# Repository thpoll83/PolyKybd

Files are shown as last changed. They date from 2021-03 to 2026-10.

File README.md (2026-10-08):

# PolyKybd Split72

Official hardware repository of the PolyKybd Split72 keyboard. If you are looking for the kit, jump immediately to https://www.crowdsupply.com/polykybd/polykybd for registration.

The instructions here are still in a very early stage. There is also a build video available: https://www.youtube.com/watch?v=K5RpbYzx7gw

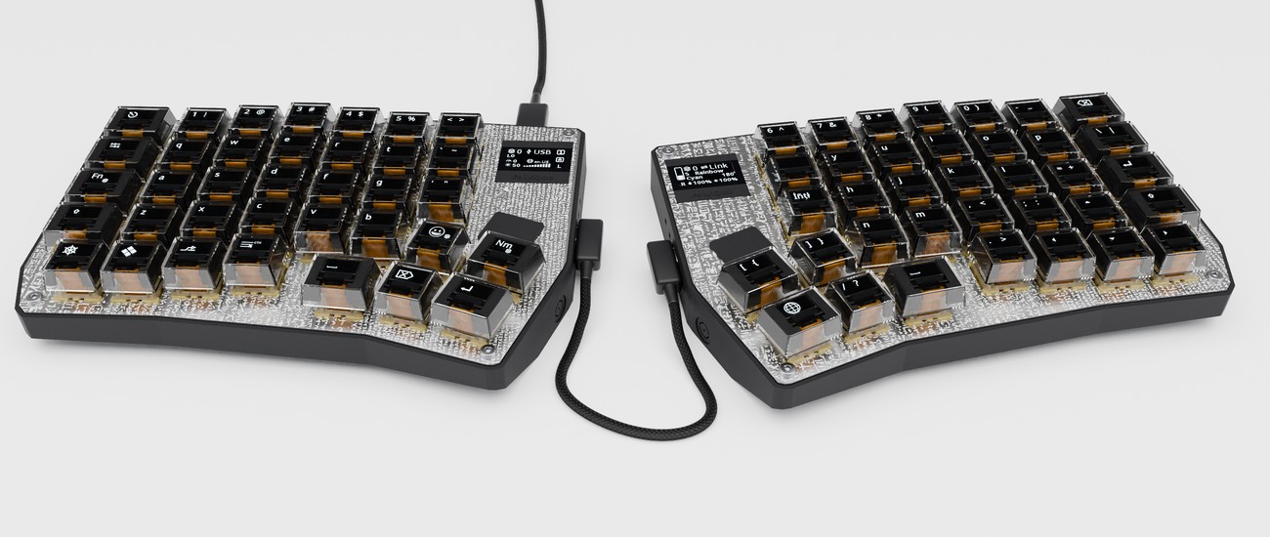
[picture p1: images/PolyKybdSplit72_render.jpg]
PolyKybd Split72, rendered from the KiCad models


You can find the matching QMK firmware here: [https://github.com/thpoll83/qmk_firmware/tree/PolyKybd](https://github.com/thpoll83/qmk_firmware/tree/PolyKybd)

## Cloning this repository

This repo is big — around 800 MB of history. Most of that is the board files themselves: the
decorative silkscreen artwork is stored as vector polygons, which makes a single `.kicad_pcb`
around 50 MB, and there are several design generations in the history.

If you just want the current files, use a partial clone. Git then downloads file contents only
when you actually touch them, so a fresh checkout takes seconds instead of many minutes:

```
git clone --filter=blob:none https://github.com/thpoll83/PolyKybd.git
```

The full history is still there and everything works normally — `git log`, `git checkout`, opening
the boards in KiCad. Older revisions of large files are simply fetched on demand. If you want a
plain full clone instead, just leave the `--filter` off.

The PCB projects are the following (**KiCad 9** — the schematics were migrated to the version 9
file format, so KiCad 8 and earlier can no longer open them):

[poly_kybd/poly_kybd_split72_right.kicad_pro](poly_kybd/poly_kybd_split72_right.kicad_pro)
[poly_kybd/poly_kybd_split72_left.kicad_pro](poly_kybd/poly_kybd_split72_left.kicad_pro)

(please just use the projects linked above and ignore any older/backup projects in the folder)

Here are the corresponding schematics for reference (left and right):

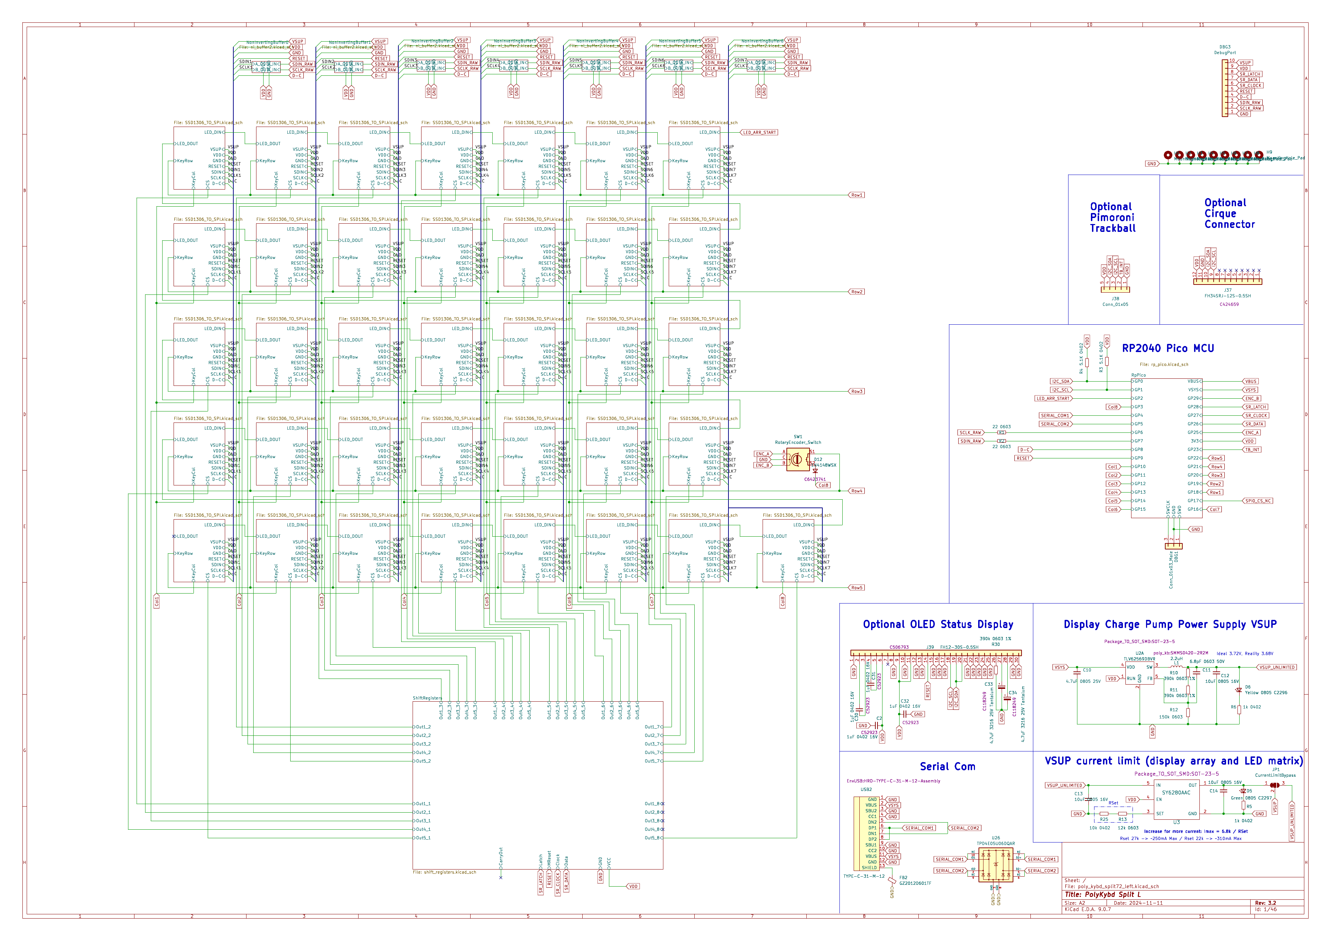
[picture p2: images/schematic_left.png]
Left schematic

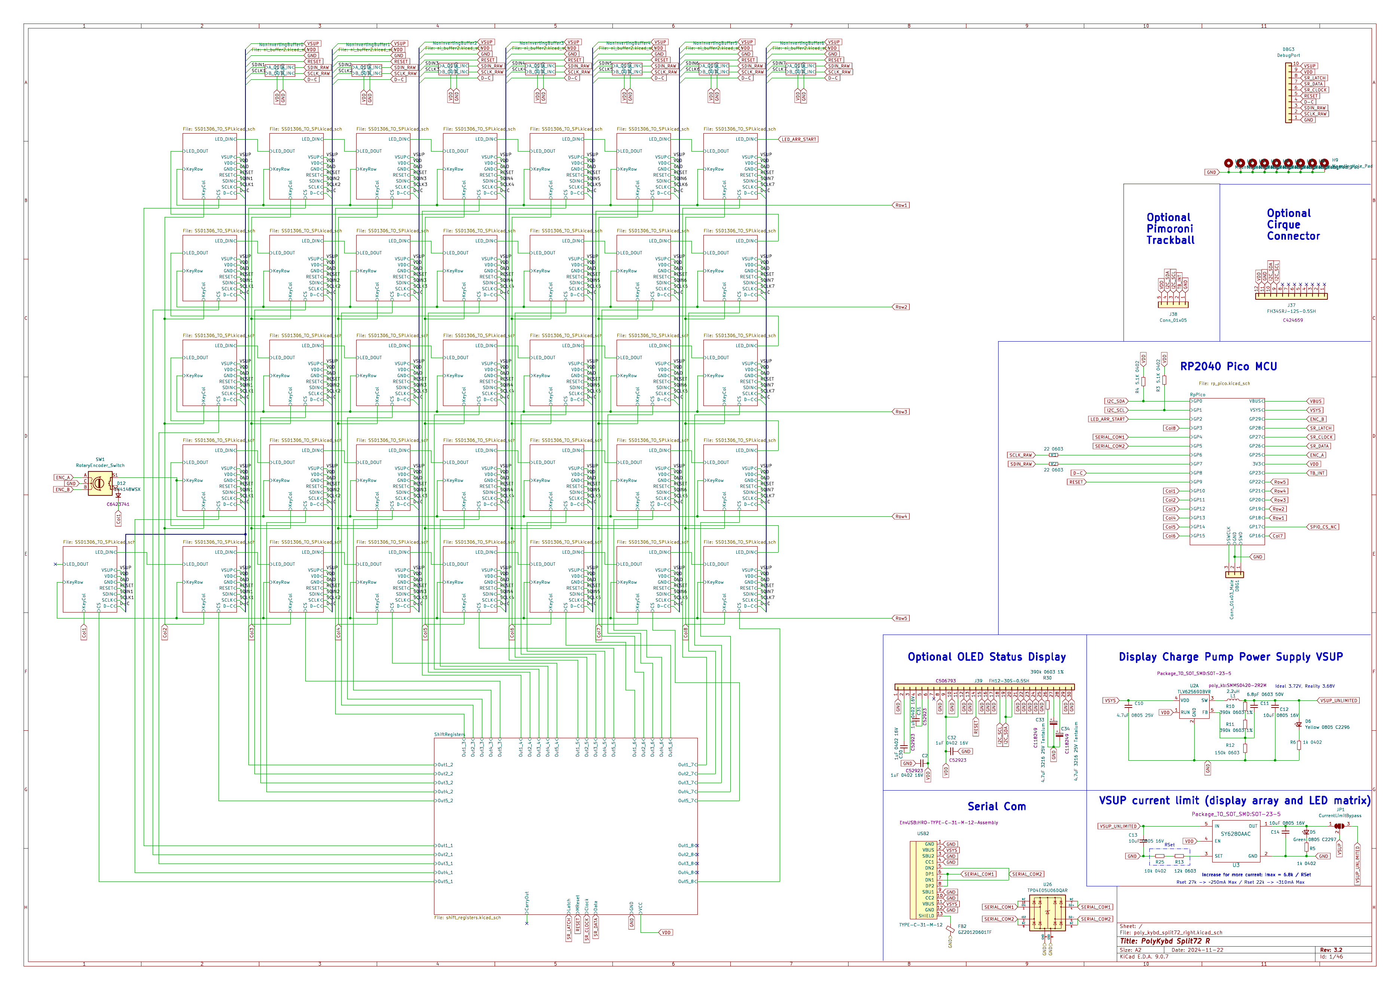
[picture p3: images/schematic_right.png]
Right schematic


You can inspect all individual schematic sheets (with descriptions) here: [Schematic sheets](schematics.md).

The keyboard plates are also KiCad projects, still in an older file format but they open fine in
KiCad 9 (I used 1.2mm aluminum PCBs):

[poly_kybd/poly_kybd_split72_plate_right.kicad_pro](poly_kybd/poly_kybd_split72_plate_right.kicad_pro)
[poly_kybd/poly_kybd_split72_plate_left.kicad_pro](poly_kybd/poly_kybd_split72_plate_left.kicad_pro)

## How to Build

I recommend waiting for the kit that contains all parts and the assembled PCBs. Here a little preview, how that looks like:
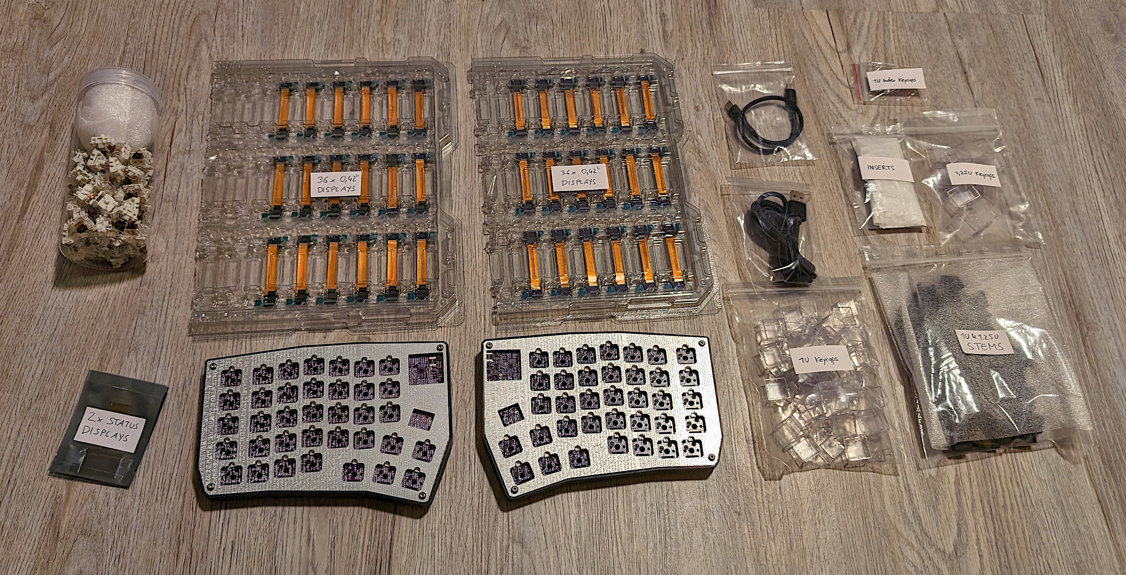
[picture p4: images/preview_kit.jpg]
Kit Preview

The kits are not yet ready, but you can sign up here and get notified as soon as these are available: [https://www.crowdsupply.com/polykybd/polykybd](https://www.crowdsupply.com/polykybd/polykybd)

At the moment, please consider these instructions as experimental. If you want to go ahead with the full experience and build everything from scratch right now: Give it a try and let me know how it worked out!

Independent of your choice, here are the parts you need before putting everything together:

### Prepare Required Parts

* Case (left/right) - You can either 3D print or get them CNCed (but then you should add some threads to the screw holes):
  [parts/export/case/case_polykybd_split72_left_r7.stl](parts/export/case/case_polykybd_split72_left_r7.stl)
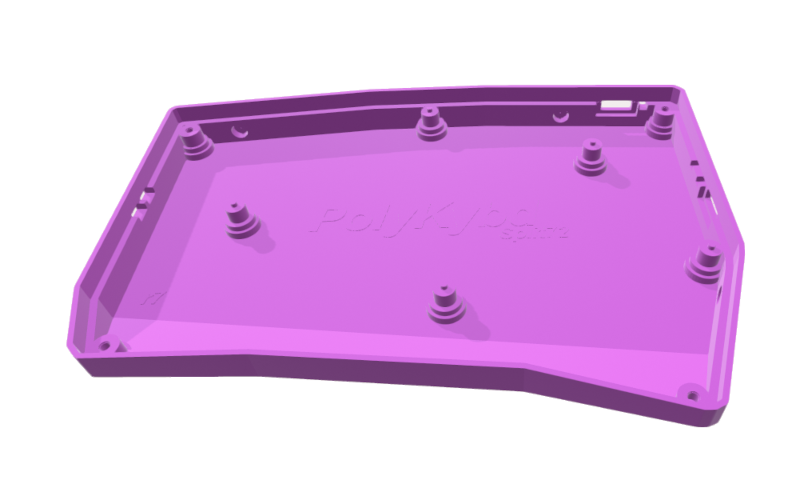
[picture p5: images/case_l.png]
Case
  
  [parts/export/case/case_polykybd_split72_right_r7.stl](parts/export/case/case_polykybd_split72_right_r7.stl)
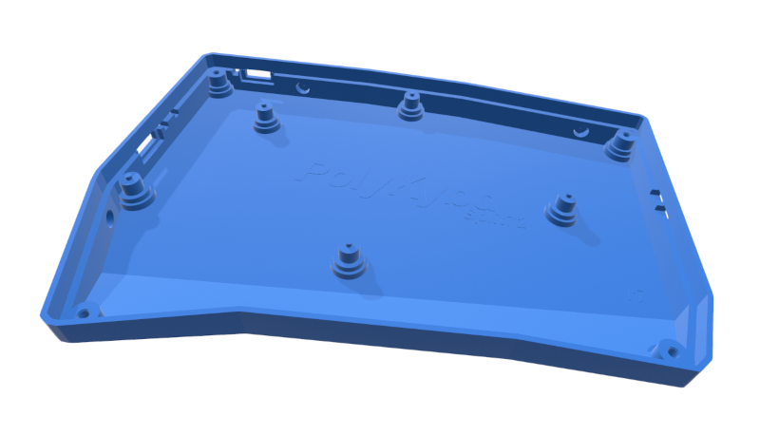
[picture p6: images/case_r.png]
Case
  
  In case the resin print has some deformations, it is best to use a hairdryer to slightly heat the case up and then put something heavy on the bottom to make it flat - it really works.
* Spacer to keep the right distance between plate and PCB (again, can be 3D printed):
  [parts/export/case/spacer.stl
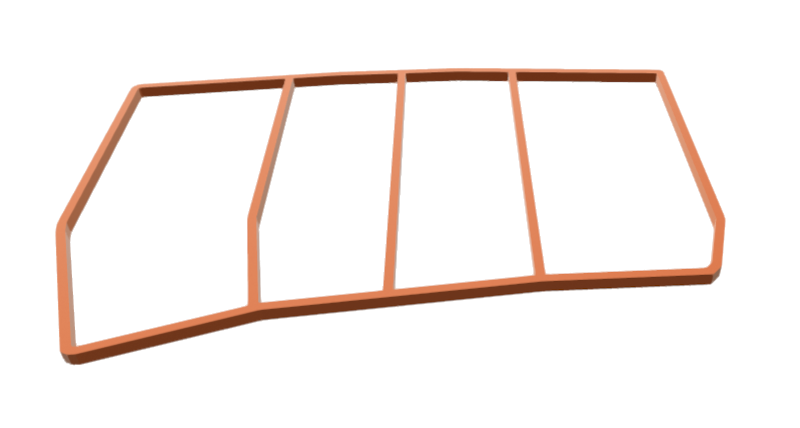
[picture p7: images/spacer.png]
Spacer
  
  ](parts/export/case/spacer.stl)
* Assembled 4 layers PCB 1.6mm (left/right)
  The latest gerber files with BOM and pick/place file can be found in [poly_kybd/Gerber](poly_kybd/Gerber) I made some final adjusts on the latest version, which I did not yet order (I will let you know as soon as I did).
  [poly_kybd/Gerber/PCB/left-side-v3.2/PolyKybd_Split72_L_3.2.zip](poly_kybd/Gerber/PCB/left-side-v3.2/PolyKybd_Split72_L_3.2.zip)
  [poly_kybd/Gerber/PCB/right-side-v3.2/PolyKybd_Split72_R_3.2.zip](poly_kybd/Gerber/PCB/right-side-v3.2/PolyKybd_Split72_R_3.2.zip)

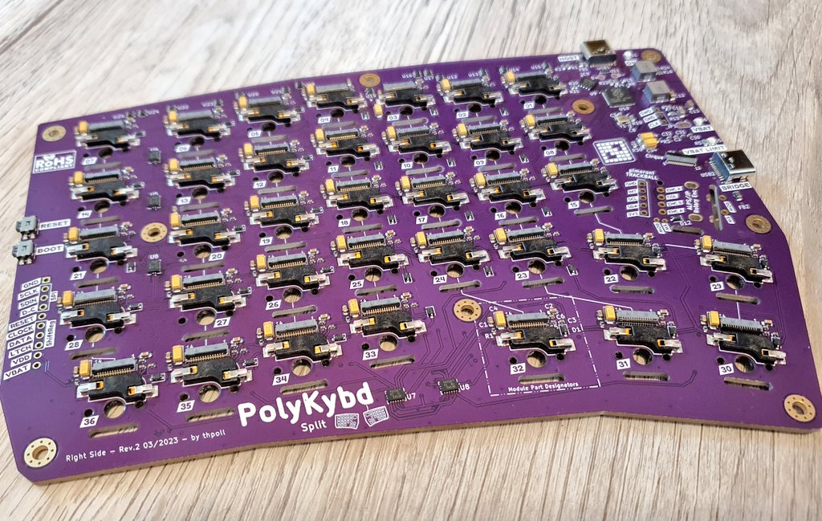
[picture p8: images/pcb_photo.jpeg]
PCB
  

  My recommendation is to let assemble the PCBs as there are a lot of parts with tiny footprints like the RP2040, the 72 FPC sockets and some more...
  If your PCB fab has an option to verify the parts orientation, please make use of it. I did that as well and never bothered correcting them (since the 'upright' orientation of the part from KiCad and your PCB fab might differ).

  ###### Note:

  In case you make modifications to the PCB in KiCad and export everything you might need to change the hot swap sockets side to the back. The hot swap socket in KiCad is part of the key switch and for some reason I couldn't yet convince KiCad that the manufacturing side is the back...
* Aluminum plates (left/right =) - Can be ordered from PCB manufactures as a 1.2mm aluminum PCB
  [poly_kybd/Gerber/Plate/gerber-left-side-v3-17.11.2023.zip](poly_kybd/Gerber/Plate/gerber-left-side-v3-17.11.2023.zip)
  [poly_kybd/Gerber/Plate/gerber-right-side-v3-17.11.2023.zip](poly_kybd/Gerber/Plate/gerber-right-side-v3-17.11.2023.zip)
* Displays
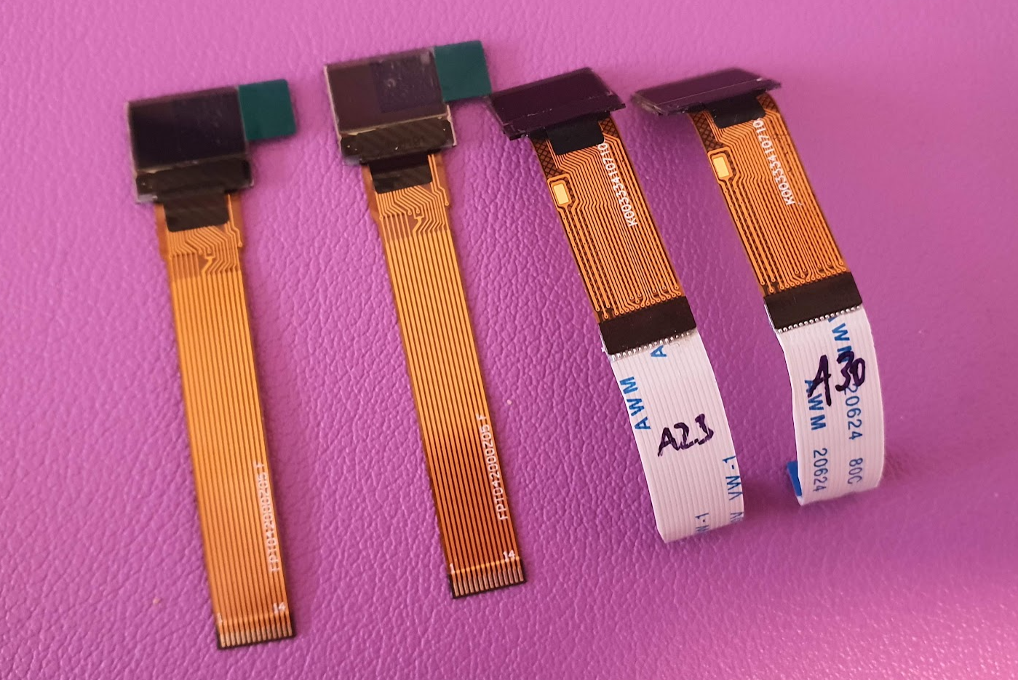
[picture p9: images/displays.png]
Displays
  

  - 72 pieces 0.42 inch displays

    - Either you take the 0.42 inch displays from the kit which has the matching length and pin number (maybe I can make them available as single parts as well - see picture above, on the left).
    - Or make them yourself the manual way, by extending a compatible 0.42 inch OLED with a short FPC cable and soldering the two together. See [Making the displays manually](making_the_displays_manually.md) for suppliers and the full soldering instructions.
  - (Optional) 2 pieces 0.96 inch status displays (FPW096W001Z0) or pin compatible (see below), the flex cable length should be about 40mm or you extend it on your own. You can contact this supplier: [FET](https://fetoled.en.alibaba.com/search/product), they have these displays even they are not listed in their online catalogue.

    | PIN   | SIGNAL    | PIN   | SIGNAL |
    | ----- | --------- | ----- | ------ |
    | 1,30  | N/C (GND) | 14    | RES#   |
    | 2,3   | C2P,C2N   | 15    | D/C#   |
    | 4,5   | C1P,C1N   | 16    | R/W#   |
    | 6     | VDDB/VBAT | 17    | E/RD#  |
    | 7     | N/C       | 18~25 | D0~D7  |
    | 8     | VSS       | 26    | IREF   |
    | 9     | VDD       | 27    | VCOMH  |
    | 10~12 | BS0~BS2   | 28    | VCC    |
    | 13    | CS#       | 29    | VLSS   |

    If you don't need the status displays, you can close the display cut-out with the dummy holder: [Dummy Display Holder](parts/export/display_holder/display_holder_dummy_r1.stl)

* MX Compatible key switches (3 or 5 pins) - 72 pieces. From my blog post ( [https://ko-fi.com/post/More-Key-Switch-Testing-While-Waiting-For-The-Asse-B0B8HX1HW](https://ko-fi.com/post/More-Key-Switch-Testing-While-Waiting-For-The-Asse-B0B8HX1HW) ), you can find out, that there are 2 categories of compatible key switches. The ones that work out of the box and the ones that need a little modification. Basically all switches that have an LED slit that is at least 7.5mm wide work. I tested quite some switches and here is the list of tested switches that will work for sure without modification:

  | SWITCH                            | TYPE            | MISC  |
  | --------------------------------- | --------------- | ----- |
  | Aflion Tropical Waters            | Linear          | 68g   |
  | Ashkeebs Alexandrite              | Linear          | 58g   |
  | Blue Dusk Panda                   | Linear          | 62g   |
  | CK x Haimu Pastel Lemon           | Linear          | 63.5g |
  | Ck x Haimu Pastel Thistle         | Tactile         | 63.5g |
  | Gateron KS-9 (Pro) Blue           | Clicky          | 60g   |
  | Gateron KS-9 (Pro) Brown          | Tactile         | 55g   |
  | Gateron KS-9 (Pro) Green          | Clicky          | 80g   |
  | Gateron KS-9 (Pro) Red            | Linear          | 45g   |
  | Gateron KS-9 (Pro) Yellow         | Linear          | 50g   |
  | Geon Black                        | Tactile         | 60g   |
  | Geon Clear                        | Linear          | 60g   |
  | Geon Yellow                       | Linear          | 63.5g |
  | Glorious Panda                    | Tactile         | 67g   |
  | GOJU Works x Tecsee Safety Switch | Linear          | 65g   |
  | Kailh Novel Keys Cream Switch     | Linear          | 55g   |
  | Kailh Purple Potato               | Tactile         | 63.5g |
  | Kailh x Domikey Knight Saber      | Tactile         | 42g   |
  | LCET Grace                        | Linear          | 50g   |
  | LCET Joker                        | Tactile         | 58g   |
  | LCET Pink Queen                   | Tactile         | 58g   |
  | LCET Sprout                       | Linear          | 50g   |
  | Outemu (Dustproof) Black          | Linear          | 65g   |
  | Outemu (Dustproof) Blue           | Clicky          | 65g   |
  | Outemu (Dustproof) Brown          | Tactile         | 50g   |
  | Outemu (Dustproof) Red            | Linear          | 46g   |
  | Outemu Crystal Clear              | Linear          | 45g   |
  | Outemu Dust-proof Silver          | Linear          | 45g   |
  | Outemu Lemon                      | Silent Tactile  | 35g   |
  | Outemu Panda                      | Tactile         | 50g   |
  | Outemu Peach                      | Linear          | 40g   |
  | Outemu Purple                     | Tactile         | 45g   |
  | Outemu Ocean                      | Linear          | 35g   |
  | Outemu Teal                       | Clicky          | 70g   |
  | Owlab Neon                        | Linear          | 62g   |
  | Tecsee Medium (low profile)       | Linear & Tactile| 50g   |

  Be aware that there are different batches of Gateron KS-9 (with and without 'Pro') switches. Despite the exact same name, they might need the following surgery (better ask before buy).
  So, some switches have an LED slit, but with a little plastic bar in the middle:

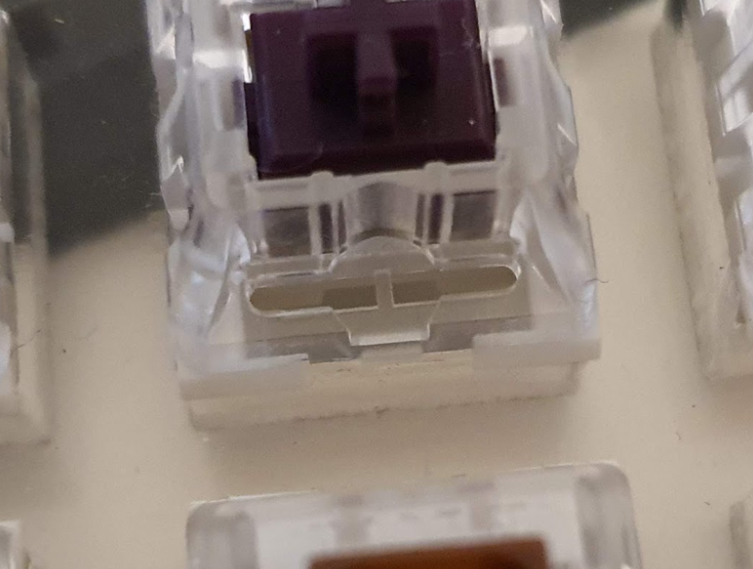
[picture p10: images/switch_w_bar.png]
Switch with plastic bar in LED slit
  

  You can simply cut it away with a knife:

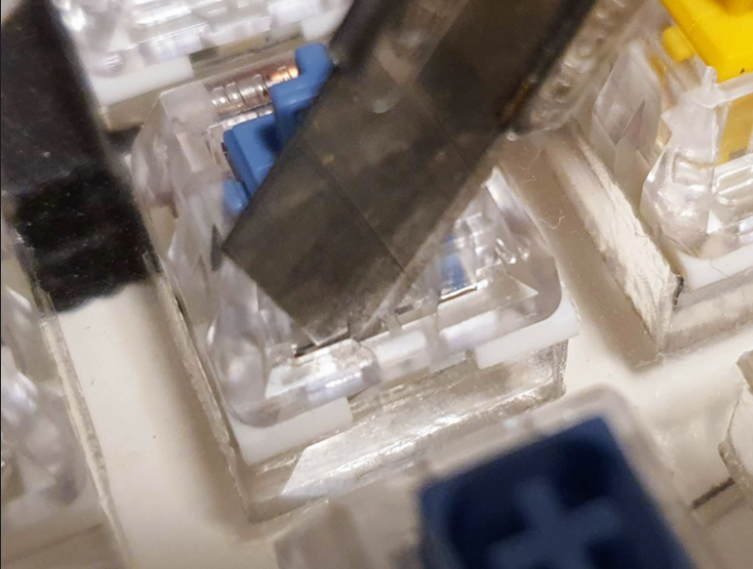
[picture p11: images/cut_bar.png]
Cut the bar away
  

  It is not a big deal, just consider it. Here is a list of switches that I successfully tested after this little modification:

  | SWITCH                           | TYPE           | MISC |
  | -------------------------------- | -------------- | ---- |
  | Gateron KS-9 (Pro 2.0) Red       | Linear         | 45g  |
  | Gateron KS-9 (Pro 2.0) White     | Linear         | 35g  |
  | Geon HG [Haimu x Geon] Black     | Linear         | 65g  |
  | Geon HG [Haimu x Geon] White     | Tactile        | 65g  |
  | Geon HG [Haimu x Geon] Red       | Silent Linear  | 65g  |
  | Geon HG [Haimu x Geon] Yellow    | Silent Tactile | 65g  |
  | Kailh BOX V2 Red Switch          | Linear         | 40g  |
  | Kailh Box Cream                  | Linear         | 45g  |
  | Kailh Pro Purple                 | Tactile        | 50g  |
  | Kailh Pro Burgundy               | Linear         | 50g  |
  | Kailh Pro Light Green            | Clicky         | 50g  |
  | Kailh Pro Plum                   | Tactile        | 70g  |
  | Kailh Speed Gold                 | Clicky         | 50g  |
  | Kailh Speed Silver               | Linear         | 50g  |
  | Kailh Speed Bronze               | Clicky         | 50g  |
  | Kailh Speed Copper               | Tactile        | 40g  |
  | Kailh Speed Burnt Orange         | Linear/Tactile | 70g  |
  | Kailh Speed Pro Heavy Army Green | Clicky         | 70g  |
  | Kailh Speed Pro Heavy Yellow     | Linear         | 70g  |
  | Kailh Black                      | Linear         | 60g  |
  | Kailh RGB Red                    | Linear         | 45g  |
  | Kailh RGB Black                  | Linear         | 60g  |
  | Kailh RGB Blue                   | Clicky         | 50g  |
  | Kailh RGB Brown                  | Tactile        | 50g  |

  There are many more switches that will work as long as they have a 7.5mm wide LED slit. Let me know in case you successfully tried another switch, then I can update the list.

* Key Stems - 72 pieces, can be 3D printed (I highly recommend using an SLA printer). There are 3 different profiles available here. You can also modify the source file an make your own profile. If you take the STLs, make sure to always grab the latest version.

  Every plate is in [parts/export/keycap_stem/](parts/export/keycap_stem), named
  `keycap_stem_revAlpha_<width>_<profile>_10p.stl` — where *width* is `1U` or
  **`1U25`** (not `1.25U`) and *profile* is one of `R1`–`R5`, `S1`, `S`, `S5`, e.g.
  `keycap_stem_revAlpha_1U25_R1_10p.stl`. Ten pieces per plate, so divide the
  counts below by ten (rounding up) to know how many of each to print.

  Every piece carries its **profile and revision engraved on the top face**
  (`R5 α`, `S1 α`, …), matching the profile token in the filename — so a printed
  stem can always be traced back to the plate that made it, and a mixed handful
  can be sorted back out.

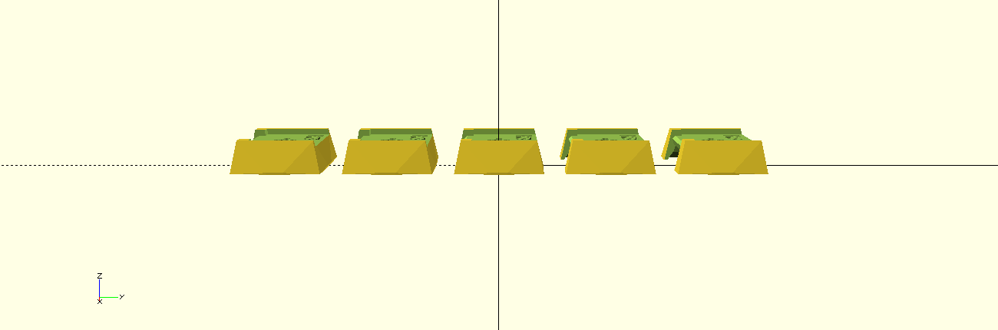
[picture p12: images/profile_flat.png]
Flat Profile
  - Flat 
    One stem for every row: the `R3` plates (14 pieces 1.25U and 58 pieces 1U).
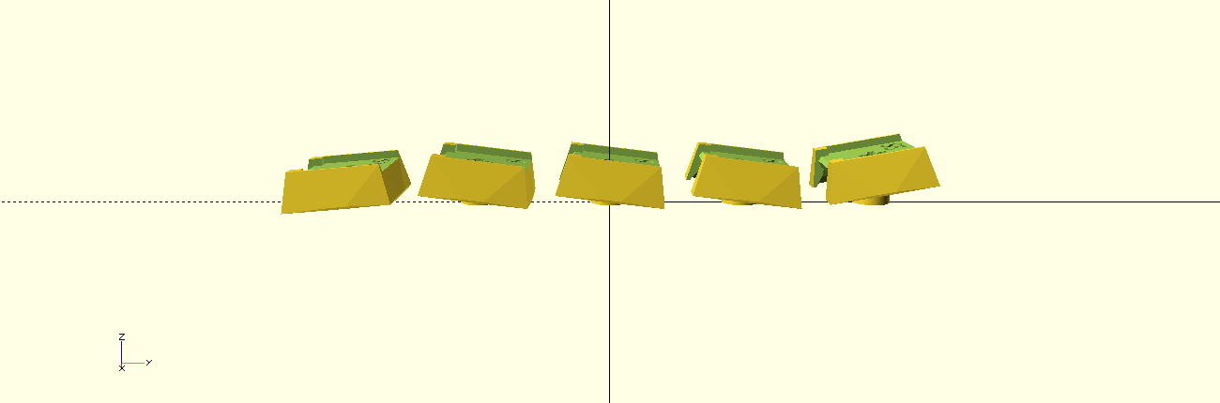
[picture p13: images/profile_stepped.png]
Stepped Profile
  - Stepped 
    Rows tilted rather than curved. This works best if the keyboard is inclined by 5 degrees or more, and comes in two variations:
    - *sculpted* (pictured) — `S1` on the front row, `S5` on the back row, `S` on the three rows between: 4x 1.25U S1, 10x 1U S1, 8x 1.25U S, 36x 1U S, 2x 1.25U S5, 12x 1U S5.
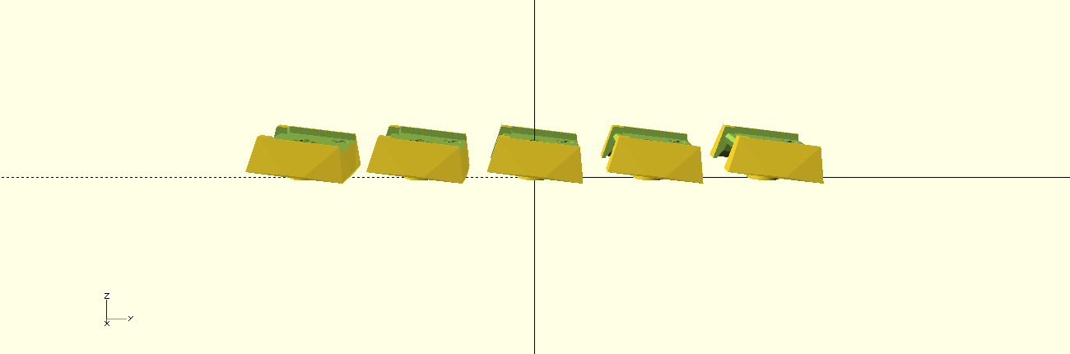
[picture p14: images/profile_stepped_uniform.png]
Uniform Stepped Profile
    - *uniform* 
      just the `S` plates everywhere (14 pieces 1.25U and 58 pieces 1U) — a flatter feel that is simpler to print, since it is a single plate design.
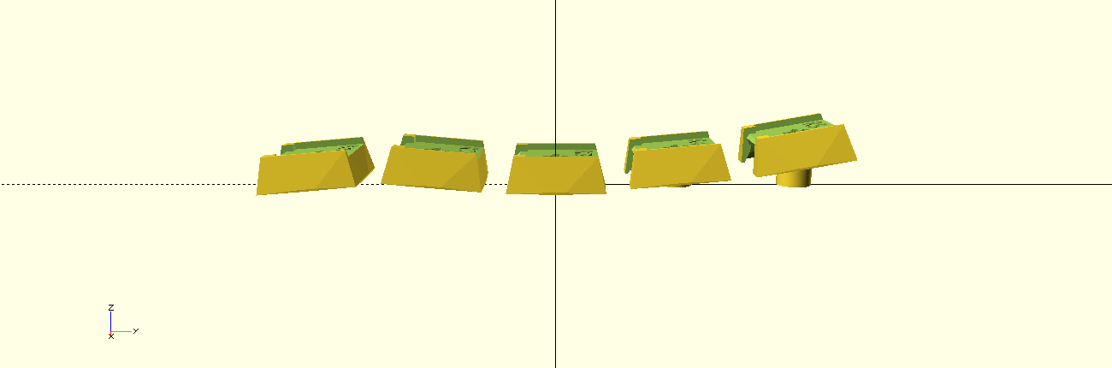
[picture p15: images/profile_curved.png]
Curved Profile
  - Curved 
    Here you will need `R1` to `R5`: 4x 1.25U R1, 10x 1U R1, 4x 1.25U R2, 12x 1U R2, 2x 1.25U R3, 12x 1U R3, 2x 1.25U R4, 12x 1U R4, 2x 1.25U R5, 12x 1U R5.

  To change a profile or add your own, edit the shared
  [parts/keycap_stem/keycap_stem.scad](parts/keycap_stem/keycap_stem.scad) or add a
  file to [parts/keycap_stem/variants/](parts/keycap_stem/variants), then run
  `parts/keycap_stem/build_stems.sh` — see [parts/README.md](parts/README.md).
* Status display holder (or cover/dummy in case no status display is used), can be 3D printed.
  [parts/export/display_holder/display_holder_r1.stl](parts/export/display_holder/display_holder_r1.stl) / [parts/export/display_holder/display_holder_dummy_r1.stl](parts/export/display_holder/display_holder_dummy_r1.stl)
* Transparent keycap covers - 72 pieces (from relegendable keycaps [like these](https://de.aliexpress.com/item/1005002996832179.html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)), 58x 1U and 14x 1.25U. Various sources sell them on Alibaba, AliExpress, Amazon & Co.
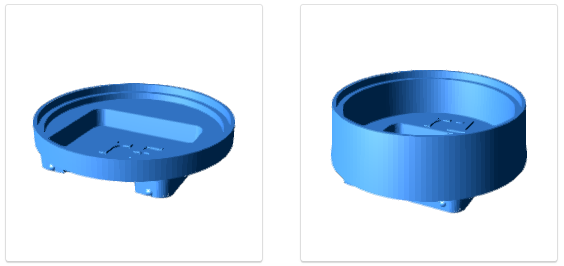
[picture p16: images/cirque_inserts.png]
Cirque Trackpad Inserts
* Optional rotary encoder ([EVQWGD001](https://de.aliexpress.com/i/32990950196.html?gatewayAdapt=gloMsite2deuPcglo2deu) or [Alps EC11 Encoder](https://www.mouser.at/c/electromechanical/encoders/?m=Alps%20Alpine&series=EC11)), [pimoroni trackball](https://mou.sr/3rmFiAO) or [23mm cirque trackpad](https://www.mouser.at/ProductDetail/Cirque/TM023023-2024-002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) (and a 12 pin FPC cable with pins on the same side, about 50mm to 70mm). For the trackpad you will need another 3D printed holder, either a high one or a low one: 
  [parts/export/cirque_insert/cirque23_slim_insert_r8.stl](parts/export/cirque_insert/cirque23_slim_insert_r8.stl)
  [parts/export/cirque_insert/cirque23_insert_high_r1.stl](parts/export/cirque_insert/cirque23_insert_high_r1.stl)
  If you are not happy with the existing STLs, you can also modify the source file [parts/cirque_insert/cirque23_insert.scad](parts/cirque_insert/cirque23_insert.scad) or [parts/cirque_insert/cirque23_slim_insert.scad](parts/cirque_insert/cirque23_slim_insert.scad). There is also an experimental version for the 35mm cirque track pad: [parts/cirque_insert/cirque35_insert.scad](parts/cirque_insert/cirque35_insert.scad).
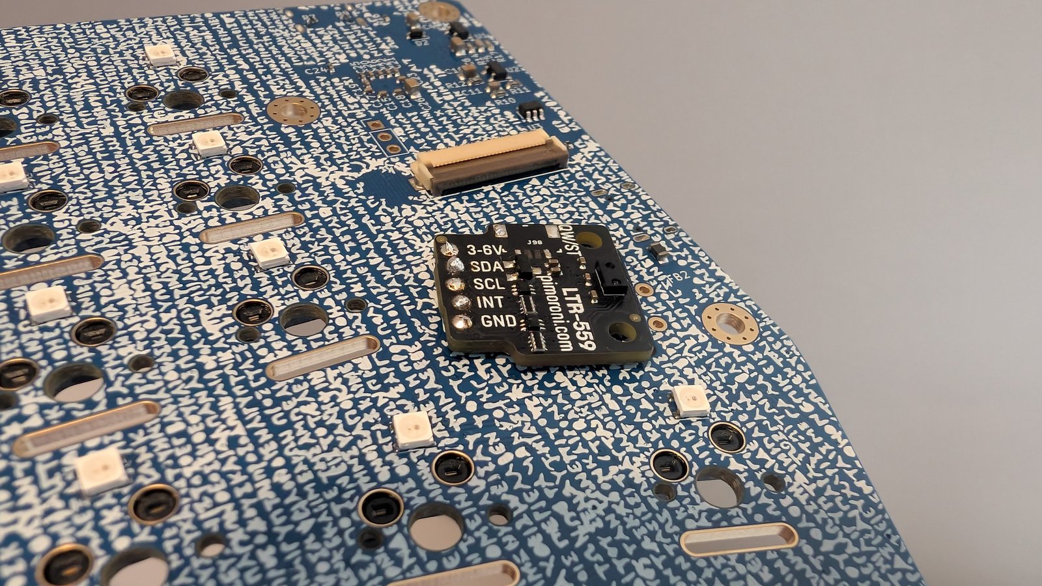
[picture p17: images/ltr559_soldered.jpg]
LTR-559 soldered to the PCB
* Optional ambient-light + proximity sensor (**highly recommended**) - a [Pimoroni LTR-559 Light & Proximity Sensor breakout](https://shop.pimoroni.com/products/ltr-559-light-proximity-sensor-breakout) plus a matching 5-pin 2.54mm pin header. The Split72 PCB has a dedicated header footprint for it (labelled `3-6V / SDA / SCL / INT / GND`), sharing the Cirque I2C bus - no extra wiring. With the sensor fitted, the firmware automatically drives keycap brightness from the measured light level and wakes the displays when your hand approaches. It is entirely optional (the firmware is a clean no-op when no sensor is present) and side-agnostic (works on whichever half you solder it to). **You must fit it as the very first assembly step** - see the note in [Put Everything Together](#put-everything-together) below, because it does *not* fit through the plate hole and cannot be added later without an almost complete disassembly. 
  ***Note:*** each half has a **single** expansion slot that takes exactly **one** of these optional add-ons - a rotary encoder, a pointing device (trackball/trackpad), *or* the light sensor. So on a given half the sensor is mutually exclusive with the encoder and the pointing device: fitting the sensor means that half has no encoder/trackpad. (You can still put the sensor on one half and a pointing device or encoder on the other.)
* Short USB-C to USB-C cable to connect the two sides (maybe around 50cm).
* USB-C to USB-A/USB-C to connect to your computer.
  ***Note:*** I had a USB-C to USB-A cable and was sitting in front of a laptop with only USB-C ports. Without a USB-C to USB-C cable at hand, I used an USB-A to USB-C adapter. It turned out this USB-C to USB-A cable + USB-A to USB-C adapter construction was only working then the adapter was connected to the laptop. - better use a USB-C to USB-C right away.
* 8 M3x10 hex screws with rounded heads and for the current case version (r4 and later, e.g. r7), you also need 8 M3 hex nuts.

### Put Everything Together

Here is my recommended order:

0. **(Optional but highly recommended) Solder the LTR-559 light + proximity sensor - do this FIRST!**
   ⚠️ The sensor board does **not** fit through the hole in the aluminum plate, so it has to be soldered on **before** the plate goes on. If you add it later you will have to almost completely disassemble the keyboard again. So if there is any chance you want it, fit it now - it is optional in firmware and costs you nothing if you later decide not to use it.
   ⚠️ Each half has a **single** expansion slot shared by the sensor, the rotary encoder and a pointing device (trackball/trackpad) - only **one** of the three fits per half. So fitting the sensor means no encoder or trackpad on that half (you can still fit one of those on the other half). Decide before you start soldering.

   The Split72 PCB has a labelled 5-pin footprint for the sensor (`3-6V / SDA / SCL / INT / GND`). Solder the sensor exactly like this:
   1. Solder the 5-pin header into the PCB footprint.
   2. The plastic spacer strip of the header now has to come off - it holds the sensor board too high to clear the plate. I simply pushed it all the way down/off the pins:
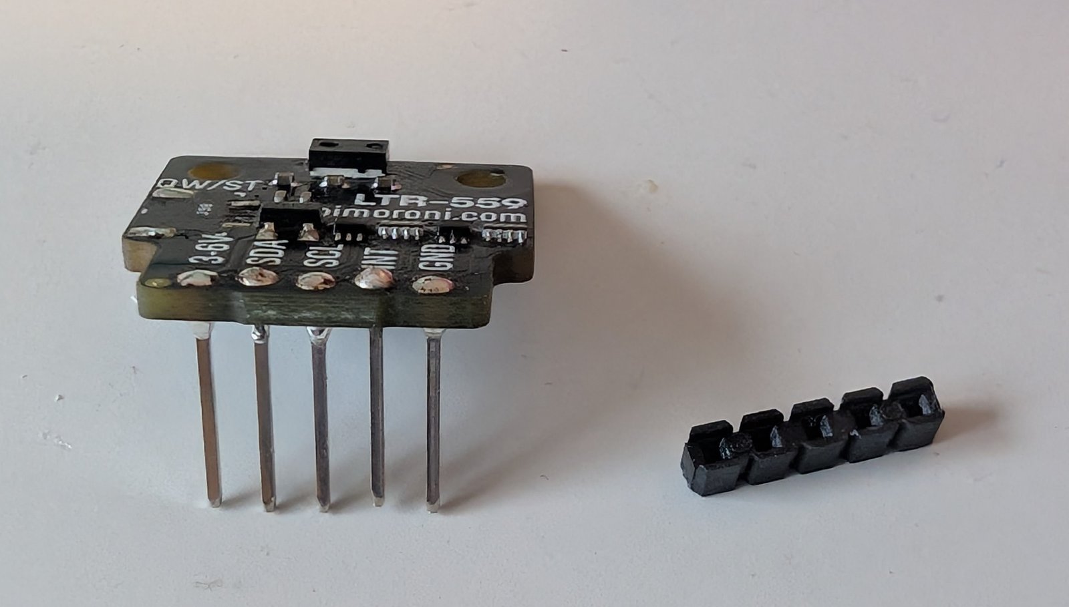
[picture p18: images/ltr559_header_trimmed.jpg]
Sensor with the header spacer removed
      
   3. It is still too thick, so instead of the plastic spacer use a piece of paper folded twice (roughly 1-2mm) as a temporary shim to set the sensor at a nice low height while you solder the board onto the header pins:
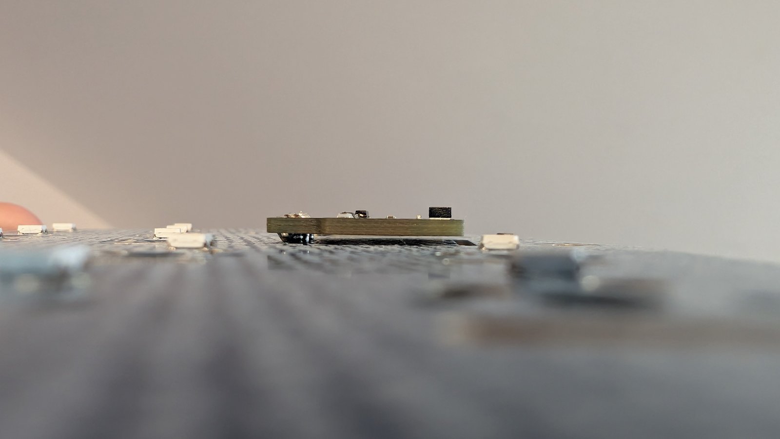
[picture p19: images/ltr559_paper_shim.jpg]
Folded paper used as a spacer
      
   4. After soldering, pull the paper back out. The sensor now sits low and flat, just above the PCB:
      Sensor soldered flush to the PCB
   5. To expose the sensor to ambient light, drill a **5mm hole** into the 3D-printed cap on the far right, vertically centered as shown:
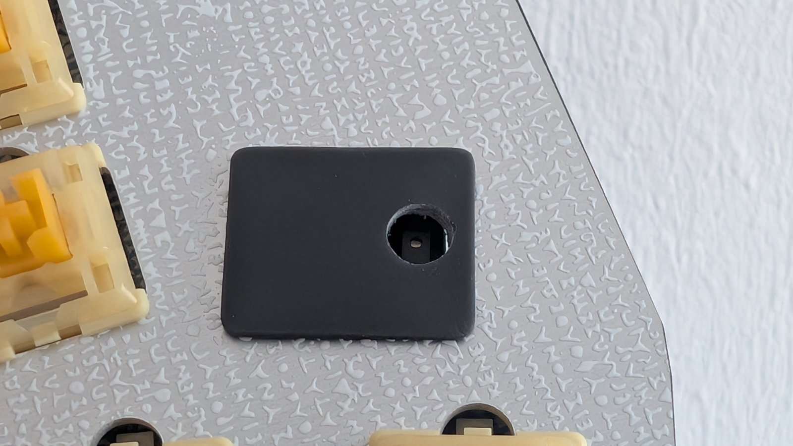
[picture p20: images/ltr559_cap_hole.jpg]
5mm hole drilled into the cap
      

   The sensor is auto-detected on whichever half you solder it to - no firmware option to enable. See the [firmware readme](https://github.com/thpoll83/qmk_firmware/blob/PolyKybd/keyboards/polykybd/readme.md) for how it drives auto-brightness and proximity wake.
1. In case you want to use an [Alps EC11 Encoder](https://www.mouser.at/c/electromechanical/encoders/?m=Alps%20Alpine&series=EC11) or some remaining stock of the not any more produced [EVQWGD001](https://de.aliexpress.com/i/32990950196.html?gatewayAdapt=gloMsite2deuPcglo2deu), put it on the PCB and also put the keyboard plate once on top to make sure your encoder fits! In case of the EVQWGD001, you have to remove the last pin, before soldering it to the PCB Juts clip it away. DO NOT solder it to the PCB, or otherwise it will not work:
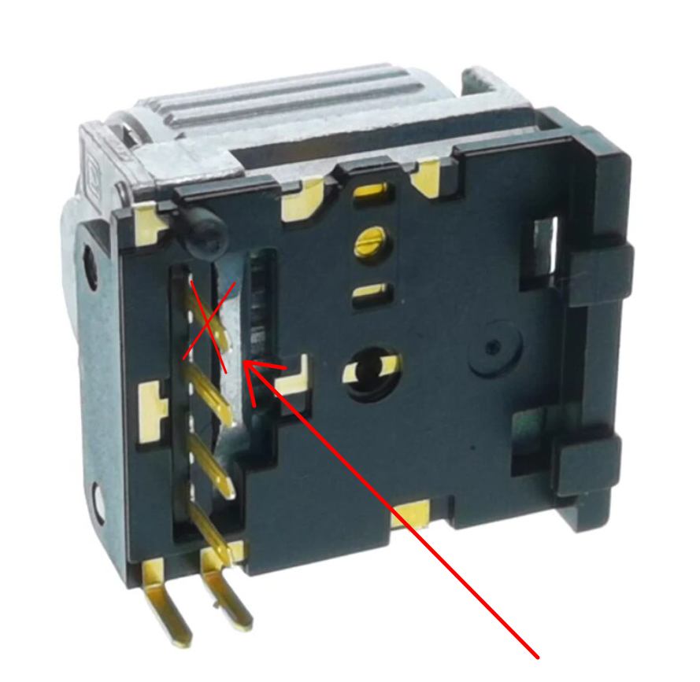
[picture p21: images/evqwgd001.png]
EVQWGD001

Depending on the type of EC11 encoder, you maybe want to put a piece of Kapton tape over the legs, in case they come close to the plate (it was not necessary for mine, but there are different kinds out there).
1. For the [pimoroni trackball](https://mou.sr/3rmFiAO), please solder on the header without the little plastic distance holder. There are various ways to do that: Either solder them on and push the plastic with some pliers off the pins (and clip away the pins on the front side of the trackball so that it is flush) or insert them from the front side, solder them on and then clip away the plastic parts. The pins are still long enough. Just go for something that works for you.
   Next, put some Kapton tape on the back side of the trackball and solder it to the keyboard PCB. Make sure it is even on the front side, there will be an average 1 to 2mm distance:
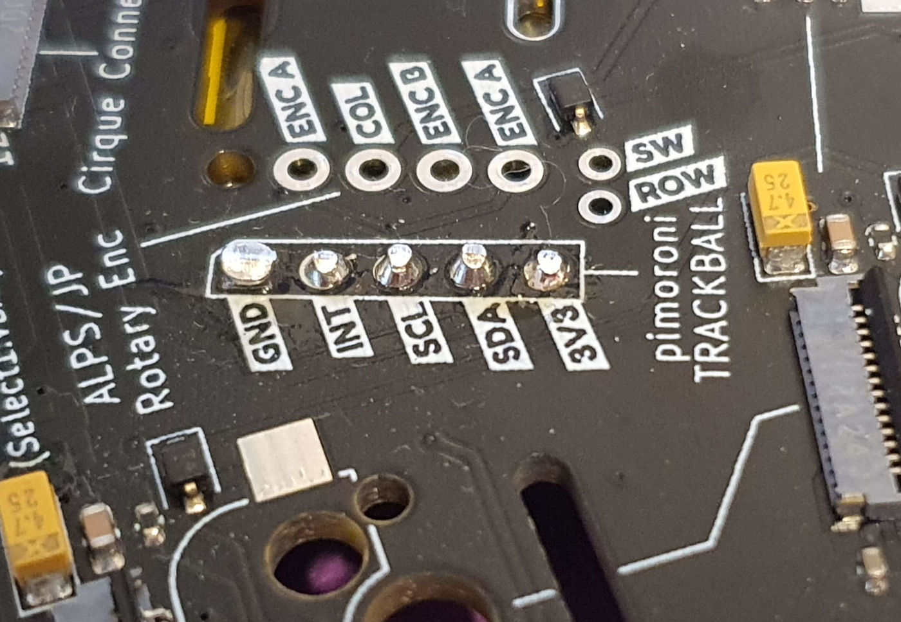
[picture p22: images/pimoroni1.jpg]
Pimoroni on the back side
   
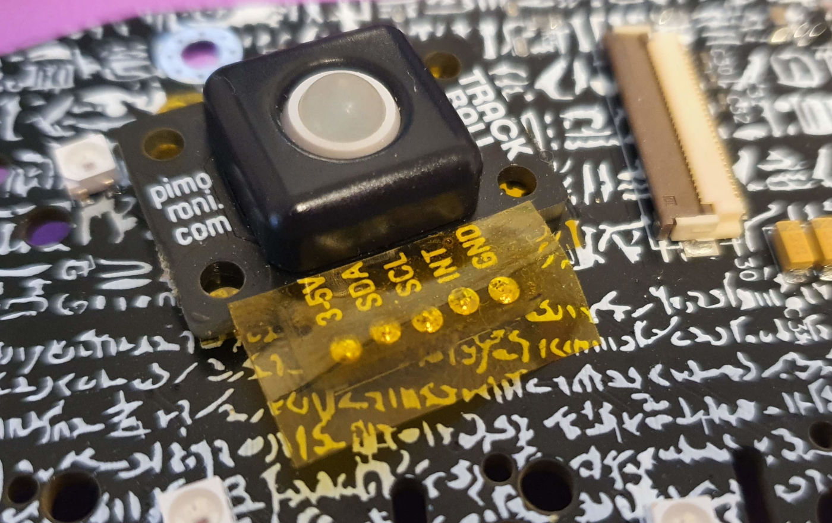
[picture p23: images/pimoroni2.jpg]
Pimoroni on the front side
   
   Finally also cover the trackballs front side with Kapton tape like in the picture above (or anything that pleases your eye and insulates) to avoid any shorts since the top plate is made out of Aluminum.
2. In case you use the [23mm cirque trackpad](https://www.mouser.at/ProductDetail/Cirque/TM023023-2024-002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), first remove R1 from the backside of the trackpad's PCB (with a solder iron or maybe a sharp knife) to activate I2C instead of SPI. Then connect the 12 pin FPC to the trackpad (and mind the pin 1 marking on the trackpad + I made my own marking on the FPC to make sure):
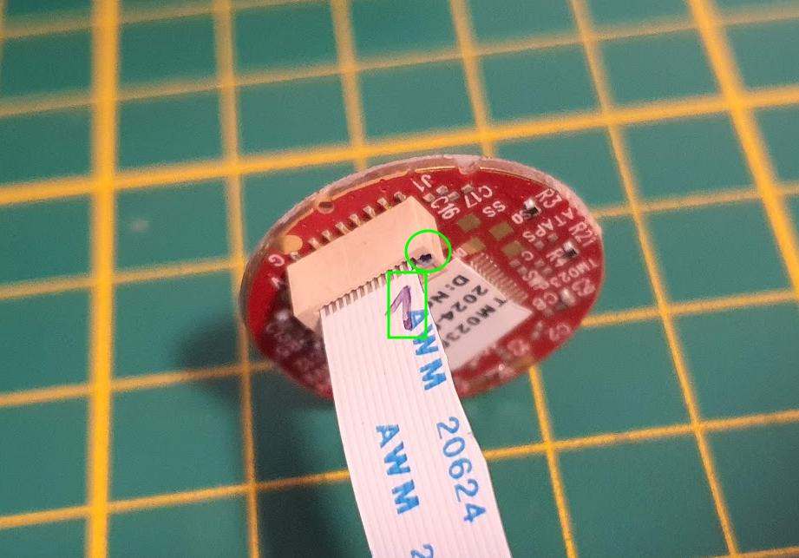
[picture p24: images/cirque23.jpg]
Cirque trackpad connected
   
   Then, put it into the 3D printed holder. You can fix the trackpad with some adhesive tape or a few drops of super glue into the holder. Wait with connecting it to the PCB:
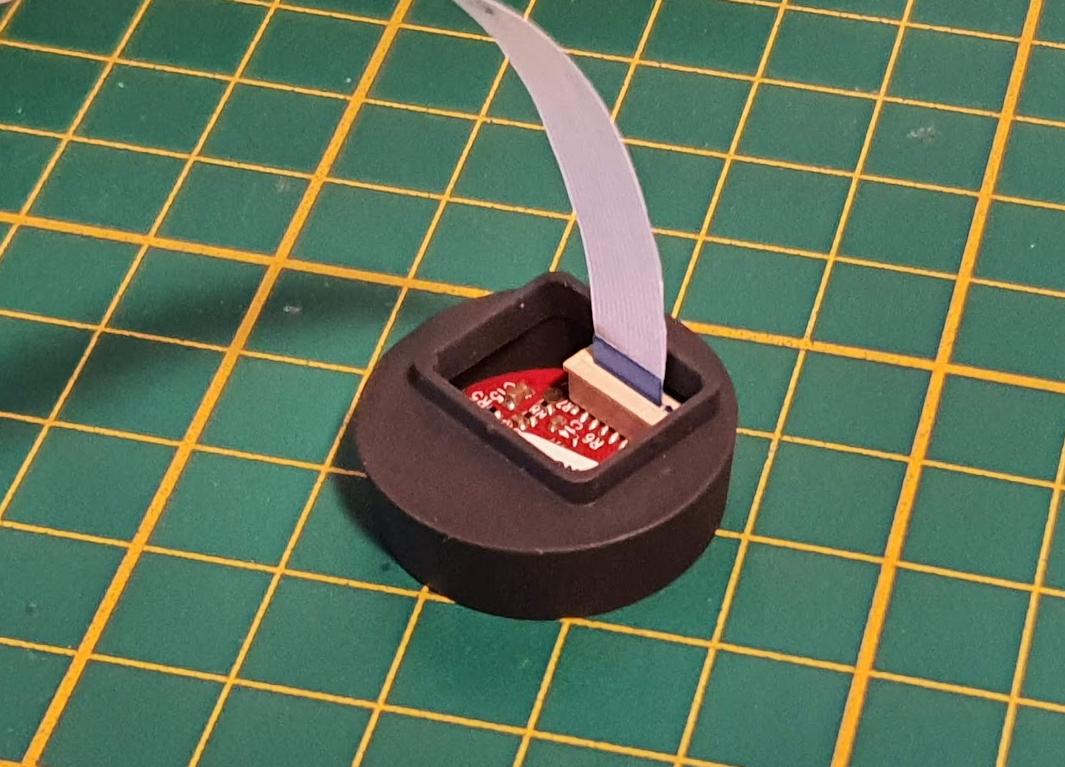
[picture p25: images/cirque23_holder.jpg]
Cirque trackpad with holder
   
There is also an experimental version for the 35mm trackpad, take a look at the parts folder.
3. Insert the 0.96 inch status display into the display holder (bend the holder back and let it snap back to bracket the display). Connect the FPC with the socket on the PCB and lock it by lowering the brown flap on the FPC side (if you don't have a status display just close the cut out with the blind lid):
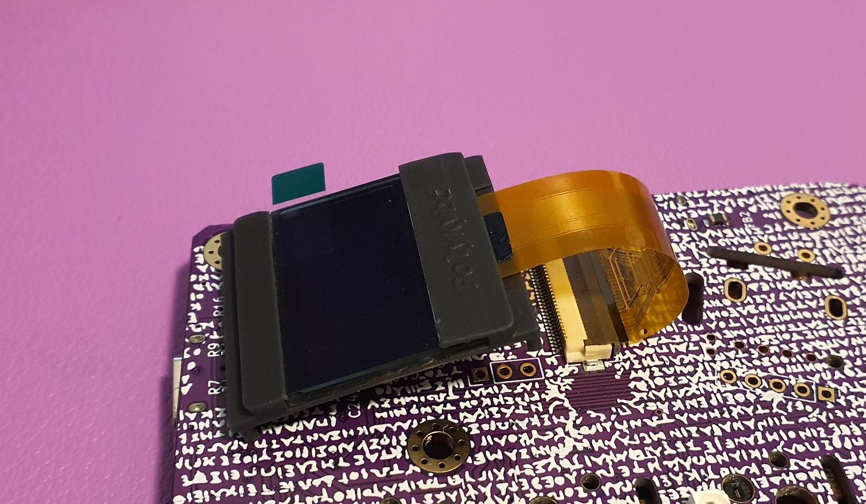
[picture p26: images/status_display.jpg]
Status Display
   
4. Put the spacer on top.
5. While putting the plate on top of the assembly, fit the status display holder (or blind) into the plate from the plates back side:
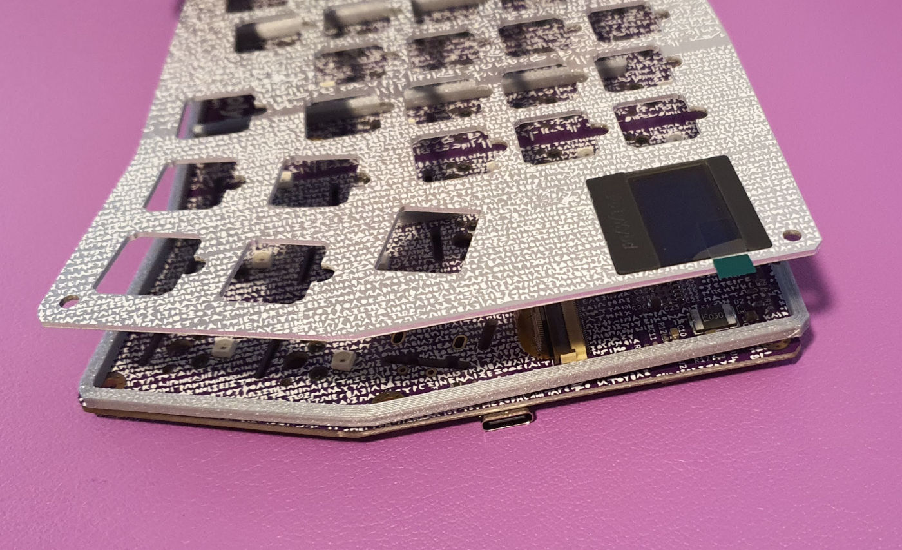
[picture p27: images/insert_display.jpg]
Insert Status Display
   
   Then, the plate rests on the spacer, which again rests on the PCB. I pushed in two screws temporarily to align plate and PCB:
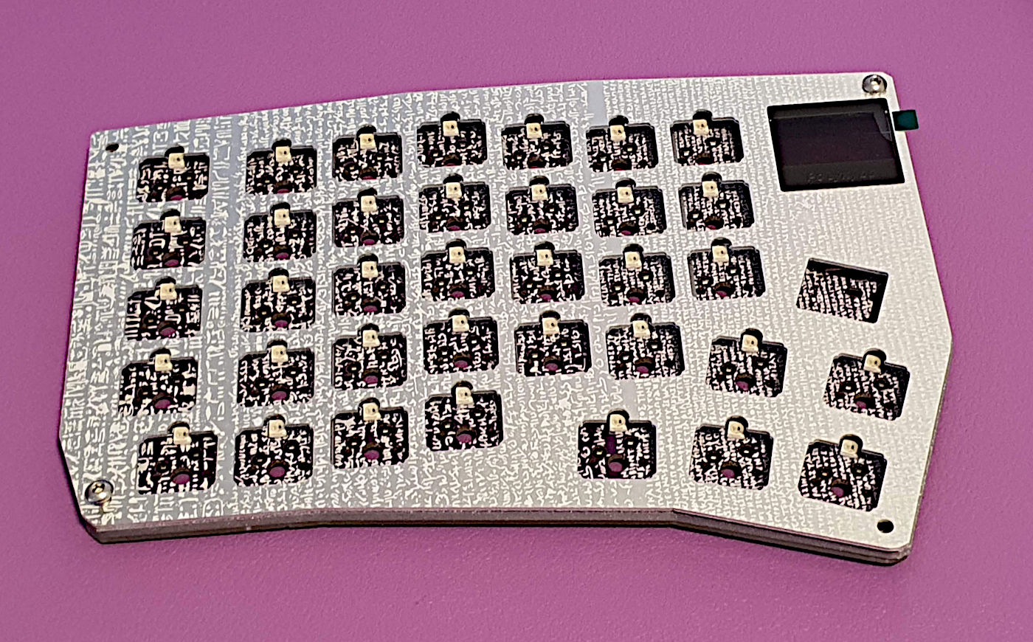
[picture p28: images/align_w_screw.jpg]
Align the assembly
   
6. Now would be the time to fit in the optional cirque trackpad. First get the FPC cable through the slot:
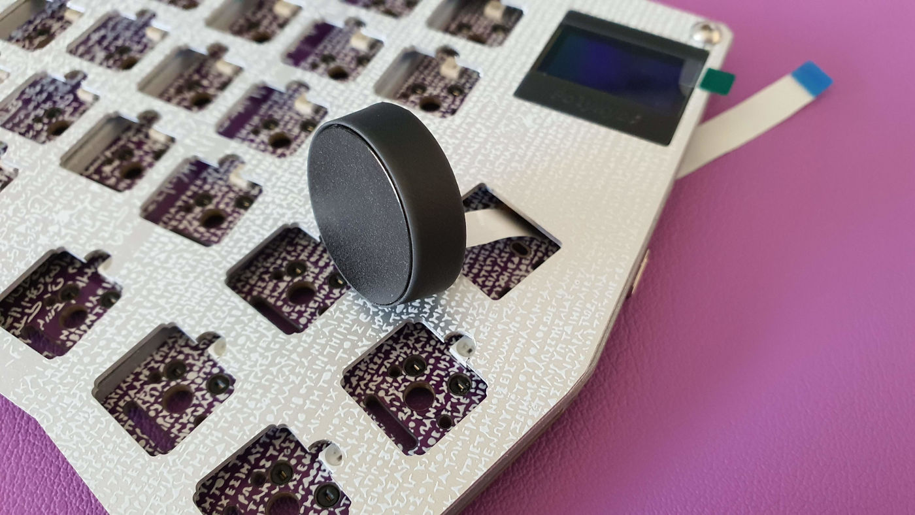
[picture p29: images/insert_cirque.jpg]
Insert trackpad
    Next, push in the trackpad holder. It is a press-fit, so no glue needed, just push:
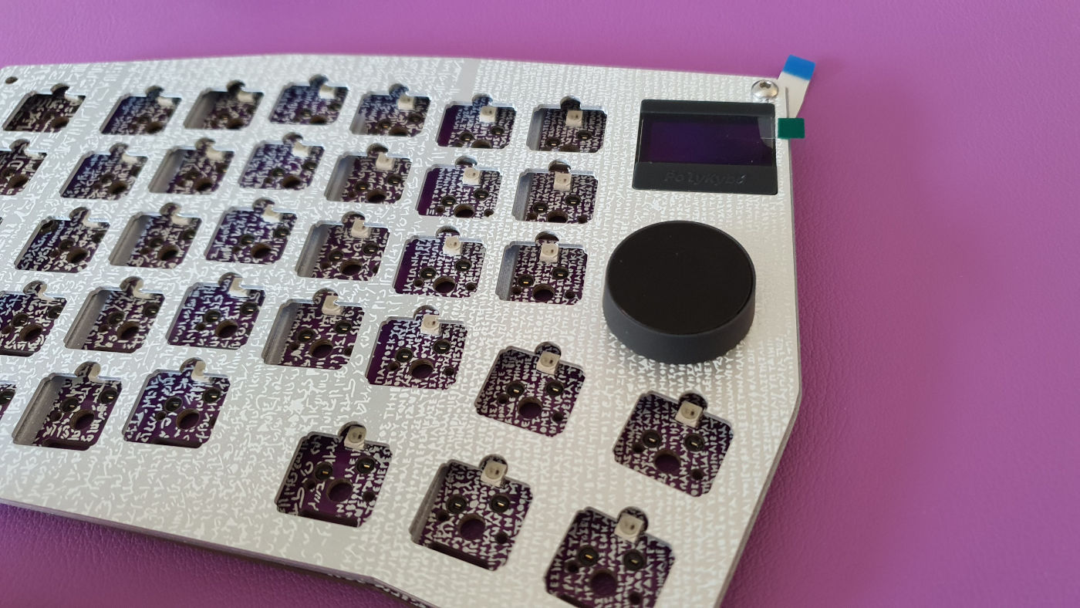
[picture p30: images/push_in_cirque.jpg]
Push in the trackpad
   
   Finally insert the FPC cable into the cirque socket and lock it by lowering the little flap on the back side of the socket (again make sure that pin 1 meets the side with the little 1 next to the socket):
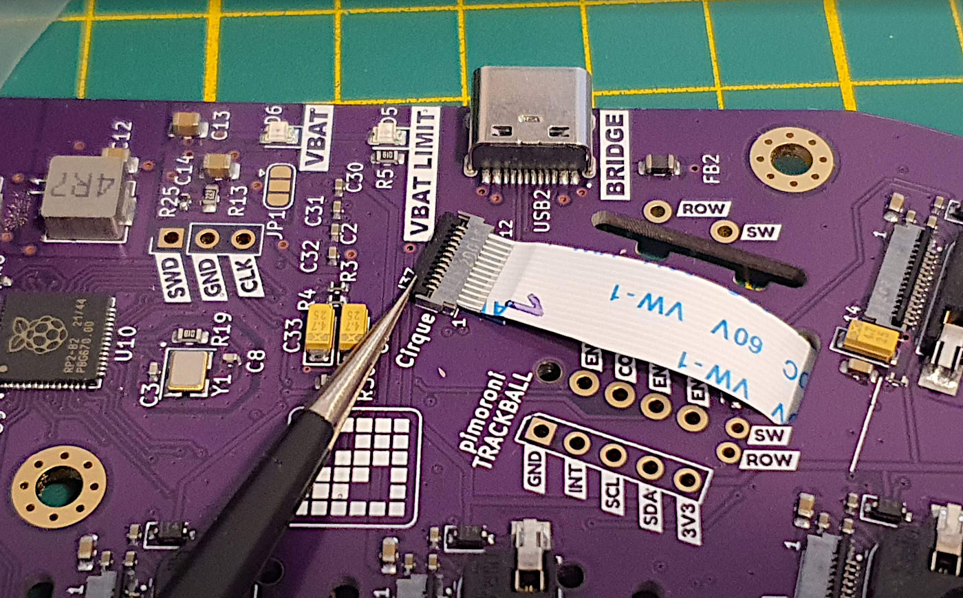
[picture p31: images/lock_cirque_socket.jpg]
   
   Depending on the keyboard side (left/right), the slot for the FPC to go through is located very close to the trackpad socket or a bit further away as on the picture.
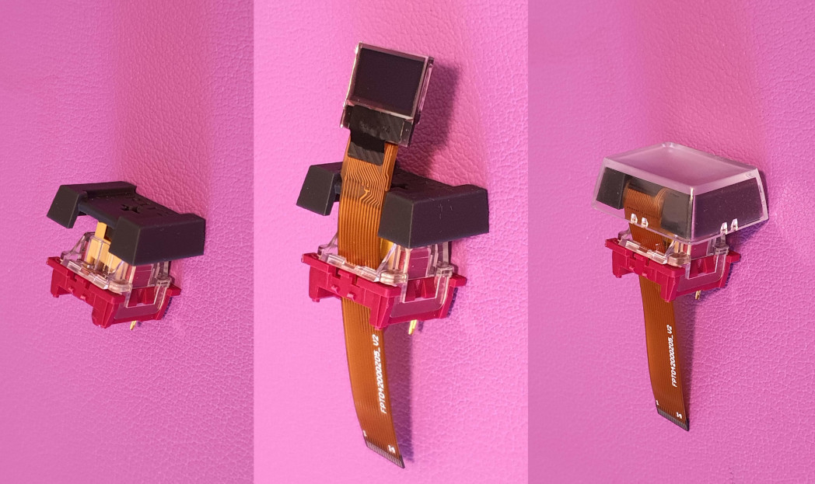
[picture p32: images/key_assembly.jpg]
Key assembly
7. Assemble all 72 keys: Put the stem on the key switch, put the flex cable through the LED slit of the key switch and and align the display. Finally put the clear keycap over it and make sure it sits flat on the stem. The display will slide into the stem when covering with the clear keycap. You don't need to pre-bend the flex cable. I rather recommend against bending it as you might damage it. The following images shows these 3 steps: 
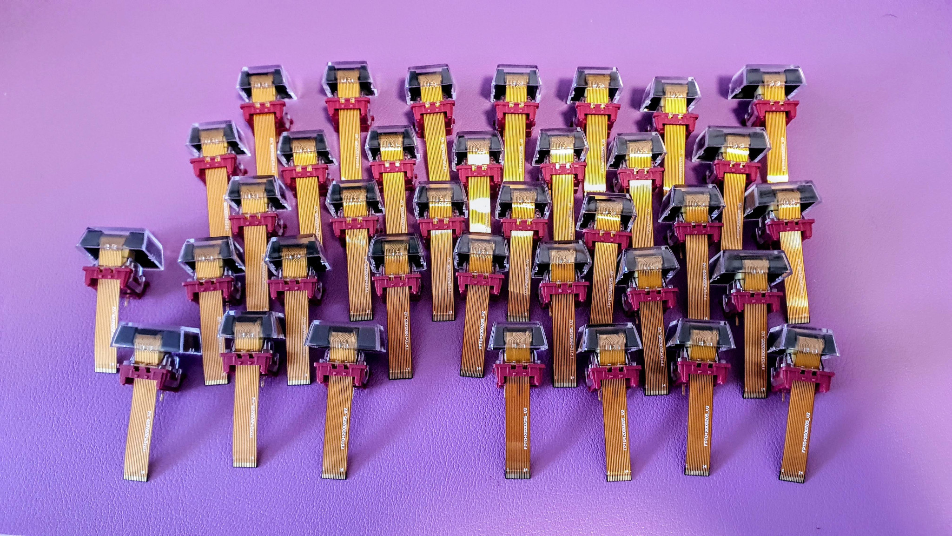
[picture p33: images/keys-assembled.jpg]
Keys assembled
   Now repeat this for every key-switch. A fully prepared keyboard side of switches might look like this: 
8. Push in one assembled key switch at each corner so that everything aligns properly.
To do that, first insert the flex cable into the PCB slot and push the key switch **STRAIGHT** into the hot swap socket.
**DO NOT** keep pushing if you feel resistance half way to the bottom, there is a danger that you detach the hot-swap from the PCB. In that case, get the switch out again, make sure the pins aren't bent and try again!
On the backside, you can check if both pins have been inserted properly:
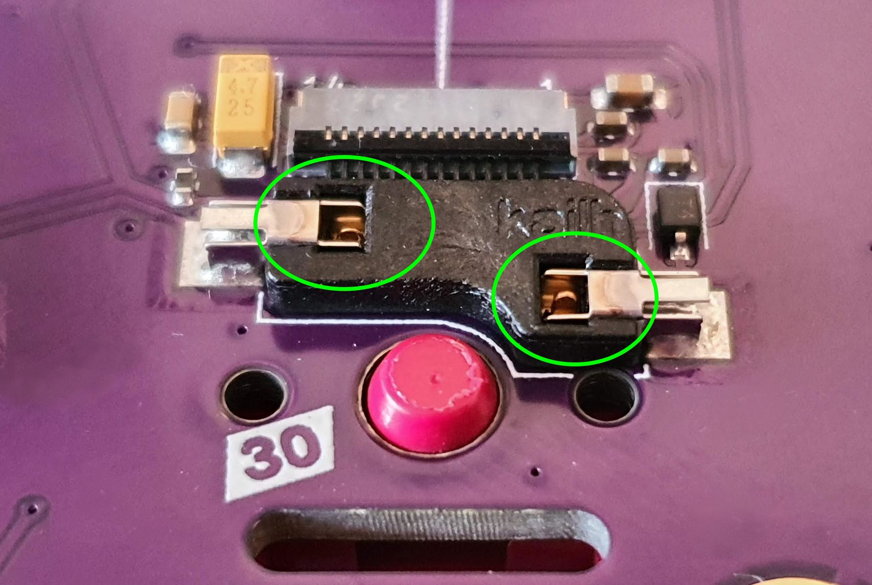
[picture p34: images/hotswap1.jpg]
Switch successfully inserted
   
   Here, only one pin is in the hot-swap socket. Pull the key switch out again, straighten the bent pin and reinsert carefully:
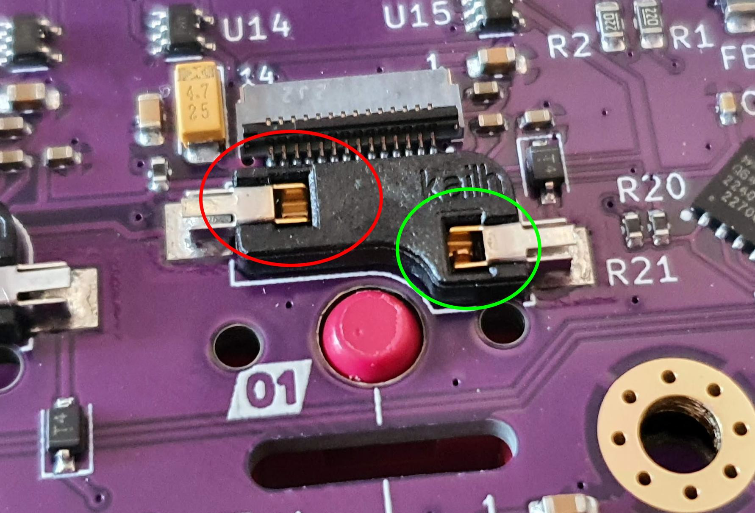
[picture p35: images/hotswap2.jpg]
Switch with only one pin
   
   This is how it looks like if there is no key switch inserted:
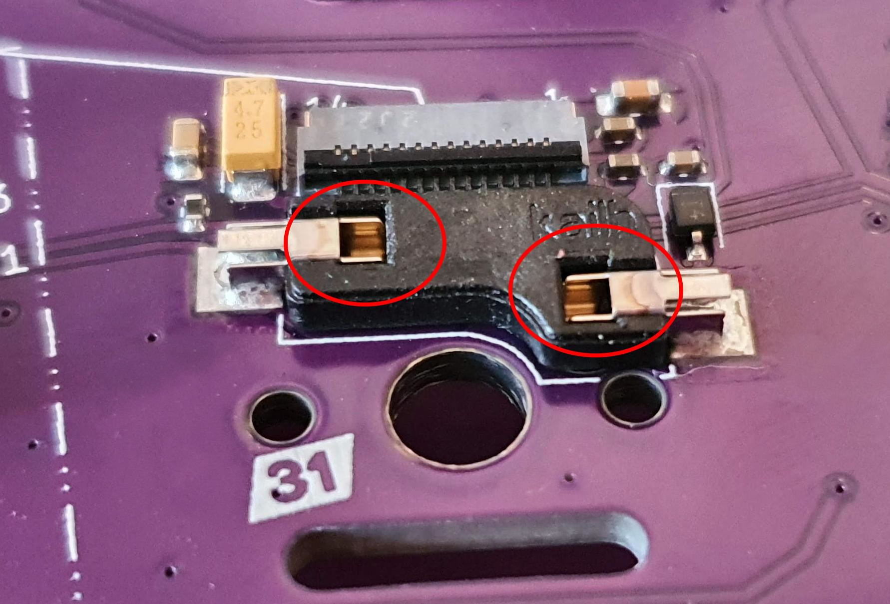
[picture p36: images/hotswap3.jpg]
No key switch
   
   Now your assembly should look like this:
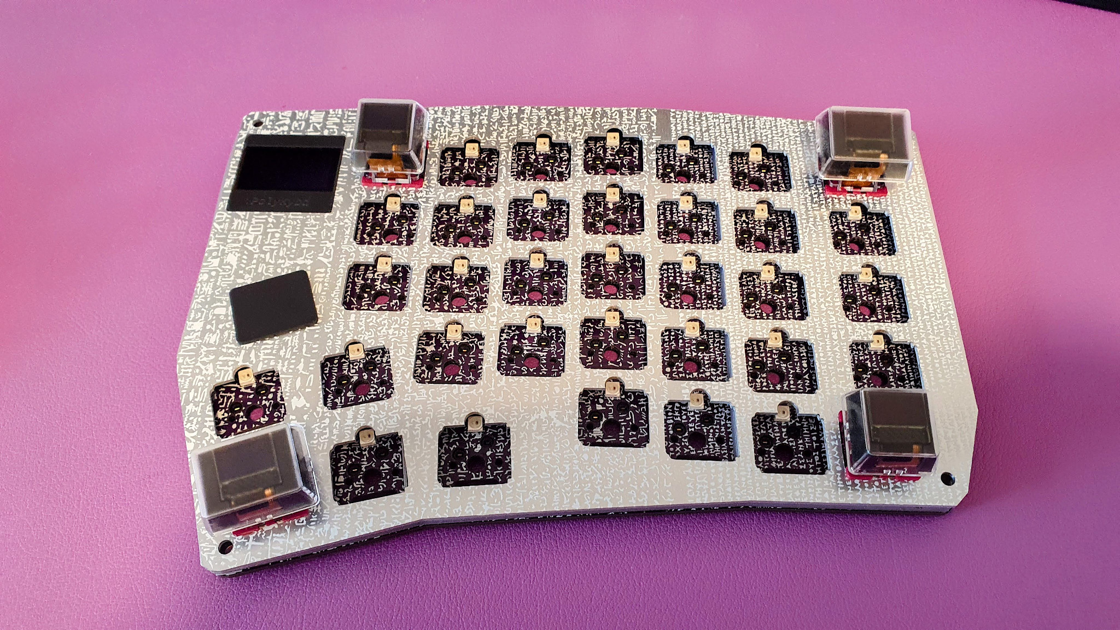
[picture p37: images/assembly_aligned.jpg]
Aligned
   
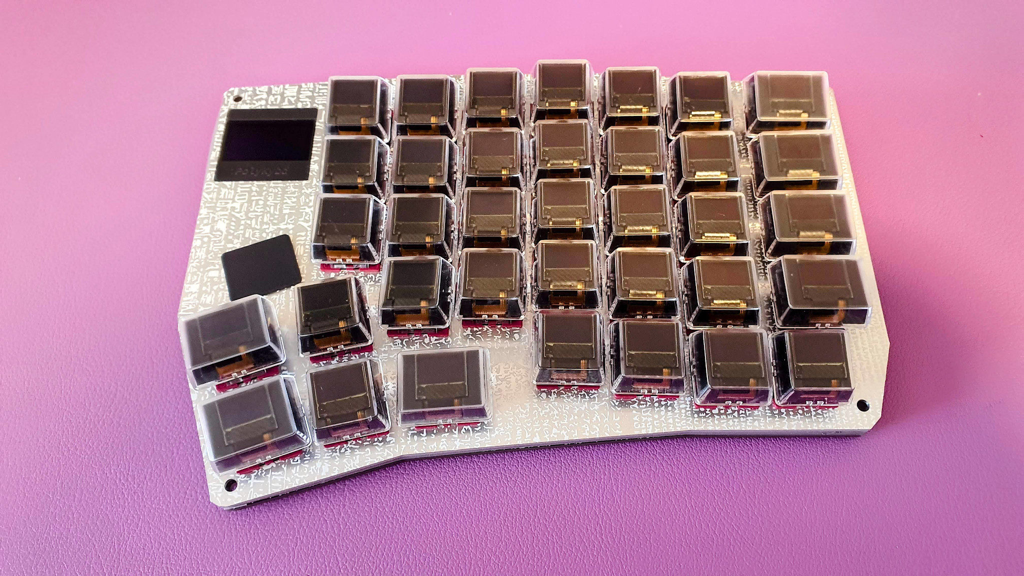
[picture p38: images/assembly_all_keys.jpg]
All keys inserted
9. Insert the remaining key switches in the same way and check that the pins are visible as indicated above: 
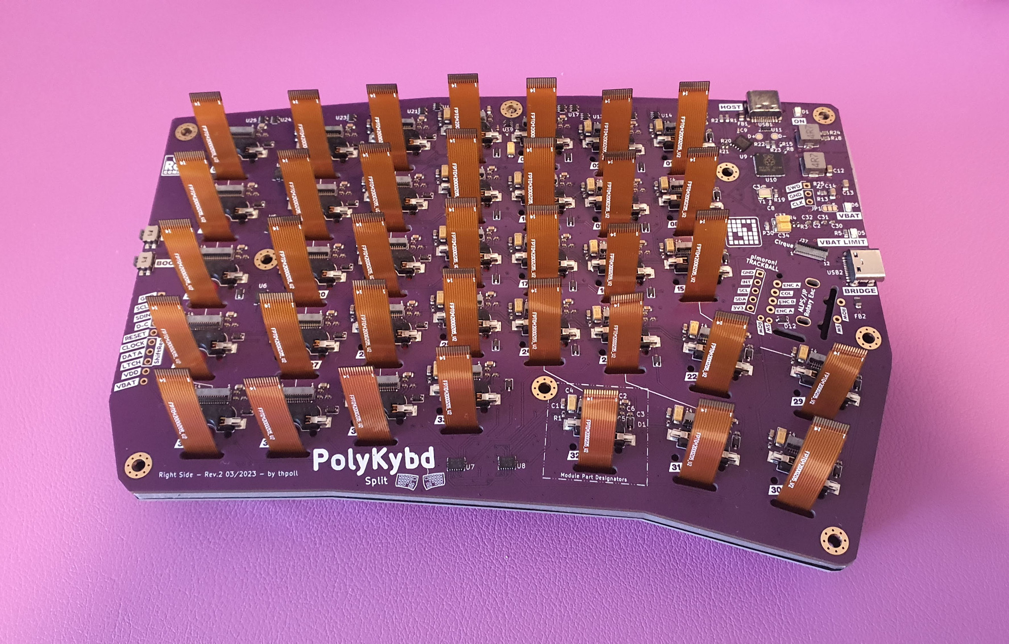
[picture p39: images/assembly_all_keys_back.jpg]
All keys inserted (from backside)
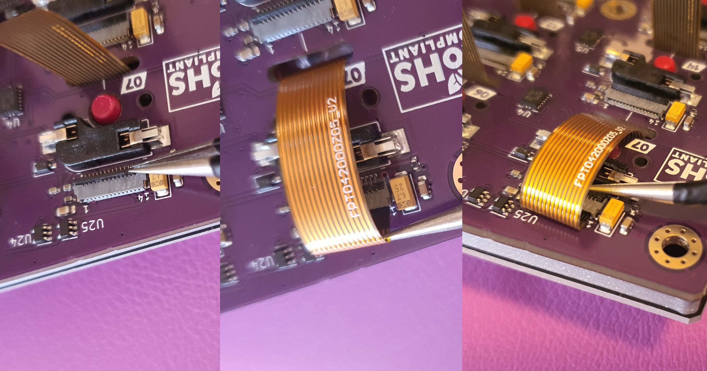
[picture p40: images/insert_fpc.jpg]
Insert the FPC
10. Start inserting the flex cables into the sockets:  If the flex cable is not long enough for you, press the key switch to make it longer. But it should also work without doing that. You cas use some tweezers or also a toothpick to first lift the flap to unlock the socket. Insert the end part into the socket, again recommended with tweezers, but also works without (so with your hands - finger!). After inserting the flex cable, lock the socket. Lower the little flap on the back-side of the socket you lifted at the beginning:  The finished version should look like that: FPC inserted Now repeat this procedure for every flex cable.
11. In case you have a case with revision r4 or higher it's now time to insert the hex nuts into the corners.
12. Before putting the whole assembly into the case, do a function check! If you have not yet flashed the firmware to the board, build one according to the instructions on https://github.com/thpoll83/qmk_firmware/blob/PolyKybd/keyboards/polykybd/readme.md and flash by first pressing the boot button and then connecting the USB-C while holding the button. After you connect, just release the button and copy the .hex file to the USB drive and you are set. There is no need to connect the second side (depending on the firmware version). When connected to power, after a second or two, all displays should show some characters. If not, disconnect the cable again, release the lock of the FPC display socket in question and re-insert the FPC cable, lock again and reconnect the USB-C port.
13. While still connected to USB-C press every key once. Each pressed key should invert its display contents. If not one or both pins might have been bent when inserting the key switch. If that is the case, pull the key switch out again, make the pins straight again and carefully insert one more time.
14. After we confirmed that all displays and all keys do work, put the assembly into the case: Insert into case Start on the inner side, where the two halves are connected by the bridge USB-C socket. You maybe have to give it a gentle push on the other side to go in.
15. Insert the 4 hex screws and tighten them carefully. One halve assembled Now repeat with the other side ;)
16. Connect the two halves with the short USB-C to USB-C cable.
17. Finally connect the left side with the USB-C cable connecting to the host system and you are done!
18. Congratulations! You made it! PolyKybd Split72 In case you experience any issues, please let me know or make a PR on the build guide!

The fun just starts now! You will recognize that there are a lot of ways to play around with this keyboard.

## Here are some more notes on the firmware:

- Currently, PolyKybd supports QMK as firmware. You can find a lot of information on https://docs.qmk.fm/
- If you want to make use of any unicode input supporting character like emojis or characters like Æ, Ç, È etc. you need to select the input method of your operating system after pressing the Language selection key [ 🌐 ]:
  - [ Mac ] for unicode input on MacOS (Follow the [MacOS directions](https://github.com/qmk/qmk_firmware/blob/master/docs/feature_unicode.md#-macos-))
  - [ Lnx ]	for unicode input on Linux using I-BUS and compatible applications/window managers
  - [ BSD ]	for unicode input on BSD (unimplemented in QMK, see [QMK documentation](https://github.com/qmk/qmk_firmware/blob/master/docs/feature_unicode.md#-bsd-))
  - [ Emcs ] for unicode input in Emacs *(untested)*
  - [ Win ] for unicode input on Windows until code point `U+FFFF` (basically excluding any emoji, additionally you might have to run `reg add "HKCU\Control Panel\Input Method" -v EnableHexNumpad -t REG_SZ -d 1` to enable that feature on Windows)
  - [ WinC ] for unicode input via WinCompose (Please install [WinCompose](https://github.com/samhocevar/wincompose/releases/download/v0.9.11/WinCompose-Setup-0.9.11.exe) first)

This project has been an incredible amount of work, please consider supporting me if you like it:
[https://ko-fi.com/polykb](https://ko-fi.com/polykb)
Please support me

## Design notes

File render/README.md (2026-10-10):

# Marketing renders of the split72

Two paths, both driven from the KiCad boards in `poly_kybd/`.

## 1. Quick: KiCad's own raytracer

```bash
render/export_boards.sh --png      # also writes render/out/split72_{left,right}_kicad.png
```

`kicad-cli pcb render` takes `--rotate`, `--zoom`, `--perspective`, `--floor`
and `--quality high`. It is good enough for a product shot, but it has no real
glass, no area lights and no camera depth of field.

## 2. Blender (Cycles)

```bash
render/export_boards.sh            # render/out/split72_{left,right}.wrl, ~90 MB each
blender -b --python render/blender_scene.py -- \
    render/out/split72_left.wrl render/out/split72_right.wrl render/out/hero.png 256 1920
```

The arguments after `--` are: left VRML, right VRML, output PNG, Cycles
samples, width in pixels (16:9). The script also saves `hero.blend` next to
the PNG. Open that in the Blender GUI to move the camera, add an HDRI or set up
an animation, for example a turntable on the `piv` empties.

What the script sets up:

- both halves on a dark floor, 5 cm apart and splayed 10°
- three area lights (key, fill, rim) and a 50 mm camera at f/4 with depth of field
- the clear outer keycaps changed to transmissive glass (VRML only carries a
  diffuse colour plus transparency)

### Tuning materials on one key

```bash
blender -b --python render/key_scene.py -- render/out/key.png 64 1000
```

`key_scene.py` builds one 1U key (SW_K_2: switch, socket, stem, display,
flex cable, outer cap) from the model files with the board's own offsets, over
a patch of PCB and of the aluminium plate. It renders in about a minute and
saves `key.blend`. Edit the `ROLES` table in `render/materials.py`; the full
scene uses the same table, so a look settled on the key carries over. Each role
matches the model's source colour exactly (`TOL` 0.001), since the switch
housing (0.098) and the display face (0.1) differ by only 0.002.

```bash
blender -b render/out/key.blend --python render/key_views.py -- render/out/key_views 128 1000
```

⚠️ `photo_view.py` and `topview.py` load the saved `render/out/hero.blend`, and
`textured_parts.add()` keeps the decals and flex cables a saved scene already
has. After changing `poly_kybd/models/flex_cable.py` (or the decal geometry),
rebuild that scene first, from the import checkpoint, in about a minute:

```
blender -b render/out/hero_imported.blend --python render/rebuild_scene.py
```

Otherwise every photo and top view keeps the old flex route; `add()` prints a
WARNING when the scene's flex no longer matches.

`key_views.py` loads `render/out/key.blend`, re-applies the materials, lights the
display with one legend from the layer-0 atlas (KC_A by default) and renders
the key from five directions: front, front_left, side, top and low.

### Display and flex textures

```bash
python render/gen_textures.py      # Blender's python: numpy + Pillow
```

writes `textures/display_front.png`, `display_front_top.png`,
`display_rim.png`, `flex.png`, `flex_traces.png` and `braid.png`.
`display_front_top.png` is the display face with lighter glass, for
`topview.py`: seen from straight above, the photo view's calmer colours read
as one black square. The display face and the flex are a
reconstruction traced from a photo of the real part
(`textures/source/oled_module_photo.jpg`, FPT042000Z05_V2): the glass and its
cut edge, the dark panel, the striped sticker with the lot number, the black
sticker over the flex with the flex fading into its shadow, the traces,
part number and contact fingers. `STYLE = "photo"` uses the photo itself
instead. ⚠️ The photo is not evenly scaled (29.1 px/mm along the display,
24.3 across); `keymatch.A_*`, the active area the lit legends and the host
editor's display quads use, is centred in the photo's dark panel, so a
different photo means re-measuring it. `display_rim.png` drives a glass coat
on the rim and `flex_traces.png` makes the copper traces metallic
(`materials.py`).

### Re-rendering without re-importing

```bash
blender -b render/out/hero.blend --python render/rerender.py -- render/out/hero2.png 64 1600 1.0 0
```

Arguments: output, samples, width, light scale, exposure (stops). It re-applies
`materials.py` and renders: about 2 minutes for the full keyboard instead of
the ~25 the import and merge take. Every material remembers its role
(`pk_role`), so this works on a scene whose colours were already changed.

### White studio and the bridge cable

```bash
blender -b render/out/hero.blend --python render/rerender.py -- render/out/hero_white.png 128 2560 1.0 0 5 white bridge+host 0 40
```

The last three arguments are the splay of each half in degrees (the import
sets 10), `white` and the cables: `bridge`, `host` or `bridge+host`. An
optional ninth sets the f-stop; the default 0 turns depth of field off, so
the keyboard is sharp front to back. An optional tenth sets the camera's
elevation in degrees (the import sets ~33); the black card moves with it,
since the caps' mirror direction follows the camera.

`host` adds a straight plug on the left half's USB1 (the top-edge port) and
a braided cable that runs back across the desk and out of frame.

`white` (studio.py) replaces the dark floor with a white seamless cove. It
adds a light that reaches only the cove (Cycles light linking), so the floor
goes white at exposure 0 while the dark case stays dark. It also sets AgX's
Medium High Contrast look. Brightening the whole image with exposure instead
turned the case mid grey.

The same option puts a matte black card above and behind the keyboard, out of
frame. The camera looks down at about 33 degrees, so each flat cap top
mirrors whatever sits 33 degrees up behind the keyboard. The rim light used
to sit there (0, 0.8, 0.5), and every cap showed a white patch that hid its
display. With the card there, the caps mirror black and the displays read
through them. This is the "dark field" trick product photographers use for
glass. The rim light now sits higher.

`bridge` (bridge_cable.py) adds the USB-C cable between the inner USB2
ports. The halves sit ~50 mm apart, less than two straight plugs need, so
the plugs are 90 degree ones. The cable leaves each plug towards the back
and lies in a U on the desk behind the keyboard. The overmold (9 x 22.5 x
6.5 mm, inside the USB-IF 12.35 x 6.5 mm envelope across the plug) sits
against the case wall, read from the case mesh. The sleeve carries
`textures/braid.png`. At hero framing the cable is ~10 px wide, so the braid
shows only in close-ups. The receptacles themselves have no 3D model yet:
the KiCad library ships none for the HRO TYPE-C-31-M-12.

### Which Blender

Use **Blender 4.1.1 from blender.org**. It is the last release that bundles
the X3D/VRML importer (4.2 moved it to an online extension), and the official
builds carry OpenImageDenoise. The Ubuntu/Debian package lacks the denoiser,
so its images stay grainy at any sample count you would wait for. The scripts
switch denoising on whenever the build has it.

### Editing an imported mesh (bmesh)

`profile.dent()` and `rgb.clear_case()` rebuild geometry that came in from
VRML. Each of these steps failed silently once, so skipping one gives a wrong
image rather than an error:

- **Weld first.** VRML stores every triangle's corners separately, so the
  mesh has no shared edges and no boundary loop to find. `remove_doubles`
  fixes that.
- **Weld in world millimetres.** The imported objects carry a scale. A 1 µm
  threshold in the object's own frame merged the case's pieces into one, and
  the whole case went opaque. Measure with `matrix_world * 1000`.
- **Map vertices by identity, not `v.index`.** bmesh renumbers vertices when
  faces are removed and added, so an index taken before the edit points at a
  different vertex after it.
- **Call `normal_update()` on new faces.** Without it, the rebuilt cap tops
  rendered as mirrors.
- **Set sharp edges after a weld** (`set_sharp_from_angle`, 30°). Once the
  corners are shared, smooth shading spans them, and the caps looked like a
  kaleidoscope.

⚠️ **`ShaderNodeMix` carries float, vector and colour sockets under the same
names.** Setting `data_type = "RGBA"` does not make `inputs["B"]` the colour
input, and assigning a colour to the float socket raises an error before the
render writes anything. Select the sockets by `type == "RGBA"`, as
`screens.py` and `rgb.clear_flex()` do.

### Why VRML and not GLB or STEP

KiCad 9 can export GLB and STEP, but both go through OpenCASCADE, which drops
every `.wrl` model. The keycaps, stems, displays, cables and switches are all
`.wrl`, so a GLB comes out as a bare populated PCB. The VRML exporter uses the
3D viewer's own loader and keeps everything.

The Blender 4.0 import of one half takes about 7 minutes and creates about
87k objects. Blender 4.2 and later ship the X3D/VRML importer as an extension
("Web3D X3D/VRML2 format"), so install that first there.

### Known gaps in the board models

- the USB-C receptacles (HRO TYPE-C-31-M-12) have no model: the KiCad 9
  library ships none, and inside the case only the plug shows
- the key displays are unlit in the hero and top views; only the product
  photo's viewpoint (below) turns them on (`screens.py`)

## The product photo's viewpoint

```bash
blender -b render/out/hero.blend --python render/photo_view.py -- render/out/photo_view.png 128 2600
```

The composition of `images/PolyKybdSplit72p.jpg` on the white studio: from
in front, 42 deg above the desk, a 35 mm lens, the halves 35 mm apart with
their inner ends brought forward (the left 2 deg, the right 9 deg, measured
on the photo's top edges), the bridge cable looping in front of them
(`bridge_cable.add(toward=-1, clear=...)`: the 90 deg plugs turn the cable
forwards and it runs straight down the gap before the U) and the host cable
leaving the left half's back edge. The optional arguments after the width
are the gap (m), the turns as "left,right" (deg, negative = inner end
forward), elevation (deg), lens (mm) and the share of the frame's width the
keyboard fills. The log reports the bridge cable's closest approach to a
case.

The displays are on, as in the photo (`screens.py`): every key display shows
its layer-0 legend and both status panels their layer-0 screen, as emissive
quads over the active areas. The pictures are the raw framebuffers in
`textures/screens_layer0.png` (an atlas, cells listed in
`screens_layer0.json`) and `textures/status_{left,right}.png`, drawn by
PolyKybdHost's layout-editor preview code over the firmware's default keymap:

```bash
QT_QPA_PLATFORM=offscreen ../PolyKybdHost/.venv/bin/python render/export_screens.py
```

Re-run it when the keymap or the legends change. Two keys stay dark: (8,0)
has no display, and (6,1) holds `KC_HYPR`, for which the preview draws no
legend.

## Close-ups of the lit keys

`closeup_view.py` frames a block of the left half's keys, for the docs' close-up
photos. Its legends come from a named atlas, so a close-up can show any layer
or an app's overlay:

```bash
# layer 1 (Qwerty Stag!, what a fresh board boots on) instead of the shipped layer 0
QT_QPA_PLATFORM=offscreen ../PolyKybdHost/.venv/bin/python render/board_layer.py _L1 /tmp/board_L1.json
QT_QPA_PLATFORM=offscreen ../PolyKybdHost/.venv/bin/python render/export_screens.py ../PolyKybdHost /tmp/board_L1.json 1
# GIMP's overlay icons over those legends, as update_displays() ORs them
python render/overlay_atlas.py /tmp/board_L1.json ../PolyKybdHost/polyhost/res/overlays/gimp_template.mods.png screens_layer1 screens_gimp_l1
PK_STRENGTH=3 PK_STATUS=_l1 blender -b render/out/hero.blend --python render/closeup_view.py -- \
    out.png 128 2100 screens_gimp_l1 0.47 0.6 0.15 52 0 55
```

The lit pixels sample their texture with `Closest`, so one OLED pixel stays one
square, and carry a faint blue cast (`screens.LIT_TINT`). ⚠️ At the default
emission strength (6) a close-up's legends clip, and AgX bleaches clipped
highlights to white, which hides the tint: strength 3 keeps them near
(228, 233, 237). ⚠️ The camera's near clip is 5 mm; Blender's default 0.1 m
cuts the front keys off at close-up distance.

### The RGB night shot

The docs' RGB close-up (`rgb-keycaps-closeup.jpg`) is the same view at night:
the studio off, the clear case, the stepped stem profile with a dented cap
top, and light only from the per-key LEDs. About 75 minutes on 4 CPUs:

```bash
PK_RGB=170,280 PK_EMIT=6000 PK_GLOW=15 PK_FLEX=1,0.15 PK_LED=0 PK_HIDE_ROLES="diffuser resin" \
PK_PROFILE=stepped PK_DENT=0.3,2.5 PK_CASE_GLOW=300,420,80 \
PK_POWER_LED=0.15 PK_CASE_LEDS=30 PK_INDICATOR_HAZE=200 PK_HAZE_RADIUS=0.02 PK_INDICATOR_RADIUS=0.006 \
PK_FOCUS=0.36,0.42 PK_LOOK="AgX - High Contrast" PK_STRENGTH=5 PK_STATUS=_l1 \
blender -b render/out/hero.blend --python render/closeup_view.py -- \
    out.png 1024 1400 screens_layer1 0.45 0.45 0.085 48 -15 22 6.3
```

- `PK_RGB="h0,h1"` turns the studio off and spreads a hue gradient over the
  LEDs from left to right; `PK_EMIT` puts an emissive 3 mm square over each
  LED. It sits 4.4 mm above the PCB (`PK_EMIT_Z`), in the plate opening where
  the diffuser frame glows on the board. ⚠️ The bare LED lies under the plate,
  and from there almost nothing reaches the caps in Cycles (image mean 5.9
  against 30); the frame itself is hidden, because its frosted resin traps
  the light (4x the LED power changed the image mean by 2%).
- `PK_GLOW=15` adds a faint volume glow in the caps, which puts the bright
  rims of the photo back on the cap edges: a wall seen edge-on holds a longer
  path. ⚠️ Cycles does not find the light that the clear walls guide up from
  the LEDs, so without it the rims are dark, and putting the diffuser frame
  back does not help (the image only gets darker). At 40 the caps look milky.
- `PK_FLEX="dim,roughness"` makes the display flex a clear film with no
  specular and no coat, and its copper traces fully metallic (`clear_flex()`).
  At the studio values its satin film lit up the space under every cap.
- `PK_PROFILE` re-poses every cap, display and legend to the stepped,
  stepped-uniform or curved stem profile (`profile.py`, the angle and lift of
  `keycap_stem.scad`'s variants). `PK_DENT="depth,rim"` presses the cap tops
  into a shallow dent with a soft rim; the model's top is a few large
  triangles, so it is rebuilt by a constrained Delaunay fill first.
- `clear_case()` keeps the lid and the status display holder opaque: they
  come in merged with the case (one source colour), so every piece narrower
  than 100 mm gets an opaque copy of the material.
- The indicator LEDs (D1 red, D5 green, D6 yellow on the back of both halves)
  are hidden point lights; `PK_CASE_LEDS` bakes their light into the clear
  case's edges, and the red one gets a soft glow (`PK_INDICATOR_HAZE`). ⚠️ A
  light inside a clear solid never reaches the camera in Cycles, because
  shadow rays stop at glass; the same is why the key LEDs need `PK_EMIT`.
- `PK_FOCUS="fx,fy"` moves the depth-of-field focus off the target, here onto
  the front three rows.

Two approaches that do not work in Cycles here, so the next attempt can skip
them: a Point Density texture over the LED positions contributed nothing to
the caps, even with its bounding box fixed; and a vertex attribute read inside
a volume shader does not interpolate. `glow_from_leds()` bakes the falloff into
a surface colour attribute instead.

To tune one of these values against the photo, use the `render-variant-grid`
skill (`.claude/skills/render-variant-grid/`).

⚠️ `textured_parts.fit()` is cached per half. A fit taken after `profile.py`
has re-posed the displays drifts by 3.5 mm of height, which once put the LED
emitters inside the plate.

### The Eden intro video

The docs' First run video plays the Eden boot animation on both halves seen
from above, in the night look. Rendering every frame in Cycles would take a
day, but only the keycap screens and the backlight change during Eden, and
light adds. So `eden_view.py` renders a few layers once, and `eden_video.py`
sums them per frame in about a second:

```bash
export PK_EMIT=6000 PK_GLOW=15 PK_FLEX=1,0.15 PK_HIDE_ROLES="diffuser resin" \
  PK_PROFILE=stepped PK_DENT=0.3,2.5 PK_CASE_GLOW=80 PK_POWER_LED=0.15 PK_CASE_LEDS=30 \
  PK_INDICATOR_HAZE=200 PK_HAZE_RADIUS=0.02 PK_INDICATOR_RADIUS=0.006 PK_LOOK="AgX - High Contrast" \
  PK_ELEV=65 PK_SPLAY=0 PK_SPLAY_RIGHT=0 PK_GAP=38.5 PK_FLOOR=0.02,0.45
for p in uv id base ambient w c1 s1; do
  blender -b render/out/hero.blend --python render/eden_view.py -- layers/$p.exr 256 2560 $p
done
BPY="$(dirname "$(readlink -f "$(command -v blender)")")/4.1/python/bin/python3.11"   # Blender's own Python
PK_AMBIENT=0.07 PK_ASPECT=2.35 PK_CROP_CY=0.55 "$BPY" render/eden_video.py layers eden-intro.mp4 25
```

- The backlight is QMK's `CYCLE_LEFT_RIGHT` rainbow, which Eden turns on
  (`tutorial_rgb.c`). Its light is rendered three times in white, weighted 1,
  (1 + cos)/2 and (1 + sin)/2 of the rainbow's phase over x (`w`, `c1`, `s1`);
  any moment of the rainbow is a sum of those, to its first harmonic, so its
  colours come out a little softer than real HSV. `startup_anim_rainbow_level()`
  fades it out as on the board.
- The screens come from PolyKybdHost's `tools/fw_anim_sim.py`, the port of
  `startup_anim.c`. The `uv` and `id` layers say which screen pixel each image
  pixel sees through the glass: the screens emit their own coordinates, the
  glass is pure refraction, so one sample per pixel is exact. They render at
  twice the width and are averaged down.
- `base` holds the indicator LEDs and `ambient` a dim room light, which
  `PK_AMBIENT` scales without a new render. `PK_TIMES=1500,7000` with a `.png`
  output writes only those frames, for comparing settings.
- `PK_SPLAY=0` lines the halves up parallel and `PK_GAP` keeps the 38.5 mm gap
  of the splayed hero shot. `PK_FLOOR` makes the desk a dark satin that
  catches the rainbow's spill.

About 1 hour 50 minutes on 4 CPUs at 2560 wide; the 356 frames take another
20 minutes.

## The bare PCB shot (pcb2blender)

One split72 half as the fab delivers it, socket side up, for the docs' PCB
page: the right half, from the angle of the Rev.2 photo it replaced (the
left half works the same way, with `PK_AZIM=8` for the mirrored view). It does not come from the hero scene: the VRML route flattens the
board's layers into flat-coloured geometry, so the mask, silkscreen and
copper never looked like a board. [pcb2blender](https://github.com/30350n/pcb2blender)
exports the layers as artwork and imports them into its own PCB shaders, so
the traces show under the mask and the pads are real copper.

Setup, once per container (pcb2blender's importer needs Blender 5.1):

```bash
git clone https://github.com/30350n/pcb2blender /tmp/pcb2blender
git -C /tmp/pcb2blender checkout 2a2ac82 && git -C /tmp/pcb2blender submodule update --init --recursive
curl -sSLO https://download.blender.org/release/Blender5.1/blender-5.1.2-linux-x64.tar.xz && tar -xf blender-5.1.2-linux-x64.tar.xz
B51=$PWD/blender-5.1.2-linux-x64
apt-get install -y libegl1 libgl1                       # skia-python needs libEGL
$B51/5.1/python/bin/python3.13 -m pip install error-helper==1.4 pillow==11.3 skia-python==138
curl -sSL -o studio_small_09.hdr https://dl.polyhaven.org/file/ph-assets/HDRIs/hdr/2k/studio_small_09_2k.hdr
```

Then, from the repo root:

```bash
python3 render/pcb_shot/board_copy.py poly_kybd/poly_kybd_split72_right.kicad_pcb poly_kybd/_shot_right.kicad_pcb
cp poly_kybd/poly_kybd_split72_right.kicad_pro poly_kybd/_shot_right.kicad_pro
xvfb-run -a python3 render/pcb_shot/export.py poly_kybd/_shot_right.kicad_pcb render/out/right.pcb3d
rm poly_kybd/_shot_right.*
$B51/blender -b --python render/pcb_shot/import.py -- render/out/right.pcb3d render/out/pcb_right.blend
PK_HDRI=$PWD/studio_small_09.hdr $B51/blender -b --python render/pcb_shot/shot.py -- \
    render/out/pcb_right.png 128 2800 render/out/pcb_right.blend render/out/right.pcb3d
```

The export takes about 1.5 minutes and the import 3. A 32-sample, 900 px
preview takes about a minute. Traps:

- **The mask colour is set in shot.py, not in the board.** A custom stackup
  colour (`#RRGGBB`) reaches the importer as 0..255 and the mask renders
  white. The copy therefore says `Purple`, which picks the mask shader, and
  shot.py sets its two colours (over copper, over bare board) to the Rev.2
  boards' redder purple. pcb2blender's own purple is a blue-violet.
- **Register the add-on before opening the .blend.** Its materials are built
  from node types it defines; opened without it, every material renders white.
- **The exporter is a pcbnew GUI plugin.** export.py loads its modules without
  the wx dialog and swaps `pcbnew.GetBoard()` and `pcbnew.ExportVRML()` (which
  writes nothing without the editor frame) for the loaded board and kicad-cli.
- **The board copy needs its own .kicad_pro**, or `${KIPRJMOD}` does not
  resolve and the repo's models drop silently.
- **Khronos PBR Neutral, not AgX.** AgX turned the mask and the parts pastel.
  PBR Neutral keeps base colours, but clips a bright highlight, so exposure
  cannot rescue too much light: the key is 12 W and the HDRI 0.15.
- **The flex slots are cut in shot.py.** KiCad's VRML export cuts round drills
  only, so each key's 9.76 x 1.7 mm plated slot arrives as solid board. The
  .pcb3d's pad records give each slot; their positions map onto the board
  through the solder joints, which are named after their pads (the fit is
  exact on 1846 joints). Passing the .pcb3d as the fifth argument cuts them.
  pcb2blender's drill shapes are one off from KiCad 9's (1 = circle, 2 =
  oblong), so a round drill reads "OVAL" and a slot "UNKNOWN".
  ⚠️ The pad rotation goes in as is, the way the importer places its own
  joints. Negated, it changes nothing at 0 and 90 degrees and crosses every
  rotated thumb-key slot with a second cut at the mirrored angle (an X).
  The cutter's faces are wound outward. With the walls facing the hole, a
  bright mirror-like plating reflects the floor and reads white, so the
  plating is a deeper gold (`PK_SLOT_COLOR`, `PK_SLOT_ROUGH` 0.5).
  ⚠️ Each cutter is 0.03 mm over its drill. The import already opens most slots
  (38 of 46 on the right board), and a cutter whose walls coincide with an
  existing hole leaves the EXACT solver undecided: one encoder slot kept its
  whole capsule, a 20 mm copper rod standing out of the board, with no error.
  After a change here, check the board's z range after the cut (it should stay
  at about +-0.80 mm) before spending an hour on a render.
- **Component colours are matched to the Rev.2 photo** in `COLOR_MATCH`,
  keyed on the colour each material imports with: mat4cad reads near-black
  plastics as mid grey, the Kailh contacts' gold as plastic and their tin as
  a mirror that reads as glass. Compare at full resolution, not downscaled:
  render a crop with `PK_BORDER=x0,y0,x1,y1` (fractions, origin bottom left)
  at the final width and put it beside the matching photo crop.
  ⚠️ The photo is a reference for colour and camera angle only, not for
  features: its board is Rev.2, whose flex slots were unplated. The rev3.3
  slots are plated, so the render shows copper walls the photo lacks. The
  photo shows the right half.
- No depth of field: the board is sharp to the far corner. The camera
  (`PK_ELEV` 50, `PK_AZIM` -8, `PK_LENS` 24, `PK_DIST` 0.15 m) is close and
  wide like the phone photo; it tracks the board's centre.
- **Part markings are added in shot.py** (`MARKINGS`): the stock models carry
  none, and the RP2040, the flash, the inductors, the crystal and the shift
  registers show theirs clearly. export.py writes `<board>.parts.json` (each
  footprint's place) beside the .pcb3d; shot.py finds each part's body there
  and lays the text on its top face, upright to the camera.
- **The hotswap pads' solder is added in shot.py.** The Kailh footprint has
  no paste layer, so the importer's SMART mode skips its 288 SMD pads and they
  render as bare gold. shot.py adds the joints, placed relative to the
  importer's joint on an FH34 socket pad. ⚠️ The reference must come from a
  part on the sockets' face: a joint from the other face puts all 288 under
  the board, and the render looks unchanged. Paint the joints a debug colour
  and look straight down (`PK_ELEV=89.9 PK_AZIM=0`) before believing a
  placement. Each joint is a fillet on the two outer tabs only (the inner
  pads lie under the black body): the tin covers the land and climbs the
  tab's end and sides in a concave arc (`PK_HS_SOLDER_H` 0.2 mm at the tab,
  falling to the land over `PK_HS_SOLDER_REACH` 0.8 mm). It is built in the
  socket's own frame, the socket's rotation read off its two small holes.
  Over the tab's outer end sits a convex bead (`PK_HS_BEAD_H` 0.35 mm,
  `PK_HS_BEAD_R` 0.7 mm) that stands above the tab: the concave fillet
  alone does not show at the full image's scale.
  The importer's joints in the two switch-pin holes are removed: the switch
  plugs into the socket and is never soldered.
- **The FH34 sockets are recoloured per object**: their housing shares its
  imported colour with the 74HC595 bodies, so COLOR_MATCH cannot separate
  them. The
  Kailh model hangs 0.27 mm clear of the board, so shot.py seats it
  (`PK_HS_SEAT`) and the tabs rest on their pads.
- **mat4cad's 0.05 mm edge bevel is cut to 0.015 mm** (`PK_BEVEL`). At the
  default, every 0603 part carries a bright rim along each edge and corner.
- A 2800 px, 128-sample render takes about 60 minutes on 4 CPUs at the
  default close camera (45 with the earlier 70 mm, 0.45 m view), longer than
  a background command's default limit: run it detached and watch its log
  (see `polykybd-claude/docs/web-session.md`).

## Top view for PolyKybdHost's layout editor

```bash
blender -b render/out/hero.blend --python render/topview.py -- render/out/topview.png 4800 96
```

An orthographic render straight down on both halves, unsplayed, without
cables, plus `topview.json`. The matrix labels come from PolyKybdHost's KLE
file: the script reads `../PolyKybdHost/polyhost/res/polykybd-split72.json`
(a checkout next to this repo), or the path given as a 4th argument.

- `keys`: per key display, the KLE matrix label (`"row,col"`, the label
  PolyKybdHost's `polykybd-split72.json` uses), the side, the board
  reference, the rotation and `oled`, the 72x40 active area as four image
  pixels in the OLED's own order (top-left, top-right, bottom-right,
  bottom-left, so the first corner is framebuffer pixel 0,0);
- `status_displays`: each half's 128x64 status display as a pixel bbox;
- `mm_per_px`, and the KLE match residual per half.

The labels come from matching each board key to the nearest KLE key after a
translation fit (19.05 mm per U); the largest residual is ~4.5 mm, well under
half a key, and the script refuses a match that reuses a KLE key.

From straight above every flat cap top mirrors what is directly overhead, so
the black card goes overhead and casts no shadow. The overhead and rim lights
are hidden from reflection AND transmission rays: a display decal's coat
mirrors a light up through the clear cap, and that transmission path laid a
white veil over every display.

## Web viewer

`render/web/index.html` is a `<model-viewer>` page (orbit, zoom, AR on phones)
with a switch between the whole keyboard and one key. Build its two models
from saved scenes:

```bash
blender -b render/out/hero.blend --python render/export_web.py -- render/web/keyboard.glb 80000
blender -b render/out/key.blend  --python render/export_web.py -- render/web/key.glb 60000
for m in keyboard key; do base64 -w0 render/web/$m.glb > render/web/$m.glb.b64.txt; done
```

The page loads `<name>.glb.b64.txt`, not the `.glb`: the artifact host serves
no binary model type, so each model ships as base64 text and the page decodes
it once into a `blob:` URL. The full scene comes out at 131k triangles,
7.9 MB (10.6 MB as base64): the plates and the textured parts are kept out of
the decimation, so the budget is a target rather than a cap. The plate's
Rosetta art is baked into a soft texture (a third of 1536 px, blurred, half
strength; arguments 3 and 4), since the glyphs read as speckle at web size.

`export_web.py` merges the meshes per material, dissolves coplanar faces (the
silkscreen art is most of the triangles) and decimates to the budget. The GLBs
are not compressed: Draco and meshopt need a decoder fetched at runtime, which
an artifact page cannot do, so the triangle budget is the size control
(about 30 bytes per triangle; artifact files are capped at 15 MB).

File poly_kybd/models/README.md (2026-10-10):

# 3D models for the KiCad 3D view

Referenced from the split72 boards as `${KIPRJMOD}/models/<file>`.

| File | What | Source |
|---|---|---|
| `keycap_display.wrl` | the 72x40 keycap OLED | PolyKybd |
| `keycap_flex_cable.wrl` | its flex cable at full length: display, down through plate and PCB slot, into the bottom-side FH34 connector | `flex_cable.py` |
| `keycap_display_cable.wrl` | the old, short cable (ended 5.7 mm above the PCB); no longer referenced | PolyKybd |
| `keycap_stem_r7.wrl`, `keycap_stem_r7_1u25.wrl` | keycap stem, 1U and 1.25U | PolyKybd |
| `outercap1u.wrl`, `outercap1u25.wrl` | clear outer keycap, 1U and 1.25U | PolyKybd |
| `display_w_holder.wrl`, `right_side_model.wrl` | display holder, right case | PolyKybd |
| `DHVQFN-16-1EP_2.5x3.5mm_P0.5mm_EP1x2mm.step` | 74HC595BQ shift register; KiCad's footprint names this file but the KiCad 9 3D library lacks it | `gen_models.py` |
| `FH34SRJ-14S-0.5SH_50_.step` | Hirose FH34SRJ 14-pos FFC connector (one per key display) | `gen_models.py` |
| `FH34SRJ-12S-0.5SH_50_.step` | the same in 12 positions, for J37 (the status display's connector) | `gen_models.py` |
| `screw_M3_pan_hex_2mm.step` | M3x10 pan head, 2 mm hex socket (1.0 mm deep, 118° drill-point floor, 0.15 mm mouth chamfer), 1.5 mm flat head with a rounded edge; on the 4 outer mounting holes per half (H2, H3, H6, H9), head on the plate top | `gen_models.py` |
| `case_polykybd_split72_{left,right}_r7.wrl` | the FDM case r7, on H5 | `stl_to_wrl.py` from `parts/export/case/case_polykybd_split72_{left,right}_r7.stl` |
| `plate_split72_{left,right}.wrz` | switch plate, flipped (Rosetta artwork up), on SW_K_1 at z 4.2, rotate 0 180 0 | `gen_plates.py` from the plate PCBs (see below) |
| `status_display_holder.wrl` | status OLED holder with the display, on J39 | `gen_inserts.py` from `display_holder_r1.stl` |
| `cover_insert.wrl` | lid for the expansion port, both halves, on J39 | `gen_inserts.py` from `cover_insert_r3_10p.stl` |
| `diffuser_frame_split72_{left,right}.wrl` | one-piece LED diffuser frame (36 diffusers and the web under the plate), attached like the plate: on SW_K_1 at z 4.2, rotate 0 180 0, scale 0.3937 | `gen_inserts.py` from `parts/export/diffuser/diffuser_frame_{left,right}.stl` |
| `SW_Cherry_MX_PCB.wrl`, `SW_Hotswap_Kailh.wrl` | MX switch and Kailh hotswap socket | [keyswitch-kicad-library](https://github.com/perigoso/keyswitch-kicad-library) release v2.0, `3dmodels/3d-library.3dshapes/`, CC-BY-SA 4.0 |

The two switch models used to be referenced as
`${KIPRJMOD}/ThirdParty/keyswitch-kicad-library/modules/packages3d/...`. That
folder was never committed, so they are vendored here.

Each key footprint (`SW_K_*`, `poly_kb:Kailh_socket_MX_Indicators`) carries six
models: switch, socket, stem, display, cable, outer cap. The 1.25U keys are the
outer column and three thumb keys on each half, mirrored between the halves:

- left: `SW_K_1, 8, 15, 22, 29, 34, 36`
- right: `SW_K_7, 14, 21, 28, 29, 30, 32`

Stock parts point at `${KICAD9_3DMODEL_DIR}/....step`, because the KiCad 9
library ships STEP only.

`gen_models.py` (build123d 0.12.0) writes the generated STEP files: the
DHVQFN-16, the FH34SRJ in 14 and 12 positions (`fh34srj(n)`) and the screw. They are
drawn in their footprint's frame, so the boards use zero offset and rotation.
They are approximations from the footprint outline, not vendor models.

### Stock models on custom footprints

Picked by fitting the stock footprint's pads onto ours, after undoing KiCad's
back-side flip (it negates pad Y in the file):

| Footprint | Model | Rotation | Pad fit |
|---|---|---|---|
| `poly_kb:BY25Q64ES-LGA8-2x3` | `Package_SON:Winbond_USON-8-1EP_3x2mm...` | 270 | 0.07 mm |
| `poly_kb:Nexperia 74HC595BQ DHVQFN16` | `models/DHVQFN-16-...` | 0 | 0.12 mm |
| `poly_kb:USON-10` | `Package_SON:USON-10_2.5x1.0mm_P0.5mm` | 0 | 0.005 mm |
| `poly_kb:SMMS0420-2R2M` | `Inductor_SMD:L_Changjiang_FXL0420` | 0 | exact |
| `poly_kb:XL-3030RGBC-WS2812B` | `LED_SMD:LED_RGB_Wuerth-PLCC4_3.2x2.8mm` | 180 | stand-in, 3.2x2.8 for 3.0x3.0 |

### The case

The case rides on mounting hole H5 of each board, as the old `right_side_model.wrl`
did. Its STL frame is the board outline offset by 1.65 mm (wall + clearance), with
the PCB underside at z = 11.5 mm (floor 2 + ledge 9.5), so the offset is the
Edge.Cuts bbox centre minus the case bbox centre, and z = -(1.6062 + 11.5).
**Re-run `stl_to_wrl.py` after re-exporting the case STL.** KiCad does not read
STL, and its VRML2 parser drops a file silently if the layout differs from
`stl_to_wrl.py`'s output (no `creaseAngle`, one node per line).

Back-side footprints (all holes on the right board, H4 on the left) are flipped
by KiCad as 180 deg about X, after the footprint's own 180 deg rotation:

| Model on a B.Cu, 180 deg footprint | rotate | offset |
|---|---|---|
| screw | 180 0 0 | 0 0 -6.6062 (head on the plate top) |
| case (right) | 0 180 0 | 95.727 -131.7882 11.5 |

### Plate, status display, lid

`gen_plates.py` exports each plate PCB as gzipped VRML from a repaired temp
copy; the plate PCBs themselves are untouched. Each plate goes on the half its
name says, **flipped**: the Rosetta artwork is on the plate's B.SilkS and faces
up, the `< LEFT SIDE >` / `< RIGHT SIDE >` labels on F.SilkS face the switch
PCB. Unflipped, each plate also fits the other half (the halves are mirror
images), so outline matching alone cannot tell the two apart.

Both plate outlines have 36 zero-length Edge.Cuts segments, and the expansion-port
cut-out misses closing by 0.01 mm (58.1356 vs 58.1456 on plate_left, 220.4616 vs
220.4716 on plate_right). On plate_left KiCad rejects the whole outline
(DRC: not a closed shape, self-intersecting) and exports a bounding rectangle.

The inserts sit in the plate's cut-outs, flush with its top (5.0 mm above the
PCB top):

| Model | anchor | offset | rotate |
|---|---|---|---|
| status display, left | J39 | 13.438 30.877 2.5 | 0 0 180 |
| status display, right | J39 | 13.558 30.877 2.5 | 0 0 180 |
| cover lid, left | J39 | -4.422 -23.378 4.6 | 0 0 20 |
| cover lid, right | J39 | 4.4226 -23.378 4.6 | 0 0 -20 |

The lid angle was checked by eye: KiCad applies the model's z rotation
clockwise as seen from above, so +20 is the left cut-out's clockwise tilt.

The plate is an aluminium PCB: `gen_plates.py` recolours the export's mask and
board body to grey aluminium (0.58), dark enough that the white artwork reads.

Every part the fab places has a model. The DNP parts deliberately carry none,
so the 3D view shows a board as delivered: SW1 (`poly_kb:PolyJog`, the optional
rotary encoder) and the pin headers DBG1, DBG3 and J38. The other footprints
without a model have no part: the kibuzzard silkscreen labels, the mounting
holes, the test points and the JP1 solder jumper.

⚠️ `kicad-cli` resolves `${KIPRJMOD}` from a `.kicad_pro` beside the board. A
copy of a board without one (a temp file for a test render) drops every model
in this folder with no error; pass `-D KIPRJMOD=<repo>/poly_kybd`. That is how
a test render once showed no hotswap sockets.

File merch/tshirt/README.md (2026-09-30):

# T-shirt designs

Print-ready vector artwork for PolyKybd T-shirts. The SVGs have physical `mm` sizes and a transparent background. All lettering is converted to outlines, so no fonts are needed to print them. Glyphs come from the Noto Sans families at weight 600; the wordmark uses an Arial Bold Italic metric equivalent.

## Keycap grid

| File | Size | Colours |
|---|---|---|
| `polykybd-tee-2g-keycap-grid.svg` | 280 × 168 mm | 1 (`#2f7bf6`) |
| `polykybd-tee-2g-wordmark.svg` | 79.6 × 15.8 mm | 1 |

The grid has 160 keycaps in 16 columns, each with a different glyph from 18 scripts. It has 24 Latin glyphs (accents, strokes, ligatures), 11 Arabic, 5 Cherokee, and 8 from each of the other 15 scripts. The glyphs were picked to carry no bad meaning when read alone, and no two look alike across scripts. The glyph is knocked out of the keycap, so the shirt colour shows through. The wordmark "PolyKybd" goes above the grid.

## POLY blocks

A 2 × 2 keycap block spelling POLY. Each file is 33.25 × 32 mm and uses one colour.

| File | Glyphs | Scripts |
|---|---|---|
| `polykybd-tee-poly-greek.svg` | ΠΟΛΥ | Greek |
| `polykybd-tee-poly-armenian.svg` | ՊՈԼԻ | Armenian |
| `polykybd-tee-poly-georgian.svg` | პოლი | Georgian |
| `polykybd-tee-poly-mix-2.svg` | पஒلኢ | Devanagari, Tamil, Arabic, Ethiopic |
| `polykybd-tee-poly-mix-3.svg` | ՊওలΥ | Armenian, Bengali, Telugu, Greek |
| `polykybd-tee-poly-mix-5.svg` | பኦลই | Tamil, Ethiopic, Thai, Bengali |

## Blue bursts

The same 160 keycaps, each glyph knocked out, arranged at many sizes. One colour (`#2f7bf6`), so these suit screen printing on a light or a black shirt.

| File | Size | Shape |
|---|---|---|
| `polykybd-tee-star-explosion.svg` | 300 × 300 mm | keycaps thrown outward from a bright core |
| `polykybd-tee-black-hole.svg` | 300 × 300 mm | keycaps spiralling into an empty centre |
| `polykybd-tee-oval-explosion.svg` | 300 × 300 mm | uneven oval burst |

## Colour bursts (for a black shirt)

The 160 keycaps plus several hundred filler keycaps, with depth shading: front keycaps are bigger and brighter. Tiny coloured sparkles follow the outline of the design, so the print shows no rectangular edge. Glyph tops point toward the centre. These need DTG or DTF printing, since each uses 35–39 fill colours.

| File | Size | Shape |
|---|---|---|
| `polykybd-tee-black-hole-colour.svg` | 300 × 300 mm | ring around an empty core |
| `polykybd-tee-oval-explosion-colour.svg` | 300 × 300 mm | uneven oval burst |
| `polykybd-tee-star-burst-colour.svg` | 300 × 300 mm | 8 major and 22 minor rays; keycaps start small, peak at 2/3 of each ray, then shrink |
| `polykybd-tee-star-burst-thin-rays-colour-rot30.svg` | 300 × 315 mm | the star burst plus 5 thin rays, turned 30° clockwise and not scaled |

The files have no background. To preview one as printed, open it on a black page.

## Regenerating

The generators are in `tools/`. They need Python 3 with `fonttools`, `skia-pathops` and `uharfbuzz`, plus `curl` and network access to Google Fonts. The wordmark also needs Liberation Sans Bold Italic (`fonts-liberation`), or pass another font path.

```bash
cd tools
python3 fetch_fonts.py                 # Noto Sans subsets for glyphs.txt into fonts/
python3 grid.py                        # polykybd-tee-2g-keycap-grid.svg
python3 wordmark.py                    # polykybd-tee-2g-wordmark.svg
python3 poly_single.py                 # greek, armenian, georgian (pass other names to build them)
python3 poly_mix.py                    # mix-2, mix-3, mix-5
python3 explosion.py; python3 blackhole.py; python3 oval.py        # blue bursts
python3 colour_designs.py black-hole
python3 colour_designs.py oval-explosion
python3 colour_designs.py star-burst
python3 colour_designs.py star-burst-thin-rays radial 30          # 30 = turn in degrees, clockwise
```

- Output goes to this folder. Set `TEE_OUT=<dir>` to write elsewhere.
- Set `TEE_PREVIEW=1` to also write a `-on-black` preview of each colour design.
- `glyphs.txt` holds the 160 grid glyphs, in grid order.
- The POLY scripts download their own font subsets into `tools/fonts_poly/`.
- Every design uses a fixed random seed. Run with the fonts fetched on 2026-09-30, each script reproduces its committed file byte for byte. A later Noto release can move outlines slightly.
- `colour_designs.py random` in place of `radial` gives random per-keycap rotation instead of glyph tops pointing at the centre.

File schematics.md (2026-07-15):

# PolyKybd Split72 — Schematic Sheets

These are the individual schematic sheets of the PolyKybd Split72 (KiCad, Rev 3.2), the same set that
is bundled in the PDF documentation. Repeated per-key and buffer sheets are shown once, since every
instance is identical. The editable source is in the KiCad projects
[`poly_kybd/poly_kybd_split72_left.kicad_pro`](poly_kybd/poly_kybd_split72_left.kicad_pro) /
[`poly_kybd/poly_kybd_split72_right.kicad_pro`](poly_kybd/poly_kybd_split72_right.kicad_pro).

## Left half — root sheet ("PolyKybd Split L")

Left half schematic

The top-level sheet of the left-hand board. It ties everything together: the 36 identical key units
(the "Display Adapter, LED & Switch" sub-sheet, one per key), the RP2040 microcontroller block, the
shift-register block, the display charge-pump supply (VSUP) with its current limiter, the USB-C link
between the two halves, and the optional peripherals — the Pimoroni trackball / Cirque trackpad
connector and the optional 0.96" OLED status display.

## Right half — root sheet ("PolyKybd Split72 R")

Right half schematic

The top-level sheet of the right-hand board. Structurally the same as the left half — it wires up its
36 key units, the shared control and power nets, and the non-inverting buffer blocks that sit along the
signal chain.

## RP2040 — microcontroller core ("rp2040 base circuit")

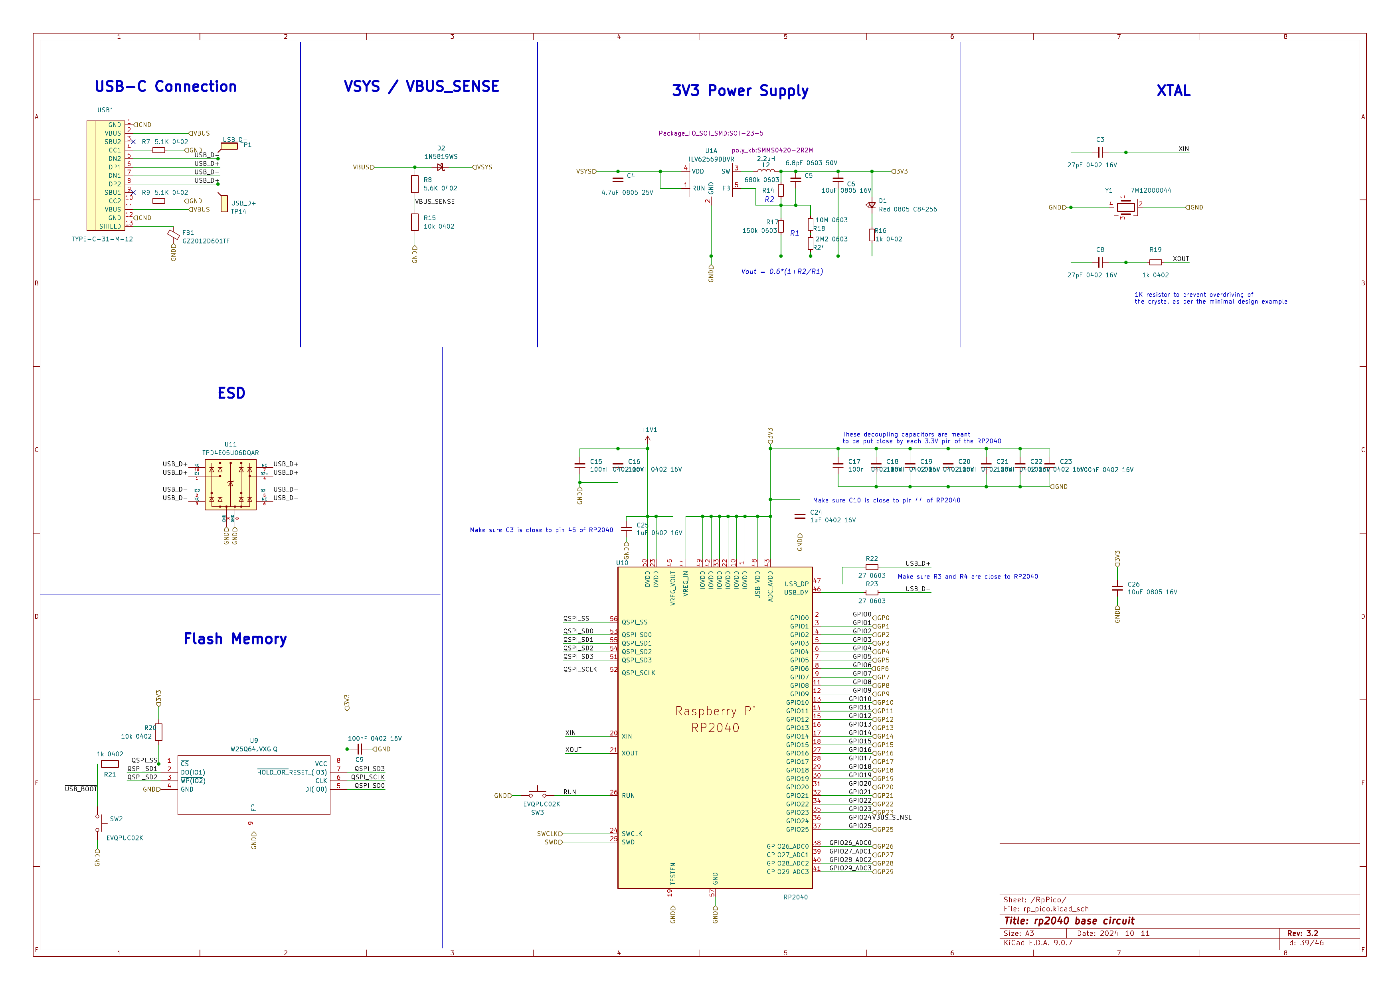
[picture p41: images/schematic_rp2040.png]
RP2040 schematic


The heart of the keyboard. It contains the Raspberry Pi RP2040 (U10) with its decoupling network, the
QSPI flash memory (W25Q64, U9) and BOOT button, the 12 MHz crystal (Y1), and the 3.3 V step-down
regulator (TLV62569, U1) with the SMMS0420 inductor. It also holds the USB-C connector (USB1) with its
ESD protection (TPD4E05, U11) and the VBUS-sense / VSYS network (including the 1N5819WS diode, D2) — so
all the power, USB, clock and boot circuitry lives here.

## Key block — one key unit ("Display Adapter, LED & Switch")

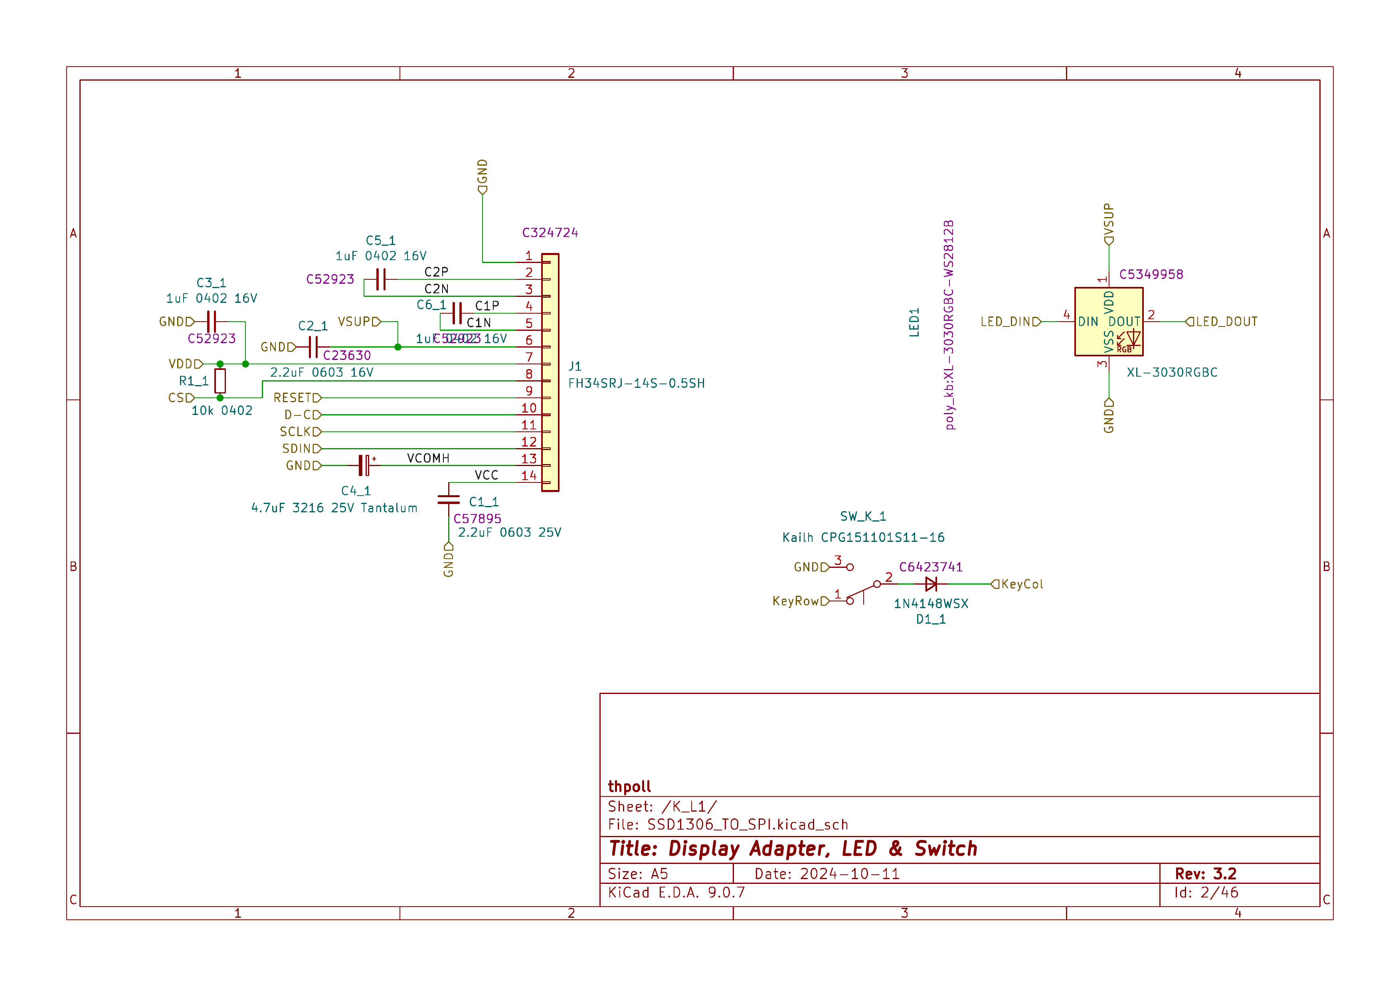
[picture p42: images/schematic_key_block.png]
Key block schematic


A single key unit, repeated 36× per side. It contains the FH34SRJ FPC socket for the 0.42" OLED display,
the addressable RGB LED (XL-3030RGBC / WS2812B), the MX-compatible Kailh hot-swap switch with its
1N4148 matrix diode, and the local decoupling capacitors — i.e. the display, LED and switch of one key.

## Shift registers ("Shift Registers")

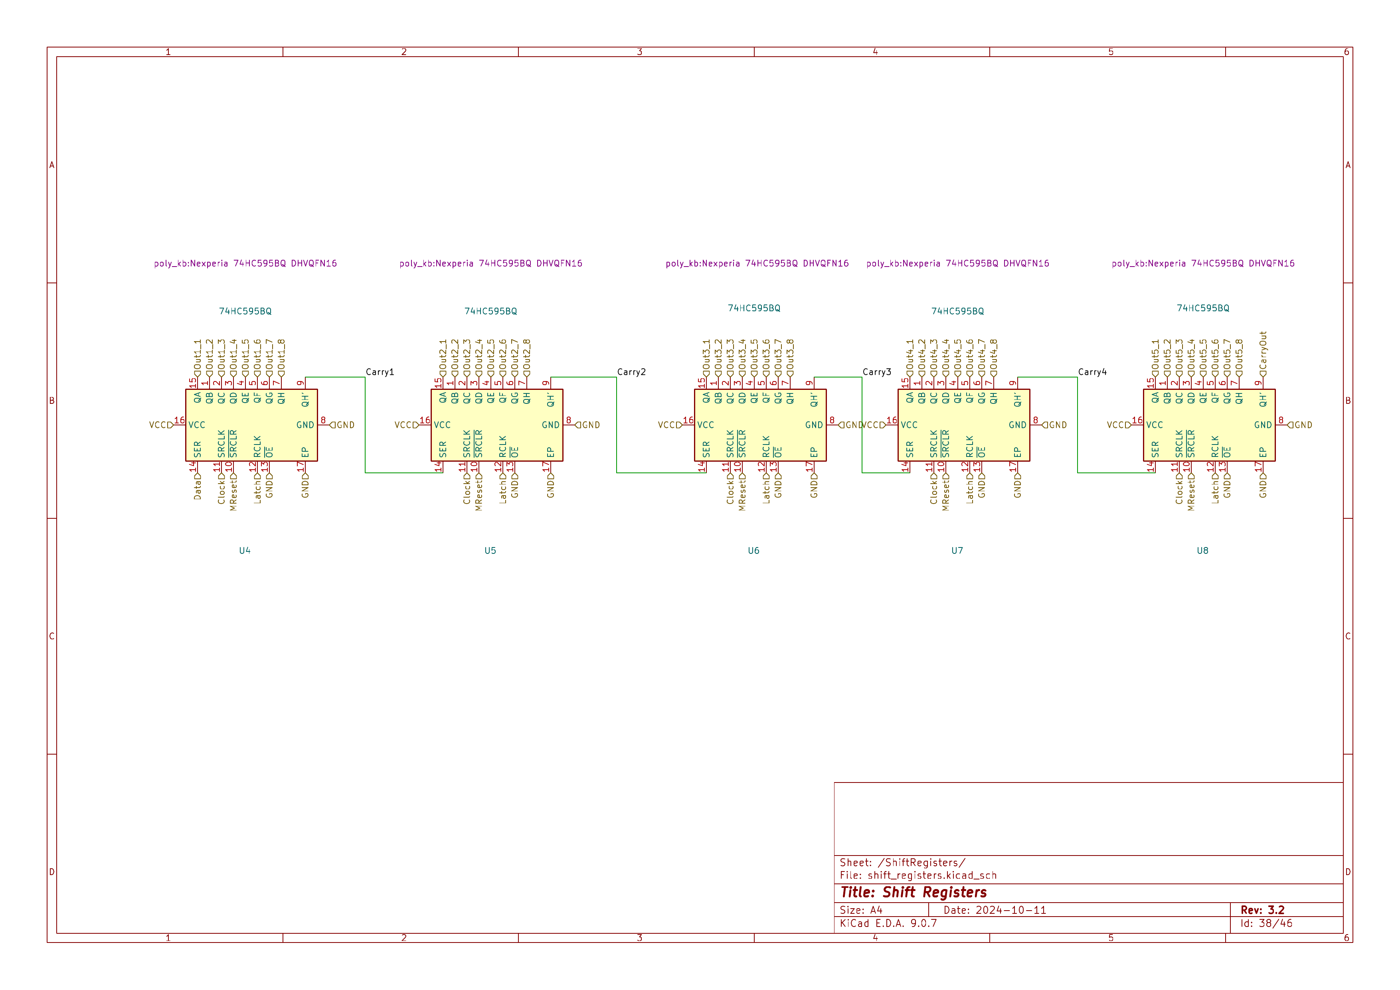
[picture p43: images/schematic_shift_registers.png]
Shift registers schematic


Five 74HC595 8-bit shift registers (U4–U8) daisy-chained together (each `QH'` feeds the next `SER` via
`Carry1`–`Carry4`), driven by the MCU's Data / Clock / Latch lines. They expand a handful of MCU pins
into 40 control outputs used to address the per-key hardware.

## Non-inverting buffer ("ni_buffer2")

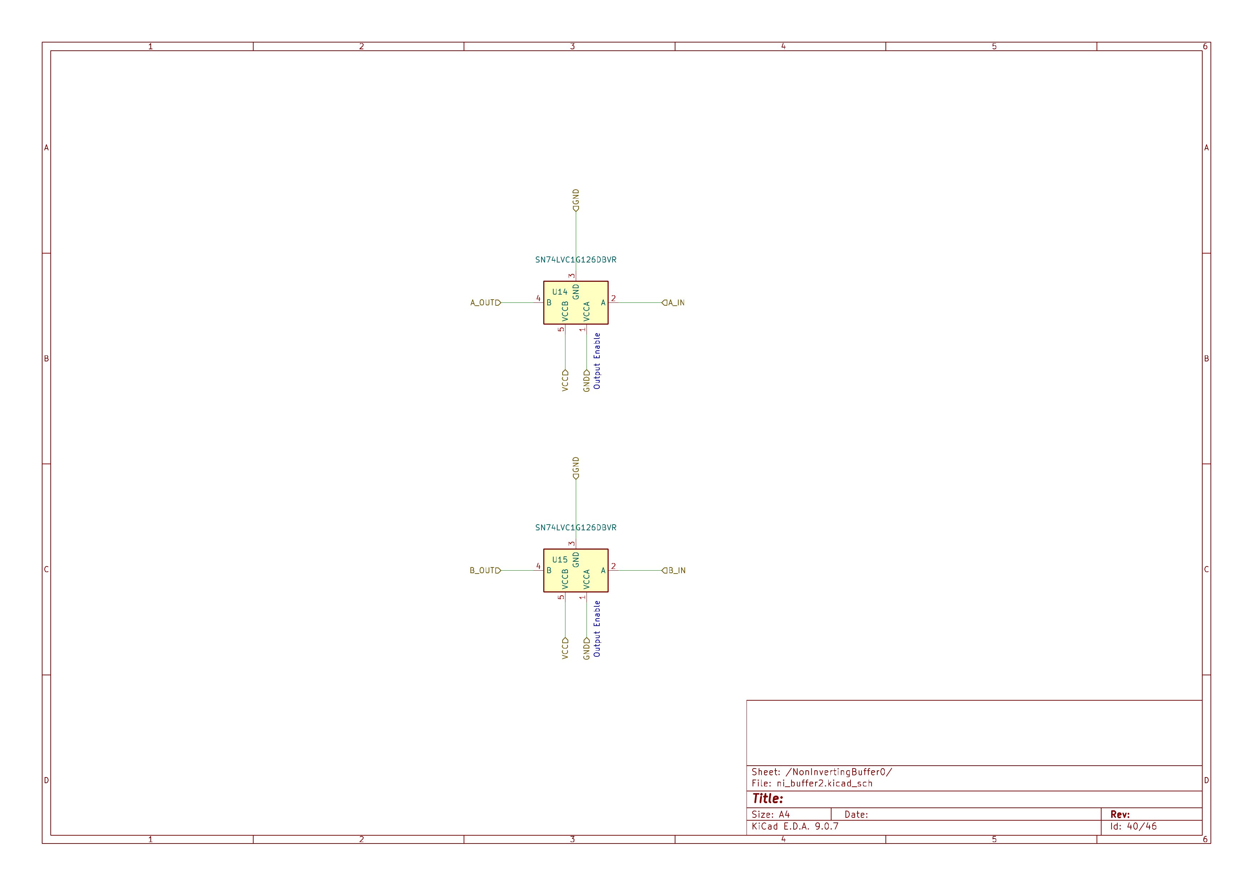
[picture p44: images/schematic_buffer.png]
Non-inverting buffer schematic


A pair of SN74LVC1G126 single non-inverting buffers with 3-state outputs and separate A/B supply rails
(U14, U15). This sheet is instantiated several times (NonInvertingBuffer0…5) to buffer and repeat the
control/data signals as they travel across the large key array, keeping the signal edges clean.

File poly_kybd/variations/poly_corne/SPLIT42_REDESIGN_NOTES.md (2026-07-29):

# split42 (poly_corne) — board redesign notes for the next revision

Collected 2026-07-17. Applies to `poly_corne_split42_left` v1.0 (the only fabbed
layout — **all boards in hand are the LEFT layout**). Note:
`poly_corne_split42_right.kicad_pcb` is a **byte-identical copy of
`poly_kybd_split72_right.kicad_pcb`** (an untouched stub — the split42 right side has
not been designed yet; that design work is item 0 below). Items 1 and 3 are confirmed
defects of v1.0-left; 2 and 4 are feature additions.

> **Re-validated 2026-07-29 against the board files on `master`.** All five points
> still stand — `git log` shows the `poly_corne` boards untouched since these notes
> were written, so nothing here has been addressed in the interim. What each claim
> now rests on:
>
> | item | status | evidence |
> |---|---|---|
> | right board is a split72 stub | **verified** | `cmp` says byte-identical to `poly_kybd_split72_right.kicad_pcb` |
> | 0 | valid | follows from the above |
> | 1 | valid, **relocated** — two pad pairs at U26 are not tied together; the connector is fine | corrected by the board author; see that section |
> | 2 | valid | `I2C_SDA`/`I2C_SCL` reach only `U10` (RP2040) and the pull-ups `R3`/`R4` — no header, no connector |
> | 3 | **verified geometrically** | see the section |
> | 4 | valid | no LTR-559 footprint on the board |

## 0. Design the split42 RIGHT board (currently a split72 stub)

`poly_corne_split42_right.kicad_pcb` still IS split72-right verbatim. When deriving
the real right board, apply items 1–4 from the start — especially item 1, since the
orphaned link pads were evidently introduced during the left board's rework of the
(correct) split72 layout, i.e. exactly the step about to be repeated for the right.

## 1. ESD array U26: two pairs of pads are not tied together (v1.0 defect — the split-link bug)

> **Corrected 2026-07-29 by the board author**, twice — get this right before the
> redesign, because the earlier readings put the defect in the wrong place.
>
> **The rule: two pairs of pads must ALWAYS be connected.** The USB-C connector
> itself is **fine** — footprint and wiring are correct. The break is at **U26**
> (TPD4E05U06DQA ESD array), where those two pairs are not joined.

Each link signal reaches **four** U26 pads (verified from the netlist, and identical
on split72-left):

| net | MCU | U26 pads | connector |
|---|---|---|---|
| `SERIAL_COM1` | `U10.6` | 1, 4, 7, 10 | `USB2.6` (A-row), `USB2.8` (B-row) |
| `SERIAL_COM2` | `U10.7` | 2, 5, 6, 9 | `USB2.5` (B-row), `USB2.7` (A-row) |

Four pads per signal is two flow-through channels — one per plug orientation. Both
have to be connected for the signal to survive a flipped plug.

**On v1.0-left only the INNER two pairs are connected.** The pads sit in two columns
0.77 mm apart at 0.5 mm pitch, so the facing pairs and their distance from the package
centre (pads 3/8, GND — not on the COM nets) are:

| y (mm) | left | right | pair | from centre | state |
|---|---|---|---|---|---|
| 105.58 | 1 | 10 | **1 ↔ 10** | 1.00 | ❌ **not connected** |
| 105.08 | 2 | 9 | 2 ↔ 9 | 0.50 | ✅ connected |
| 104.58 | *3* | *8* | — | 0 | GND, not on a COM net |
| 104.08 | 4 | 7 | 4 ↔ 7 | 0.50 | ✅ connected |
| 103.58 | 5 | 6 | **5 ↔ 6** | 1.00 | ❌ **not connected** |

That is exactly one missing pair per signal — `1↔10` on `SERIAL_COM1`, `5↔6` on
`SERIAL_COM2` — hence **two pairs**. (The original version of this note named the same
two pairs as "U26's internal flow-through metal": right pads, wrong conclusion. They
are not a substitute for board copper.)

**Consequence (unchanged, and matches the bench):** the flipped-orientation path never
completes, so the link comes up in exactly one plug orientation. Power is unaffected
(VBUS/GND are hard-wired), so both halves always powered normally. With both halves
being left boards — no right board was ever fabbed — each cable end carries that same
coin flip, so only **1 of 4** plug-orientation combinations links. This is the root
cause of the whole "split link dead / transport_fail=100%" saga; full record in
`qmk_firmware/keyboards/polykybd/split42/SPLIT42_LINK_STATUS.md`.

**Fix in the redesign:** connect **`1↔10` and `5↔6`** at U26 in board copper, matching
the inner pairs, so neither orientation depends on the chip being present or
well-soldered. Apply it to the right
board from the start (item 0) — the fault was evidently introduced when the left board
was reworked from the correct split72 layout, which is exactly the step about to be
repeated.

⚠️ **Confirm on the bench before cutting the redesign, not from the `.kicad_pcb`.** The
pairing above is the board author's account plus the footprint geometry; two
independent geometric checks *of the copper* were written against the layout file and
both were discarded for reporting the same fault on the known-good split72 board (the
trap documented in `.claude/skills/investigate-kicad-pcb`). Use the B.Cu gerber or a
meter. Evidence renders:
[`images/split42_left_gerber_4layers.png`](../../../images/split42_left_gerber_4layers.png),
[`images/split42_link_copper_comparison.png`](../../../images/split42_link_copper_comparison.png).

**Bench fix for existing v1.0 boards:** bodge `U26.1↔U26.10` and `U26.5↔U26.6` — on BOTH halves.

## 2. Break out I2C0 with a header for the status OLED

The 128×32 status OLED (SSD1306, I2C) runs on `I2C0` = **GP0/GP1** (400 kHz). Add a
proper header/breakout for it on the board so the display connects via a header
instead of whatever ad-hoc wiring v1.0 required.

## 3. Missing keycap-display FPC socket at SW_K_18 (v1.0 defect)

v1.0 left has **21 key sockets but only 20 display FPC sockets**
(`FH34SRJ14S05SH50` / Hirose FH34SRJ-5). The gap is at **`SW_K_18`** — 3rd finger
row, 4th key column (board pos x=130.81 mm, y=93.19 mm; the column below SW_K_4 /
SW_K_11). Add J18 (same footprint + placement pattern as the other 20: FPC socket
9.5 mm from the key center) and its display routing.

> **Verified geometrically 2026-07-29** — the board has 21 `SW_K_*` and 20 `FH34SRJ`
> sockets, and measuring each key centre to its nearest socket identifies the orphan
> without relying on reference numbers: every key but one has a socket at exactly
> **9.49 mm**, while `SW_K_18` (130.81, 93.19) has none nearer than **17.20 mm**
> (J25, which belongs to the thumb cluster). That confirms both the count and *which*
> key is affected.
>
> ⚠️ The original argument here — "J17 and J19 exist, so J18 was never placed" — is
> **not sound on its own**: J7, J14 and J21–J24 are also unplaced, and J25/J26/J27 are
> ordinary FPC sockets, so the reference numbering is simply sparse by design. The
> conclusion was right; the reasoning wasn't. Use the distance check above.

## 4. LTR-559 light+proximity sensor as a permanent part

The Pimoroni LTR-559 (ambient light + proximity, I2C addr `0x23`) has proven its
worth on split72 (auto-brightness + proximity wake) — place it permanently on the
split42 board. Notes:

- It lives on **I2C0** — same bus as the status OLED (item 2), no extra pins. No
  address conflict (SSD1306 is 0x3C/0x3D).
- Firmware support already exists and is **side-agnostic** (`base/ltr559.c`; the
  master pulls slave-side readings over `USER_SYNC_SLAVE_DATA`). It is a clean no-op
  when the part is absent (bounded probe retries), so it can be enabled
  unconditionally: once the hardware exists, add `-DPOLYKYBD_LTR559
  -DPOLYKYBD_LTR559_DRIVE` + `base/ltr559.c` to `split42/rules.mk` (mirroring
  split72).
- Mind the optics: the sensor needs a window/hole in the housing, and the proximity
  resting baseline is housing-dependent (split72 measured ~129 open bench vs ~325
  mounted) — re-check `LTR559_NEAR_THRESHOLD` for the split42 enclosure.

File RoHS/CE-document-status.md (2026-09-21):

# CE technical file — document status

Where every compiled document and certificate stands after the v3.3 part changes
(PRs #23, #24, #25, #26). Written 2026-08-07.

**Read `RoHS-decisions-log.md` first** — it records *why* each certificate was chosen.
This file records *what is still outstanding*.

---

## 1. Compiled documents — regenerated from source

| Document | State | Notes |
|---|---|---|
| `PolyKybd-Schematics.pdf` | ✅ **current** | Re-exported with kicad-cli 9.0 and re-composed. Verified: buffer sheet shows `74AHC1G125`, RP2040 sheet shows `W25Q64JVXGIM` |
| `PolyKybd-RoHS-Appendix.pdf` | ✅ **current** | Rebuilt 2026-09-04: **119 pages**, 26 sections, no missing documents. ⚠️ It had been stale since 2026-08-24 — the D2 evidence swap edited the `.xls` without rebuilding, so the shipped appendix still carried the superseded `ROHS3HOTTECH.pdf` instead of the 2025 Hottech CTI report. **Rebuild the appendix in the same change as any `.xls` edit.** |
| `schematics/*.pdf` (7 per-sheet) | ✅ **current** | Re-exported; page counts unchanged, so composition is like-for-like |
| `parts-to-pdf-reference.xls` | ✅ **current** | Source of truth. 44×8 preserved; every referenced certificate exists on disk. Last edited 2026-09-04 (R18 → Yageo AC `C227547`; `R3,R4,R7,R9` onto the AC datasheet; `R5,R6,R16,R19,R21` corrected to Vishay) |
| `schematics/parts.csv` | ✅ **current** | The technical file's BOM (per `CE-Technical-File-Checklist.md`) — **not** a generator input; no script reads it. Corrected 2026-09-04: R18 → C227547, and three rows that disagreed with the board (`R5,R6,R16,R19,R21` were listed as Yageo but are Vishay; `R10,R11,R30` and `D5` carried another part's datasheet URL) |

### Still stale

| Document | Blocked on | What is needed |
|---|---|---|
| ~~`PolyKybd-RoHS-Compliance-Matrix.xlsx`~~ | — | ✅ **done 2026-08-13.** See §2 |
| **`PolyKybd-PCB-Layers.pdf`** | ~~A6~~ — **now unblocked**, v3.3 gerbers exist | `pcb_render.py` reads gerbers from `RoHS/pcb/<side>`; copy the v3.3 sets there, render, then `pcb_merge.py`. Needs `cairosvg` + `gerbonara`; note `cairosvg` needs a native cairo DLL that is **not present on this Windows box** — `gerbonara` + Pillow rasterising works as an alternative |
| **`EU-Declaration-of-Conformity.docx`** | **GmbH registration** + EMC report | Every field is still a `[TO CONFIRM]` placeholder: DoC number, revision, manufacturer name, address, contact. Must name **PolyTasten GmbH**, not Thomas Pollak |

---

## 2. `PolyKybd-RoHS-Compliance-Matrix.xlsx` — ✅ corrected 2026-08-13

*Kept for the record; all of the below is now applied.*

Sheet **Compliance Matrix**:

| Ref | Currently says | Should say |
|---|---|---|
| C4_1–C4_36, C33, C34 | Sunlord · `sunlord-rohs.pdf` | **Vishay** · `vishay-rohs-20250901.pdf` |
| C5, C11 | Samsung blanket | unchanged, but see the traceability caveat in §3 |
| U4–U8 | Nexperia statement | unchanged ✓ |
| U9 | `W25Q64JVXGIQ` · winbond | **`W25Q64JVXGIM`** · **Winbond** (capital W) |
| U9 | *"RoHS 2011/65/EU as amended by (EU) 2015/863"* | ❌ **wrong** — the document actually cites **2002/95/EU**. See §3 |
| U12–U23, U?, U? | `SN74LVC1G126DBVR` · TI · `sn74lvc1g126.pdf` | **U12–U25** · `74AHC1G125GW,125` · **Nexperia** · Nexperia RoHS statement |

Sheet **Findings & Actions**:

- Row 3 *"RESOLVED — U12-U23 (SN74LVC1G126DBVR) re-pointed to sn74lvc1g126.pdf"* is now
  obsolete twice over: that file is deleted, and the part is Nexperia. Rewrite to record the
  re-point to the Nexperia statement, and mark the `U?,U?` housekeeping **closed** (now `U12-U25`).

There is no build script for this workbook — it is maintained by hand. `openpyxl` reads and
writes it (installed).

---

## 3. Certificate evidence — open questions

### a. Winbond flash — cites a superseded directive ⚠️

`winbond-W25Q64JV-rohs.png` is page 59 of the W25Q64JV datasheet; the RoHS claim is Note 2
under Absolute Maximum Ratings. Two separate points:

- **Coverage is fine.** The page is titled `W25Q64JV` — the family — so it covers the new
  `XGIM` exactly as it covered `XGIQ`. No new document needed for the part change.
- **The directive is wrong.** It cites **RoHS `2002/95/EU`**, superseded by 2011/65/EU and
  amended by (EU) 2015/863. The compliance matrix currently *claims* the modern directive,
  which the document does not support.

**Action:** request a current RoHS/green declaration from Winbond for the W25Q64JV family. If
none is forthcoming, correct the matrix to state what the evidence actually says rather than
overstating it.

### b. Samsung 6.8 pF — part no longer named in its own certificate

The manufacturer is unchanged, so the blanket *"all our MLCCs"* declaration (page 2) still
applies and **no new document is required**. But part-level traceability got weaker:

- The Product Lineup lists `CL10C6R8DB8NNN` (±0.5 pF, the **old** part) on **page 14** — which
  the current page selection `1,2,13,19,25` does not even include.
- The new `CL10C6R8CB8NNNC` (±0.25 pF) does **not appear anywhere** in the 84-page document.

**Action (choose one):**
1. Add page 14 to the selection and accept blanket-only coverage for the new part — putting
   C5/C11 in the same category as Silergy/SY6280AAC, which the decisions log already accepts.
2. Request a part-specific Samsung declaration for `CL10C6R8CB8NNNC`.

Option 1 is consistent with existing practice and costs nothing.

### c. GigaDevice — evidence staged, **not** wired into the technical file

The Winbond flash pre-order for v3.3 (`C5440778`) **failed**, so GigaDevice `GD25Q64EQIGR`
(`C3202817`) is under evaluation as the second source for U9. Its RoHS evidence has been
collected in advance and is held in `RoHS/`, but **is deliberately not referenced from
`parts-to-pdf-reference.xls` or the compliance matrix** — the part is not on the board.

| File | What it is |
|---|---|
| `gigadevice-rohs-declaration-webcapture-20260814.pdf` | **Capture of a public web page**, not a manufacturer-issued certificate. GigaDevice publishes its RoHS 2.0 Declaration as a web page only |
| `gigadevice-iso14001-2015.pdf` | Genuine signed certificate — reg. 50050943 UM15, valid 2023-09-21 → 2026-09-20 |

**Content is good, form is weak.** The declaration cites the current directives
(2011/65/EU + (EU) 2015/863) — unlike Winbond's, which cites the superseded 2002/95/EU — and
lists all ten substances at the correct limits. But it carries no date, revision or
signatory. Part-level linkage comes from the datasheet ordering table, which decodes suffix
`G` as "Pb Free + Halogen Free Green Package"; the part is `GD25Q64E`**`Q`**`I`**`G`**`R`.

**Open action:** request a dated, signed RoHS declaration from GigaDevice naming the part,
as was obtained for Vishay. Ask at the same time as the pre-order. The capture is interim
evidence and should be replaced if a signed document is issued.

Full sourcing analysis, including the boot2 compatibility constraint that governs which
flash can be used at all: `notes/flash-second-sourcing.md` in the **polykybd-costing** repo.

### d. JUSHUO connectors J1–J36 — coverage still unverified

Three JUSHUO RoHS PDFs are on file (`Jushuo_SZXEC24000437502/504/505`). They are **encrypted,
image-only scans with no text layer**, so it could not be confirmed whether they cover the
fitted part — including the gold plating. Note also that `parts.csv` lists J1–J36 as **JUSHUO**
while the board ships **Hirose** `C324724` (row 16 of the .xls points at the Hirose spec sheet).

**Action:** resolve the manufacturer discrepancy first, then confirm certificate coverage.

### e. Unreferenced certificates — confirm intent

Now unreferenced but **deliberately kept**, as they document what the built **v3.2** boards
shipped with:

- `sunlord-rohs.pdf`, `sunlord-rohs-en-translated.pdf` — superseded by Vishay for the tantalum
  (Sunlord is still live for FB1/FB2 via its own part-specific document)
- `2410010304_Texas-Instruments-SN74AHC1G125DCKR_C151890.pdf` — the old buffer

Carried over from the decisions log and still open: Aerosemi MT9700, Fenghua RC-02W and
Prosperity MCS0530 are referenced by no BOM line. Confirm whether they are alternates/DNPs or
should be linked.

**Uniroyal 0603WAF is no longer one of them** — answered 2026-09-04: evaluated as the `R18`
replacement and rejected (its datasheet carries no RoHS statement), so
`2206010216_UNI-ROYAL-…_C7250.pdf` stays unreferenced **deliberately**. See the decisions log.

**Deleted:** `sn74lvc1g126.pdf` — a datasheet for a part that was never fitted.

---

## 4. Housekeeping

- ~~**`.gitattributes` — mark PDFs binary.**~~ ✅ **done 2026-08-13.** A repo-root
  `.gitattributes` now marks PDFs, Office documents, images, 3D files and archives binary.
  Verified: `PolyKybd-Schematics.pdf` reports `Bin 37253660 -> 37253659 bytes` instead of
  ~1.35 M lines of text. KiCad sources stay text on purpose — a readable diff on them is what
  caught the property-only scope of the recent part swaps.
- **Tool dependencies.** The appendix tools need `xlrd`, `pypdf`, `reportlab`, `pdfplumber`,
  `Pillow`, and — for writing the .xls — `xlutils` and `xlwt`. `openpyxl` for the matrix.
  `pcb_render.py` additionally needs `cairosvg` and `gerbonara`, which are **not installed**.
  Worth a `requirements.txt` next to the tools.
- **Paths.** All six tools were made repo-relative in #26 (they carried a hardcoded
  `/sessions/bold-festive-carson/...` from a cloud session). `POLYKYBD_ROHS` overrides.

---

## 5. Order of operations

1. Correct the compliance matrix (§2) — **can be done now**
2. Decide the Samsung page selection (§3b) and re-run `update_xls_pages.py`, then
   `build_appendix.py`
3. Ask Winbond for a current declaration (§3a); correct the matrix either way
4. Resolve JUSHUO vs Hirose for J1–J36 (§3c)
5. **After A6** (v3.3 gerbers): `pcb_render.py` → `pcb_merge.py` → `PolyKybd-PCB-Layers.pdf`
6. **After the GmbH exists** and the EMC report is issued: fill in the DoC (§1)

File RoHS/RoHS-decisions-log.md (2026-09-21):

# PolyKybd — RoHS Documentation Decisions Log

Standard applied throughout: **Directive 2011/65/EU (RoHS) as amended by (EU) 2015/863.**
Last updated: 2026-09-04.

This file records the decisions made while assembling the RoHS evidence for the CE technical file,
so the results can be reviewed and reproduced.

## Files in `RoHS/`
- `parts-to-pdf-reference.xls` — BOM → certificate map. **Source of truth.** Columns:
  `Reference | Part | Datasheet Appendix (cert file) | Qty | Manufacturer | RoHS | (note) | Appendix Pages`.
- `PolyKybd-RoHS-Compliance-Matrix.xlsx` — reviewed status matrix (sheets: Compliance Matrix; Findings & Actions).
- `PolyKybd-RoHS-Appendix.pdf` — the compiled single-PDF appendix (title → parts reference → TOC → certificate sections).
- `appendix-tools/update_xls_pages.py` — recomputes the `Appendix Pages` selection and writes it into the .xls.
- `appendix-tools/build_appendix.py` — builds the appendix PDF, reading the page selection from the .xls.
- the individual certificate PDFs / PNGs (kept in full; the appendix uses excerpts only).

## Certificate reference fixes
1. **Filename mismatches corrected** in `parts-to-pdf-reference.xls`:
   - LED1–LED36 (XL-3030RGBC): `2301111010_…` → `2402181502_XINGLIGHT-XL-3030RGBC-WS2812B_C5349958.pdf` (date prefix).
   - U9 (W25Q64JV flash): `Winbond-W25Q64JV-rohs.png` → `winbond-W25Q64JV-rohs.png` (case).
2. **Re-points to better/correct evidence already on file:**
   - D5 (green 0805, C2297): was `KT-0805-B.pdf` (a **blue** LED spec) → `C2297.pdf` (KENTO 0805 green LED, RoHS stated).
   - U3 (SY6280AAC): was a Silergy **application note** → `ROHS-2024-SilergyCorp.pdf` (SGS RoHS test report, Jan 2024).
   - U12–U23 (SN74LVC1G126DBVR): was `…SN74AHC1G125DCKR…` (wrong part) → `sn74lvc1g126.pdf` (correct TI datasheet, RoHS stated).
   - J37 (FH34SRJ-12S): → `FH34SRJ-12S-0.5SH(99)_…_0000414526.pdf` (states "This product is RoHS compliant").
   - FB1, FB2 (GZ2012D601TF): → `2310301640_Sunlord-GZ2012D601TF_C1017.pdf` (part-specific Sunlord doc).

## Component-specific decisions
- **D2 (1N5819WS, SOD-323):** ✅ closed 2026-08-24 via
  **`ROHS-2025-HottechElectronics-CTI-A225024736310100101.pdf`** — a Centre Testing International
  (CTI) report dated 17 Apr 2025, RoHS 2011/65/EU + (EU) 2015/863, full 10-substance scope
  (Pb, Cd, Hg, Cr(VI), PBBs, PBDEs and the four phthalates DBP/BBP/DEHP/DIBP), IEC 62321 methods,
  **all results N.D. — PASS**. Its Model No. list reads `SOD-123/323/523/723`, so **SOD-323 is
  explicitly covered**.
  - ⚠️ **This supersedes the previous rationale, which was wrong.** D2 was earlier accepted via
    `ROHS3HOTTECH.pdf` "which includes 323-series package testing" — but that 2020 BST report's
    sample list is `SOT-23, 323, 523, 723, … SOD-123`, where the `323` belongs to the **SOT** run.
    Its SOD coverage stops at **SOD-123**, and the report states its results "refer only to the
    sample(s) tested". D2 is SOD-323, so the package was never actually covered. `parts.csv` had
    recorded D2 as `x Email sent` throughout, which was the accurate status.
  - ✅ **DECIDED 2026-09-02 — Shenzhen and Guangdong Hottech are treated as ONE entity.** The
    applicant on the report is **Shenzhen Hottech Electronics**, while LCSC (and JLC's matched
    part on the v3.3 assembly order) lists the manufacturer as *Guangdong* Hottech. The report
    carries a remark that the two are "Group-subsidiary relations"; that linkage is **according
    to the client's statement**, not something CTI verified, but it is accepted here as
    sufficient — same group, same product line. This is a **stated position, not an open
    question**: do not re-raise it as a gap.
    - **Source of the linkage, in full:** the remark is carried *inside the report itself* —
      `ROHS-2025-HottechElectronics-CTI-A225024736310100101.pdf` (CTI report no.
      A225024736310100101, 17 Apr 2025), held in `RoHS/`. ⚠️ **There is no separate
      client-statement document on file**, and none is expected: the "client's statement"
      is CTI's own attribution for that line in the report, not a record issued to us. So
      the report is the entire traceable source for this decision — do not go looking for a
      second one.
    - **If it is ever challenged** and a firmer basis is wanted, the cheap ask is written
      confirmation from Hottech that the two are the same legal entity or a declared group,
      which converts a client statement into supplier correspondence.
  - ⚠️ **Two limitations remain, as disclosures rather than decisions** — both are inherent to
    the report and normal for an SMD part, but state them if the file is challenged: the sample
    was **tested as a whole** (not separated into homogeneous materials — the report says so
    explicitly, and RoHS limits formally apply per homogeneous material); and it is a
    **package-family report** (`SOD-123/323/523/723`), not MPN-specific to `1N5819WS`.
  - **Consequence:** no part change needed. The PAKER `B5819WS` / `C5278927` alternative
    (`2401041156_PAKER-B5819WS_C5278927.pdf`, SOD-323, "Halogen free and RoHS compliant") is no
    longer required — and is the weaker option anyway: 2,250 in stock against Hottech's 5.6M, and
    a 9A surge rating against 25A.
- **Connectors J1–J36 / J37 / J39:** each references the Hirose spec sheet for its own part number,
  all stating RoHS compliance. J1–J36 = FH34SRJ-14S, J37 = FH34SRJ-12S, J39 = FH12-30S. The trailing
  `(50)`/`(99)` in the filenames is the **packaging quantity**, not a spec revision — so the
  part-matching sheet is correct regardless of that number. J1–J36 kept on the 14S sheet (no 14S(99)
  exists; not needed).
- **U12–U23 (SN74LVC1G126):** the designator/qty count reflects **two buffers per package**; not an error.
- **FB1/FB2:** now on the part-specific Sunlord document (was the generic company-wide DoC, which was
  also valid).
- **Scoped out (no separate certificate):** pin headers are **not populated**; mounting holes and test
  points are **bare PCB copper**, covered by the PCB substrate RoHS evidence.
- **Bare PCB:** `rohs-certificate-of-conformity.pdf` (JLCPCB DoC, Soar Testing 2025, ENIG + lead-free HASL).

## Appendix assembly rules
- **One section per certificate**, ordered by first appearance in the BOM; each section starts with a
  headline/divider page (manufacturer + a table of the designators/parts/qty it covers + the filename).
- **Table of contents** enumerates *every* part per section (no truncation; wraps across lines) with the
  section's page number.
- **Page trimming** (to keep the PDF manageable): the `Appendix Pages` column in the .xls controls which
  pages of each certificate are included.
  - `all` — include the whole document (used for short docs ≤3 pages and image-only scans that can't be
    text-analysed, e.g. `2310301640_Sunlord-GZ2012D601TF_C1017.pdf`).
  - `image` — a PNG certificate, rendered as one full page.
  - a page list (e.g. `1,2,13,19,25`) — those pages only. Auto-selection keeps page 1 (identity) plus the
    RoHS-relevant pages and a ±1-page neighbour for context. Trimmed sections state the kept pages on the
    divider and note the full document is retained in the repo.
- **Page size:** every page of every output PDF is normalised to **A4 portrait**. Certificate pages
  of other sizes (Letter, etc.) are scaled to fit and centred; landscape pages (and the schematic
  sheets) are rotated 90° so they read by turning the page clockwise (title block bottom-right).
- **Samsung MLCC (`…CL05A105KA5NQNC_C52923.pdf`):** this is a blanket "all our MLCCs" RoHS declaration
  (page 2) that does not name individual capacitances. To show the actual parts, the selection also
  includes the manufacturer's **Product Lineup** pages: `1,2,13,19,25` — page 19 lists the exact part
  `CL05A105KA5NQNC`; pages 13 (C0G) and 25 (X7R) cover the other used dielectrics. Part→certificate
  traceability is additionally provided by the reference table and the section divider.

## Part-reference verification (of trimmed certificates)
Each trimmed certificate was checked to confirm the specific part number appears on a **kept** page:
- Present on a kept page: NationStar NCD0805R1, C2297 (green LED), KENTO KT-0805Y, SXN SMMS0420-2R2M,
  XINGLIGHT XL-3030RGBC, Yageo RC0603, Kailh CPG151101S11-16, MSKSEMI TPD4E05U06DQAR, TI SN74LVC1G126,
  TXC 7M12000044, Samsung CL05A105 (page 19).
- **Blanket reports that do not name the part anywhere** (linkage via the reference table + divider):
  - Samsung `…CL05A105…` — addressed by adding Product Lineup pages (see above).
  - **Silergy `ROHS-2024-SilergyCorp.pdf`** — SGS report certifying Silergy's package families generally
    (coverage list includes "SOT", i.e. SY6280AAC's package). The part number SY6280 does not appear in the
    document, so no part-specific page can be added; U3 → SY6280AAC linkage is via the reference table/divider.

## v3.3 part changes — 2026-08-07

Five parts were retargeted because the ordered ones went **EOL at JLCPCB** ("no longer
manufactured", 0 stock). Certificate consequences:

| Ref | Was | Now | Certificate |
|---|---|---|---|
| C4_1-C4_36, C33, C34 | Sunlord `C118249` | **Vishay** 293D475X9025A2TE3 `C5380411` | **changed** → `vishay-rohs-20250901.pdf` |
| C5, C11 | Samsung `C170128` | Samsung CL10C6R8CB8NNNC `C318672` | unchanged — same blanket declaration |
| U4-U8 | Nexperia `C3303719` | Nexperia 74HC595BQ,115 `C730243` | unchanged — same MPN, same statement |
| U9 | Winbond `C2940195` XGIQ | Winbond W25Q64JVXGIM `C5440778` | unchanged — family-level evidence |
| U12-U25 | TI SN74LVC1G126DBVR | **Nexperia** 74AHC1G125GW,125 `C85397` | **changed** → Nexperia statement |

### New evidence
- **`vishay-rohs-20250901.pdf`** — Vishay ROHS Compliance Statement, 1 September 2025, signed by
  Roy Shoshani (COO Semiconductors / CTO). Header cites *"Directives 2002/95/EG, 2011/65/EU,
  2015/863/EU (RoHS I – III)"*. Company-wide: certifies that all products *identified as
  RoHS-compliant* meet those directives. Our part is `293D475X9025A2TE3` — the **`E3` termination
  suffix is Vishay's lead-free code**, and the 293D datasheet states "Terminations: 100 % matte tin
  standard" and warns that parts with lead (Pb) terminations are *not* RoHS-compliant. Source:
  `vishay.com/doc?49157`. One page, so `Appendix Pages = all`.
- **`nexperia-74AHC1G125-datasheet.pdf`** — Nexperia 74AHC1G125/74AHCT1G125 data sheet, Rev 15.1,
  28 August 2024. Supporting documentation for the new buffer; not itself the RoHS evidence.

### U12–U25 buffer — re-pointed to the Nexperia statement
The fitted part is now Nexperia `74AHC1G125GW,125` (SOT-353), so the TI datasheet no longer
applies. The existing **`Nexperia - Statement on RoHS 20241008.pdf`** covers it: it is company-wide
across all Nexperia semiconductor products and cites the correct directives.

**Checked the exemption appendix (page 3):** it lists 37 packages that exceed the 0.1 % lead limit
and rely on RoHS exemptions 7(a) / 7(c)-I. **Neither SOT-353 (U12–U25) nor DHVQFN-16 (U4–U8) is on
that list**, so both Nexperia parts are compliant outright, with no exemption claimed. Rows 37 and
41 now share one certificate and therefore one appendix section.

The reference also fixes the old `U12-U23,U?,U?` designator string → **`U12-U25`**, closing the
housekeeping item below. Qty stays 14 (one buffer per package; the earlier "two per package" note
was based on the wrong part).

- `sn74lvc1g126.pdf` **deleted** — datasheet for a part that was never fitted.
- `sunlord-rohs.pdf` / `sunlord-rohs-en-translated.pdf` and
  `2410010304_Texas-Instruments-SN74AHC1G125DCKR_C151890.pdf` are now unreferenced but **kept**:
  they document what the built **v3.2** boards actually shipped with.

### Samsung 6.8 pF — traceability note
The manufacturer is unchanged, so the blanket "all our MLCCs" declaration (page 2) still applies
and no new document is needed. But part-level traceability is now weaker, and the page selection
is stale:
- The Product Lineup lists `CL10C6R8**D**B8NNN` (±0.5 pF, the **old** part) on **page 14** — which
  the current selection `1,2,13,19,25` does not even include.
- The new `CL10C6R8**C**B8NNNC` (±0.25 pF) does **not appear anywhere** in the document.

So C5/C11 now sit in the same category as Silergy below: covered by a blanket report that does not
name the part, with linkage via the reference table and section divider. Consider adding page 14.

### Winbond flash — directive version caveat
`winbond-W25Q64JV-rohs.png` is page 59 of the W25Q64JV datasheet; the RoHS claim is Note 2 under
Absolute Maximum Ratings. It is titled **W25Q64JV** (the family), so it covers `XGIM` exactly as it
covered `XGIQ` — no new document needed. **However it cites RoHS `2002/95/EU`**, the superseded
directive, not 2011/65/EU + 2015/863. Worth requesting a current Winbond declaration before the
technical file is finalised.

## Resistor evidence — 2026-09-04

Three resistor rows changed. One is a real part substitution; two were bookkeeping errors
found while verifying the first against the board files.

### `R18` 10 MΩ 0603 — substituted, Yageo RC → Yageo AC

`RC0603JR-0710ML` / `C141675` went out of stock at JLC. Replacement is
**`AC0603FR-0710ML` / `C227547`** — same manufacturer, same 10 MΩ 0603 value, ±1% instead of
±5%, AEC-Q200 automotive grade. The AC series was **already on this board** (`R3,R4,R7,R9`),
so it introduces no new supplier and no new document family. Tolerance moves the right way;
nothing in the circuit needs 5%. Evidence: `50630577_YAGEO-AC0603FR-0710ML_C227547.pdf`
(LCSC's datasheet for `C227547` — the committed file was verified byte-identical, MD5
`4902f1493da835c32ecc47a868267c75`, against LCSC's own CDN copy). Cover page carries
*"RoHS compliant & Halogen free"*; FEATURES declares *"Products with lead-free terminations
meet RoHS requirements – Pb-glass contained in electrodes, resistor element and glass are
exempted by RoHS"* — i.e. compliance by exemption 7(c)-I, the normal position for a thick-film
chip resistor. The 0603 range is `10Ω ≤ R ≤ 10MΩ` at ±1%, so 10 MΩ is the top of the range and
is covered.

⚠️ **Uni-Royal `0603WAF1005T5E` / `C7250` was considered first and rejected on evidence, not on
the part.** It is an ordinary 10 MΩ 0603 and there is plenty of stock, but its datasheet
(`2206010216_UNI-ROYAL-…_C7250.pdf`, already in `RoHS/` and until now orphaned) carries **no RoHS
statement at all**, and the LCSC compliance page for it is an **SGS exemption declaration** that
cites a test report (`CAN23-0123161`) we do not hold. Choosing it would have meant adding a
supplier *and* chasing a third-party report, to replace a part whose own manufacturer already has
a covering document. That orphaned datasheet can now be described as **evaluated and not used**
rather than merely unreferenced.

### `R3,R4,R7,R9` 5.1 kΩ 0402 — citation corrected, no part change

These are `AC0402FR-075K1L` / `C144745`, i.e. **AC** series, but were cited against the **RC**
document. Both are Yageo series-wide datasheets, so the error was invisible in practice — an
auditor comparing the MPN to the document would have caught it. Re-pointed at the AC datasheet.
Checked the rest: of the twelve distinct resistor parts on the board, **only these two rows are
AC series**; every other Yageo resistor is genuinely RC and its citation stands.

### `R5,R6,R16,R19,R21` 1 kΩ 0402 — manufacturer corrected, no part change

The table said Yageo `C144789`. The board has always carried **Vishay `CRCW04021K00FKED` /
`C71623`** (verified in both split72 board files). Re-pointed at `vishay-rohs-20250901.pdf`,
which was already in `RoHS/` for the tantalums and is a **company-wide** statement — Vishay
*"hereby certifies that all its products that are identified as RoHS compliant satisfy the
requirements of the above-listed directives"* — so it covers the CRCW part with no new document.
This was a bookkeeping error only: the part fitted never changed.

### Two more found while verifying: LCSC codes on `R10,R11,R30` and `D5`

Cross-checking every row's `LCSC` cell against the board files turned up two stale codes. Both
are **cell corrections only** — the part fitted and the evidence document are unaffected in both
cases — but a compliance table whose part numbers disagree with the board is exactly what an
auditor spot-checks.

- **`R10,R11,R30`** (390 kΩ) carried `C114659`, which is **`R13`'s 12 kΩ part**. The board says
  `C137735`. The likely origin is board-side: that footprint's `Datasheet` property *also* points
  at the 12 kΩ datasheet, so the wrong code was copied forward into the table.
- **`D5`** (green 0805) carried `C2293`. The board, both v3.3 BOM exports and the part's own
  `Value` string (`Green 0805 C2297`) all say **`C2297`**, and the evidence file is `C2297.pdf` —
  a Hubei KENTO approval spec for an 0805 翠绿 (green) LED, which carries no LCSC code itself, so
  the filename is the only link. Corrected to `C2297`.

The check is worth keeping: parse `(property "Reference" …)` out of a board file, pair each
designator with its `LCSC`/`Manufacturer` properties, and compare against the table's first
designator per row. Three of 43 rows were wrong (`R5,R6,R16,R19,R21`, `R10,R11,R30`, `D5`); the
other 40 matched exactly, and all 43 do now.

### `schematics/parts.csv` carried the same three errors — fixed

Raised in review on PR #39, and correct: `parts.csv` still named **Yageo** with an
`AC0402FR-071KL_C144789` datasheet for the Vishay 1 kΩ parts, the **12 kΩ** datasheet for the
390 kΩ parts, and a `C2293` URL for `D5`. All three rows now match the board; each replacement URL
was checked to resolve
to the right part first — `C137735` → `RC0603FR-07390KL`, `C2297` → `KT-0805G`, and the Vishay
row takes the board's own `vishay.com/docs/20035/dcrcwe3.pdf`.

⚠️ **The finding's stated consequence was wrong, and the real one is worse.** It was raised as
*"`parts.csv` feeds `build_schematics.py`, so generated schematic documentation continues to
disagree"* — but `build_schematics.py` only composes exported schematic PDFs, and **no script in
this repo reads `parts.csv` at all**. It is not a generator input: `CE-Technical-File-Checklist.md`
names it as **the bill of materials of the technical file**, alongside the `.xls`. So a wrong
manufacturer on five fitted resistors sat in the BOM that goes to a notified body, where nothing
downstream would ever have overwritten it — a worse place for it than a regenerable PDF. Take the
conclusion, not the mechanism; and note this file repeated the mechanism once before checking it.

⚠️ **Root cause: a part swap updates `LCSC`/`JLC`/`MPN` on the footprint but leaves the
`Datasheet` property pointing at the old part.** Those three fields are what the fab exporter
reads, so nothing complains, and the stale URL then propagates into anything derived from the
board. It is not a one-off — a board-vs-`parts.csv` sweep finds the same shape on **`C3,C8`**,
where the 2026-08 Samsung switch to `C86287` left the footprint's `Datasheet` on the superseded
`CL10A225KO8NNNC_C23630` — and it is where the `D5` and 390 kΩ errors in this table came from.

**Not fixed here.** Correcting the footprints means editing the `Datasheet` property across
**8 files** — split72 pcb+sch and split42 pcb+sch, left and right — for a cosmetic field no
exporter reads, on a variant that is not being fabricated. That is a sweep of its own, not part
of an R18 substitution. Worth doing before the next `parts.csv` regeneration, because
regenerating from the boards as they stand would put all three errors straight back.

**The check**, which is cheap and catches the whole class: parse `(property "Reference" …)` out
of a board file, pair each designator with its `Manufacturer`/`Datasheet`/`LCSC` properties, and
compare against the first designator of each `parts.csv` row. 51 rows checked; besides the three
fixed above it leaves `C3,C8` (the stale board URL described above), `D2` (*"Hottech Semi"* vs
*"Hottech"*, cosmetic) and `J37` (the board joins two URLs with `;`, the csv keeps the first —
not an error).

### ⚠️ The appendix was stale, and this is a recurring trap

Rebuilding `PolyKybd-RoHS-Appendix.pdf` for the above revealed it had been stale since
**2026-08-24**: the D2 evidence swap edited the `.xls` but did not rebuild, so the appendix
shipped in the technical file still carried the **superseded `ROHS3HOTTECH.pdf`** — the very
document that section of this log explains does *not* cover SOD-323 — instead of the 2025 Hottech
CTI report. Rebuilding from the pre-change `.xls` with the current tooling gives 115 pages against
the committed 113, which is how the drift was measured; this change then takes it to 119 (one new
section: cover + 3 kept pages of the AC datasheet).

**Rule: an edit to `parts-to-pdf-reference.xls` is not finished until both tools have been re-run
and the rebuilt appendix is committed in the same change.** Nothing checks this, and the appendix
is a binary that reviews as an opaque blob, so a stale one is invisible.

⚠️ **But `update_xls_pages.py` recomputes EVERY row, so running it silently destroys the
hand-curated page selections** — and those are the whole reason the column is editable. It did
here: the Samsung MLCC rows carry `1,2,13,19,25`, chosen by hand to land on the pages of an
84-page part list that actually name our parts, and the tool overwrote them with its automatic
`1,2,3,59,60,61`. `D2` was overwritten from `all` to `1,2,3,4,5,6,7`, dropping a page of the CTI
report. Neither shows up as an error; both would just have quietly changed what the technical
file contains. **After running it, diff the `Appendix Pages` column against the committed `.xls`
and restore every row you did not intend to change** — the curated values are recognisable
because the tool cannot produce them (it only ever emits `all`, `image`, or `1` plus each keyword
hit ±1). This change touched three rows and restored the other nine.

## Reproduce
From `RoHS/`:
1. `python3 appendix-tools/update_xls_pages.py` — (re)writes the `Appendix Pages` column from the certs.
   Edit that column by hand to include more/fewer pages for any certificate. ⚠️ It rewrites **all**
   rows, so it clobbers earlier hand edits — diff the column against the committed `.xls` afterwards
   and restore the rows you did not mean to touch (see the 2026-09-04 entry).
2. `python3 appendix-tools/build_appendix.py` — rebuilds `PolyKybd-RoHS-Appendix.pdf` from the .xls.
   Requires `xlrd`, `pypdf`, `reportlab`, `pdfplumber`, `Pillow`.

## Open housekeeping (not compliance blockers)
- ~~The BOM row for U12–U23 still contains two unnamed designators (`U?,U?`)~~ — **resolved
  2026-08-07**, now `U12-U25`.
- ~~`PolyKybd-RoHS-Appendix.pdf` and `PolyKybd-Schematics.pdf` are stale~~ — **both regenerated
  2026-08-07** from the v3.3 sources.
- ~~Both appendix tools carry a hardcoded sandbox path~~ — **fixed 2026-08-07**; all six tools now
  resolve paths relative to the checkout, overridable with `POLYKYBD_ROHS`.
- Some certificates in `RoHS/` are referenced by no BOM line (Aerosemi MT9700, Fenghua RC-02W,
  Prosperity MCS0530, ~~Uniroyal 0603WAF~~); confirm whether they are alternates/DNPs or should be
  linked. The **Uniroyal `0603WAF1005T5E`** one is answered as of 2026-09-04: evaluated as the
  `R18` replacement and **rejected** (no RoHS statement in the datasheet), so it stays unreferenced
  deliberately. Since 2026-08-07 this also covers `sunlord-rohs.pdf` and the TI buffer datasheet, which
  are **deliberately** kept as the record of what the built v3.2 boards shipped with.

**→ See `CE-document-status.md`** for the full state of every compiled document and the remaining
certificate questions (compliance matrix, PCB layers, Declaration of Conformity, the Winbond
directive version, the Samsung page selection, and JUSHUO vs Hirose on J1–J36).

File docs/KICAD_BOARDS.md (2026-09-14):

# KiCad boards — reading them, and what misleads

Extracted from `CLAUDE.md` 2026-09-14. The prose is unchanged; only heading levels
and relative links were adjusted to suit a standalone file.

## KiCad boards (`poly_kybd/`)

The `investigate-kicad-pcb` skill is the entry point for reading a board with Python —
it carries the tool choices and the geometry pitfalls. What follows is board-level fact
that outlives any one investigation.

- ⚠️ **`*.kicad_sch` is authoritative. `poly_kb.net`, `poly_kb.xml` and the KiCad-5
  `.sch` files are NOT.** Those are generated artifacts last touched **2024-02-17**
  and they describe a design **two board revisions old** — they still name the LED as
  `WS2812B-Mini` / `C527089`, which the BOM history shows was replaced by
  `XL-3030RGBC` / `C5349958` between v3 and v3.2. Nothing labels them stale, so they
  read as current: an AI reviewer read one in 2026-08 and filed a confident finding
  that the live LED was the 2024 part. Either regenerate them or delete them; until
  then, treat any answer sourced from them as two revisions out of date.

- ⚠️ **Grep for the PART, not the reference designator.** Symbol *instances* store only
  `reference` and `unit`; `Value`, `Footprint` and `MPN` are **symbol-level**, shared by
  every instance of a hierarchical sheet. So `grep '"U24"' *.kicad_sch` finds nothing
  while `U24` sits happily on the board — it is one of 14 instances of
  `ni_buffer2.kicad_sch` (2 symbols → 28 SOT-353 buffers). This produced a false
  "orphan footprints declared by no schematic" alarm in 2026-08, and it is the **same
  mistake shape** as the `Nexperia595` one already recorded in
  `PolyKybdHost/CLAUDE.md` — searching a designator instead of the thing itself. Once
  was evidently not enough; search by value, `lib_id`, or footprint name.

- **`MPN` here usually holds an LCSC CATALOG ID, not a manufacturer part number — that is
  the convention, not a defect.** 39 of the 46 `MPN` properties in `rp_pico.kicad_sch` are
  `C\d+` values identical to the part's own `LCSC` property; only five carry a real part
  number, and the true manufacturer p/n normally lives in `Value` (e.g. `USB1` is
  `MPN C165948` / `Value TYPE-C-31-M-12`). An AI reviewer flagged this as a fault introduced
  by a PR that had only changed that symbol's `Footprint` (2026-08). Before filing it as a
  finding, check whether the symbol's MPN differs from the merge base at all — and note the
  fix, if one is ever wanted, is a board-wide sweep of ~39 symbols, not a one-part edit.

- **A shared sheet cannot vary a part per board.** All four boards include
  `rp_pico.kicad_sch`, so a `Value`/`Footprint` change to U9 lands on split72 *and*
  split42 whether you want it or not. There is no per-instance override. If a variant
  genuinely needs a different part, extract just that part into its own small
  sub-sheet and fork **that** — forking `rp_pico.kicad_sch` duplicates 45 unrelated
  symbols (46 placed symbols, 14.5k lines) to vary one, and they will drift.

- ⚠️ **The JLC fab exporter builds the BOM from the BOARD's footprint properties, not the
  schematic — and *Update PCB from Schematic* does not refresh them by default.** So a
  correct schematic still exports a wrong BOM: after the U9 flash swap the `LCSC Part #`
  column (the only column JLC orders from) still named the superseded Winbond
  `C5440778` while the footprint and `Value` were the new Boya part — a DFN 4x4 ordered
  onto an LGA-8 land. Sweep board-vs-schematic `MPN`/`LCSC`/`JLC`/`Manufacturer` after
  every export. ⚠️ Also: the **36 hot-swap sockets sit on `F.Cu` in the board but mount
  physically on the BOTTOM**, so every CPL export writes `top` for them and has to be
  flipped by hand; the as-fabricated v3.2 CPL is the reference to diff against. Full
  detail, plus the per-part decisions and the open D2 RoHS row, in
  `poly_kybd/Gerber/PCB/FABRICATION-NOTES.md` — read it before re-exporting.

- **A footprint the boards use but no library provides gets EXTRACTED from the board, not
  hunted upstream.** Three now live in `poly_kb.pretty` this way: the USB-C connector
  (`HRO-TYPE-C-31-M-12-Assembly`, upstream `EnvUSB` absent), `RP2040-QFN-56` (upstream
  `keebio` absent) and `CP_EIA-3216-18_Kemet-A` — the last for a different reason worth
  remembering: **the stock KiCad tantalum footprint has since grown ~0.05 mm**, enough to
  produce clearance violations against routing already on the boards, so the as-built copy
  is kept deliberately and must not be "updated" from the stock library without re-running
  DRC. All three stay on **B.Cu**: every instance of each, on every board, is bottom-mounted,
  so there is no front-side instance to copy and converting would need a front/back mirror
  with nothing to verify against. The mechanics (local x,y but absolute pad angles, which
  instance junk to strip, and comparing pad layers as a set) are in the
  `investigate-kicad-pcb` skill.

- **Land-pattern changes: the target is solder THICKNESS, not solder volume.** When
  extending a pad (e.g. the LED toe, 0.9 → 1.25 mm in 2026-08), **paste must scale
  with the copper** to hold the same ~0.050 mm³ of solder per mm² of pad. Insetting the
  paste to "limit added solder" spreads roughly the same solder over more copper and
  yields a joint **thinner than the one you started with** — the opposite of the
  intent. A long *bare* copper toe with paste held well back is worse still: bare
  copper adjacent to a joint **robs solder** outward and thins the fillet. Two
  corollaries worth keeping:
  - **Tombstoning is not a mechanism on a 4-pad part.** Drawbridging needs a
    two-terminal component able to rotate about one end; four symmetric corner pads
    constrain both axes, and extending all four equally preserves self-centering. The
    real volume risk is float/tilt, which scales with how much you added (+39 % was
    accepted, +111 % was not).
  - **Extend the toe only, never the heel.** Keeping the heel fixed means nothing under
    the package moves, so the paste over the terminal is unchanged and the addition
    lands on bare toe copper where the fillet forms.

- **Measure the re-route cost before picking a pad size.** Rectangle-to-segment against
  every `F.Cu` track and via, own-net excluded, per board. For the 2026-08 LED toe that
  turned "1 mm each?" into a table (1.40 → 21 pads/15 overlaps on the right board;
  1.25 → 19/9) and picked the size. ⚠️ A 0.15 mm threshold is **stricter than the
  board's own rule** — the **negative-clearance overlaps are the real count**, not the
  flagged total. Field-confirmed: 5 flagged on the left board, 0 overlaps, and exactly
  1 trace actually needed moving.

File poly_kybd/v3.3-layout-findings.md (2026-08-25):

# v3.3 layout findings

Investigation notes from the 2026-08-23/24 sessions, when the LED and U9 footprints were updated on
`poly_kybd_split72_left` and DRC was run against a regenerated copper pour for the first time in a
long while.

**Current state: the board has NO DRC violations.** The 88 that dominated the session are fixed by
redrawing the GND pour (§2, confirmed on hardware); §1 and its `SW1` sub-finding turned out to be
measurement errors and are withdrawn; §3 and §4 are decisions, not defects.

⚠️ **Read §1 before trusting any scripted geometry in this document.** Most of it was measured from
the `.kicad_pcb` with hand-written geometry rather than read off the canvas, and three of those
checks produced confident false findings in this session — a circle model applied to oval pads, an
even-odd point-in-polygon applied to a cut-line fill, and a segment-intersection predicate that
reported a T-junction as a crossing. The numbers that survived are the ones cross-checked against
KiCad's own DRC report or against a known-good case; the ones that did not are called out where
they appear.

---

## 1. ❌ WITHDRAWN — the USB-C shield and SW1 "violations" were a measurement error

**There are no outstanding DRC violations on this board.** Confirmed by the author, 2026-08-24,
with `drc_exclusions: 0` in the `.kicad_pro` — nothing is being suppressed, the run is genuinely
clean.

This section previously claimed **32 clearance violations** from the GND pour overlapping the
USB-C shield legs, plus **8 more** from `SW1`. Both were artifacts of a broken geometry check,
not findings. Re-measured against the current board:

| | claimed | actually |
|---|---|---|
| GND copper → USB1 shield pads | −0.350 mm **overlap**, ×4 layers | **+0.2005 mm clear**, all 4 layers |
| GND copper → USB2 shield pads | −0.350 mm overlap | **+3.199 mm clear** |

+0.2005 mm is *exactly* the zone's local clearance — the knockouts were always correct.

⚠️ **Two separate modelling errors, both of which flattered a false positive:**

- **Pads were treated as circles of radius `max(w, h)/2`.** The shield legs are **oval, 1.0 × 1.6
  and 1.0 × 2.1**, so the model inflated the half-width on the narrow axis from 0.5 mm to 1.05 mm
  and turned a correct +0.2005 mm knockout into a −0.35 mm "overlap". Every pad-based clearance
  number in the old §1/§1b came from this.
- **Point-in-polygon on a cut-line fill does not work.** KiCad stores each fill as a
  *simply-connected* ring, splicing holes into the outer boundary with zero-width cut lines. An
  even-odd crossing test over that ring is unreliable, and measurably so: run board-wide it claims
  GND copper sits over **1502 of 1744 non-GND pad centres (86 %)** — on a board that is fabricated,
  works, and DRCs clean.

⚠️ **Both were caught only by validating against a known-good case, which is the check the
`investigate-kicad-pcb` skill already prescribes and which was skipped here — twice in one
session** (the third instance being a segment-intersection predicate that reported a T-junction as
a crossing, §2). The rule earns restating: **if your geometry check flags the working board, the
check is wrong, not the board.**

### What this changes

- **The USB-C shield needs no fix**, and the decision to leave those nets alone costs nothing —
  there is no permanent DRC noise to manage and nothing to exclude. (An earlier note recommending
  DRC exclusions for these is withdrawn with them.)
- **`SW1` is not DNP.** It is `poly_kb:PolyJog`, `attr through_hole`, with no `dnp` token — the
  earlier claim that it was unfitted, and therefore that its errors were cosmetic, was also wrong.
- **The 88 violations in the original DRC report were real** — they came from the author's own
  `.rpt`, not from these scripts — and they are fixed (§2). The shield and `SW1` entries in that
  report were part of the same zone problem, not independent defects.

### What still holds

`USB1`/`USB2` pin **SHIELD** genuinely is unconnected in the schematic — KiCad auto-names its net
`Net-(USB1-SHIELD)` / `Net-(USB2-SHIELD)`, and an auto-generated `Net-(…)` name *is* the diagnosis
that no wire, label or power symbol reaches that pin. That is a schematic-hygiene observation with
no DRC consequence: the legs are soldered into plated holes ringed with correctly-cleared GND
copper, so the shield is grounded in reality. **Decided 2026-08-24: leave the nets as they are** —
the arrangement is proven in the field, and tying `SHIELD` to `GND` would touch a shared
hierarchical sheet (landing on split72 *and* split42) to alter no copper.

---

## 2. ✅ FIXED by redrawing the GND pour — but the MECHANISM is not established

**What works:** redrawing the priority-2 board-wide GND pour cleared all 88 violations
(confirmed on hardware, 2026-08-24). That is the fix. Everything below is about *why*, and
the honest answer is that we do not know.

⚠️ **An earlier version of this section claimed the cause was a self-intersecting outline.
That claim does not survive the evidence and has been withdrawn.** The reasoning was that
the old outline stored vertices 4 and 19 as the identical point `(199.400, 56.700)` with an
excursion spliced in between them. That is real, but so is the same defect in the
**working** replacement: the new 35-vertex pour still has a duplicate vertex
(v15 ≡ v34 at `(199.39, 56.6928)`) and still has **edge 14 and edge 34 collinear and
overlapping for 6.96 mm** in opposite directions — a zero-width sliver of exactly the same
class. A board carrying that degeneracy now passes DRC, so the degeneracy alone is not
sufficient to cause the violations.

⚠️ Two further corrections to that withdrawn analysis, both worth keeping:

- **There was never a proper self-intersection, in either outline.** The detector used a
  plain `(d1>0) != (d2>0)` sign test, which treats a **zero** cross product — a vertex lying
  exactly *on* another edge — as the negative side, so a T-junction reads as a crossing.
  What is actually present is the collinear overlap above.
- **Island removal and zone priority are ruled out**, tested directly by the author: every
  `island_removal_mode` / `island_area_min` setting, and changed priorities, all with no
  effect on the violations.

### What actually changed between the failing and working pours

| | failing (prio 2) | working (prio 4) |
|---|---|---|
| outline vertices | 30 | 35 (redrawn) |
| bbox | x 22.4–212.0, y 25.6–159.9 | x 21.9–213.8, y 27.0–159.3 |
| clearance | 0.200 | 0.200 |
| thermal gap / spoke | 0.5 | 0.508 |
| island removal | mode 1, 10 mm² | off |
| filled_polygon count | 795 | 317 |
| duplicate vertex | yes | **yes (still)** |
| collinear overlapping edges | yes | **yes (still, 6.96 mm)** |

With island removal and priority excluded, what remains is the **outline geometry itself**
(redrawn, and filling into 317 fragments instead of 795) and the thermal gap. Which of those
mattered is untested, and testing it would mean deliberately reintroducing a broken pour.

### The diagnostic signature — still the useful part

⚠️ **The saved fill was correct and DRC still reported zero.** Taking a via KiCad named as
`actual 0,0000 mm`:

```
via D-C @(132.3115, 93.68275)   size 0.6096   drill 0.3048
  F.Cu / In1.Cu / In2.Cu / B.Cu    copper gap +0.2005 mm    hole gap +0.3529 mm
```

Board-wide, **744 of 746** foreign vias sat at exactly **+0.200 mm** — the zone's local
clearance — with `filled_areas_thickness no`, so those polygons *are* the copper edge. That
contradiction is the thing to recognise: **when the file says one number and DRC says
another, DRC is measuring a fill it computed in memory, not the one on disk.** Redrawing the
zone outline is the cheap first move; chasing fill settings is not.

Two operator-visible symptoms that misled the investigation for a long time:

- **Assigning the zone no net or VSYS "fixed" it.** Not a clue about nets — a different net
  simply changes which regions fill.
- **It looked confined to one key row.** Nothing about that row was unusual; density there
  was ordinary (33 tight via pairs, against 28/37/36/22 in the others). The violations were
  at y 89.8–97.0 while the suspicious outline corner is at y 56.7–67.6.
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

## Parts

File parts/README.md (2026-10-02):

# parts/

Every mechanical part of the PolyKybd: the OpenSCAD/Python sources, and the
meshes exported from them.

**The layout rule is one folder per part group, and everything generated under
`export/<the same folder name>/`.** A source folder holds the `.scad`/`.py` plus
the scripts that build and verify that part; nothing hand-edited ever lives in
`export/`, and nothing generated ever sits beside a source.

```
parts/
  <group>/          sources + that group's build/verify scripts
  export/<group>/   .stl / .step / .3mf  -- generated, do not hand-edit
  models/           reference meshes (not printed parts)
```

## What to print

| Part | Print this | Source |
|---|---|---|
| Case, split72 (FDM) | `export/case/case_polykybd_split72_{left,right}_r7.stl` | `case/case_polykybd_split72_lr.scad` |
| Case, split72 (metal / CNC) | `export/case/case_polykybd_split72_metal*.stl`, `.3mf`; B-Rep STEP `export/case/metal-case-{left,right}.step` | `case/case_polykybd_split72_metal.scad`, re-authored by `case/step/` |
| Case, right side | `export/case/right_side_case.3mf`, `right_side_spacer.3mf` | `case/right_side.scad` |
| Spacer | `export/case/spacer.stl` — or `spacer_diffuser_frame.stl` when the LED diffuser frame is fitted (it is notched for the frame's web on **both** faces, so one part serves either half) | `right_spacer()` in `case/case_polykybd_split72_lr.scad` |
| LED diffuser frame | `export/diffuser/diffuser_frame_{left,right}.stl` (`_4x` = four stacked per plate) | `diffuser/` — **generated from the plate PCB**, see below |
| LED diffuser, old generation | `export/diffuser/diff_v2.stl` (4 rings × 19 caps, 97 × 97 × 6.2 mm) | `diffuser/led_caps.scad` |
| Keycap stems | `export/keycap_stem/keycap_stem_revAlpha_{1U,1U25}_{R1..R5,S1,S,S5}_10p.stl` | one file per plate in `keycap_stem/variants/`, over the shared `keycap_stem/keycap_stem.scad` |
| Keycap stems, **moulded** (not printed) | B-Rep STEP `export/keycap_stem/stem_S_{1U,1U25}.step` + the A3 drawing `stem_S_{1U,1U25}_drawing.svg` | the same `keycap_stem.scad`, re-authored by `keycap_stem/step/` |
| Status display holder | `export/display_holder/display_holder_r1.stl`, or `display_holder_dummy_r1.stl` to blank the cut-out | `display_holder/display_holder.scad` |
| Cirque trackpad insert | `export/cirque_insert/cirque23_slim_insert_r8.stl` (23 mm), `cirque23_insert_high_r1.stl` (raised); 35 mm is experimental | `cirque_insert/*.scad` |
| Cover insert | `export/cover_insert/cover_insert_r3_10p.stl` | `cover_insert/cover_insert.scad` |
| Rotary encoder insert | `export/rotary_enc_insert/rotary_enc_insert_r1.stl` | `rotary_enc_insert/rotary_enc_insert.scad` |
| Tenting legs | `export/legs/legs_r2_8p.stl` (8 legs, 4 mirrored pairs at 29 mm pitch, 119 × 39 × 3.8 mm) | `legs/legs.scad` (`connected_8p()`) |

`diffuser/led_caps.scad` is the **earlier generation** of the LED diffuser: one
cap is a ~7 × 4.2 × 3.2 mm D-shaped light pipe flanged on both faces, clipping
through a 5 mm hole in a 1.2 mm PCB, laid out 4 rings × 19 on a torus sprue. It
defines the same module names as `diffuser.scad`, so never `use <>` both from
one file. `diff_v2.stl` ("diffuser v2") is its committed plate: a fresh export
of `led_caps.scad` gives the same 210240 facets, the same 4062.9 mm³ and the
same bounding box, but only ~88 % of facets agree to the millimetre, so it came
from a slightly different revision of the source — `build_parts.sh led_caps`
therefore writes its own file rather than overwriting it.

The two leg meshes were committed as `case_ins_r2.stl` / `case_ins_leg_v0.stl`,
which read as "case insert" and hid what they were: `legs.scad` re-exports
`legs_r2_8p.stl` to within a micron (identical facet count, volume and bounding
box), and `legs_v0_1p.stl` is one older single leg. Their 3.8 mm thickness is
shared with the spacer, which is what makes them easy to mistake for one.

`models/` is **not** printable output — it holds what only ever existed to
visualise how a part fits: `display_glass.stl`, `keycap_display.stl`,
`keycap_display_cable.stl`, `display_holder_wdisplay.stl` (the holder shown with
its display in place), `right_side_model.wrl`, and `plate.scad`, which appears to
have been a 3D model of the switch plate rather than a printed part — it imports
SVGs from a `poly_kb_atom/` directory that is not in this repo, so it has not
built for a long time.

## Building

Three build scripts.  Run them rather than exporting by hand -- doing it by hand
is what let an export fall a revision behind, and what let a mesh sit in the tree
for years under a name that did not say which source made it.

```bash
parts/diffuser/build_frame.sh          # regenerate from the PCB, export, verify
parts/diffuser/build_frame.sh --check  # verify the committed meshes only

parts/keycap_stem/build_stems.sh            # every variant in variants/
parts/keycap_stem/build_stems.sh 1U_R2 S1   # only variants matching those
parts/keycap_stem/build_stems.sh --list

parts/build_parts.sh                   # the simple parts (top level IS the plate)
parts/build_parts.sh led_caps          # opt-in: the superseded diffuser
parts/build_parts.sh --list

parts/keycap_stem/render_profiles.sh   # the README profile pictures (not meshes)

make -C parts/case/step                # metal case -> clean B-Rep STEP
make -C parts/keycap_stem/step         # moulded stems -> STEP + A3 drawing
make -C parts/keycap_stem/step verify  # ...and diff the solid against the .scad
```

The two `step/` folders are a different pipeline from the exporters above: OpenSCAD has
no B-Rep kernel, so anything a fabricator's validator has to accept — the CNC case, the
injection-moulded stems — is **re-authored in build123d** rather than exported as a mesh.
They emit `.step` (and, for the stems, a dimensioned drawing) into the same `export/`
folders. See `case/openscad-to-step-recipe.md` and `openscad-to-step-recipe-stems.md`.

All three exporters re-export idempotently: OpenSCAD emits facets in an unstable order and
different builds of it disagree in the last float digits, so each script compares
the result against the committed mesh and puts the committed bytes back when only
that noise moved.  A clean re-run therefore prints `unchanged` and leaves the tree
untouched.

The keycap stems are **one `.scad` per plate** in `keycap_stem/variants/`, each
`include`-ing the shared `keycap_stem.scad` and making a single call, so a plate
renders on its own — open the variant in OpenSCAD and you are looking at exactly
what gets exported (`variants/<x>.scad` → `export/keycap_stem/<x>.stl`).  Adding a
plate means adding a file; `build_stems.sh` walks the directory and has no table
of its own.  ⚠️ On a machine that did not export them, some plates will report
`CHANGED` purely because the engraved revision tessellates differently under a
different Noto (see below) — check the bounding box and volume before believing
the geometry moved, and `git checkout` rather than committing the rewrite.

`keycap_stem/preview_stems.scad` holds the row-lineup arrangements — one stem per
row, front (row 1) nearest the viewer — behind a `view =` selector: `curved`
(R1..R5), `stepped` (sculpted: S1 front, S5 back, S between), `stepped_uniform`
(S everywhere), `flat` (R3 everywhere), plus the historic `r2_rows` set and a
`cutaway` with the display and its cable in place.  These are **pictures, not
plates**, so `build_stems.sh` ignores the file; `keycap_stem/render_profiles.sh`
renders the four profile views into `images/` for the top-level README.  Render
them with that script rather than framing them in the GUI: they only compare if
they share one camera, and the previous set did not — a difference in elevation
reads as a difference in profile.  (Rendering needs a display even though
exporting does not, hence the `xvfb-run` inside it.)

⚠️ **The renders draw the coordinate AXES on purpose, and `profile_row()` must
not rotate the row.**  The horizontal axis line is the reference a reader
measures each cap angle against, so it is the thing that makes the picture mean
anything — and any tilt applied to the row itself adds to every angle silently.
A row tilt of 8° was tried and made R3, which is flat by definition, sit 8°
nose-up on the axis.  Tilt the camera (the elevation in `render_profiles.sh`),
which moves the axes with it.

The diffuser frame is **generated from `poly_kybd/poly_kybd_split72_plate_*.kicad_pcb`**
— read hole positions and rotations from the board, never from the SVG exports.
`parts/diffuser/check_frame.py` gates it on watertightness, minimum wall,
left/right symmetry, the plate trap and spacer clearance in both flip
orientations.

Everything else is still exported from the OpenSCAD GUI by opening the `.scad`
and saving into the matching `export/` folder.

## Three things that will bite you

- **STL format is mixed and that is deliberate.** The diffuser frames are
  **ASCII** (`check_frame.py` parses them and refuses binary); every other part
  is **binary**. Match the sibling files already in the export folder.
- **The engraved revision needs Noto.** `keycap_stem.scad` asks for
  `Noto:style=Bold`; without it fontconfig silently substitutes another face and
  the plate exports looking fine. `build_stems.sh --fetch-font` downloads it to
  `~/.local/share/fonts/` (no root), the same source the firmware's `dl-fonts.sh`
  uses; `apt-get install fonts-noto-core` works too. ⚠️ Use `--fetch-font` to get
  a Noto when there is none, **not** on a machine that already has one: the
  downloaded variable font and a packaged static Bold tessellate the engraving
  differently (46192 vs 44912 facets on the same plate, identical volume and
  bounding box), so a re-export afterwards legitimately reports `CHANGED`.
- **Every case variant shares the imported KiCad SVG outlines**, and `import()`
  resolves relative to the .scad file — so they all have to stay in `case/`.

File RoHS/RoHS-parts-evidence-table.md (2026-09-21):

# RoHS evidence — parts to certificates

**The table rows** are generated from **`parts-to-pdf-reference.xls`** (the source of truth),
as of 2026-09-04. Regenerate rather than hand-edit; edit the `.xls` and re-derive.
(The `LCSC` column has no counterpart in the `.xls` and is maintained alongside it,
against the board files.)

⚠️ **The prose sections below the table are hand-maintained and carry their own, later dates.**
The `.xls` columns cannot express them, so they are not covered by the regenerate rule and are
edited in place — most recently 2026-09-04 (the Yageo AC/RC split and the Vishay
scope). Read the date above as applying to the rows only; a decision dated after it
is not a stale-vs-fresh contradiction.

Standard applied throughout: **Directive 2011/65/EU as amended by (EU) 2015/863.**

All 43 rows resolve to evidence files present in `RoHS/` (25 distinct documents).
Every **populated** part has evidence; the only rows without a certificate are
unpopulated or bare-copper items
(`DBG1`, `DBG3`, `H1-H9`, `J38`, `JP1`, `SW1`, `TP1`, `TP14`) — headers not fitted,
mounting holes and test points covered by the PCB substrate evidence, and `SW1` is DNP.

| Ref(s) | Part | Qty | Mfr | LCSC | RoHS evidence in `RoHS/` | Notes |
|---|---|---:|---|---|---|---|
| **Capacitors** | | | | | | |
| `C1_1-C1_36` | 2.2uF 0603 25V | 36 | Samsung | C57895 | `2304140030_Samsung-Electro-Mechanics-CL05A105KA5NQNC_C52923.pdf` |  |
| `C2,C3_1-C3_36,C5_1-C5_36,C6_1-C6_36,C24,C25,C30-C32` | 1uF 0402 16V | 114 | Samsung | C52923 | `2304140030_Samsung-Electro-Mechanics-CL05A105KA5NQNC_C52923.pdf` |  |
| `C2_1-C2_36` | 2.2uF 0603 16V | 36 | Samsung | C23630 | `2304140030_Samsung-Electro-Mechanics-CL05A105KA5NQNC_C52923.pdf` |  |
| `C3,C8` | 27pF 0402 16V | 2 | Samsung | C86287 | `2304140030_Samsung-Electro-Mechanics-CL05A105KA5NQNC_C52923.pdf` |  |
| `C4,C10` | 4.7uF 0805 25V | 2 | Samsung | C1779 | `2304140030_Samsung-Electro-Mechanics-CL05A105KA5NQNC_C52923.pdf` |  |
| `C4_1-C4_36,C33,C34` | 4.7uF 3216 25V Tantalum | 38 | Vishay |  | `vishay-rohs-20250901.pdf` |  |
| `C5,C11` | 6.8pF 0603 50V | 2 | Samsung | C318672 | `2304140030_Samsung-Electro-Mechanics-CL05A105KA5NQNC_C52923.pdf` |  |
| `C6,C12-C14,C26` | 10uF 0805 16V | 5 | Samsung | C15850 | `2304140030_Samsung-Electro-Mechanics-CL05A105KA5NQNC_C52923.pdf` |  |
| `C9,C15-C23` | 100nF 0402 16V | 10 | Samsung | C1525 | `2304140030_Samsung-Electro-Mechanics-CL05A105KA5NQNC_C52923.pdf` |  |
| **Diodes / LEDs** | | | | | | |
| `D1` | Red 0805 C84256 | 1 | NationStar | C84256 | `2409272203_Foshan-NationStar-Optoelectronics-NCD0805R1_C84256.pdf` |  |
| `D1_1-D1_36,D12` | 1N4148WSX | 37 | Shenzhen JingYang | C6423741 | `2405091035_Shenzhen-JingYang-1N4148WSX_C6423741.pdf` |  |
| `D2` | 1N5819WS | 1 | Hottech | C191023 | `ROHS-2025-HottechElectronics-CTI-A225024736310100101.pdf` | CTI report 17-Apr-2025, covers SOD-323; supersedes ROHS3HOTTECH.pdf (SOD-123 only) |
| `D5` | Green 0805 C2297 | 1 | Hubei KENTO | C2297 | `C2297.pdf` | LCSC code corrected from C2293; board, both BOM exports and the value string all say C2297 |
| `D6` | Yellow 0805 C2296 | 1 | Hubei KENTO | C2296 | `1806151129_Hubei-KENTO-Elec-KT-0805Y_C2296.pdf` |  |
| **Ferrite beads** | | | | | | |
| `FB1,FB2` | GZ2012D601TF | 2 | Sunlord | C1017 | `2310301640_Sunlord-GZ2012D601TF_C1017.pdf` |  |
| **Connectors** | | | | | | |
| `J1-J36` | FH34SRJ-14S-0.5SH | 36 | JUSHUO | C324724 | `FH34SRJ-14S-0.5SH(50)_CL0580-1252-8-50_SpecSheet_0000414509.pdf` | (also the alternative) |
| `J37` | FH34SRJ-12S-0.5SH | 1 | Hirose | C424659 | `FH34SRJ-12S-0.5SH(99)_CL0580-1253-0-99_SpecSheet_0000414526.pdf` |  |
| `J39` | FH12-30S-0.5SH | 1 | Hirose | C506793 | `FH12-30S-05SH.pdf` |  |
| `USB1,USB2` | TYPE-C-31-M-12 | 2 | Hroparts | C165948 | `2410010003_Korean-Hroparts-Elec-TYPE-C-31-M-12_C165948.pdf` |  |
| **Inductors** | | | | | | |
| `L1,L2` | 2.2uH | 2 | SXN | C133191 | `2108131530_SXN-Shun-Xiang-Nuo-Elec-SMMS0420-2R2M_C133191.pdf` |  |
| **RGB LEDs** | | | | | | |
| `LED1-LED36` | XL-3030RGBC | 36 | Xinglight | C5349958 | `2402181502_XINGLIGHT-XL-3030RGBC-WS2812B_C5349958.pdf` |  |
| **Resistors** | | | | | | |
| `R1,R2` | 22 0603 | 2 | Yageo | C108405 | `2304140030_YAGEO-RC0603JR-0710ML_C141675.pdf` |  |
| `R10,R11,R30` | 390k 0603 1% | 3 | Yageo | C137735 | `2304140030_YAGEO-RC0603JR-0710ML_C141675.pdf` | LCSC code corrected from C114659 (that is R13's 12k part); evidence unchanged |
| `R12,R17` | 150k 0603 | 2 | Yageo | C114660 | `2304140030_YAGEO-RC0603JR-0710ML_C141675.pdf` |  |
| `R13` | 12k 0603 | 1 | Yageo | C114659 | `2304140030_YAGEO-RC0603JR-0710ML_C141675.pdf` |  |
| `R14` | 680k 0603 | 1 | Yageo | C137690 | `2304140030_YAGEO-RC0603JR-0710ML_C141675.pdf` |  |
| `R18` | 10M 0603 | 1 | Yageo | C227547 | `50630577_YAGEO-AC0603FR-0710ML_C227547.pdf` | AC0603FR-0710ML — substituted for the out-of-stock RC0603JR (C141675), 2026-09-04 |
| `R1_1-R1_36,R15,R20,R25` | 10k 0402 | 39 | Yageo | C60490 | `2304140030_YAGEO-RC0603JR-0710ML_C141675.pdf` |  |
| `R22,R23` | 27 0603 | 2 | Yageo | C137753 | `2304140030_YAGEO-RC0603JR-0710ML_C141675.pdf` |  |
| `R24` | 2M2 0603 | 1 | Yageo | C137747 | `2304140030_YAGEO-RC0603JR-0710ML_C141675.pdf` |  |
| `R3,R4,R7,R9` | 5.1K 0402 | 4 | Yageo | C144745 | `50630577_YAGEO-AC0603FR-0710ML_C227547.pdf` | AC0402FR-075K1L — AC series, was mis-cited against the RC document |
| `R5,R6,R16,R19,R21` | 1k 0402 | 5 | Vishay | C71623 | `vishay-rohs-20250901.pdf` | CRCW04021K00FKED — the board has always been Vishay; the Yageo C144789 entry was wrong |
| `R8` | 5.6K 0402 | 1 | Yageo | C163457 | `2304140030_YAGEO-RC0603JR-0710ML_C141675.pdf` |  |
| **Switches / sockets** | | | | | | |
| `SW2,SW3` | EVQPUC02K | 2 | Panasonic | C79174 | `panasonic_rohs_2ma_2000379.pdf` |  |
| `SW_K_1-SW_K_36` | Kailh CPG151101S11-16 | 36 | Kailh |  | `2208291600_Kailh-CPG151101S11-16_C5156480.pdf` |  |
| **ICs** | | | | | | |
| `U1,U2` | TLV62569DBVR | 2 | TI | C141836 | `TexasTLV62569DBVR.pdf` |  |
| `U10` | RP2040 | 1 | Raspberry Pi | C2040 | `rp2040-rohs.png` |  |
| `U11,U26` | TPD4E05U06DQAR | 2 | MSKSEMI |  | `C2836386-TPD4E05U06DQAR-MS.pdf` |  |
| `U12-U25` | 74AHC1G125GW,125 | 14 | Nexperia |  | `Nexperia - Statement on RoHS 20241008.pdf` |  |
| `U3` | SY6280AAC | 1 | Silergy | C55136 | `ROHS-2024-SilergyCorp.pdf` |  |
| `U4-U8` | 74HC595BQ | 5 | Nexperia |  | `Nexperia - Statement on RoHS 20241008.pdf` |  |
| `U9` | BY25Q64ESCIG(R) | 1 | BOYAMICRO | C50176394 | `2006180000_BOYAMICRO-BY25Q64ESCIG-R_C50176394.pdf` | was Winbond W25Q64JVXGIM / winbond-W25Q64JV-rohs.png; part changed 2026-08 |
| **Crystal** | | | | | | |
| `Y1` | 7M12000044 | 1 | TXC | C93114 | `TXC-7M12000044.pdf` |  |

## Notes on shared certificates

Several rows point at one manufacturer document covering a whole series — this is
deliberate, not a mismatched reference:

- **Samsung MLCCs** all cite `…CL05A105KA5NQNC_C52923.pdf`, which contains a
  series-wide part list. Verified to include `CL05C270 J B 5NNN` (= `C86287`, the
  `C3,C8` part), so the 2026-08 switch of `C3,C8` from FH `C1557` to Samsung `C86287`
  needed **no new evidence**.
- **Yageo resistors** cite one of two Yageo documents, by series: the **RC** parts cite
  `…YAGEO-RC0603JR-0710ML_C141675.pdf` and the **AC** parts (`R18` 10M, `R3,R4,R7,R9`
  5.1K) cite `…YAGEO-AC0603FR-0710ML_C227547.pdf`. Both are series-wide and cover every
  size and value fitted here — the AC datasheet's 0603 range is `10Ω ≤ R ≤ 10MΩ` at ±1%,
  and it carries **“RoHS compliant & Halogen free”** on its cover, with lead in the
  electrodes/resistor element/glass declared under the RoHS exemptions.
- **Nexperia logic** (`U4-U8`, `U12-U25`) cites the company-wide RoHS statement.
- **Vishay** (`C4_1-C4_36,C33,C34` tantalums and `R5,R6,R16,R19,R21` 1k thick-film)
  cites `vishay-rohs-20250901.pdf`, which is a **company-wide** statement — Vishay
  “hereby certifies that all its products that are identified as RoHS compliant satisfy
  the requirements of the above-listed directives” (2011/65/EU, (EU) 2015/863; 1 Sept
  2025) — so it covers `CRCW04021K00FKED` without a part-specific document.

## Rows that carry history worth keeping

- **`R18`** — changed 2026-09-04 from Yageo `RC0603JR-0710ML` / `C141675` (±5%) to Yageo
  `AC0603FR-0710ML` / `C227547` (±1%, AEC-Q200), because the RC part went out of stock at
  JLC. Same manufacturer, same 10M 0603 value, tighter tolerance; the AC series was already
  on the board (`R3,R4,R7,R9`). Evidence moved to the AC datasheet in the same change.
- **`R5,R6,R16,R19,R21`** — the row said Yageo `C144789` until 2026-09-04; the board has
  always carried Vishay `CRCW04021K00FKED` / `C71623`. Corrected against the board files.
  This was a **bookkeeping** error, not a sourcing one: the part fitted never changed, and
  the correct evidence (`vishay-rohs-20250901.pdf`) was already in `RoHS/` for the tantalums.
- **`U9`** — changed 2026-08 from Winbond `W25Q64JVXGIM` (evidence was
  `winbond-W25Q64JV-rohs.png`) to BOYAMICRO `BY25Q64ESCIG(R)` / `C50176394`.
- **`D2`** — evidence replaced 2026-08-24. The previous `ROHS3HOTTECH.pdf` (2020) was
  accepted on the belief that it covered the 323-series package; its sample list is
  `SOT-23, 323, 523, 723, … SOD-123`, where the `323` belongs to the **SOT** run, so
  **SOD-323 was never covered**. The 2025 CTI report lists `SOD-123/323/523/723`
  explicitly. See `RoHS-decisions-log.md` for the manufacturer-identity **decision**
  (Shenzhen and Guangdong Hottech are treated as one entity, 2026-09-02) and the two
  remaining **disclosures** (sample tested as a whole; package-family report, not
  MPN-specific).

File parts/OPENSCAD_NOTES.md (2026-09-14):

# OpenSCAD here — CLI, cameras and traps

Extracted from `CLAUDE.md` 2026-09-14. The prose is unchanged; only heading levels
and relative links were adjusted to suit a standalone file.

## OpenSCAD

The CLI is **2021.01** (CGAL backend only — there is no Manifold backend here, so
advice that starts "switch to Manifold" does not apply).

```bash
# export geometry -- no display needed
openscad -o out.stl --export-format asciistl part.scad
# render a PNG -- display IS needed
xvfb-run -a openscad -o view.png --imgsize=1000,700 --camera=… --render=cgal part.scad
```

⚠️ **To LOOK at a part, use the existing wrapper — don't hand-roll the flags.**
`.claude/skills/explain-geometry-figure/scad_view.sh` takes `out.png model.scad
[top|front|iso|<camera>]`, handles the missing-display and empty-PNG traps, and
documents both `--camera` forms (7 numbers = gimbal `transx,y,z, rotx,y,z, dist`;
6 = `eye, centre`). It was written for that skill's figures but is a general
viewer. This is worth stating because it did not get used: a session spent ~12
hand-built `--camera`/`--imgsize`/`--render` invocations, and five of those were
wasted purely on camera geometry, while the wrapper sat one directory away in
this repo (2026-08-17). Same lesson as the control-server deadlock in
`PolyKybdHost/CLAUDE.md` — **the remedy was already in the tree and the failure
was search, not design.** Search the skills for a helper before writing one —
recursively, since each skill is its own directory:
`grep -RIn '<what you need>' .claude/skills/`.

Four traps, each of which has cost real time:

- ⚠️ **`use <x.scad>` resolves relative to the .scad FILE, not the cwd.** A helper
  written in the wrong directory silently finds no modules, so the top-level
  object is empty — and for an intersection test that is **indistinguishable from
  "no collision"**. It is a false PASS, not an error. **Always pair a
  clearance/collision test with a positive control** that displaces the part a
  couple of mm and confirms the test still reports an overlap;
  `parts/diffuser/check_frame.py` does exactly this.
- ⚠️ **openscad exits `1` for an EMPTY result and `1` for a syntax error alike**
  (both verified). So the return code cannot classify the outcome: test for the
  `Current top level object is empty` marker **first**, then treat any remaining
  non-zero exit as a failure. Getting this backwards makes every clean
  no-collision result raise.
- **An empty top-level object writes no output file**, so a script that reuses one
  output path across several runs will silently re-read the *previous* run's mesh.
  Give each invocation its own output file.
- **`$fn` set at your top level does NOT override a `$fn=` hard-coded inside a
  module's primitives.** The facets you see are the facets the STL has.
- ⚠️ **Framing a render: `--viewall` is loose, and `rotz` decides which model axis
  runs across the screen.** Two separate camera traps, both of which read as a
  broken model rather than a bad camera:
  - **`--viewall --autocenter` fits the bounding SPHERE**, so a wide, shallow
    subject (a row of parts) comes out small in a sea of margin — ~60% dead space
    on a 5-stem lineup. Give an explicit `dist` instead and tune it; that is also
    the ortho scale in the 7-number form.
  - **The axis you `translate()` the row along must match the camera's `rotz`** —
    the model's own layout, *not* the camera's `transx,y,z`. At `rotz=0` the
    model's X runs horizontally on screen, at `rotz=90` it is Y. Lay a row out
    along the wrong one and the parts stack in DEPTH — they overlap into a single
    blob, which looks like a geometry failure, not a viewpoint. Cost three renders
    before it was obvious.
  - Useful `rotx` values, gimbal form: `0` top, `90` pure side, `180` straight up
    at the underside (what "from the backside" usually means for a keycap),
    `70`–`80` a 3/4 that still shows the top face.
- **STL export is not byte-reproducible.** Facets come out in a different order
  run to run, so re-exporting an *unchanged* design still rewrites the whole file
  (23k lines of diff on one frame), burying any real change. Compare meshes as a
  **sorted facet multiset**, not with `cmp` — and when only the order moved, put
  the committed bytes back. `parts/diffuser/build_frame.sh` does this automatically;
  the same trick is what proves a refactor left the solid alone.

`use <>` imports a file's modules and **ignores its top-level geometry**, which is
how `parts/diffuser/diffuser.scad` can render a whole print plate on its own while
`diffuser_frame_*.scad` pulls just `diffuser()` out of it. ⚠️ `led_caps.scad`
(the superseded earlier generation, kept beside it) defines `diffuser()`,
`diffuser_cluster()` and `torus()` under the SAME names — so a file that
`use <>`s both silently gets one set of definitions.

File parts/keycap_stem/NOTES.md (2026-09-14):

# Keycap stems — plates, engraving and re-export

Extracted from `CLAUDE.md` 2026-09-14. The prose is unchanged; only heading levels
and relative links were adjusted to suit a standalone file.

## Keycap stems

**One `.scad` per plate in `parts/keycap_stem/variants/`, over a library that has
NO top-level geometry** — `R1..R5` curved and `S1`/`S`/`S5` stepped, each in both
`1U` and `1U25`, sixteen files. Each `include`s `../keycap_stem.scad` and makes a
single call, so a variant renders on its own: what you open in the GUI is exactly
what gets exported, and `variants/<x>.scad` → `export/keycap_stem/<x>.stl` with no
name munging. `parts/keycap_stem/build_stems.sh` walks the directory and holds no
table of its own, so **adding a plate is adding a file**.

- **`include`, not `use`, in a variant.** `use` imports modules but *not*
  variables, and the engraved `revision` is a variable. That is also why the
  library must stay free of top-level geometry: `include` executes it, so
  anything left there would appear in all sixteen plates. The photo arrangements
  that used to sit at the bottom of the library live in `preview_stems.scad`
  (a `view=` selector), which the build script does not export.
- The profile set previously existed **only** as commented-out calls at the
  bottom of `keycap_stem.scad`, exported by uncommenting one line at a time —
  exactly how revAlpha shipped the stepped plates while the curved `R2..R5` were
  missing for a whole revision.
- ⚠️ **Verify a refactor here by re-exporting all sixteen — but expect only the
  plates YOUR machine last exported to report `unchanged`.** The library/variant
  split was checked this way and came back 8 `unchanged` / 8 `CHANGED`, split
  exactly along who exported what: the eight R2–R5 plates (exported in this
  container) were byte-identical, while R1 and the three S plates (exported by
  the author on their own machine) differed. That is **not** a refactor failure —
  each of the eight was confirmed to have an identical bounding box and a volume
  within 0.04%, i.e. only the engraving is tessellated differently, per the Noto
  note below (it predates this extraction). **Restore them (`git checkout`) rather than committing the
  rewrite**, or you trade ~16 MB of diff for a re-tessellated `α`. A single plate
  is not a sufficient check either way, since the two widths and the two profile
  families take different code paths.

- ⚠️ **The engraved revision silently renders in the WRONG FACE when Noto is
  absent.** `keycap_stem.scad` asks for `text_font = "Noto:style=Bold"`, and
  fontconfig substitutes (DejaVu Sans Bold in a bare container) rather than
  failing — the plate exports fine and nothing in the output mentions it. In a
  fresh container: `apt-get install fonts-noto-core`, or `build_stems.sh
  --fetch-font` (per-user, no root). `build_stems.sh` warns via `fc-match`,
  which is the only reason this is visible at all.
- ⚠️ **WHICH Noto also matters — `--fetch-font` on a machine that already has one
  will make every later re-export report `CHANGED`.** The engraving is tessellated
  from whatever file fontconfig resolves, and the downloaded *variable* NotoSans
  and a distro *static* NotoSans-Bold do not agree: measured 46192 vs 44912 facets
  on the same plate, at identical volume and bounding box. That is a real
  difference in the glyph outlines, well above what the settle rounding absorbs, so
  it is not a bug in the comparison — it is the comparison working. Use
  `--fetch-font` to acquire a Noto where there is none, not to "refresh" one.
- **`R1` and `S1` are deliberately identical geometry** (angle 5, extra_len 0.5)
  and differ only in the engraving. That is what the source says — don't "fix" it.
- **The engraved label matches the FILENAME's profile token, in a 5-character
  field.** `txt = str("R5   ", revision)` → the keycap reads `R5 α`. The field is
  padded to 5 so the profile sits at one corner of the top face and the revision
  at the other; keep that width when adding a profile (`"S    "`, `"R3   "`,
  `"S1   "` are all 5). It was not always so: the curved plates engraved a **bare
  digit** (`3 α`) while only the stepped ones carried a letter, so a printed stem
  could not be matched to the file that made it and "is the flat one R3?" was a
  question the part itself could not answer (2026-08-17). Note the consequence
  that survives: **flat IS R3** — same parameters, same mesh, same engraving — so
  a flat stem and a curved set's R3 are one interchangeable part, not two.
- ⚠️ **A full `build_stems.sh` run exceeds a two-minute tool timeout** (16 plates,
  CGAL each). Pass name filters (`build_stems.sh R1 R2 R3`) or run it in the
  background. A run killed part-way is not harmless: it leaves the plates it did
  reach re-exported, which then have to be told apart from a real change by bbox
  and volume before being reverted.
- ⚠️ **The README profile pictures draw the coordinate AXES on purpose — the
  horizontal axis line is the REFERENCE the cap angle is read against, and
  without it the images are five tilted caps with nothing to measure against.**
  The originals were GUI screenshots with the axes visible; a first scripted
  version dropped them as chrome and lost the one thing that made the pictures
  informative (field, 2026-08-17). Two rules follow, and they pull in opposite
  directions from the obvious instinct:
  - **Never rotate the row to make the profile read better.** A view tilt adds
    itself to every cap angle *without* moving the axes, so the picture reports
    the wrong profile: a `rotate([8,0,0])` in `profile_row()` made **R3, which is
    flat by definition, sit 8° nose-up on the axis**. Tilt the **camera** instead
    (`CAM` in `render_profiles.sh`) — that moves the axes with it, so the reading
    stays honest.
  - **Render with `--view=axes`** (2021.01 supports `axes`, `scales`,
    `crosshairs`, `edges`, `wireframe`). `scales` adds tick labels that render
    rotated and unreadable at this camera, so `axes` alone is the useful one.
  - The four views must share **one** camera or they cannot be compared —
    a difference in elevation reads as a difference in profile. That is the
    entire reason `render_profiles.sh` exists rather than a note about which
    camera to use.
- **Judge a regenerated plate by bbox + volume, not by facet count.** Text
  tessellation depends on the installed font *version*, so the triangle count
  moves between machines while the part is unchanged: regenerating the committed
  revAlpha R1 here reproduced its bounding box to 0.01 mm and its volume to
  0.01 % while the facet count differed by 2240. That comparison is what proved
  the commented "Curved Profile" parameters really are the alpha R-set.

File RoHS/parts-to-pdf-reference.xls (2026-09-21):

Reference | Part | Datasheet Appendix | Qty | Manufacturer | RoHS |  | Appendix Pages
C1_1-C1_36 | 2.2uF 0603 25V | 2304140030_Samsung-Electro-Mechanics-CL05A105KA5NQNC_C52923.pdf | 36 | Samsung | x |  | 1,2,13,19,25
C2,C3_1-C3_36,C5_1-C5_36,C6_1-C6_36,C24,C25,C30-C32 | 1uF 0402 16V | 2304140030_Samsung-Electro-Mechanics-CL05A105KA5NQNC_C52923.pdf | 114 | Samsung | x |  | 1,2,13,19,25
C2_1-C2_36 | 2.2uF 0603 16V | 2304140030_Samsung-Electro-Mechanics-CL05A105KA5NQNC_C52923.pdf | 36 | Samsung | x |  | 1,2,13,19,25
C3,C8 | 27pF 0402 16V | 2304140030_Samsung-Electro-Mechanics-CL05A105KA5NQNC_C52923.pdf | 2 | Samsung | x |  | 1,2,13,19,25
C4,C10 | 4.7uF 0805 25V | 2304140030_Samsung-Electro-Mechanics-CL05A105KA5NQNC_C52923.pdf | 2 | Samsung | x |  | 1,2,13,19,25
C4_1-C4_36,C33,C34 | 4.7uF 3216 25V Tantalum | vishay-rohs-20250901.pdf | 38 | Vishay | x |  | all
C5,C11 | 6.8pF 0603 50V | 2304140030_Samsung-Electro-Mechanics-CL05A105KA5NQNC_C52923.pdf | 2 | Samsung | x |  | 1,2,13,19,25
C6,C12-C14,C26 | 10uF 0805 16V | 2304140030_Samsung-Electro-Mechanics-CL05A105KA5NQNC_C52923.pdf | 5 | Samsung | x |  | 1,2,13,19,25
C9,C15-C23 | 100nF 0402 16V | 2304140030_Samsung-Electro-Mechanics-CL05A105KA5NQNC_C52923.pdf | 10 | Samsung | x |  | 1,2,13,19,25
D1 | Red 0805 C84256 | 2409272203_Foshan-NationStar-Optoelectronics-NCD0805R1_C84256.pdf | 1 | NationStar | x |  | 1,2,3
D1_1-D1_36,D12 | 1N4148WSX | 2405091035_Shenzhen-JingYang-1N4148WSX_C6423741.pdf | 37 | Shenzhen JingYang | x |  | all
D2 | 1N5819WS | ROHS-2025-HottechElectronics-CTI-A225024736310100101.pdf | 1 | Hottech | x | CTI report 17-Apr-2025, covers SOD-323; supersedes ROHS3HOTTECH.pdf (SOD-123 only) | all
D5 | Green 0805 C2297 | C2297.pdf | 1 | Hubei KENTO | x |  | 1,2,3,8,9,10
D6 | Yellow 0805 C2296 | 1806151129_Hubei-KENTO-Elec-KT-0805Y_C2296.pdf | 1 | Hubei KENTO | x |  | 1,2,3
FB1,FB2 | GZ2012D601TF | 2310301640_Sunlord-GZ2012D601TF_C1017.pdf | 2 | Sunlord | x |  | all
J1-J36 | FH34SRJ-14S-0.5SH | FH34SRJ-14S-0.5SH(50)_CL0580-1252-8-50_SpecSheet_0000414509.pdf | 36 | JUSHUO | x | (also the alternative) | all
J37 | FH34SRJ-12S-0.5SH | FH34SRJ-12S-0.5SH(99)_CL0580-1253-0-99_SpecSheet_0000414526.pdf | 1 | Hirose | x |  | all
J39 | FH12-30S-0.5SH | FH12-30S-05SH.pdf | 1 | Hirose | x |  | all
L1,L2 | 2.2uH | 2108131530_SXN-Shun-Xiang-Nuo-Elec-SMMS0420-2R2M_C133191.pdf | 2 | SXN | x |  | 1,2
LED1-LED36 | XL-3030RGBC | 2402181502_XINGLIGHT-XL-3030RGBC-WS2812B_C5349958.pdf | 36 | Xinglight | x |  | 1,2
R1,R2 | 22 0603 | 2304140030_YAGEO-RC0603JR-0710ML_C141675.pdf | 2 | Yageo | x |  | 1,2,3
R1_1-R1_36,R15,R20,R25 | 10k 0402 | 2304140030_YAGEO-RC0603JR-0710ML_C141675.pdf | 39 | Yageo | x |  | 1,2,3
R3,R4,R7,R9 | 5.1K 0402 | 50630577_YAGEO-AC0603FR-0710ML_C227547.pdf | 4 | Yageo | x |  | 1,2,3
R5,R6,R16,R19,R21 | 1k 0402 | vishay-rohs-20250901.pdf | 5 | Vishay | x |  | all
R8 | 5.6K 0402 | 2304140030_YAGEO-RC0603JR-0710ML_C141675.pdf | 1 | Yageo | x |  | 1,2,3
R10,R11,R30 | 390k 0603 1% | 2304140030_YAGEO-RC0603JR-0710ML_C141675.pdf | 3 | Yageo | x |  | 1,2,3
R12,R17 | 150k 0603 | 2304140030_YAGEO-RC0603JR-0710ML_C141675.pdf | 2 | Yageo | x |  | 1,2,3
R13 | 12k 0603 | 2304140030_YAGEO-RC0603JR-0710ML_C141675.pdf | 1 | Yageo | x |  | 1,2,3
R14 | 680k 0603 | 2304140030_YAGEO-RC0603JR-0710ML_C141675.pdf | 1 | Yageo | x |  | 1,2,3
R18 | 10M 0603 | 50630577_YAGEO-AC0603FR-0710ML_C227547.pdf | 1 | Yageo | x |  | 1,2,3
R22,R23 | 27 0603 | 2304140030_YAGEO-RC0603JR-0710ML_C141675.pdf | 2 | Yageo | x |  | 1,2,3
R24 | 2M2 0603 | 2304140030_YAGEO-RC0603JR-0710ML_C141675.pdf | 1 | Yageo | x |  | 1,2,3
SW2,SW3 | EVQPUC02K | panasonic_rohs_2ma_2000379.pdf | 2 | Panasonic | x |  | all
SW_K_1-SW_K_36 | Kailh CPG151101S11-16 | 2208291600_Kailh-CPG151101S11-16_C5156480.pdf | 36 | Kailh | x |  | 1,2,9,10
U1,U2 | TLV62569DBVR | TexasTLV62569DBVR.pdf | 2 | TI | x |  | all
U3 | SY6280AAC | ROHS-2024-SilergyCorp.pdf | 1 | Silergy | x |  | 1,2,3,4,5,6,7,8,9,10,11
U4-U8 | 74HC595BQ | Nexperia - Statement on RoHS 20241008.pdf | 5 | Nexperia | x |  | all
U9 | BY25Q64ESCIG(R) | 2006180000_BOYAMICRO-BY25Q64ESCIG-R_C50176394.pdf | 1 | BOYAMICRO | x | was Winbond W25Q64JVXGIM / winbond-W25Q64JV-rohs.png; part changed 2026-08 | all
U10 | RP2040 | rp2040-rohs.png | 1 | Raspberry Pi | x |  | image
U11,U26 | TPD4E05U06DQAR | C2836386-TPD4E05U06DQAR-MS.pdf | 2 | MSKSEMI | x |  | 1,2,3
U12-U25 | 74AHC1G125GW,125 | Nexperia - Statement on RoHS 20241008.pdf | 14 | Nexperia | x |  | all
USB1,USB2 | TYPE-C-31-M-12 | 2410010003_Korean-Hroparts-Elec-TYPE-C-31-M-12_C165948.pdf | 2 | Hroparts | x |  | all
Y1 | 7M12000044 | TXC-7M12000044.pdf | 1 | TXC | x |  | 1,2,3

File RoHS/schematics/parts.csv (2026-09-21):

Reference | Value | Datasheet | Footprint | Qty | Manufacturer | RoHS
C1_1-C1_36 | 2.2uF 0603 25V | https://www.lcsc.com/datasheet/lcsc_datasheet_2304140030_Samsung-Electro-Mechanics-CL10A225KA8NNNC_C57895.pdf | Capacitor_SMD:C_0603_1608Metric | 36 | Samsung | x
C2,C3_1-C3_36,C5_1-C5_36,C6_1-C6_36,C24,C25,C30-C32 | 1uF 0402 16V | https://www.lcsc.com/datasheet/lcsc_datasheet_2304140030_Samsung-Electro-Mechanics-CL05A105KA5NQNC_C52923.pdf | Capacitor_SMD:C_0402_1005Metric | 114 | Samsung | x
C2_1-C2_36 | 2.2uF 0603 16V | https://www.lcsc.com/datasheet/lcsc_datasheet_2304140030_Samsung-Electro-Mechanics-CL10A225KO8NNNC_C23630.pdf | Capacitor_SMD:C_0603_1608Metric | 36 | Samsung | x
C3,C8 | 27pF 0402 16V | https://www.lcsc.com/product-detail/C86287.html | Capacitor_SMD:C_0402_1005Metric | 2 | Samsung | x
C4,C10 | 4.7uF 0805 25V | https://www.lcsc.com/datasheet/lcsc_datasheet_2304140030_Samsung-Electro-Mechanics-CL21A475KAQNNNE_C1779.pdf | Capacitor_SMD:C_0805_2012Metric | 2 | Samsung | x
C4_1-C4_36,C33,C34 | 4.7uF 3216 25V Tantalum | https://www.vishay.com/docs/40002/293d.pdf | poly_kb:CP_EIA-3216-18_Kemet-A | 38 | Vishay | x
C5,C11 | 6.8pF 0603 50V | https://wmsc.lcsc.com/wmsc/upload/file/pdf/v2/lcsc/2304140030_Samsung-Electro-Mechanics-CL10C6R8CB8NNNC_C318672.pdf | Capacitor_SMD:C_0603_1608Metric | 2 | Samsung | x
C6,C12-C14,C26 | 10uF 0805 16V | https://www.lcsc.com/datasheet/lcsc_datasheet_2304140030_Samsung-Electro-Mechanics-CL21A106KAYNNNE_C15850.pdf | Capacitor_SMD:C_0805_2012Metric | 5 | Samsung | x
C9,C15-C23 | 100nF 0402 16V | https://www.lcsc.com/datasheet/lcsc_datasheet_2304140030_Samsung-Electro-Mechanics-CL05B104KO5NNNC_C1525.pdf | Capacitor_SMD:C_0402_1005Metric | 10 | Samsung | x
D1 | Red 0805 C84256 | https://www.lcsc.com/datasheet/lcsc_datasheet_2409272203_Foshan-NationStar-Optoelectronics-NCD0805R1_C84256.pdf | LED_SMD:LED_0805_2012Metric | 1 | NationStar | x
D1_1-D1_36,D12 | 1N4148WSX | https://wmsc.lcsc.com/wmsc/upload/file/pdf/v2/lcsc/2405091035_Shenzhen-JingYang-1N4148WSX_C6423741.pdf | poly_kb:D_SOD-323Ext | 37 | Shenzhen JingYang | x
D2 | 1N5819WS | https://www.lcsc.com/datasheet/lcsc_datasheet_2204281430_Guangdong-Hottech-1N5819WS_C191023.pdf | poly_kb:D_SOD-323Ext | 1 | Hottech Semi | x
D5 | Green 0805 C2297 | https://www.lcsc.com/datasheet/C2297.pdf | LED_SMD:LED_0805_2012Metric | 1 | Hubei KENTO | x
D6 | Yellow 0805 C2296 | https://datasheet.lcsc.com/lcsc/1806151129_Hubei-KENTO-Elec-17-21SUYC-TR8_C2296.pdf | LED_SMD:LED_0805_2012Metric | 1 | Hubei KENTO | x
DBG1 | Conn_01x03_Male |  | Connector_PinHeader_2.54mm:PinHeader_1x03_P2.54mm_Vertical | 1
DBG3 | DebugPort | ~ | Connector_PinHeader_2.54mm:PinHeader_1x10_P2.54mm_Vertical | 1
FB1,FB2 | GZ2012D601TF | https://www.lcsc.com/datasheet/lcsc_datasheet_2310301640_Sunlord-GZ2012D601TF_C1017.pdf | Inductor_SMD:L_0805_2012Metric | 2 | Sunlord | x
H1-H9 | MountingHole_Pad | ~ | MountingHole:MountingHole_3mm_Pad_Via | 9
J1-J36 | FH34SRJ-14S-0.5SH | https://datasheet.lcsc.com/lcsc/1811071030_HRS-Hirose-FH34SRJ-14S-0-5SH-50_C324724.pdf | poly_kb:FH34SRJ14S05SH50-Rev2 | 36 | JUSHUO | Both x
J37 | FH34SRJ-12S-0.5SH | https://datasheet.lcsc.com/lcsc/1912111437_HRS-Hirose-FH34SRJ-12S-0-5SH-50_C424659.pdf | poly_kb:FH34SRJ12S05SH50-Rev2 | 1 | Hirose | x
J38 | Conn_01x05 |  | Connector_PinHeader_2.54mm:PinHeader_1x05_P2.54mm_Vertical | 1
J39 | FH12-30S-0.5SH | https://datasheet.lcsc.com/lcsc/2004261434_HRS-Hirose-FH12-30S-0-5SH-55_C506793.pdf | Connector_FFC-FPC:Hirose_FH12-30S-0.5SH_1x30-1MP_P0.50mm_Horizontal | 1 | Hirose | x
JP1 | CurrentLimitBypass | ~ | Jumper:SolderJumper-3_P1.3mm_Bridged12_RoundedPad1.0x1.5mm | 1
L1,L2 | 2.2uH | https://www.lcsc.com/datasheet/lcsc_datasheet_2108131530_SXN-Shun-Xiang-Nuo-Elec-SMMS0420-2R2M_C133191.pdf | poly_kb:SMMS0420-2R2M | 2 | SXN | x
LED1-LED36 | XL-3030RGBC | https://datasheet.lcsc.com/lcsc/2301111010_XINGLIGHT-XL-3030RGBC-WS2812B_C5349958.pdf | poly_kb:XL-3030RGBC-WS2812B | 36 | Xinglight | x
R1,R2 | 22 0603 | https://www.lcsc.com/datasheet/lcsc_datasheet_2304140030_YAGEO-RC0603JR-0722RL_C108405.pdf | Resistor_SMD:R_0603_1608Metric | 2 | Yageo | x
R1_1-R1_36,R15,R20,R25 | 10k 0402 | https://www.lcsc.com/datasheet/lcsc_datasheet_2304140030_YAGEO-RC0402FR-0710KL_C60490.pdf | Resistor_SMD:R_0402_1005Metric | 39 | Yageo | x
R3,R4,R7,R9 | 5.1K 0402 | https://www.lcsc.com/datasheet/lcsc_datasheet_2304140030_YAGEO-AC0402FR-075K1L_C144745.pdf | Resistor_SMD:R_0402_1005Metric | 4 | Yageo | x
R5,R6,R16,R19,R21 | 1k 0402 | https://www.vishay.com/docs/20035/dcrcwe3.pdf | Resistor_SMD:R_0402_1005Metric | 5 | Vishay | x
R8 | 5.6K 0402 | https://www.lcsc.com/datasheet/lcsc_datasheet_2304140030_YAGEO-RC0402FR-075K6L_C163457.pdf | Resistor_SMD:R_0402_1005Metric | 1 | Yageo | x
R10,R11,R30 | 390k 0603 1% | https://www.lcsc.com/datasheet/C137735.pdf | Resistor_SMD:R_0603_1608Metric | 3 | Yageo | x
R12,R17 | 150k 0603 | https://www.lcsc.com/datasheet/lcsc_datasheet_2304140030_YAGEO-RC0603FR-07150KL_C114660.pdf | Resistor_SMD:R_0603_1608Metric | 2 | Yageo | x
R13 | 12k 0603 | https://www.lcsc.com/datasheet/lcsc_datasheet_2304140030_YAGEO-RC0603FR-0712KL_C114659.pdf | Resistor_SMD:R_0603_1608Metric | 1 | Yageo | x
R14 | 680k 0603 | https://www.lcsc.com/datasheet/lcsc_datasheet_2304140030_YAGEO-RC0603FR-07680KL_C137690.pdf | Resistor_SMD:R_0603_1608Metric | 1 | Yageo | x
R18 | 10M 0603 | https://www.lcsc.com/datasheet/C227547.pdf | Resistor_SMD:R_0603_1608Metric | 1 | Yageo | x
R22,R23 | 27 0603 | https://www.lcsc.com/datasheet/lcsc_datasheet_2304140030_YAGEO-RC0603FR-0727RL_C137753.pdf | Resistor_SMD:R_0603_1608Metric | 2 | Yageo | x
R24 | 2M2 0603 | https://www.lcsc.com/datasheet/lcsc_datasheet_2304140030_YAGEO-RC0603FR-072M2L_C137747.pdf | Resistor_SMD:R_0603_1608Metric | 1 | Yageo | x
SW1 | RotaryEncoder_Switch | ~ | poly_kb:PolyJog | 1
SW2,SW3 | EVQPUC02K | https://www.lcsc.com/datasheet/lcsc_datasheet_2304140030_PANASONIC-EVQPUC02K_C79174.pdf | Button_Switch_SMD:Panasonic_EVQPUL_EVQPUC | 2 | Panasonic | x
SW_K_1-SW_K_36 | Kailh CPG151101S11-16 | ~ | poly_kb:Kailh_socket_MX_Indicators | 36 | Kailh | x
TP1 | USB_D- | ~ | TestPoint:TestPoint_Pad_D1.5mm | 1
TP14 | USB_D+ | ~ | TestPoint:TestPoint_Pad_D1.5mm | 1
U1,U2 | TLV62569DBVR | https://www.lcsc.com/datasheet/lcsc_datasheet_1809251629_Texas-Instruments-TLV62569DBVR_C141836.pdf | Package_TO_SOT_SMD:SOT-23-5 | 2 | TI | x
U3 | SY6280AAC | https://www.lcsc.com/datasheet/lcsc_datasheet_1810121532_Silergy-Corp-SY6280AAC_C55136.pdf | Package_TO_SOT_SMD:SOT-23-5 | 1 | Silergy | x
U4-U8 | 74HC595BQ | https://assets.nexperia.com/documents/data-sheet/74HC_HCT595.pdf | poly_kb:Nexperia 74HC595BQ DHVQFN16 | 5 | Nexperia | x
U9 | BY25Q64ESCIG(R) | https://www.lcsc.com/product-detail/C50176394.html | poly_kb:BY25Q64ES-LGA8-2x3 | 1 | BOYAMICRO | x
U10 | RP2040 | https://datasheet.lcsc.com/lcsc/2201101600_Raspberry-Pi-RP2040_C2040.pdf | poly_kb:RP2040-QFN-56 | 1 | Raspberry Pi | x
U11,U26 | TPD4E05U06DQAR | https://msksemi.com/web/userfiles/productfile/C2836386TPD4E05U06DQAR-MS.pdf | poly_kb:USON-10 | 2 | MSKSEMI | x
U12-U25 | 74AHC1G125GW,125 | https://assets.nexperia.com/documents/data-sheet/74AHC_AHCT1G125.pdf | poly_kb:SOT-353_SC-70-5_Slim | 14 | Nexperia | x
USB1,USB2 | TYPE-C-31-M-12 | https://datasheet.lcsc.com/lcsc/2205251630_Korean-Hroparts-Elec-TYPE-C-31-M-12_C165948.pdf | EnvUSB:HRO-TYPE-C-31-M-12-Assembly | 2 | Hroparts | x
Y1 | 7M12000044 | https://www.lcsc.com/datasheet/lcsc_datasheet_1810171130_TXC-Corp-7M12000044_C93114.pdf | Crystal:Crystal_SMD_3225-4Pin_3.2x2.5mm | 1 | TXC | x

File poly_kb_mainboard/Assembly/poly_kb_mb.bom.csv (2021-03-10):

Designator | Quantity | Value | Footprint | LCSC Part # | Comment
C1, C2, C3, C4 | 4 | 1u | C_0402_1005Metric | C52923 | Unpolarized capacitor, small symbol
C5 | 1 | 10n | C_0402_1005Metric | C15195 | Unpolarized capacitor, small symbol
C6 | 1 | 4u7 | C_0603_1608Metric | C19666 | Unpolarized capacitor, small symbol
C7, C8, C9, C10, C11, C12, C13 | 7 | 100n | C_0402_1005Metric | C1525 | Unpolarized capacitor, small symbol
C14, C15 | 2 | 2u2 | C_0603_1608Metric | C23630 | Unpolarized capacitor, small symbol
C16, C17 | 2 | 12p | C_0402_1005Metric | C1547 | Unpolarized capacitor, small symbol
D1 | 1 | Reset | LED_0603_1608Metric | C72041 | Light emitting diode, small symbol
D2 | 1 | Status | LED_0603_1608Metric | C72043 | Light emitting diode, small symbol
D3 | 1 | Power | LED_0603_1608Metric | C2286 | Light emitting diode, small symbol
F1 | 1 | 2A | Fuse_1206_3216Metric | C70085 | Resettable fuse, polymeric positive temperature coefficient, small symbol
FB1, FB2 | 2 | 600 @ 600 MHz | L_0805_2012Metric | C1017 | Ferrite bead, small symbol
J1 | 1 | SWD | SIDE-SWD | C225520 | Generic connector, double row, 02x05, odd/even pin numbering scheme (row 1 odd numbers, row 2 even numbers), script generated (kicad-library-utils/schlib/autogen/connector/)
J2 | 1 | USB_C_Receptacle_USB2.0 | USB_C_Receptacle_HRO_TYPE-C-31-M-12 | C165948 | "USB 2.0-only Type-C Receptacle connector"
J3 | 1 | Left | PinHeader_2x06_P2.54mm_Vertical | C225521 | Generic connector, double row, 02x06, top/bottom pin numbering scheme (row 1: 1...pins_per_row, row2: pins_per_row+1 ... num_pins), script generated (kicad-library-utils/schlib/autogen/connector/)
J4 | 1 | Right | PinHeader_1x12_P2.54mm_Vertical | C225487 | Generic connector, single row, 01x12, script generated (kicad-library-utils/schlib/autogen/connector/)
J5 | 1 | USART2 | PinHeader_2x04_P2.54mm_Vertical | C541854 | Generic connector, double row, 02x04, odd/even pin numbering scheme (row 1 odd numbers, row 2 even numbers), script generated (kicad-library-utils/schlib/autogen/connector/)
J6 | 1 | I2C1 | PinHeader_1x04_P2.54mm_Vertical | C225501 | Generic connector, single row, 01x04, script generated (kicad-library-utils/schlib/autogen/connector/)
J7 | 1 | Bottom | PinHeader_2x20_P2.54mm_Vertical | C124383 | Generic connector, double row, 02x20, counter clockwise pin numbering scheme (similar to DIP packge numbering), script generated (kicad-library-utils/schlib/autogen/connector/)
J8 | 1 | Conn_01x02 | PinHeader_1x02_P2.54mm_Vertical | C464599 | Generic connector, single row, 01x02, script generated (kicad-library-utils/schlib/autogen/connector/)
R1, R3 | 2 | 100k | R_0402_1005Metric | C25741 | Resistor, small symbol
R2, R14, R15 | 3 | 10k | R_0402_1005Metric | C25744 | Resistor, small symbol
R4, R5, R8, R9 | 4 | 22 | R_0402_1005Metric | C25092 | Resistor, small symbol
R6, R7, R12 | 3 | 1k5 | R_0402_1005Metric | C25867 | Resistor, small symbol
R10, R11 | 2 | 5k1 | R_0402_1005Metric | C25905 | Resistor, small symbol
R13 | 1 | 47 | R_0402_1005Metric | C25118 | Resistor, small symbol
SW1 | 1 | Boot0 | SW_SPST_B3U-3000P-B | C963349 | "Single Pole Single Throw (SPST) switch"
SW2 | 1 | Boot1 | SW_SPST_B3U-3000P-B | C963349 | "Single Pole Single Throw (SPST) switch"
SW3 | 1 | Reset | SW_SPST_B3U-3000P-B | C963349 | "Single Pole Single Throw (SPST) switch"
U1 | 1 | XC6206P332MR | SOT-23 | C5446 | Positive 60-250mA Low Dropout Regulator, Fixed Output, SOT-23
U2 | 1 | STM32F407VETx | LQFP-100_14x14mm_P0.5mm | C28730 | ARM Cortex-M4 MCU, 512KB flash, 128KB RAM, 168MHz, 1.8-3.6V, 82 GPIO, LQFP-100
U3 | 1 | W25N01GVZEIG | W25N01GVZEIG | C88868
Y1 | 1 | 16MHz | Crystal_SMD_3225-4Pin_3.2x2.5mm | C13738 | Four pin crystal, GND on pins 2 and 4, small symbol

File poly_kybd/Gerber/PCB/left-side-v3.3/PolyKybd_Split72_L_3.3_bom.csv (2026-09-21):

Designator | Footprint | Quantity | Value | LCSC Part #
C10, C4 | 0805 | 2 | 4.7uF 0805 25V | C1779
C11, C5 | 0603 | 2 | 6.8pF 0603 50V | C318672
C12, C13, C14, C26, C6 | 0805 | 5 | 10uF 0805 16V | C15850
C15, C16, C17, C18, C19, C20, C21, C22, C23, C9 | 0402 | 10 | 100nF 0402 16V | C1525
C1_1, C1_10, C1_11, C1_12, C1_13, C1_14, C1_15, C1_16, C1_17, C1_18, C1_19, C1_2, C1_20, C1_21, C1_22, C1_23, C1_24, C1_25, C1_26, C1_27, C1_28, C1_29, C1_3, C1_30, C1_31, C1_32, C1_33, C1_34, C1_35, C1_36, C1_4, C1_5, C1_6, C1_7, C1_8, C1_9 | 0603 | 36 | 2.2uF 0603 25V | C57895
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

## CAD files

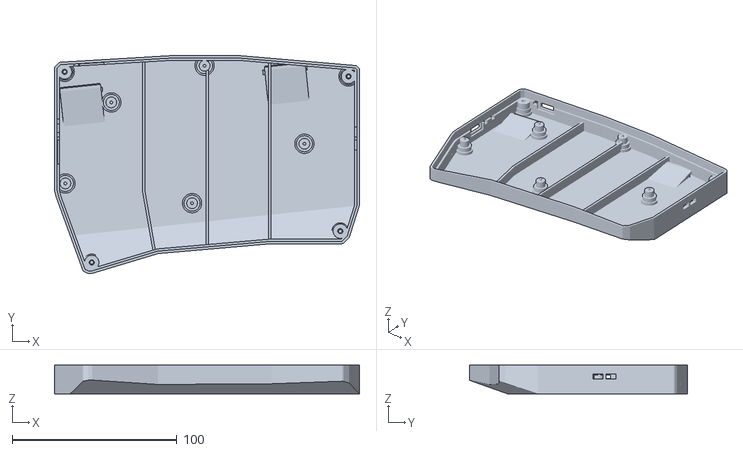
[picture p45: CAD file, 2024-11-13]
case/case_polysplit72_pom.stl
185.3 x 132.3 x 17.5

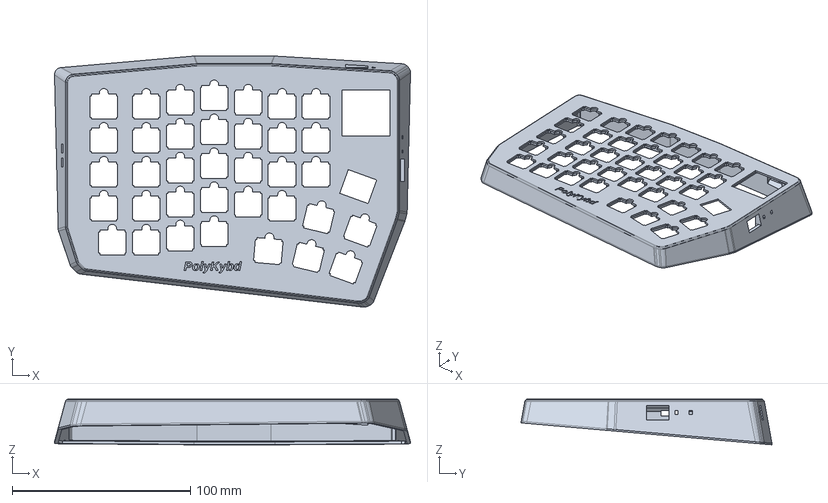
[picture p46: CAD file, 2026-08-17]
parts/export/case/metal-case-left.step
199.7 x 140.7 x 25.6 mm

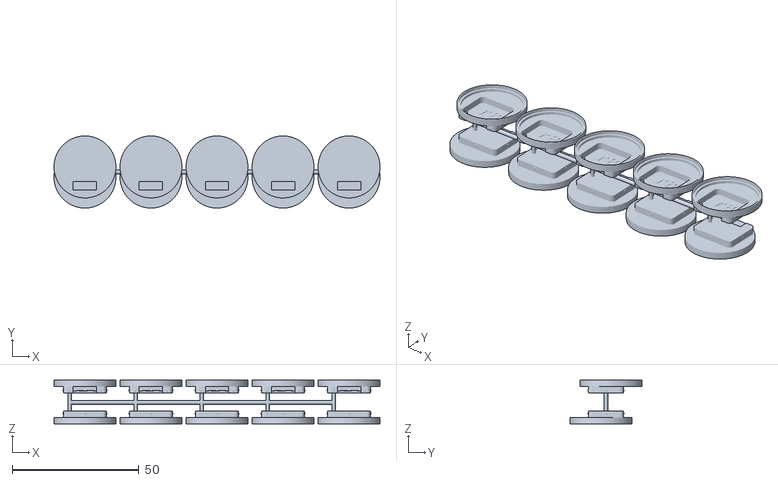
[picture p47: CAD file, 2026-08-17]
parts/export/cirque_insert/cirque23_insert_r8_10p.stl
128.4 x 28.4 x 17.3

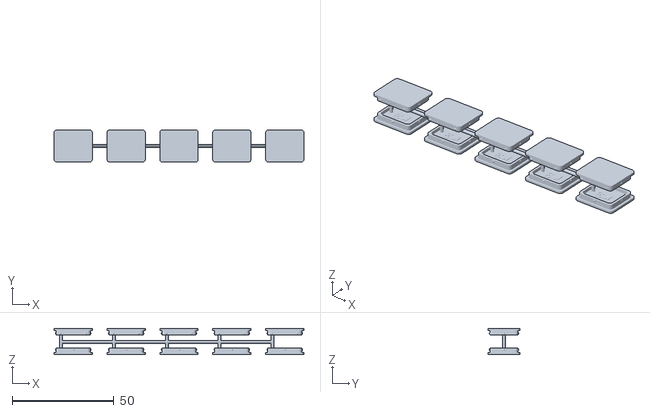
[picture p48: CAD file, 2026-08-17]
parts/export/cover_insert/cover_insert_r3_10p.stl
122.9 x 15.9 x 12.9

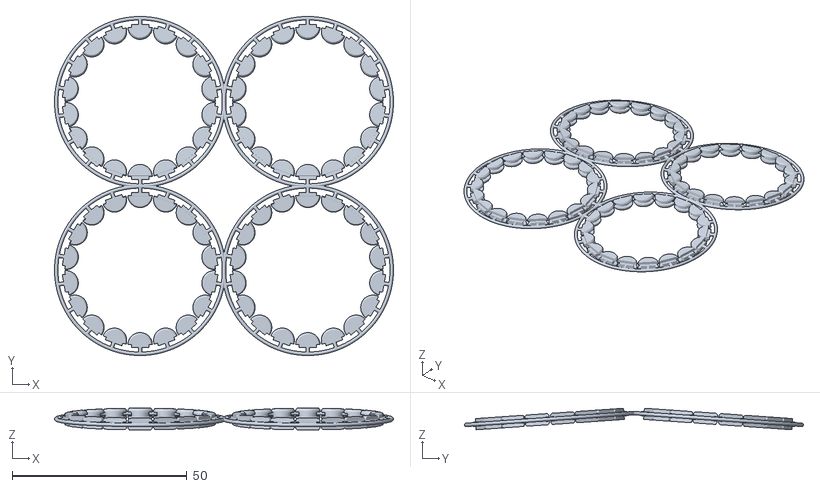
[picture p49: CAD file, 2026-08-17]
parts/export/diffuser/diff_v2.stl
97.0 x 97.0 x 6.17

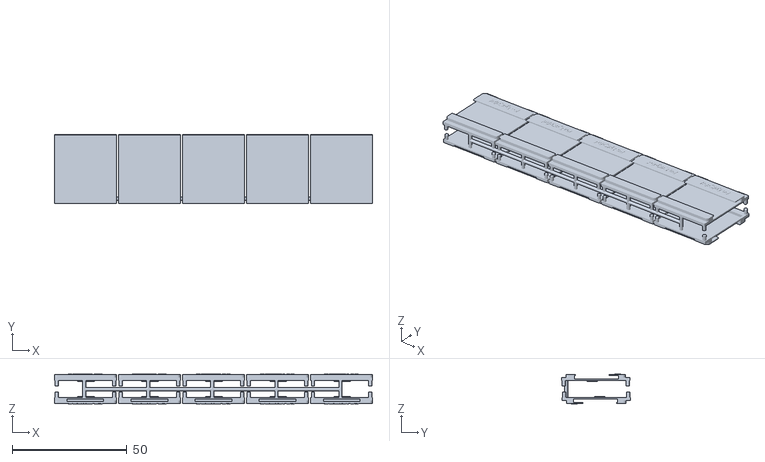
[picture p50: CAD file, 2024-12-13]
parts/export/display_holder/display_holder_10p.stl
138.8 x 30.1 x 13.0

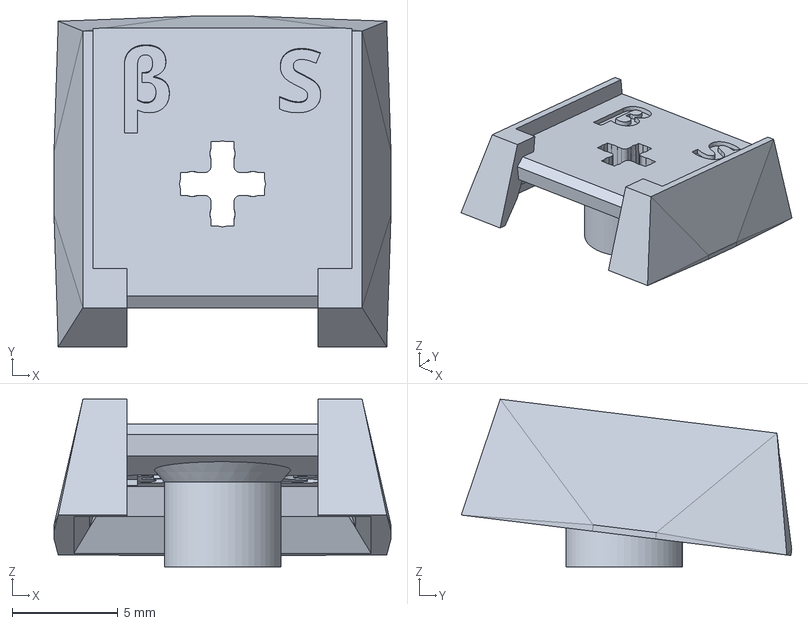
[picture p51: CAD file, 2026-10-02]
parts/export/keycap_stem/stem_S_1U.step
15.9 x 15.6 x 7.91 mm

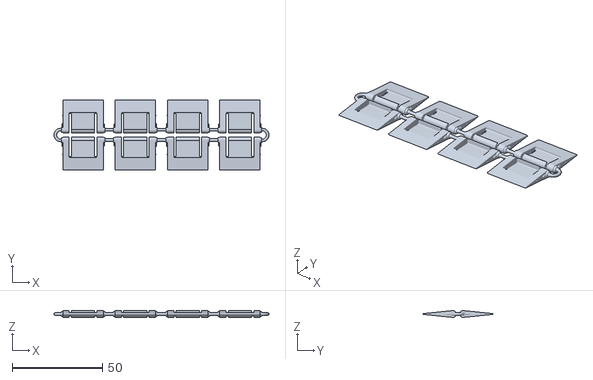
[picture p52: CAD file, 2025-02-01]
parts/export/legs/legs_r2_8p.stl
119.3 x 38.7 x 3.80

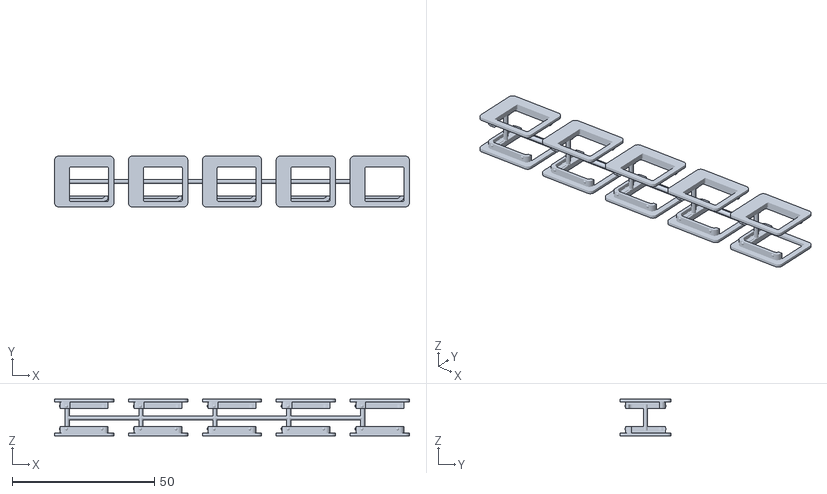
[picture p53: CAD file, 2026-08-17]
parts/export/rotary_enc_insert/rotary_enc_insert_r1_10p.stl
124.9 x 17.9 x 12.9

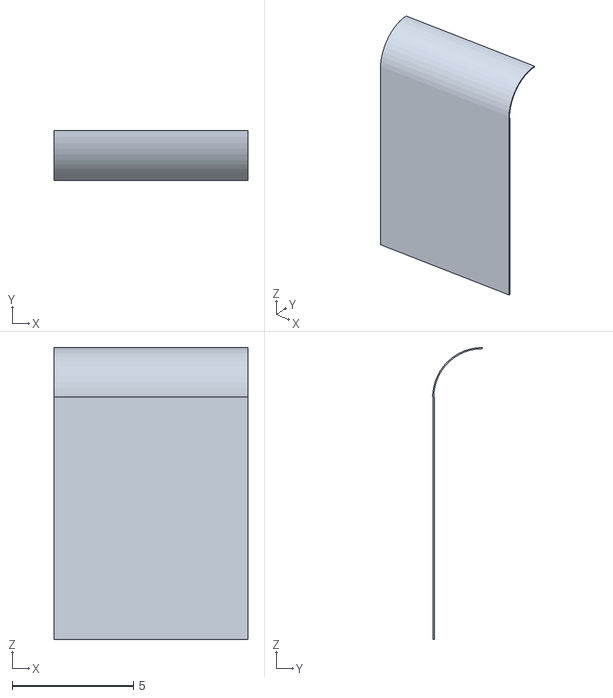
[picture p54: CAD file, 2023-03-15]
parts/models/keycap_display_cable.stl
8.00 x 2.05 x 12.0

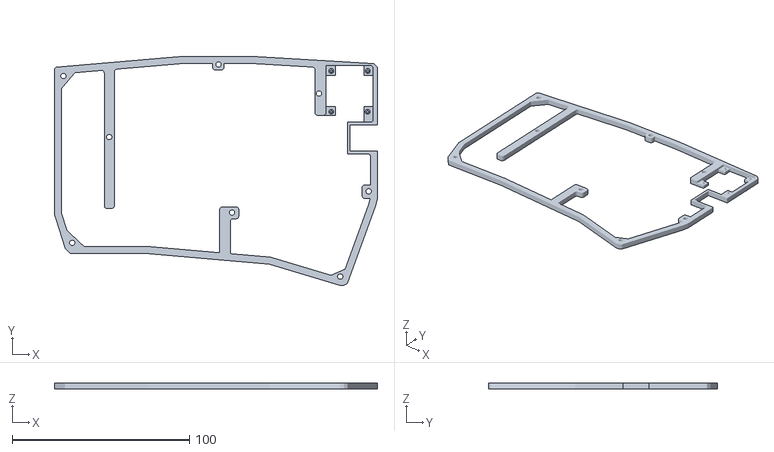
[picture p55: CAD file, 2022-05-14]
poly_kybd/wave-plat=pcb-spacer-left.stl
182.0 x 129.0 x 3.50

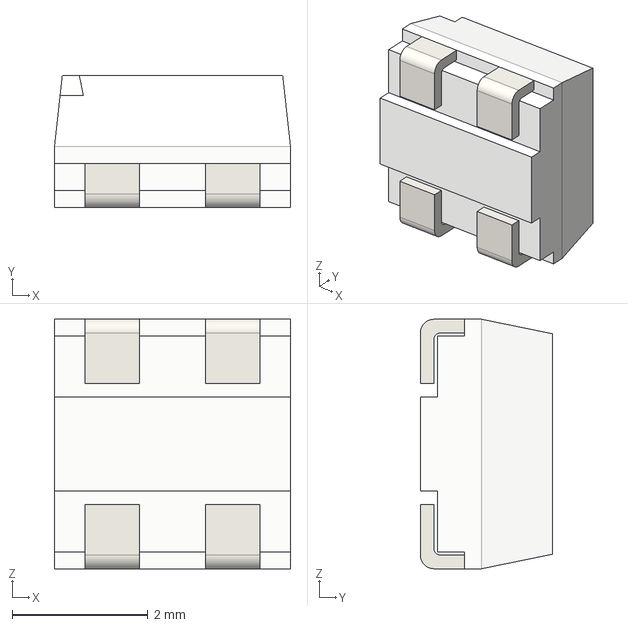
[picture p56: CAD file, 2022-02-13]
poly_kybd/WS2812B-Mini/WS2812B-Mini.step
3.48 x 1.95 x 3.68 mm

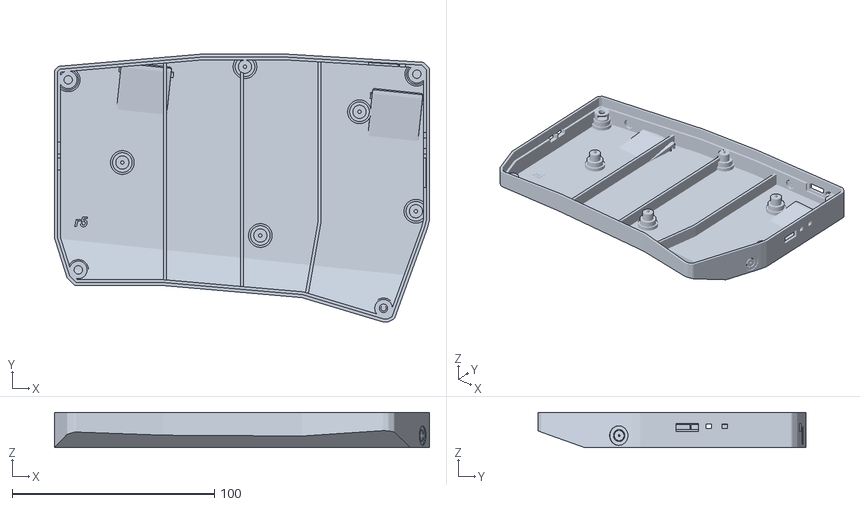
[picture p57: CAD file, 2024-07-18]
case/case_polysplit72_left2_r5_noinfill.stl
185.5 x 132.5 x 17.5

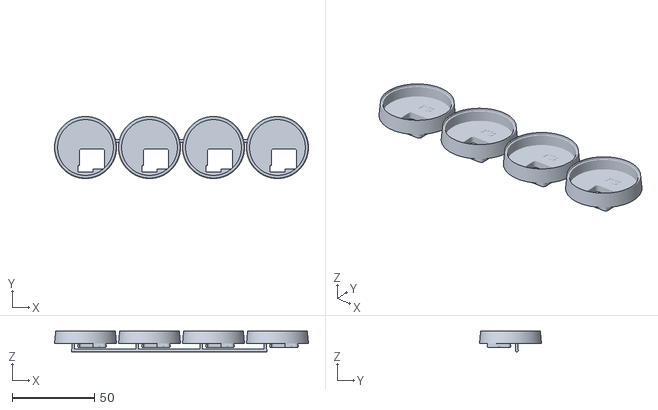
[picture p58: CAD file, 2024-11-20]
parts/export/cirque_insert/cirque35_insert_r3_4p.stl
154.8 x 37.8 x 12.7

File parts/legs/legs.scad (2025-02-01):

// PolyKybd Leg, based on:
// https://www.thingiverse.com/thing:2132775/files
// https://creativecommons.org/licenses/by-nc-sa/4.0/

// The knobs will require supports, and the round ends may need supports depending on the printer and material

//CUSTOMIZER VARIABLES

/* [Basic_Parameters] */

// Body width (not including nobs), in mm
body_width = 22.4;  // [10:0.1:80]

// Full length, in mm
full_length = 20.0;  // [10:0.1:80]

// Full height/thickness, in mm
full_height = 3.8;  // [2:0.1:20]

end_height = 0.5;  // [2:0.1:20]

// Interior height/thickness, in mm
interior_height = 1.7;  // [2:0.1:20]

// Top lip length, in mm
top_lip_length = 2.5;  // [0:0.1:20]

// Bottom lip length, in mm
bottom_lip_length = 9.0;  // [0:0.1:20]

// Arm width, in mm
arm_width = 3.5;  // [1:0.1:20]

// Arm gap width, in mm
arm_gap_width = 1.25;  // [0:0.1:20]

// Arm gap length, in mm
arm_gap_length = 11;  // [0:0.1:20]

// Knob diameter, in mm
knob_diameter = 3;  // [0:0.05:20]
knob_small_diameter = 2.75;

// Knob length, in mm
knob_length = 0.9;  // [0:0.05:20]

// Knob inset from end, in mm
knob_inset = full_height/2;  // [0:0.05:20]

// Font
text_font = "Arial:style=Bold Italic";

//CUSTOMIZER VARIABLES END



// Sanity checks

if ( (2*arm_gap_width + 2*arm_width) >= body_width)
{
    echo("<B>Error: Arms too wide for body</B>");
}

if ((top_lip_length + bottom_lip_length) > full_length)
{
    echo("<B>Error: Body too short</B>");
}


//keyboard_leg();
connected_8p();

// our object, flat on xy plane for easy STL generation
module connected_8p() {
union(){
keyboard_leg();

translate([body_width,-2,0]) rotate([0,0,180]) keyboard_leg();
for(i =[1 : 3]) {
    translate([i*29,0,0]) keyboard_leg();
    translate([i*29+body_width,-2,0]) rotate([0,0,180]) keyboard_leg();
    translate([i*29-6,1.9,1.9]) rotate([0,90,0])
              cylinder(6, 0.75, 0.75, $fn=32 );
    translate([i*29-6,-3.8,1.9]) rotate([0,90,0])
              cylinder(6, 0.75, 0.75, $fn=32 );
}

translate([-1.2, -1, 1.9])
intersection() {
rotate_extrude(convexity=10, $fn=128)
    translate([3, 0, 0])
        circle(r=0.75, $fn=32);
translate([-4.5,0,0])cube([10,10,10], center=true);
}

translate([4*29-5.4, -1, 1.9])
intersection() {
rotate_extrude(convexity=10, $fn=128)
    translate([3, 0, 0])
        circle(r=0.75, $fn=32);
translate([4.5,0,0])cube([10,10,10], center=true);
}
}
}

module keyboard_leg() { 
    
    knob_radius = knob_diameter / 2;
    round_diameter = full_height;
    round_radius = round_diameter / 2;
    interior_length = full_length - top_lip_length - bottom_lip_length;

    difference() {

        union() {
          
          // the main block
          //translate([0,round_radius,0])
            //cube([body_width,full_length-2*round_radius,full_height]);
          
          // round end on bottom of leg
            hull() {
          translate([0,full_length-round_radius,round_radius])
            rotate([0,90,0])
              cylinder(body_width, end_height/2, end_height/2, $fn=32 );
          
          // round end on top of leg
          translate([0,round_radius,round_radius])
            rotate([0,90,0])
              cylinder(body_width, round_radius, round_radius, $fn=32 );
            }
          // knobs on arms
          translate([-knob_length,knob_inset,full_height/2])
            rotate([0,90,0])
              cylinder(knob_length, knob_small_diameter/2, knob_radius, $fn=32 );
          translate([body_width,knob_inset,full_height/2])
            rotate([0,90,0])
              cylinder(knob_length, knob_radius, knob_small_diameter/2, $fn=32 );
        
            translate([0,knob_inset,full_height/2])
            rotate([-90,0,0]) {
              cylinder(h=3, r=0.6, $fn=32 );
              translate([0,0,3]) sphere(r=0.6,$fn=32);
            }
            translate([body_width,knob_inset,full_height/2])
            rotate([-90,0,0]) {
              cylinder(h=3, r=0.6, $fn=32 );
              translate([0,0,3]) sphere(r=0.6,$fn=32);
            }
            
          // notches on arms
          translate([0.1,knob_inset+7.9,full_height/2-0.25])
            rotate([0,90,0])
              sphere(0.3, $fn=32 );
          translate([body_width-0.1,knob_inset+7.9,full_height/2-0.25])
            rotate([0,90,0])
              sphere(0.3, $fn=32 );
        }

        // main block hollow interior
        hollow_height = full_height - interior_height;
        hollow_y = full_length - interior_length;
        hollow_width = body_width - 2*arm_width;
        translate([arm_width,top_lip_length,interior_height])
        hull(){
            translate([0.5,0,0.5])sphere(0.5, $fn=32);
            translate([hollow_width-0.5,0,0.5]) sphere(0.5, $fn=32);
            translate([0.5,interior_length,0.5]) sphere(0.5, $fn=32);
            translate([hollow_width-0.5,interior_length,0.5]) sphere(0.5, $fn=32);
            translate([0.5,0,hollow_height+2]) sphere(0.5, $fn=32);
            translate([hollow_width-0.5,0,hollow_height+2]) sphere(0.5, $fn=32);
            translate([0.5,interior_length,hollow_height+2]) sphere(0.5, $fn=32);
            translate([hollow_width-0.5,interior_length,hollow_height+2]) sphere(0.5, $fn=32);
        }
        //cube([hollow_width,interior_length,hollow_height+2]);
        
        // arm gaps
        translate([arm_width,-2,-1])
          cube([arm_gap_width,arm_gap_length+2,full_height+2]);
        translate([body_width - arm_width - arm_gap_width,-2,-1])
          cube([arm_gap_width,arm_gap_length+2,full_height+2]);
        /*
        translate([body_width/2,7,1.5])
        linear_extrude(height = 1)
        {
            text("r1", size = 4, font = text_font, halign = "center", valign = "center", $fn = 16);
        }
        */

    }
}

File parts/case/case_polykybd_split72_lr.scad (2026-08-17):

pcb_outline = "poly_kb_wave_right2-OUTLINE.svg";
drill_holes = "poly_kb_wave_right2-SCREW.svg";
standoffs_pos = "poly_kb_wave_right2-STANDOFF.svg";
led_holes = "poly_kb_wave_right2-LED.svg";
switch_holes = "poly_kb_wave_right2-SW.svg";
usb_port_holes = "poly_kb_wave_right2-USB.svg";
usb_clearance = "poly_kb_wave_right2-USB-extra.svg";
wedge_shape = "poly_kb_wave_right2-WD.svg";
nuts_ins = "poly_kb_wave_right2-NutsInserts.svg";
nuts = "poly_kb_wave_right2-Nuts.svg";

// one-piece LED diffuser frame — provides diffuser_frame_left_clearance(),
// which right_spacer() subtracts so its ribs are notched where the web crosses
use <../diffuser/diffuser_frame_left.scad>

case_height = 17.5;
case_wall_thickness = 1.5;
case_bottom_thickness = 2;
pcb_clearance = 0.15;
pcb_edge_height = 9.5;
pcb_edge_width = 1.4;
stand_off_extra_radius = 2.3;

text_font = "Arial:style=Bold Italic";
text_size = 12;
text_height = 0.35;
revision = "r1.7";
spacer_revision = "r1.1";
name = "PolyKybd";
model_name = "Split72";

module standoffs(file)
{
    linear_extrude(height = 4, scale = 1) offset(r = stand_off_extra_radius + 2, $fn = 50)
        import(file = file, dpi = 300);

    linear_extrude(height = 7, scale = 1) offset(r = stand_off_extra_radius + 1.2, $fn = 50)
        import(file = file, dpi = 300);
    difference()
    {
        linear_extrude(height = pcb_edge_height + case_bottom_thickness, scale = 1)
            offset(r = stand_off_extra_radius + 0.5, $fn = 50) import(file = file, dpi = 300);

        // actual holes
        linear_extrude(height = pcb_edge_height + case_bottom_thickness, scale = 1) offset(r = 0.5, $fn = 50)
            import(file = file, dpi = 300);
        translate([ 0, 0, 10.5 ]) linear_extrude(height = 1, scale = 1) import(file = file, dpi = 300);
    }
}

module nuts_inserts(file1, file2)
{
    color([ 1, 0, 0 ]) translate([ 2.6, 9.25, 8.1 ])
    {
        linear_extrude(height = 2.55, scale = 1)
            offset(r = 0.025, $fn = 50)
                import(file = file1, dpi = 300);
        translate([ 0, 0, -0.4 ])
            linear_extrude(height = 1, scale = 1)
                import(file = file2, dpi = 300);
    }
}

module standoffs_holes(file)
{
    // actual holes
    translate([ 0, 0, pcb_edge_height - 2.2 ]) linear_extrude(height = 2.2, scale = 1) offset(r = -0.225, $fn = 50)
        import(file = file, dpi = 300);
}

module pcb_standoffs(file)
{
    linear_extrude(height = 4, scale = 1) offset(r = stand_off_extra_radius + 2, $fn = 50)
        import(file = file, dpi = 300);
    linear_extrude(height = 7, scale = 1) offset(r = stand_off_extra_radius + 1, $fn = 50)
        import(file = file, dpi = 300);
    linear_extrude(height = pcb_edge_height + case_bottom_thickness, scale = 1)
        offset(r = stand_off_extra_radius - 0.6, $fn = 50) import(file = file, dpi = 300);
    linear_extrude(height = pcb_edge_height + case_bottom_thickness + 1.5, scale = 1) offset(r = -0.7, $fn = 50)
        import(file = file, dpi = 300);
}

module tentingHole()
{
    difference()
    {
        cylinder(h = 10, r1 = 2.98, r2 = 2.98, center = false, $fn = 64);
        union()
        {
            cylinder(h = 10, r1 = 2.5, r2 = 2.5, center = false, $fn = 64);
            cube([ 0.5, 10, 10 ], true);
            cube([ 10, 0.5, 10 ], true);
        }
    }
    translate([ 0, 0, 2 ]) cylinder(h = 3, r1 = 2.98, r2 = 2.98, center = false, $fn = 64);
    cylinder(h = 10, r1 = 0.5, r2 = 0.25, center = false, $fn = 64);
    cylinder(h = 1, r1 = 4.8, r2 = 4.85, center = false, $fn = 64);
}

module tentingHoles()
{
    translate([ 0, 0, 6 ]) rotate([ 90, 0, 110 ]) tentingHole();
    translate([ 40, 91.5, 6 ]) rotate([ 90, 0, 0 ]) tentingHole();
    translate([ 160, 89, 6 ]) rotate([ 90, 0, 0 ]) tentingHole();
    
    translate([17,83.5,0]) cylinder(r=3.25, h=0.65, center = false, $fn = 64);
    translate([167,80,0]) cylinder(r=3.25, h=0.65, center = false, $fn = 64);
    translate([175.5,7,0]) cylinder(r=3.25, h=0.65, center = false, $fn = 64);
    translate([11,-10,0]) cylinder(r=3.25, h=0.65, center = false, $fn = 64);
}

module branding(mirror_text)
{
    if (mirror_text)
    {
        translate([ 92, 85, 0 ]) mirror(v = [ 1, 0, 0 ]) linear_extrude(height = text_height)
        {
            text(name, size = text_size, font = text_font, halign = "center", valign = "center", $fn = 50);
        }
        translate([ 56, 77, 0 ]) mirror(v = [ 1, 0, 0 ]) linear_extrude(height = text_height)
        {
            text(model_name, size = 5, font = text_font, halign = "center", valign = "center", $fn = 50);
        }
        translate([ 178, 89.8, 0 ]) mirror(v = [ 1, 0, 0 ]) linear_extrude(height = text_height)
        {
            text("Limit", size = 2.5, font = text_font, halign = "center", valign = "center", $fn = 50);
        }
        translate([ 181, 98, 0 ]) mirror(v = [ 1, 0, 0 ]) linear_extrude(height = text_height)
        {
            text("V", size = 2.5, font = text_font, halign = "center", valign = "center", $fn = 50);
        }
        translate([ 171, 127, 0 ]) mirror(v = [ 1, 0, 0 ]) rotate([0,0,90]) linear_extrude(height = text_height)
        {
            text("Power", size = 2.5, font = text_font, halign = "center", valign = "center", $fn = 50);
        }
        translate([ 5, 84, 0 ]) mirror(v = [ 1, 0, 0 ]) linear_extrude(height = text_height)
        {
            text("Boot", size = 2.5, font = text_font, halign = "center", valign = "center", $fn = 50);
        }
        translate([ 5.5, 91.5, 0 ]) mirror(v = [ 1, 0, 0 ]) linear_extrude(height = text_height)
        {
            text("Reset", size = 2.5, font = text_font, halign = "center", valign = "center", $fn = 50);
        }
    }
    else
    {
        translate([ 92, 85, 0 ]) linear_extrude(height = text_height)
        {
            text(name, size = text_size, font = text_font, halign = "center", valign = "center", $fn = 50);
        }
        translate([ 128, 77, 0 ]) linear_extrude(height = text_height)
        {
            text(model_name, size = 5, font = text_font, halign = "center", valign = "center", $fn = 50);
        }
        translate([ 178, 89.8, 0 ]) linear_extrude(height = text_height)
        {
            text("Limit", size = 2.5, font = text_font, halign = "center", valign = "center", $fn = 50);
        }
        translate([ 181, 98, 0 ]) linear_extrude(height = text_height)
        {
            text("V", size = 2.5, font = text_font, halign = "center", valign = "center", $fn = 50);
        }
        translate([ 171, 127, 0 ]) rotate([0,0,90]) linear_extrude(height = text_height)
        {
            text("Power", size = 2.5, font = text_font, halign = "center", valign = "center", $fn = 50);
        }
        translate([ 5, 84, 0 ]) linear_extrude(height = text_height)
        {
            text("Boot", size = 2.5, font = text_font, halign = "center", valign = "center", $fn = 50);
        }
        translate([ 5.5, 91.5, 0 ]) linear_extrude(height = text_height)
        {
            text("Reset", size = 2.5, font = text_font, halign = "center", valign = "center", $fn = 50);
        }
    }
}

module right_side_shrink_protection()
{
    intersection()
    {
        translate([ 0, 0, case_height - 1.2 ])
        {
            linear_extrude(height = 1.2, scale = 1) offset(r = pcb_clearance, $fn = 128)
                import(file = pcb_outline, dpi = 300);
        }
        /* translate([0,0,case_height-1.2 + 18]) {
             for ( y = [0 : 10] ){
                 for ( x = [0 : 10] ){
                     if(y%2==1) {
                         translate([9+x*18,y*16,0]) cylinder(r = 8.5, h = 3, center = true, $fn=32);
                     }else {
                         translate([x*18,y*16,0]) cylinder(r = 8.5, h = 3, center = true, $fn=32);
                     }
                 }
            }
        }]
        */
        union()
        {
            translate([ 0, 52, case_height - 1.2 ]) cube([ 300, 1.5, 10 ]);
            translate([ 0, 110, case_height - 1.2 ]) cube([ 300, 1.5, 10 ]);

            translate([ 30, 0, case_height - 1.2 ]) cube([ 1.5, 300, 10 ]);
            translate([ 100, 0, case_height - 1.2 ]) cube([ 1.5, 300, 10 ]);
            translate([ 160, 0, case_height - 1.2 ]) cube([ 1.5, 300, 10 ]);
        }
    }
}
module bottom_mp()
{
    translate([ 0, 0, -0.01 ]) linear_extrude(height = 5, scale = 1) offset(r = +1.48, $fn = 50)
        import(file = drill_holes, dpi = 300);
    translate([ 0, 0, -0.01 ]) linear_extrude(height = 5, scale = 1) offset(r = +1.48, $fn = 50)
        import(file = standoffs_pos, dpi = 300);
}

module infill(w, d, h, t)
{
    for (y = [0:10])
    {
        translate([ 0, y * 20, 0 ]) cube([ w, t, h ]);
        translate([ y * 20, 0, 0 ]) cube([ t, d, h ]);
    }
}
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

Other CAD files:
parts/export/case/metal-case-right.step
parts/export/diffuser/diffuser_frame_left.stl
parts/export/display_holder/display_holder_dummy_r1.stl
parts/export/keycap_stem/stem_S_1U25.step
parts/case/case_polykybd_split72_metal.scad
parts/case/case_polysplit72_pom.scad
case/case_polysplit72_left2_r3.stl
case/case_polysplit72_left2_r4.stl
case/case_polysplit72_left2_r5.stl
case/case_polysplit72_left2_r6.stl
case/case_polysplit72_left2_r6v2.stl
case/case_polysplit72_left2_r7.stl
case/case_polysplit72_left2_r8_no_support.stl
case/case_polysplit72_left2_r9.stl
case/case_polysplit72_right2_r3.stl
case/case_polysplit72_right2_r4.stl
case/case_polysplit72_right2_r5.stl
case/case_polysplit72_right2_r5_noinfill.stl
case/case_polysplit72_right2_r6.stl
case/case_polysplit72_right2_r7.stl
case/case_polysplit72_right2_r8_no_support.stl
case/case_polysplit72_right2_r9.stl
case/right_side_case.stl
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

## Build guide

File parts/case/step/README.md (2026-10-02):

# Metal case → clean STEP (build123d)

Re-authors the OpenSCAD **metal** case (`../case_polykybd_split72_metal.scad`,
module `right_side_modular`) as a real B-Rep solid using
[build123d](https://build123d.readthedocs.io/) (OpenCASCADE), so the exported
STEP has true planar/cylindrical surfaces and tight tolerances — instead of the
~15 000-facet mesh a fabricator's validator rejects. Follows
[`../openscad-to-step-recipe.md`](../openscad-to-step-recipe.md).

## Build

```bash
# ⚠️ build123d is PINNED.  The geometry is version-sensitive, so an unpinned
# install silently rewrites a fabrication deliverable; `make` checks and refuses.
pip install build123d==0.12.0  # pulls in OCP (OpenCASCADE bindings)
pip install matplotlib         # only for `make preview`
make                           # -> ../../export/case/metal-case-{right,left}.step + validate
make preview                   # -> compare.png : this model vs the original mesh
```

`build.py` builds both sides (left = right mirrored across YZ) and writes STEP + a
coarse STL for preview. `validate_step.py` is the acceptance test; `render_compare.py`
renders this model beside `../../export/case/case_polykybd_split72_metal.stl`.

## What is reproduced

Only the **active** geometry of `right_side_modular()` — the large commented-out
FDM block (standoffs, tenting, branding, flip-stand bays, nut pockets) is **not**
part of the metal case and is not reproduced.

| SCAD op | here | notes |
|---|---|---|
| `hull(camfer_top, scale(1.08) pcb_shape)` | 3-section `loft` of the **convex-hull** sections (bottom @−6.21, widest r2.65 @17.5, cap r1.65 @18.5) + rim `fillet` | outer shell; **`hull()` is convex** so the shell is the convex hull of the outline (see below) |
| `offset(r=…)` corner rounding | `offset(..., kind=Kind.ARC)` | real cylindrical corner faces |
| wedge cut-off (`rotate([-5,0,0]) cube`) | `Box` rotated −5° about X, subtracted | tented underside |
| inner hollow (`hull() offset(outline)`) | 2-D convex hull of the outline, extruded & subtracted | `hull()` of one profile = its convex hull |
| inner border (`offset(outline, −3.35)`) | `offset(…, −3.35)` extruded & subtracted | wave-following inner ledge |
| switch/key cut-outs (`cut-outs.svg`) | X-mirrored faces extruded up, subtracted | 112 key openings |
| LED / SW / USB holes | per-file faces `offset`+extrude, subtracted | side/edge holes |
| left case | `right.mirror(Plane.YZ)` | one source of truth |

## ⚠️ OCCT can silently NO-OP a boolean cut → re-cut on the final part

OpenCASCADE's boolean occasionally leaves a cut **unapplied** against a complex
intermediate solid (it emits `Boolean operation unable to clean`): here the
switch/LED cut of `cut-outs.svg` left **two** keycap LED round holes (wires 9 & 95)
**capped** by the top plate (a solid layer at z 17.3–18.5) while the other 34 cut
through — the "two keys whose round LED space isn't open" bug. The same prisms cut
fine on a simple plate *and* re-cut fine on the final part, so the failure is
intermediate-state-specific. Fix: **re-run the switch cut on the final geometry**
(`build_right` step 8) — idempotent for the openings already cut, and it removes the
caps (verified by vertical raycast: all 36 circles go to 0 crossings). If you add
cut features and something doesn't open, raycast the suspect XY through the model and
check for stray crossings before assuming the profile is wrong.

## ⚠️ The outer shell is CONVEX (`hull()`), not the raw outline

OpenSCAD `hull()` returns a **convex** hull. The SCAD builds the outer shell as
`hull(camfer_top, pcb_shape)`, so the shell is the **convex hull** of the outline —
concavities (the front wave, thumb notch) are filled. The inner hollow is *also*
`hull(...)` → convex. A plain `loft` of the raw (concave) outline instead of its convex
hull leaves the wall concave in the front while the convex inner pocket stays put, so the
pocket **pokes through the wall = a hole in the front**. Fix: the loft sections are the
**convex hull** of the outline (`pcb_shape_convex`), so outer ⊇ inner everywhere.
(The concave, wave-following outline is what the *3-D-printed* case uses — a different model.)

## Bottom-plate rabbet (POST-PROCESSING feature — not in the .scad)

The reference `metal-case-*.step` adds, around the wedge-cut bottom opening, a
**rabbet that seats a bottom plate** — this was a manual post-processing step, so it is
**not** in `case_polykybd_split72_metal.scad`. It shows up as the two things you described:
the *"small extrusion perpendicular to the cut-off"* (an outer **lip** dropping below the
wedge plane) plus the *"inner cut-out rim"* (a recessed **ledge** the plate rests on).

`add_bottom_rabbet()` reproduces it. Flatten the wedge plane to horizontal, grab the real
wedge-plane bottom face `bf`, then — the recipe that is BOTH a uniform rim AND an
export-stable closed solid (this took several wrong tries, see below):
- **LIP** = a **full plate** from the real outer boundary `make_face(bf.outer_wire())`,
  extruded a constant `LIP_DROP` straight down the plane normal (`dir=(0,0,-1)`), glue-fused
  to the part (`BOPAlgo_GlueShift`, `_glue_fuse` — the plate top is coincident with the wall
  bottom).
- **LEDGE** = reopen the interior + recess it `RABBET_UP` above the plane using a
  **convex-hull** inset `offset(convex_hull_face(bf), −LIP_W)` — leaving the `LIP_W` rim band
  (pocket = `LIP_DROP+RABBET_UP` ≈ 2 mm = `case_bottom_thickness`). Then rotate back.

⚠️ **This is applied LAST in `build_right` (after the USB-chamfer + re-cut booleans), not at
step 7.** Running those later wall/keycap booleans on top of the remodelled rabbet bottom
turned the cut into a NO-OP that left an **open shell**.

⚠️ **Two shape choices are forced by what survives STEP export** — `validate_step.py` now
counts `solids` (must be **1**), because `BRepCheck_Analyzer.IsValid()` is topological only
and happily passes an **open shell** (`solids=0`) whose bottom faces read **inward** (you see
through the bottom). Both traps produce an in-memory `solids=1` that `export_step` →
re-import collapses to `solids=0`:
- **LIP must be the full plate, NOT a thin ring** (`of − offset(of,−LIP_W)`). The ring
  glue-fuses to a near-degenerate solid that STEP re-reads as an open shell; the full plate
  (single clean outer boundary) round-trips as `solids=1`. The plate still yields a uniform
  rim because the LEDGE cut reopens its centre.
- **LEDGE must be the convex hull, NOT a boolean-offset of the real outer wire**
  (`offset(make_face(bf.outer_wire()),−LIP_W)`). The real-wire offset subtracts to another
  export-unstable solid; `convex_hull_face(bf)` is a clean polygon that insets cleanly.
- ⚠️ **`LIP_W` must be SMALLER than the THIN front wall** (2.0, not 4.0). The ledge shelf is
  formed by the recess cut `offset(convex_hull_face(bf),−LIP_W)` landing **inside the wall**
  and removing material up to `z0+RABBET_UP`. On the back the wall is thick so any `LIP_W`
  lands in it; but the **front wall is thin** (the wedge grazes it), so at `LIP_W=4` the cut
  boundary falls **past** the wall into the already-open cavity — it removes nothing and **no
  front ledge forms** (the "rim missing on the thin front edge" report). At `LIP_W=2` the cut
  lands in the front wall and a uniform ledge appears, matching the reference (lip at
  zflat −0.9, ledge at zflat +0.65, both front and back — verified against
  `metal-case-right.step` in the wedge-flattened frame).
- `extrude(bf, negative)` extrudes UP along the face's downward normal — force `dir=(0,0,-1)`.

Parameters at the top of `case_model.py`:

```python
WITH_BOTTOM_RABBET = True
LIP_DROP  = 1.0    # lip depth, perpendicular from the cut-off plane
RABBET_UP = 1.0    # inner ledge recess above the cut-off plane
LIP_W     = 4.0    # outer lip band width (uniform on every edge)
```

Set `WITH_BOTTOM_RABBET = False` for the pure SCAD reproduction.

## USB inner-wall chamfer (POST-PROCESSING feature — not in the .scad)

`add_usb_chamfer()` puts a 45° lead-in on the **interior** face of the wall around each
USB window, so the connector/cable enters cleanly. The two windows (fixed by the committed
SVGs) are **USB1**, the side window in the left/inner wall (normal +X), and **USB0**, the
window in the back-left wall (normal −Y).

It is applied on the **bottom edge only** — toward the **open bottom** of the case, where
nothing is in the way. The window's top/sides run into the interior ceiling step (which made
a full-perimeter lead-in awkward to contain), but below the window is clear wall all the way
to the open bottom, so a bottom lead-in is unobstructed. `_usb_bottom_bevel` subtracts a
**triangular prism** along the window's bottom edge: at the inner wall surface the opening
drops `USB_CHAMFER` below the window bottom, tapering back to the window bottom `USB_CHAMFER`
deep into the wall (a 45° ramp). No clip needed. The bevel's inner leg is started
`USB_BEVEL_OVERCUT` (0.4 mm) **interior of the measured inner wall face** (into the empty
cavity), so no thin wall sliver survives — a sub-0.1 mm error in the wall-face coordinate
otherwise left a ~0.05 mm wall between the bevel and the real inner face. Params:

```python
WITH_USB_CHAMFER = True
USB_CHAMFER = 3.0      # 45° lead-in depth/width on the inner face
```

Because the funnels live **inside `build_right()`** (before the YZ mirror), the left case
gets them for free.

## Interior wall-meets-floor chamfer (POST-PROCESSING feature — not in the .scad)

A 45° chamfer along the interior seam where the inner wall meets the interior floor (the
top-plate underside, z=13.65). That corner is **concave**, so a plain subtractive bevel
removes nothing — instead the chamfer is applied to the **negative volume**: `_chamfered_pocket`
tapers the inner-hollow pocket's **top edge** inward by `WALLFLOOR_CHAMFER` (a `loft`, since a
build123d edge `chamfer()` fails on the arc-cornered pocket), and subtracting that leaves a
clean 45° fillet-of-material transition exactly on the wall/floor corner. It is applied to
**both** inner negatives — the convex hull pocket (floor z=13.65) **and** the deeper "border"
pocket (floor z=14.95) — so the interior steps down through **two** chamfered transitions.

```python
WITH_WALLFLOOR_CHAMFER = True
WALLFLOOR_CHAMFER = 2.0   # 2 mm is the clean maximum here — see note
```

⚠️ **3 mm is not achievable at this corner.** The interior ledge between the inner wall and
the next pocket (the SCAD **"border"**, offset −3.35) is only ~4 mm wide, so a ≥2.5 mm chamfer
consumes it and **degenerates the boolean** (the border rises 1.3 mm above the ledge → a
sub-1 mm sliver). Verified: clean at ≤2 mm, broken at ≥2.5 mm — 2 mm is the clean maximum.

## Branding: engraved "PolyKybd" on the convex-hull front-bezel top (not in the .scad)

The SCAD `branding()` engraves **PolyKybd** (Arial Bold Italic, 0.35 mm deep) on the **FDM
case bottom**. The metal case has no such bottom face, so `add_branding()` places the same
engraving on the flat top area the **convex hull** created in front of the thumb cluster —
the extra bezel the hull fills in where the raw outline is concave (the "little extra area"
from the convex-hull outer shell). It is drawn as **two staggered lines** — **"Poly"** up/left,
**"Kybd"** down/right — at a smaller size than the SCAD's single size-12 line (the top band is
narrower), centred toward the case centre. Engraved (subtracted) to match the SCAD's `difference()`.

```python
WITH_BRANDING = True
BRAND_LINES = ("Poly", "Kybd"); BRAND_SIZE = 7.0; BRAND_DEPTH = 0.35   # two staggered lines
BRAND_X = 12.0; BRAND_Y = -47.0; BRAND_TOP_Z = 18.5                    # block centre on the bezel
BRAND_STAG_X = 3.0; BRAND_STAG_Y = 3.6                                 # 2nd line offset (+X, −Y)
BRAND_FONT = ".../LiberationSans-BoldItalic.ttf"                       # Arial Bold Italic metric clone
```

Text is built with build123d `Text` (**Liberation Sans Bold Italic** — the metric-compatible
Arial substitute present on Linux; there is no Arial), extruded and subtracted 0.35 mm into
the z=18.5 plateau. ⚠️ **Branding is applied AFTER the YZ mirror, per side**, so the logo
reads correctly (not mirror-backwards) on **both** halves: `build.py` does one heavy build
(`build_right(with_branding=False)`, which includes the USB + wall-floor chamfers), engraves
the right at `(BRAND_X, BRAND_Y)`, and engraves the mirrored left at `(−BRAND_X, BRAND_Y)`.
Set `WITH_BRANDING = False` (+ `WITH_USB_CHAMFER`/`WITH_WALLFLOOR_CHAMFER = False`) for the
pure SCAD reproduction.

## Display/encoder pocket — rounded corners (not in the .scad)

The SCAD's "extra space around display" is a square-cornered `cube([30,69,5])` @
(−75, 21.5, 15.4) that covers both the status display and the rotary-encoder area. Its
four **vertical corners are rounded** (`DISPLAY_CORNER_R`, default 2 mm) by filleting the
box's Z-parallel edges before subtracting.

```python
DISPLAY_CORNER_R = 2.0   # 0 = square corners (pure SCAD)
```

A **rotary-encoder blind pocket** is added on the pocket's **right edge**. It uses the
encoder's **own cutout shape** — the rotated-square `cut-outs.svg` face whose corner sits
at the pocket edge ≈(−55,−5), found by the vertex nearest `ENCODER_ANCHOR`. The **actual
encoder cutout stays** (that face is still cut through with the other switches — the real
through-hole is needed); on top of it an **enlarged BLIND body recess** is added: the same
face **enlarged** (offset `ENCODER_GROW`) to reach past the pocket edge, cut at the **same
z-depth as the display box** (z 12.9–17.9) so it stays under the top skin (z 17.9–18.5).
`ENCODER_ANCHOR` is a final-frame coord, converted to the pre-`X_SHIFT` frame where the
display Box + `cut_faces` live.

The recess Y-extent is additionally grown by `ENCODER_GROW_Y` (X unchanged): the enlarged
`enc_face` is **scaled in Y about its centre** so the bbox height grows by `ENCODER_GROW_Y`
mm — one clean pocket (not a doubled/lumpy body). build123d's `scale()` is not about the
origin, so the face is re-centred on its original Y centre afterwards.

```python
WITH_ENCODER_POCKET = True
ENCODER_ANCHOR = (-55.0, -5.0)   # final-frame corner of the encoder cutout
ENCODER_GROW   = 3.5             # offset each side: widen the blind body recess
ENCODER_GROW_Y = 1.0             # extra Y-only span (single Y-scale of the face)
```

## ⚠️ Two corrections vs. the recipe (learned from the geometry)

1. **Do NOT apply the `25.4/300` (dpi) scale.** The KiCad SVGs already declare their
   size in **millimetres** (`width="195.3006mm"`, matching viewBox units), and
   build123d's `import_svg` reads real mm. OpenSCAD's `dpi=300` is ignored here for the
   same reason (it only scales *unit-less* px). Applying the recipe's `scale(25.4/300)`
   would shrink the case ~12× (to ~16 mm). Verified: the exported bbox
   (≈200 × 141 × 25 mm) matches the original STL to <0.3 mm on every axis.

2. **`rotate([0,180,0])` in `linear_extrude(h) rotate([0,180,0]) <2D>` acts on the flat
   2-D profile, i.e. it is a pure X-mirror — then the extrude goes up.** Rotating the
   *solid* 180° about Y instead sends the prisms to z < 0, below the case, and no holes
   are cut. Mirror the faces (`Plane.YZ`), then extrude upward.

`center=true` imports are reproduced by recentring each face on its own bounding-box
centre; non-centred imports (LED/SW/USB) keep file coordinates and are placed by the
same `translate([-92,-72,1])` as the SCAD. build123d and OpenSCAD both flip SVG Y about
the document height, so the coordinates line up.

⚠️ **The LED SVG holds OPEN strokes, not filled regions** — `poly_kb_wave_right2-LED.svg`
is line segments (each wire is a single edge). OpenSCAD's `offset(r=0.9) import(...)`
implicitly closes each degenerate path and inflates it into a rounded **slot** of width
`2·0.9`. build123d's `make_face` rejects an open wire, so `raw_faces_all` returned `[]` and
the **LED light-pipe slots silently vanished**. `raw_slot_faces(fn, r)` reproduces OpenSCAD:
it offsets each open wire by `r` (`Kind.ARC`) into the closed stadium outline, then faces it
(extrude directly — the `r` offset already IS the slot, so no second offset). ⚠️ **The switch
SVG `poly_kb_wave_right2-SW.svg` is the SAME open-stroke case** (2 slots on the wall *opposite*
the LED slots) — it also went through `raw_faces_all` → `[]`, so the **switch openings were
missing too**; it now uses `raw_slot_faces(..., 2.5)`. Only the **USB** SVG is filled regions,
keeping the `raw_faces_all` + `offset` path.

## Bottom-plate screw holes (POST-PROCESSING — not in the .scad)

4 pilot holes for **M2×4 self-tapping** screws that fix the bottom plate (aluminium → no
thread; the screw cuts its own on first use, so `SCREW_HOLE_D = 1.6` is a tight thread-cutting
pilot). Drilled in `add_bottom_rabbet` in the **wedge-flattened frame**, so they run
perpendicular to the plate, each engaging ~`SCREW_HOLE_DEPTH` (4.5 mm) of body above the ledge.
⚠️ The case walls are thin, so the holes sit in the thicker **corner L-junctions** (outer shell
solid, any opening faces the interior). The two **front** corners are useless — the wedge makes
the front shallow, with no material at the ledge — so the front holes are **moved north to the
side "knees"** (where the diagonal front wall meets the vertical side wall), the southern-most
solid+clearance spots. Positions in `SCREW_HOLES` (flattened XY); `WITH_SCREW_HOLES` toggles them.

## Acceptance (validate_step.py)

Both sides pass:

- `valid B-Rep = True`
- **curved faces > 0** (519 — real corner cylinders + rim tori)
- **max edge tolerance ≈ 1e-5 mm** (vs 0.148 in the mesh export)
- ~1359 faces (vs ~15 000 facets), bbox 200.1 × 142.9 × **25.7** mm (with the bottom
  rabbet; ~24.7 mm without it, i.e. the pure SCAD reproduction)

## Memory note

OpenCASCADE's allocator over-reserves address space during the 112-key-hole
booleans and can trip the container/OS OOM killer even with plenty of free RAM.
`build.py` sets a soft `RLIMIT_AS` (~6.5 GB) at startup, which keeps the allocator
conservative and makes the build reliable (it just runs a bit slower). If you drive
the model directly instead of via `build.py`, cap it yourself first:
`ulimit -v 6000000` (Linux) before `python case_model.py`.

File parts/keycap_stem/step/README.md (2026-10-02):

# Keycap stem → clean STEP + a technical drawing (build123d)

Re-authors the **S-profile keycap stems** (`../keycap_stem.scad`, `mx_stem()`) as real
B-Rep solids with [build123d](https://build123d.readthedocs.io/) (OpenCASCADE), and
draws each one on an A3 sheet, so an injection moulder can quote and cut without
guessing at facet noise. Follows
[`../../openscad-to-step-recipe-stems.md`](../../openscad-to-step-recipe-stems.md),
which follows the case's [`../../case/openscad-to-step-recipe.md`](../../case/openscad-to-step-recipe.md).

**Why not STL → STEP.** OpenSCAD has no B-Rep kernel, so its export is a facet soup
with loose stitching. On a stem that matters more than on the case: the feature that
decides whether the keyboard works is a ~1.1 mm MX cross, and a faceted cross is not a
datum anyone can cut to.

## Build

```bash
# ⚠️ build123d is PINNED.  0.13.0 projects the sheet materially differently from
# 0.12.0 and rewrites the STEP below its header, so an unpinned install silently
# rewrites a fabrication deliverable.  `make` checks this and refuses to proceed.
pip install build123d==0.12.0 scipy fonttools   # OCP comes with build123d; fontTools
                                                # instantiates the Bold font instance
sudo apt-get install -y openscad     # REQUIRED: `make` runs the .scad parity check

make                 # -> ../../export/keycap_stem/stem_S_1U{,25}.step + _drawing.svg, validated
make verify          # diff the solid against the .scad it was ported from
make selftest        # prove those checks can fail (see below)
```

| file | what |
|---|---|
| `stem_model.py` | the model. Every constant keeps its `keycap_stem.scad` name so the two stay diffable |
| `hull3d.py` | OpenSCAD `hull()` as an exact polyhedral convex hull |
| `font.py` | pins the engraving to one font FILE (`make font`) — see the font traps below |
| `build.py` | exports `stem_S_1U.step` / `stem_S_1U25.step` (+ an STL the checks use) |
| `drawing.py` | the A3 sheet: ISO 5457 zone frame, V1-V4 ortho (V3 at 3:1), V5/V6 sections at 3:1, V7 cross 10:1, V8/V9 stamps, V10 isometric, notes |
| `validate_step.py` | the case's acceptance test, reused (real solid, curved faces, tight tolerance) |
| `verify.py` | measures the cross, diffs volume/bbox and booleans against OpenSCAD |

## What the two deliverables are for

**The drawing governs; the STEP conveys shape.** A solid model carries no tolerances, so
a toolmaker handed only a STEP cuts to the model and the tolerance question resurfaces at
first article. The sheet states a general tolerance and tightens only the MX cross and the
interface to the off-the-shelf transparent cap.

## Results

```
faces 142   planar 108   curved 34   max edge tolerance 2.1e-07 mm
volume vs the OpenSCAD mesh   +0.111 % (1U)   +0.081 % (1.25U)
bounding box                  identical to 5 decimal places
STEP \ SCAD 0.62 mm3 (0.11 %)   SCAD \ STEP 0.011 mm3 (0.002 %)
```

The residual is entirely the `.scad`'s tessellation — a 128-gon stem and `$fn=64` cross
relief — against true analytic surfaces, which is the difference the exercise exists to
remove. The exported solid carries the stamp (142 faces, 556.98 mm³ at 1U); without it,
100 faces and 562.00 mm³.

⚠️ **The `.scad` diff runs with the stamp OFF, on purpose** (`verify.py` `engrave = False`).
The moulded stamp is β and the `.scad`'s is α, so an engraved diff would report the
*intended* difference as an error on every run — and the ~5 mm³ of glyph would drown the
0.6 mm³ of tessellation the diff exists to see. The stamp is checked separately and better:
its clearance to the seat edge is measured on **both** faces (0.80 mm all round against the
0.80 mm requirement), which a volume comparison could never tell you.

## Decisions taken

- **Material is ABS**, stated in the title block. Its 0.4–0.7 % shrink is what keeps the
  MX cross inside its ±0.03. ⚠️ **The model and the STEP are the FINISHED PART** — shrink
  compensation goes on the cavity and is the toolmaker's, and note 9 asks them to state
  the rate they used.
- **The profile + revision stamp is engraved**, `S    β` (`build.py --no-engrave` drops
  it). Marking the revision on the part is the *point* — so drawing note 10 asks for it on
  a **replaceable insert** in the cavity rather than cut into the block, which makes the
  next revision a plug swap instead of a tool edit. Both stamps are 0.30 mm deep with zero
  draft, in the display-seat floor and the pocket ceiling; neither is a fit surface.
- ⚠️ **The moulded revision is `β` where `keycap_stem.scad` stays `α`** — different
  process, different tolerances, different tooling, so the two are told apart by eye.
  `stem_model.REVISION` is therefore **the one constant here that is deliberately NOT a
  mirror of the `.scad`**; everything else keeps its `.scad` name *and* value.
- ⚠️ **The pocket-ceiling stamp is TURNED 180°, not mirrored** -- and the sheet said
  "mirrored ... reads correctly from below" until V10 was drawn and the picture
  disagreed with the caption. The `.scad` applies `rotate([180, 0, 0])`, a flip about
  X, so the stamp reads normally when the part is turned over front-to-back (how you
  actually turn one over) and appears upside down in a projected view-from-below. An
  `S` is 180°-symmetric, so only the `β` shows it at all. **Draw the thing a reader
  could get backwards; do not describe it.**
- ⚠️ **That change also fixed a legibility bug worth knowing about: Noto Sans draws
  U+03B1 single-storey and TAILLESS, so `α` reads as a Latin `a` at stamp size.** DejaVu's
  alpha has the usual right-hand tail; Noto's does not, and the printed plates have carried
  the ambiguous one all along. `β` has no such twin. The drawing spells the codepoint out
  (`revision_codepoint()`) regardless, because a Greek letter cut into steel from an
  outline alone is a chance to cut the wrong character.

## Things that are load-bearing

- ⚠️ **`MX_CROSS` 4.35 and `MX_CROSS_WIDTH` 1.4 are NOT the cross size.** They describe the
  plus *before* `offset(r = -MX_CROSS_FILLET)`, so the opening is **4.05 × 1.10**. Quoting
  the constants to a moulder overstates it by 0.3 mm on both. `cross_profile()` derives the
  real numbers, and `verify.py` measures them off the solid rather than trusting either.
- ⚠️ **`Shape.scale()` scales about the shape's own location, not the origin.**
  `linear_extrude(scale=)` scales the whole profile about the extrusion axis, so an
  off-centre sub-shape must move inward as well as shrink. Left at the default, the model
  still built, still validated, and its cross tapered at a third of the intended rate
  (+0.5 % volume). Pass `about=(0, 0, 0)`.
- **A tapered box is built as a convex hull of its 8 corners, not as a `loft`.** Same solid,
  different surfaces: OCCT's ThruSections returns the planar sides as degree-1 B-spline
  patches. Hulling the corners gives real `Geom_Plane` faces — 82 of them instead of 36.
- **The cross cut is a union of exact pieces** (two hulled bars + four fillet patches + four
  relief circles) rather than one lofted profile, so the eight arm flats — the surfaces the
  switch cross actually bears on — come out as planes. The fillet and relief walls stay
  free-form, and that is correct: tapering about the axis moves an off-centre arc's centre as
  well as its radius, so those walls are **oblique** cones and no analytic OCCT surface fits
  them. ⚠️ A build that reports them as `Geom_Cone` is a build whose taper is scaling each
  sub-shape about its own centre — the `Shape.scale()` bug above, which is exactly how it was
  first seen.
- ⚠️ **The `.scad` says `u_size = 1.22` for the 1.25U plate, not 1.25.** `u_size` feeds
  `(u_size - 1) * 2 * 5`, i.e. it is a half-width-extension dial (→ 19.90 mm body), not a
  keycap unit count. The recipe had read it as a unit size.
- ⚠️ **The engraving font is pinned to a FILE, and three plausible spellings give three
  different glyphs.** OCCT does not read fontconfig, so `font="Noto"` — what the `.scad`
  asks for — emits *"unable to find font 'Noto'; 'FreeSans' is used instead"* and carries
  on; the real family name `"Noto Sans"` finds the file but renders the **variable font's
  default instance**, not Bold. Measured areas for the same string: 4.068 (FreeSans) /
  2.330 (variable default) / 3.563 (a real Bold). `font.py` instantiates `wght=700` once
  and passes `font_path=`, so the tool is cut from the repo rather than from whatever the
  build machine had.
- ⚠️ **OpenSCAD's `text(size=)` is a POINT size at 100 DPI; build123d's `font_size` is the
  em in millimetres** — the same nominal 3 comes out **100/72 = 1.389× larger** in
  OpenSCAD (cap height 3.058 mm against 2.202 mm, measured both ways). Without
  `TEXT_EM = TEXT_SIZE * 100 / 72` the moulded stamp is a third smaller than the printed
  one, and it reads exactly like a font-weight problem. Same family of trap as
  `fontconvert`'s `-s` being points at 141 DPI (firmware `fonts/README`).
- ⚠️ **Do not run `../build_stems.sh --fetch-font` to get that font.** It fetches and then
  goes on to **re-export all sixteen printed plates** against the newly-installed font,
  rewriting committed meshes — it rewrote three here before it was killed. `make font`
  fetches and stops; the two share one cache path.
- ⚠️ **The three 0.4 × 3.0 × 0.3 tabs are a FUNCTIONAL click feature, not a print aid.**
  They stand 0.2 mm proud on +Y and ±X and are what makes the transparent relegendable
  cap click on. The first draft of this pipeline read them as a sprued-plate artefact,
  called them `print_tabs`, and had the drawing invite the moulder to delete them — on
  the one document a shop acts on without asking back. They are now `CLICK_TAB_*`,
  dimensioned in V3, and note 10 says they must not be removed. `--no-click-tabs` exists
  only to isolate them in a comparison; it is **not** a shipping option.

## Verification, and why there are three checks

`make verify` runs, per variant: the cross measured off a section of the real solid; the
tapered cross prism against its closed form; volume + bounding box against an OpenSCAD
export of the same call; and a **boolean difference both ways** through OpenSCAD.

⚠️ **Find a feature by what it IS, not by "the smallest face".** `measure_cross` used to
take the smallest face in the section; the cap is tilted −7°, which sweeps the seat
engraving through global z 5.1–5.5, so once the stamp was switched on a **glyph fragment**
became the smallest face and the check reported the inside of an `α` — 0.90 × 1.30,
r0.60/0.84, entirely plausible numbers for a cross. It now selects the inner wire that is
centred on the stem axis and smaller than the stem OD.

`make selftest` widens the cross by 0.10 mm and asserts the checks reject it. That run also
shows why the weakest check cannot stand alone:

```
cross measurement differs : True
SCAD \ STEP grew to 3.7767 mm3 (0.672 %) : True
volume delta +0.657 % (still inside the 1 % gate: True -- so volume ALONE would MISS this)
```

## Gotchas that cost real time

- ⚠️ **build123d's drafting module cannot be used for the annotation.** `TechnicalDrawing`
  and `ExtensionLine` were used first, and every label goes through OCCT's
  `Compound.make_text` — which **segfaults** once the sheet carries the frame plus the
  projections, the section and the dimensions. Deterministically, on the 14th label, with
  ~500 MB resident and 14 GB free; none of the ingredients crashes alone. `drawing.py`
  therefore takes geometry from build123d and writes the SVG itself, with real `<text>`.
  The file is 200 KB instead of megabytes and the dimensions are selectable in the
  fabricator's viewer. `../../case/step/plate_svg.py` writes its SVG the same way.
- ⚠️ **`ExtensionLine` has no fallback for a label wider than the dimension line**: the
  shaft between the arrowheads comes out empty and it raises `Can't determine direction of
  empty Edge or Wire` several frames away, which names nothing. Ø5.50 at 2:1 is enough to
  trigger it.
- ⚠️ **Hatch rulings must be thin RECTANGLES, not lines.** A line lying exactly in the
  section face's plane makes OCCT's edge-face common return nothing at all — silently, so
  an empty hatch reads as "no solid here" rather than as an error. Below ~0.05 mm the
  rectangle disappears into the boolean tolerance too.
- ⚠️ **The stamp details needed the MX slot in them, and `cap_body` has none.**
  `stamp_face()` takes its face from the untilted cap body, but `mx_stem` cuts the cross
  *after* tilting and raising the cap — so the detail was a rectangle with two letters
  in it and no datum to locate them from. Pull the cross back through that placement
  (`Rot(-angle) * Pos(0, 0, -extra_len) * cross_cut(...)`) and cut it into the cap body.
  ⚠️ Keep placing the STAMP against the uncut face, as `_engraving` does: centring it in
  a face that now has a hole in it moves it.
- ⚠️ **Zone letters live outside the frame, so `check_inside_frame` has to know.** It
  reads the recorded text extents now instead of re-parsing the emitted SVG, which makes
  `chrome=True` exempt from both that check and the collision report for free.
- ⚠️ **`snap` earns its keep by REFUSING.** It rejected the first attempt at V5's extra
  dimensions -- *"no section vertex within 0.6 of (-5.65, 4.52)"* on the 1.25U variant --
  and the pair I had confidently called "the flange" turned out to be the inside of the
  pocket, which moves with `u_size`. Silently snapping to the nearest corner would have
  shipped a wrong label on one variant and a wrong anchor on the other. **Name a
  dimension by what it MEASURES when you have not verified which feature it is.**
- ⚠️ **Derive the scale caption from the number that drew the view.** It was a literal
  beside each `titles[..]` entry; `SCALE_ISO` went 1.6 -> 2.4 and the isometric went on
  claiming 1.6:1 -- a caption a reader might measure against. `_ratio()` formats it.
- ⚠️ **Anchor every section dimension on a REAL VERTEX of the cut.** `section()` returns
  the vertices and `snap()` picks the nearest, raising past a tolerance rather than
  quietly taking the wrong corner. Dimensions computed from model constants are exactly
  what "floating in the air" looks like on a section: the display seat is 1.10 below a
  top face tilted −7°, so the height the arithmetic names is not a height anything on
  that cut has.
- ⚠️ **On a section, a leader often beats a dimension line.** A feature in the middle of
  the cut (the stem boss, behind the outer skirt) can only be dimensioned by dragging
  extension lines across hatched material. A leader touches the vertex the number came
  from and crosses nothing.
- ⚠️ **Overlaying a second shape on a laid-out view means undoing TWO re-centrings, and
  getting one of them is worse than getting neither.** `Drawing` projects about the
  shape's own centre of mass, *and* `view()` then shifts by the projection's bounding-box
  centre. Correcting only the second put the faint stamp overlay plausibly in the middle
  of V3/V4 instead of visibly nowhere, which is far harder to notice.
- ⚠️ **A dimension anchored by hand lands in mid-air.** `Drawing` projects about the
  shape's centre of **mass**, then `view()` re-centres the result on its bounding box — so
  a sheet point computed from the model's own coordinates is off by the difference between
  those two centres (7.9 mm on the front view: the "the 7.91 dimension starts from
  somewhere outside" report). `view()` returns a model→sheet mapper built from the same
  two transforms, and every dimension goes through it.
- ⚠️ **A sheet laid out by hand-tuned offsets WILL collide, and the SVG source never shows
  it.** Three guards, all of which found live defects on the first sheet:
  `Sheet.group()` measures what a view actually drew and the title is placed from that
  (a guessed `dy` put V2's title nearer the view *below* it — which on a first-angle sheet
  is another projection, so it read as labelling the wrong view); `report_collisions()`
  lists label-on-label and label-on-outline overlaps; `check_inside_frame()` raises on
  anything past the border. ⚠️ The collision report only tracks **thick** paths, so a label
  lying on a dimension line or a thin isometric outline still passes — **render both
  variants**: the 1.25U leaders reach 4.4 mm further out and one collision existed only
  there.
- ⚠️ **A self-test can pass for the wrong reason — assert the NEGATIVE control too.**
  `verify.py --self-test` widens the MX cross and asserts the checks catch it, and its
  cross-measurement half had its own copy of the expected span with the taper left out.
  That copy is 0.0033 mm off at z = 0.30 — above its own 2e-3 threshold — so it reported
  "caught" against a **correct** model and asserted nothing at all. The fix is both
  halves of the usual pair: one `cross_span()` shared with check 1 so the two cannot
  disagree, and an explicit assertion that the same comparison is *quiet* on the
  unmodified model. A harness that cannot tell "the check fired" from "my arithmetic is
  wrong" is the fail-open shape the self-test exists to rule out. (CodeRabbit, PR #38.)
- ⚠️ **Gate on the dependency the check actually needs.** Check 1b — the cross prism
  against its closed form, the one that caught the `Shape.scale()` centre bug — sat
  below `if not have_scad: continue`, so a machine without **openscad** silently skipped
  a check that is pure build123d and needs no openscad at all.
- ⚠️ **The engraving font is pinned by SHA-256, and the cache is SHARED.** The outlines
  cut into a steel cavity come from a `main` URL, so `font.py` verifies the bytes and
  stops with instructions if upstream moves. ⚠️ `../build_stems.sh` fetches the same URL
  into the same cache path with no verification, so a mismatched cache is re-downloaded
  rather than rejected — that heals the shared path instead of failing on a file the
  other script legitimately put there. Only a fresh download that still mismatches is
  fatal. Changing the digest means re-exporting both STEPs: the engraving moves with it.
- ⚠️ **`build.py` writes TWO files, so its rule is a GROUPED target (`&:`), not a stamp.**
  `$(STEPS): ; build.py` reads as one rule and is two, so `make -j` can start build.py
  twice. A `.build-stamp` fixes that and breaks something else: with the stamp current
  and one STEP deleted, the STEPs' own recipe is a no-op, so `make step` reports success
  and leaves the file missing for `validate` to trip over. `&:` (GNU Make 4.3+) says
  "one invocation makes all of these" — scheduled once, and re-run when *any* output is
  missing. The Makefile hard-errors on older make, because there `&:` parses as an
  ordinary rule with a target literally named `&`: wrong, and silent.
- ⚠️ **The instantiated Bold font is named after the SOURCE DIGEST.** `bold_path()`
  returns it without consulting the cache, so under a fixed name a Bold instance made
  before the pin existed — or from a superseded digest — keeps engraving while the
  verified cache sits unused beside it. `.notosans-bold-<sha12>.ttf` makes a `SHA256`
  change a different file, so it regenerates itself and needs no staleness bookkeeping.
- ⚠️ **A STEP re-export rewrites the file even when the solid is identical** -- the
  header carries a timestamp, so `make step` always shows both files as modified. Before
  committing one, check whether anything below the header actually moved:
  `diff <(git show HEAD:<path> | tail -n +12) <(tail -n +12 <path>)`. If it is empty,
  `git checkout` the file rather than committing 1.3 MB of timestamp. Same reasoning as
  the STL facet-order note in the repo CLAUDE.md.
- ⚠️ **`BRepBndLib.Add_s` on an un-meshed shape boxes the underlying SURFACES**, not the
  trimmed faces, so a cut whose prism runs past the solid inflates the answer: it reported
  z_max 11.30 for a part that tops out at 7.91. `validate_step.py` (shared with the case)
  now uses `AddOptimal_s`; the case's own bbox was off by up to 2.1 mm the same way.

## Still open

- **The cap interface is a hard datum we do not own** (the transparent relegendable caps are
  off-the-shelf POS parts). Confirm it against a real cap before cutting steel.
- **Whether the moulder will do the replaceable-revision insert** (note 10). If they cut
  the character into the block instead, every revision is a tool edit — ask before the
  quote is accepted, not after.
- Only the **S** profile is exported. `VARIANTS` in `stem_model.py` is where R1–R5/S1/S5
  would be added; they differ only in `angle` and `extra_len`.

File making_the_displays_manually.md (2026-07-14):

# Making the displays manually

If you are not using the ready-made 0.42 inch displays from the kit, you can make them yourself by
extending a compatible 0.42 inch OLED with a short FPC cable and soldering the two together.

## Parts

Extend *[FPT042W000Z01](https://www.alibaba.com/product-detail/OLED-Display-0-42-Inch-Small_1600693977243.html)
or *[P34107](https://www.alibaba.com/product-detail/OLED-display-OLED-0-42-Inch_1600104997388.html)
with a [30mm FPC cable](https://de.aliexpress.com/item/1005001935872949.html).

> \* I got contacted that these Alibaba links are stale and it turned out that, at the moment, these do
> not work as the displays got removed. Let me keep them in case they come back online. Maybe you can use
> these as an alternative, the pins are compatible:
> [ZJY042-7240TSWPG10](https://www.alibaba.com/product-detail/0-42-inch-72x40-OLED-display_1600820452544.html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).
> The flex cable is about 1cm shorter, so your extension needs to be 40mm instead of 30mm. I have not
> tried these, so you might wanna do a test first!

The FPC extension should be 14 or 16 pins - blank contacts on the same side, like the two right side
displays on the picture in the main build guide. Only 14 pins are needed; however, you might want to get
a 16 pin FPC and cut away 2 pins to fit the FPC into the 14 pin socket. It is easier to solder 16 pins of
the display together with the 16 pins of the FPC (so the cable aligns), see here:

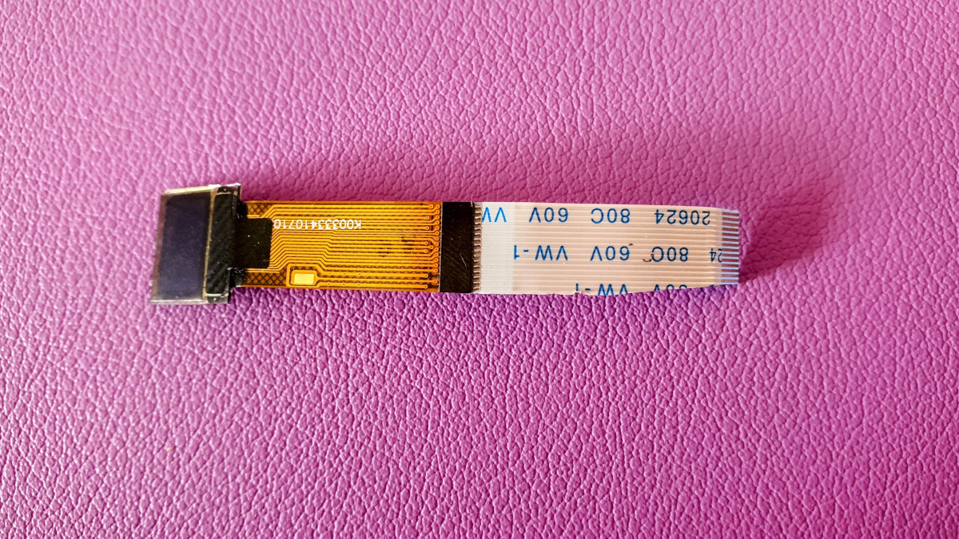
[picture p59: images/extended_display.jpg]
Extended Display


## Soldering the flex cable

To achieve this, I applied low temperature solder (138 degree C) on both the display FPC pins and the
extension FPC pins with the solder iron:

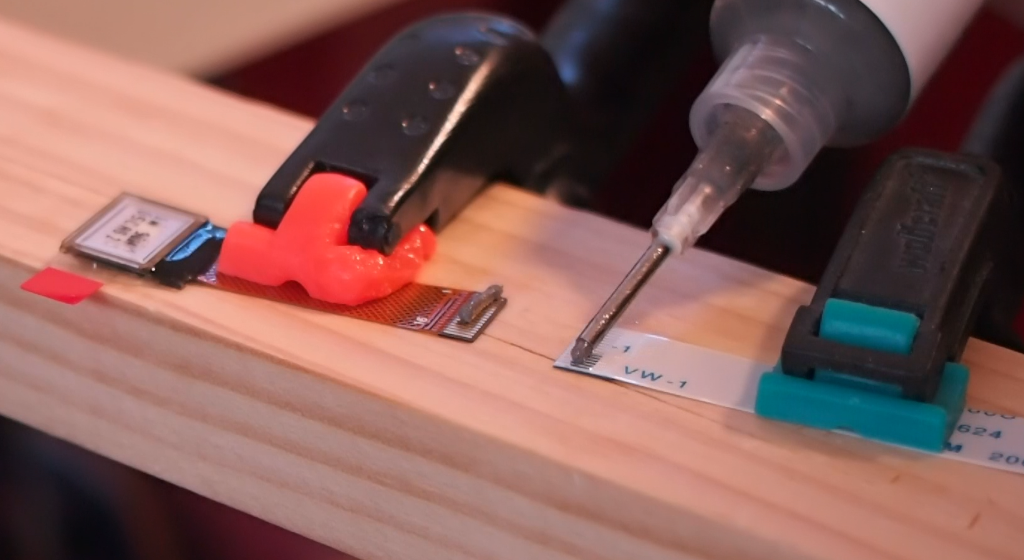
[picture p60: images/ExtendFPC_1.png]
Extended FPC Part 1

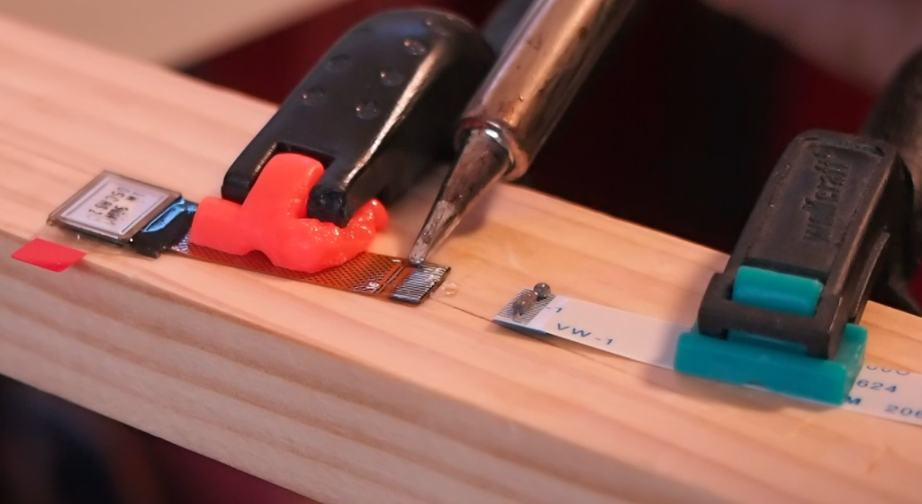
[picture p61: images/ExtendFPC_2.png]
Extended FPC Part 2


Then applied some flux on just one side and orientated them straight - don't overlap the pins 100%, leave
some space at the end so that excess solder can have some space to escape:

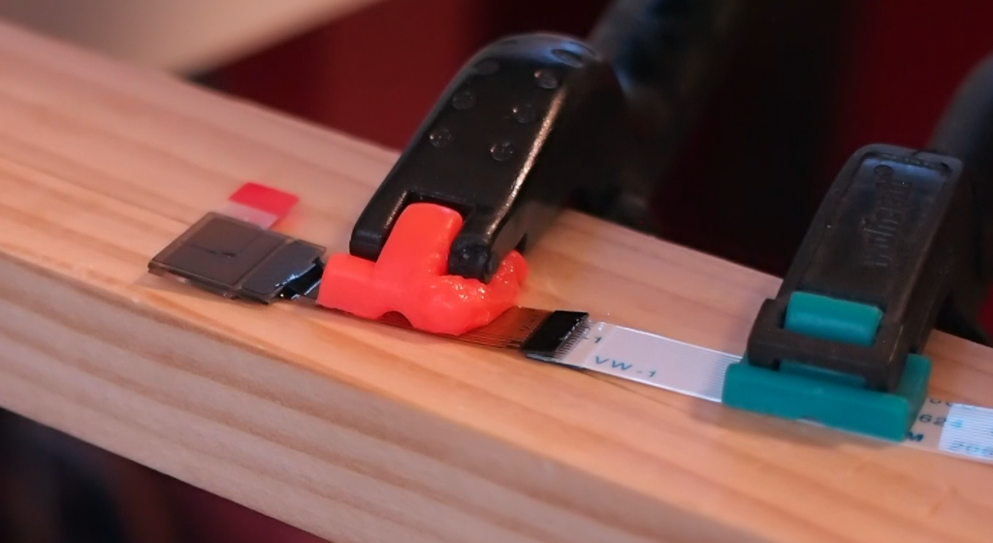
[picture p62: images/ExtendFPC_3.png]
Extended FPC Part 3


Next, I used the heat gun with maybe 160 C and heated both sides for a few seconds (you can see the solder
becoming liquid again):

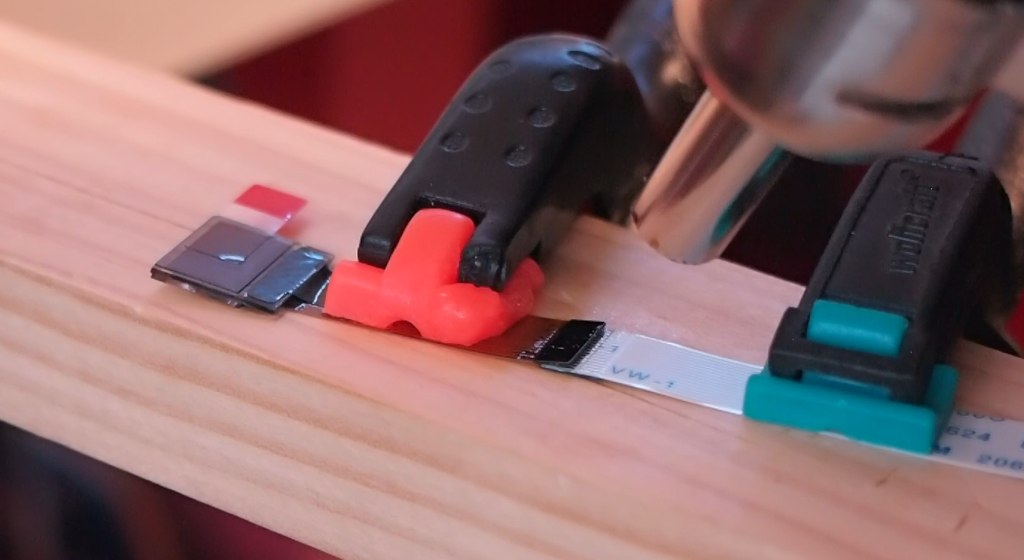
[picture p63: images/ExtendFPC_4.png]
Extended FPC Part 4


Finally use some tweezers to push the pins together. You will see some solder coming out at the
non-overlapping part of the pins I mentioned to leave out. This is also a good way to see that all pins
have sufficient solder and will connect properly:

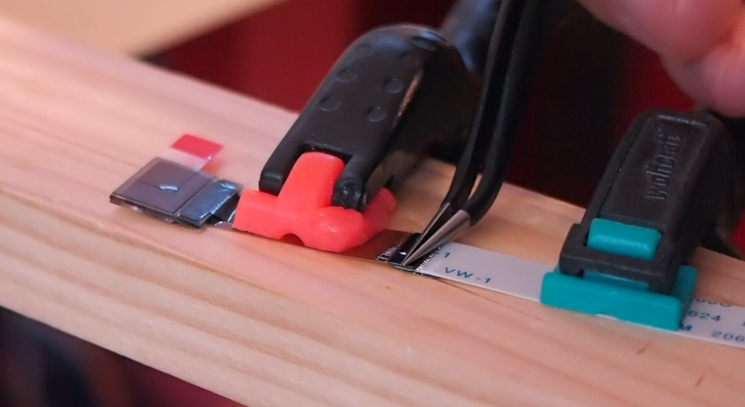
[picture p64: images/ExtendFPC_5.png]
Extended FPC Part 5


Not every display survived this surgery, so better get more from the beginning.

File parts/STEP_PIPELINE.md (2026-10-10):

# The STEP pipeline (`parts/*/step/`)

Anything a **fabricator's validator** has to accept — the CNC case, the injection-moulded
keycap stems — is **re-authored in build123d** rather than exported from OpenSCAD, because
OpenSCAD has no B-Rep kernel. `parts/case/step/` and `parts/keycap_stem/step/` are that
pipeline; each carries its own README and a `make` that builds, validates and (stems)
diffs the result back against the `.scad`.

The rules that bind code *outside* these folders are in
[`../CLAUDE.md`](../CLAUDE.md); everything below is what you need once you are inside one.

## The traps that cost real time
- ⚠️ **`Shape.scale()` scales about the SHAPE'S OWN LOCATION, not the origin** — and
  `linear_extrude(scale=)` scales the whole profile about the extrusion axis, so an
  off-centre sub-shape has to move inward as well as shrink. Left at the default the model
  still builds, still passes `BRepCheck_Analyzer`, and its tapered feature simply tapers at
  a third of the intended rate (measured: the stems' MX cross came out 4.074 instead of
  3.987 at the far end, +0.5 % volume). Nothing errors. Pass `about=(0, 0, 0)`, and check a
  tapered prism against its closed form — `A0·h·(1 − t + t²/3)` for a `1−t` taper — which is
  what caught it.
- **`loft` between two rectangles gives B-SPLINE sides; a convex hull of the 8 corners gives
  real planes.** Same solid, different surfaces: OCCT's ThruSections returns even a planar
  trapezoid as a degree-1 B-spline patch. Hulling the corners took the stem from 36 planar /
  62 free-form faces to 82 / 16. Worth doing wherever the flats are datums. ⚠️ **More
  ANALYTIC faces is not automatically better, and can be the tell of a bug**: a tapered
  off-centre arc is an *oblique* cone (its centre moves as its radius shrinks), so it must
  come back as a B-spline — the same model built with the `Shape.scale()` centre bug above
  reported 13 tidy `Geom_Cone` faces, because holding each centre fixed makes them right
  circular.
- **OpenSCAD `hull()` of polyhedra is exactly reproducible** — the convex hull of polyhedra
  is a polyhedron, so hull the vertices and merge the coplanar simplices back into n-gons
  (`parts/keycap_stem/step/hull3d.py`). Skipping the merge exports the ~60 triangles scipy
  hands back, which is the facet noise the whole exercise exists to remove.
- ⚠️ **`BRepBndLib.Add_s` on an un-meshed shape boxes the underlying SURFACES, not the
  trimmed faces**, so a cut whose prism runs past the solid inflates the bounding box — it
  reported z_max 11.30 for a stem that tops out at 7.91, and the metal case by up to 2.1 mm.
  Use `AddOptimal_s`. The printed bbox is what the recipes say to compare against the old
  mesh, so it has to be the real one.
- ⚠️ **build123d's drafting module cannot carry a full drawing sheet: OCCT's
  `Compound.make_text` SEGFAULTS.** Deterministically, on the 14th label, once the sheet
  holds the frame plus projections plus a section plus dimensions — with ~500 MB resident
  and 14 GB free, and with none of the ingredients crashing on its own. `drawing.py` takes
  geometry from build123d and **writes the SVG itself with real `<text>`** (the same shape
  as `parts/case/step/plate_svg.py`); the file is 200 KB instead of megabytes and the
  dimensions stay selectable. Related: `ExtensionLine` has no fallback for a label wider
  than its dimension line and dies with `Can't determine direction of empty Edge or Wire`
  several frames away.
- ⚠️ **The brand mark is the P, and it is `polyfabriq_logo.svg` at the repo root —
  NOT `poly_kybd/logo.svg`.** Both are a rounded key grid and they look alike in a
  file listing; only one spells a letter, as the white counter inside the grid.
  `poly_kybd/logo.svg` is the keycap mark (identical artwork to the docs site's
  `polykybd-keycap.svg`), and it sat in the stem sheet's title block for two rounds
  because its path says `poly_kybd/` and its name says `logo`. Check by content:
  the P is a SINGLE `<path>`, identical to the docs site's `polytasten-logo.svg` and
  its favicon, and 4 KB against the other's 26 KB.
  - ⚠️ **Generalises past logos: when something is reported missing but the code
    plainly draws it, test ASSET IDENTITY before rewriting the MECHANISM.** "Use the
    PolyKybd logo" was read as *the logo is not reaching the page*, and answered by
    rebuilding the whole embed path on a hypothesis — that some viewer had dropped the
    nested `<svg>` — which could not be tested here, since the only renderer in the
    container drew it correctly. That rewrite was worth having on its own merits and was
    **not the fix**; the next sentence from the user ("I wanted the P") was. The cheap
    check comes first: render the candidate assets side by side and ask *which* of them
    the page is showing. A mechanism you cannot reproduce failing is a weak hypothesis
    however plausible it reads.
- ⚠️ **Do not emit a nested `<svg>` into a deliverable, and PARSE what you write.** The
  title-block logo was inlined by keeping the source file's own `<svg>` root and
  overriding its width/height — valid SVG 1.1, which Chromium renders, and the one
  construct on an otherwise plain sheet that a conforming-enough consumer may legitimately
  drop or sanitise away. When it is dropped the sheet silently loses the only mark saying
  whose drawing it is, and everything else still renders. Keep the source's own
  `<g transform=…>` wrappers verbatim (a KiCad layer export's paths carry coordinates
  around 34…42 — lifting the `<path>`s out of the group scatters them off the sheet) and
  drop only the editor furniture: `<defs>`, `sodipodi:namedview`, and the ~570 empty `<g>`
  elements, which were 12 KB of every sheet.
  - ⚠️ **`<g … />` matches `<g[^>]*>`, so an "empty group" regex eats the next
    REAL closing tag.** The last of those 575 self-closing groups is immediately followed
    by the `</g>` that closes the group they all sit in; one pass deleted both, and the
    sheet became malformed XML. **Malformed SVG does not render partly — the browser
    gives up on the whole document and shows a blank page**, which reads as a path or a
    renderer problem, not as a defect in the sheet. `Sheet.write()` now parses the body
    before writing it, so the build fails instead.
- ⚠️ **A drawing sheet laid out by hand-tuned offsets WILL collide, and the SVG source
  never shows it — measure the sheet instead.** Two guards in `drawing.py`, both of which
  found real defects that had survived every code reading:
  - **`Sheet.group()`** collects the extent of everything drawn inside it, and view titles
    are placed from that rather than at a guessed `dy`. The guesses were wrong in both
    directions: V1's height dimension ran back across the part, and V2's title landed
    nearer the view *below* it than the view it names — which on a first-angle sheet is
    the part's own projection, so the label read as belonging to the wrong view. Titles go
    **above** all views for the same reason. Anything added to a view now moves its title.
  - ⚠️ **Sheet furniture that lives OUTSIDE the frame needs an exemption, and the
    cheapest one is to record it separately.** The ISO 5457 zone letters (1–8 / A–F on
    all four edges) sit in the margin by definition, so `check_inside_frame` failed
    them all. It now reads the recorded text extents rather than re-parsing the emitted
    SVG, which makes a `chrome=True` flag exempt from both the frame check and the
    collision report for free instead of needing a second rule in each.
  - ⚠️ **A cutting-plane mark is a SHORT stroke at each end, not a line across the
    view** (ISO 128-30 shows the plane only at its ends and at changes of direction).
    Drawn full length, the B-B mark ran the height of the plan view and through every
    horizontal dimension on it; the thin long-dash-short-dash centre line is what joins
    the two ends.
  - ⚠️ **Anything drawn outside a view's `group()` is invisible to its title.** The
    cutting-plane marks were, so the title was placed as though they were not there and
    landed exactly on the "B" tag — a collision the report found and the code reading
    would not.
  - ⚠️ **A box moves as you draw into it**, so a multi-line caption must snapshot
    `box[..][1]` before the loop; reading it again on line 2 puts that line below the
    floor line 1 just pushed down.
  - **`Sheet.report_collisions()`** lists every label overlapping another label or a
    visible outline, and **`check_inside_frame()`** raises on anything off the border. Run
    them on every build; six overlaps and three overflows were live when they were added.
  - **To LOOK at the result, use
    `.claude/skills/explain-geometry-figure/svg_view.sh`** — it crops a region in the
    FILE's own units (`svg_view.sh out.png sheet.svg x y w h [px_per_unit]`), so
    inspecting one view costs a line instead of a hand-built HTML wrapper and px/mm
    arithmetic. One session spent ~8 of those on a single drawing and got two of the
    crops wrong, while this repo had already written the same lesson about `scad_view.sh`
    and models. ⚠️ `drawing.py` works in SHEET coordinates (origin at the page centre,
    **+y up**), so a BOX needs both y bounds converted **and they swap** — the crop's
    top comes from the sheet's HIGHER y: `x = x0 + PAGE_W/2`, `y = PAGE_H/2 - y1`,
    `w = x1 - x0`, `h = y1 - y0`. Converting the lower y puts the crop one box-height
    too far down.
  - **Wrap the notes in CODE, and flow them into two columns.** Every note interpolates a
    measured value, so a hand-wrapped line overruns silently the moment a number gains a
    digit — the block had reached 2 mm off the frame. ⚠️ Two traps in the wrapper itself:
    the wrap width must allow for the hanging indent or a continuation line runs into the
    next column, and `text.split(" ")` eats the second space of a sentence gap, quietly
    reflowing the whole sheet's spacing.
  - **Line weight is an ISO 128 GROUP (0.35/0.18 or 0.5/0.25, thick : thin = 2 : 1), not a
    free choice per line.** 0.5/0.25 is right for a sparse sheet and reads as ink on a
    dense one; pick the group for the sheet and do not mix.
    ⚠️ **"Wide" in ISO means the GROUP'S wide width, not a step above it** — so the
    cutting-plane line is 0.35 in a 0.35/0.18 sheet, the same as the visible outline.
    It was 0.5, under a comment asserting ISO 128-30 required that and three lines under
    another comment saying not to mix groups. What makes a cut mark read is the 2 : 1
    contrast against the thin centre line joining its ends, which the group already
    gives you.
    ⚠️ The collision report only tracks **thick** (visible-outline) paths, so a label
    sitting on a dimension line or a thin isometric outline still passes — the 1.25U sheet
    (whose leaders reach 4.4 mm further out than 1U's) had exactly that, and only the
    render showed it. **Render both variants, not just the one you were editing.**
- ⚠️ **A detail view of a face needs the face's own DATUM in it, and `cap_body` has
  none.** The two stamp details drew a rectangle with two letters in it and nothing to
  locate them from, because `stamp_face()` takes its face from `cap_body`, which has no
  MX slot — `mx_stem` cuts the cross *after* tilting and raising the cap. Pull the same
  cross back through that placement (`Rot(-angle) * Pos(0,0,-extra_len) * cross_cut(…)`)
  and cut it into the cap body, and the slot appears in the detail. ⚠️ Keep placing the
  stamp against the UNCUT face, as `_engraving` does — centring it in a face with a hole
  in it moves it.
- ⚠️ **A snap helper earns its keep by REFUSING.** The stem sheet's `snap` rejected a
  dimension anchor — *"no section vertex within 0.6 of (-5.65, 4.52)"*, and only on the
  wider variant — and the vertex pair confidently labelled "the flange" turned out to be
  the inside of the pocket, which moves with `u_size`. Taking the nearest corner quietly
  would have shipped a wrong label on one variant and a wrong anchor on the other.
  Corollary: **name a dimension by what it MEASURES when you have not verified which
  feature it is.**
- ⚠️ **Derive a scale caption from the number that drew the view.** It was a literal
  beside each view's title; the isometric's scale went 1.6 → 2.4 and the caption went on
  saying 1.6:1 — on the one label a reader might actually measure against.
- ⚠️ **Anchor every section dimension on a REAL VERTEX of the cut, and make the helper
  raise when it cannot.** Dimensions computed from model constants are what "floating in
  the air" looks like: the display seat is 1.10 below a top face tilted −7°, so the
  height the arithmetic names is not a height anything on that cut actually has. `snap()`
  takes the nearest section vertex and raises past a tolerance — a silent snap to the
  wrong corner is a wrong number on a fabrication drawing, which is worse than a build
  that stops.
- ⚠️ **A dimension line is not automatically better than a leader — on a section it is
  frequently worse.** A feature in the middle of a cut (the stem boss behind the outer
  skirt) can only be dimensioned by dragging extension lines across hatched material to
  reach the outside. A leader touches the vertex the number comes from and crosses
  nothing.
  - **Anchor it on the wall NEAREST the note.** Both walls of a Ø5.50 boss are the same
    feature, so either is geometrically correct and nothing in the model says which to
    pick — but a leader to the far wall crosses the whole cut, and the reader has to work
    out that it means the cylinder rather than whatever it passed over on the way. The
    short reach is also what keeps the note out of the neighbouring view.
- ⚠️ **Get a cutting-plane arrow's direction from the section PLANE, not by eye.**
  build123d's `Plane.XZ` carries its normal on **-Y** and `Plane.YZ` on **+X**, so two
  sections of the same part are viewed from opposite senses and their arrows point
  opposite ways on the same plan view. Reason it out of the plane's `z_dir`; a guess is
  right half the time and a reversed arrow tells a fabricator to keep the wrong half.
- ⚠️ **A dimension's LABEL will outlive the geometry it was written from — check it
  against the model, not against the variable name.** The stem sheet carried "5.05 slot
  depth" through three revisions; the number is the height of the stem *boss*, and the
  slot is not bounded by it at all (the cross is cut clean through into the cap floor).
  The real bound has no closed form — the cap floor is tilted — so it is now bisected
  for. Same shape as the ink-measurement rule above: the source said `h_cyl` and the
  label said what someone assumed `h_cyl` meant.
- ⚠️ **Draw anything a reader could get backwards; do not describe it.** The stem sheet
  said the second stamp was "mirrored … reads correctly from below" for three revisions.
  It is `rotate([180, 0, 0])` — TURNED, not mirrored: it reads normally when the part is
  flipped front-to-back, and appears upside down in a projected view-from-below. Nobody
  caught it because an `S` is 180°-symmetric and only the `β` shows the difference. It
  was caught the moment the view was actually drawn and the picture disagreed with the
  caption.
- ⚠️ **A STEP re-export rewrites the file even when the solid is byte-identical** (the
  header carries a timestamp), so `make` always leaves both files "modified". Check
  below the header before committing —
  `diff <(git show HEAD:<path> | tail -n +12) <(tail -n +12 <path>)` — and `git checkout`
  when it is empty, or you commit 1.3 MB of clock. Same rule as the STL facet-order note
  above, different mechanism.
- ⚠️ **Hatch a section with thin RECTANGLES, not lines.** A line lying exactly in the
  section face's plane makes OCCT's edge-face common return **nothing at all**, silently —
  so an empty hatch reads as "no solid here" rather than as an error. Below ~0.05 mm the
  rectangle vanishes into the boolean tolerance too.
  - ⚠️ **Three separate things then decide whether it reads as hatching or as scribble,
    and the first draft had all three wrong.** They generalise to any ruled fill.
    **(1) Order the sliver along the RULING.** The rulings ran along `(-sin a, cos a)`
    while their two ends were picked along `(cos a, sin a)` — the perpendicular, on which
    a sliver's projection is near-constant, so "the ends" were two arbitrary corners of
    it. That alone produced the ragged, unequal, randomly-short rulings.
    **(2) ONE lattice for the whole cut, not one per face.** Each face was ruled from its
    own bounding-box centre, so two faces of one cut carried the same spacing at
    different *phases* — and on a section, hatching out of step means two materials.
    **(3) Clamp the sliver to the ruling's CENTRE LINE, not to its own corners.** A strip
    has width, so at an angled boundary its furthest corner lies past the centre line's
    true crossing: that is hatching running outside the outline. Trimming a fixed
    percentage off each end (the first fix) cures it by leaving *every* ruling short of
    the outline instead, and takes as much off a 1 mm ruling as off a 10 mm one. Project
    the corners onto the centre line and both ends land exactly on the boundary — which
    also makes the strip width free above the floor above (counted on both cuts: 0.02,
    0.04, 0.06 and 0.10 mm return the same rulings).
- ⚠️ **A positive control needs its NEGATIVE half, or it passes for the wrong reason.**
  `verify.py --self-test` widens the MX cross and asserts the checks catch it — the
  discipline this file already preaches. Its cross-measurement half kept its own copy of
  the expected span with the taper omitted, which is 0.0033 mm at z = 0.30, i.e. above
  its own 2e-3 threshold: it therefore reported "caught" against a **correct** model and
  asserted nothing. Two fixes, both general: give the two call sites **one** shared
  definition so they cannot drift (`cross_span()`), and assert the comparison is
  **quiet on the unmodified model** as well as loud on the broken one. Same family as
  the gtest-ANSI and never-applied-mutation traps in `qmk_firmware/CLAUDE.md`: every one
  of them is a harness reporting the answer that means "your checks are worthless" and
  reading as success.
- ⚠️ **A verification that never opens the SHIPPED file verifies the code, not the
  deliverable.** Checks 0-3 all ran on a solid built in memory, so `make verify` was
  green against a stale export, a half-written one, or one built by another build123d —
  the three ways the committed STEP can actually be wrong. Check 4 re-imports the
  artifact and compares it back. The general form: when a target's whole purpose is to
  bless a file, it has to read that file.
- ⚠️ **A check that cannot run must FAIL, not skip.** Missing openscad made checks 2 and
  3 — the entire `.scad` parity argument — quietly vanish while the run still printed
  `PASS`, i.e. it reported success having compared the stem against nothing. Same family
  as the fail-open self-test above: the dangerous outcome is never the loud one. The
  escape hatch (`--allow-no-openscad`) exists, names itself in the output, and is not
  the default.
- ⚠️ **Gate a check on the dependency IT needs, not on the one the block around it
  needs.** The closed-form cross-prism check — the one that caught `Shape.scale()`
  above — sat under `if not have_scad: continue`, so a machine without **openscad**
  silently dropped the most valuable check in the file for an unrelated missing tool.
- ⚠️ **Pin the engraving font by DIGEST, and remember the cache is shared.** The β/S
  outlines cut into a steel cavity come from a `main` URL, so an upstream change
  silently alters tool geometry; `font.py` verifies SHA-256 and stops with instructions.
  ⚠️ `build_stems.sh` fetches the same URL into the same cache with no verification, so
  a mismatched cache is **re-downloaded, not rejected** — rejecting would fail on a file
  the sibling script legitimately put there. Only a fresh download that still mismatches
  is fatal, and changing the digest means re-exporting both STEPs.
- **Diff the re-authored solid against the `.scad` both ways, and prove the diff can fail.**
  `parts/keycap_stem/step/verify.py` measures the critical feature off a section of the real
  solid, compares volume + bbox against an OpenSCAD export of the same call, and runs
  `A\B` and `B\A` through OpenSCAD; `--self-test` widens the MX cross by 0.10 mm and
  asserts the checks reject it. That self-test also shows why the cheap check is not enough:
  a 0.10 mm error on the one tolerance-critical feature is **+0.66 % volume**, i.e. it sails
  through a 1 % volume gate while the boolean diff and the direct measurement both catch it.
- ⚠️ **Engraved text is where three SILENT font traps live, and each one changes the glyph
  a toolmaker would cut.** (1) OCCT does **not** read fontconfig, so `font="Noto"` — what
  `keycap_stem.scad` asks for — prints *"unable to find font 'Noto'; 'FreeSans' is used
  instead"* and carries on; (2) the real family name `"Noto Sans"` finds the file but
  renders the **variable font's default instance**, not Bold; (3) OpenSCAD's `text(size=)`
  is a **point size at 100 DPI** while build123d's `font_size` is the em in mm, so the same
  nominal 3 comes out **100/72 = 1.389× larger** in OpenSCAD. Measured on one string: areas
  4.068 / 2.330 / 3.563 mm² for the three spellings, and cap height 3.058 vs 2.202 mm for
  the size convention. Pin the font to a FILE (`parts/keycap_stem/step/font.py`
  instantiates `wght=700` and passes `font_path=`) and convert the size. Trap (3) is the
  same shape as `fontconvert`'s `-s` being points at 141 DPI.
- ⚠️ **Noto Sans draws U+03B1 single-storey and TAILLESS, so the engraved `α` reads as a
  Latin `a`** — the printed plates have carried the ambiguous glyph all along, and it is a
  font-design fact, not a substitution bug (the cmap maps `alpha` and `a` to different
  glyphs; DejaVu's alpha has the usual right-hand tail, Noto's does not). Check a revision
  marker by RENDERING the glyph, not by confirming the codepoint. The **moulded** stems
  moved to `β` for this reason and a better one: they differ from the 3D-printed
  prototypes, so `parts/keycap_stem/step/stem_model.py` `REVISION` is deliberately **not**
  a mirror of `keycap_stem.scad:2` — the one constant there that isn't.
- ⚠️ **`build_stems.sh --fetch-font` FETCHES AND THEN RE-EXPORTS ALL SIXTEEN PLATES.** Its
  name and its help line both read as "install a font", and CLAUDE.md already warns that it
  changes which Noto resolves — but with no variant names it also runs the whole export
  loop, so committed meshes get rewritten against the new font. It rewrote three before
  being killed (2026-08-19). Use `make -C parts/keycap_stem/step font`, which shares the
  same cache path and stops after the download.
- ⚠️ **Find a feature by what it IS, not by "the smallest face".** A section-measuring check
  that took the smallest face in the plane silently started reporting the inside of an
  engraved `α` — 0.90 × 1.30 with r0.60/0.84, entirely plausible numbers for an MX cross —
  once the stamp was switched on, because the cap is tilted −7° and that sweeps the
  engraving through the section height. Select on identity (an inner wire centred on the
  stem axis, smaller than the stem OD), not on an ordering that happens to work today.
- **Read a constant's MEANING out of the `.scad`, not its name.** Two in `keycap_stem.scad`
  read as one thing and are another: `u_size = 1.22` is a half-width-extension dial fed to
  `(u_size − 1)·2·5`, not a keycap unit count; and `mx_cross` 4.35 / `mx_cross_width` 1.4
  describe the plus *before* `offset(r = −0.3)`, so the MX opening is **4.05 × 1.10**.
  Quoting either to a fabricator is a 0.3 mm error on the part's one critical fit.

## The moulded keycap stem specifically
- **The MX slot is deliberately TIGHTER than Cherry's published keycap slot — this
  table is the reasoning, and it lives here rather than on the drawing.** It was a
  block on the sheet for two revisions; it is background for us, not an instruction to
  a moulder, so the drawing now carries only the conclusion (note 1: gauge against a
  real switch stem, and the relief bulges are what make the fit work).

  | | this part | Cherry keycap spec | real switch stem |
  |---|---|---|---|
  | slot across | 4.05 (bulges 4.11) | 4.10 +0.05 | — |
  | arm width | 1.10 (bulges 1.21) | 1.17 ±0.02 | N/S 1.05–1.10, E/W 1.25–1.30 |
  | corner fillet | R0.30 | not published | — |
  | lead-in | 4.61 sq × 0.30 | not published | — |

  Cherry's keycap slot spec via deskthority / telcontar.net. The switch stem's own cross
  is **asymmetric** and Cherry's uniform 1.17 slot already interferes ~0.07 on two sides;
  ours is tighter still, so the fit rests on the four relief bulges. Verify on a moulded
  first article, not by CMM.
- **Provenance, also deliberately off the sheet:** the moulded geometry is re-authored
  from `keycap_stem.scad` in build123d, and `verify.py` is what keeps the two agreeing.
  The STEP is the shape reference and the drawing governs tolerance, material and
  finish — that division is worth stating to a fabricator, and *is* on the sheet; where
  the shape came from is ours.
- ⚠️ **The three 0.4 × 3.0 × 0.3 tabs are a FUNCTIONAL click feature, not a print
  aid** — they stand 0.2 mm proud and are what makes the transparent relegendable
  cap click on. An earlier reading of `keycap_stem.scad` had them down as a
  sprued-plate artefact, and the first draft of the drawing invited the moulder to
  delete them; both were wrong. They are named (`CLICK_TAB_*`), dimensioned on the
  sheet, and note 4 says explicitly that they must not be removed. The general
  lesson: a small feature with no comment is not thereby decoration — ask before
  writing "optional" onto a fabrication drawing, because that is the one document
  the shop will act on without asking back.

## Why the build123d pin exists

_Moved verbatim from `CLAUDE.md` on 2026-10-10._

- ⚠️ **BOTH pipelines pin their toolchain (`BUILD123D_PIN`, currently 0.12.0) and
  refuse to run on another version.** The geometry is version-sensitive: 0.13.0 projects
  the stem sheet
  materially differently (111 of 2087 paths, 8 of them structural, a 43 mm coordinate
  delta) and rewrites the STEP below its header too, so an unpinned `pip install`
  silently rewrites a fabrication deliverable. The check is an ORDER-ONLY prerequisite
  of the outputs, which means it runs on `make`, `make step`, `make drawing` and
  `make verify` alike, **including when every output is already up to date** (verified:
  a wrong pin exits 2 on all four with nothing to rebuild) — an order-only prerequisite
  is still updated, it just does not drag the target with it. That property matters more
  in `case/step/`, where a needless rebuild costs ~15 minutes (903.7 s for the right side
  alone). The case pin is **verified, not assumed**: rebuilding on 0.12.0 reproduces the
  committed `metal-case-left.step` byte for byte below the header, and
  `metal-case-right.step` to one DIRECTION written `(-0.,-0.,-1.)` rather than
  `(0.,0.,-1.)` — the same direction, since `-0.0 == 0.0`.
  **Compare a re-export as an unordered POINT MULTISET, never byte-wise** — even on the
  right version the SVG path order is not stable RUN TO RUN on one machine (18-55
  segments reshuffle, geometry and text identical), the SVG analogue of the STL
  facet-order rule below. So a byte diff is noise by default, and it cannot tell that
  noise apart from a real geometry change.

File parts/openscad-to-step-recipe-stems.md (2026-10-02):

# Recipe: keycap stems (S, 1U + 1.25U) as clean STEP + a technical drawing

**Goal.** Produce, for the two stem variants an injection moulder needs — **S 1U** and **S 1.25U** —
a real **B-Rep** STEP plus a dimensioned technical drawing, so a toolmaker can quote and cut without
guessing at facet noise.

**This follows the pattern already proven on the case** —
[`case/openscad-to-step-recipe.md`](../case/openscad-to-step-recipe.md) and the working toolchain in
[`case/step/`](../case/step/). Read that first; everything here is the same method on a much simpler
part. **Do not fall back to STL → STEP.** The case recipe records exactly why: OpenSCAD has no B-Rep
kernel, so the mesh export lands as ~14,900 flat facets with ~0.15 mm stitching, and the fabricator
flags it. A stem is worse in one respect — its critical feature is a **1.4 mm MX cross** whose fit
decides whether the keyboard works, and a faceted cross is not a datum anyone can cut to.

## Why the stem is the *easier* case

The case needed re-authoring because `hull()` and `minkowski()` cannot survive as clean geometry.
⚠️ **The stem does use `hull()`** — `keycap_stem.scad:83` hulls two tapered bodies (that is how the
1.25U gets its width) plus the three click tabs. But every member is a **polyhedron**, and the convex hull
of polyhedra is a polyhedron, so it comes back exactly from a hull of the vertices (`step/hull3d.py`);
there is no `minkowski()` anywhere. The rest is `linear_extrude(..., scale=)`, a tapered extrude that
is a native exact operation. So the port is close to line-for-line, with no approximation anywhere:

| `keycap_stem.scad` | build123d |
|---|---|
| `hull(bodyA, bodyB, tabs…)` | convex hull of the vertices → planar faces (`hull3d.py`) |
| `linear_extrude(h, scale=r)` | hull of the 8 corners — **not** `loft`, see below |
| `offset(r=-mx_cross_fillet)` on the cross | `fillet()` on the cross edges — a *real* fillet |
| `circle(d=…, $fn=64)` | `Circle(r)` — a true cylinder, not 64 facets |
| `square([x,y], center=true)` | `Rectangle(x, y)` |

## Parameters — copy these as Python constants

From `keycap_stem.scad` (keep them named so the port stays parametric):

```python
STEM_X, STEM_Y          = 15.5, 15.475
STEM_HEIGHT             = 5.65
STEM_TOP_BOTTOM_RATIO   = 0.85     # -> ~11.6 deg draft, see below
INSIDE_X, INSIDE_Y      = 13.3, 13.3
INSIDE_HEIGHT           = 3.0
MX_CYLINDER             = 5.5
MX_CROSS                = 4.35     # cross arm length
MX_CROSS_WIDTH          = 1.4      # cross arm width  <-- tolerance-critical
MX_CROSS_FILLET         = 0.3
DISP_X, DISP_Y          = 12.2, 12.1
DISP_HEIGHT             = 1.1
DISP_Y_CENTER_OFFSET    = 1.345
CABLE_STEM_X, CABLE_STEM_Y = 9.0, 2.12
CABLE_THICKNESS         = 0.5
```

**The two variants.** Both are the `S` profile — `angle=-7, extra_len=1.5`, from
`variants/keycap_stem_revAlpha_1U*_S_10p.scad`. Only `u_size` differs:

| Variant | Call | Body width |
|---|---|---|
| **S 1U** | `mx_stem(u_size=1, angle=-7, extra_len=1.5)` | 15.50 |
| **S 1.25U** | `mx_stem(u_size=1.22, angle=-7, extra_len=1.5)` | 19.90 |

⚠️ **It is `u_size = 1.22`, not 1.25** — an earlier draft of this recipe read it as a keycap unit
count. It is not: `u_size` feeds `(u_size - 1) * 2 * 5`, i.e. it is a **half-width-extension dial**,
so 1.22 grows the body by 2 × 2.2 mm. The `.scad` is the authority.

⚠️ **`MX_CROSS` 4.35 and `MX_CROSS_WIDTH` 1.4 are NOT the cross size** either. They describe the plus
*before* `offset(r = -MX_CROSS_FILLET)`, so the opening the switch actually enters is **4.05 × 1.10**
with r0.30 corner fillets. Quoting the constants to a moulder overstates it by 0.3 mm on both.

**The `txt=` stamp IS carried** (decided 2026-08-19): `S    β`, engraved 0.30 mm into the display-seat
floor and the pocket ceiling. Marking the revision is the point of it, so drawing note 10 asks for the
character on a **replaceable insert** in the cavity — the next revision is then a plug swap, not a tool
edit. Both stamps are zero-draft; neither sits on a fit surface. `build.py --no-engrave` drops it.

⚠️ **The moulded revision is `β` while `keycap_stem.scad` stays `α`** — the moulded part differs from
the 3D-printed prototypes, so it says so. `stem_model.REVISION` is the one constant that deliberately
does not mirror the `.scad`. It also sidesteps a legibility problem: **Noto Sans draws U+03B1
single-storey and tailless, so `α` reads as a Latin `a` at stamp size** (DejaVu's has the usual tail);
`β` has no twin. The sheet spells the codepoint out either way.

⚠️ **Getting the glyph right is the hard part, not adding it.** OCCT does not read fontconfig, so
`font="Noto"` — what the `.scad` asks for — falls back to FreeSans with a warning nobody reads, and the
family name resolves the *variable* font's default instance rather than Bold; and OpenSCAD's
`text(size=)` is a **point size at 100 DPI** while build123d's `font_size` is the em in mm, a 1.389×
difference. All three are silent. `step/font.py` pins the file and `TEXT_EM` does the conversion; the
step README has the measured numbers.

## Draft — computed, not eyeballed

`stem_model.draft_angles()` derives these from the model, and the drawing quotes it, so the sheet
cannot drift from the geometry. A `linear_extrude(scale=s)` over height `h` moves a wall that starts
`w` from the axis inward by `w·(1−s)`, so the draft is `atan(w·(1−s)/h)` — it depends on **how far out
the wall is**, which is why one number cannot describe a tapered profile:

| Feature | Wall at | Taper | Over | Draft |
|---|---|---|---|---|
| Outer body X / Y | 7.750 / 7.738 | `0.85` | 5.65 mm | **11.63° / 11.61°** ✅ |
| Inside pocket | 6.650 | `0.85` | 3.0 mm | **18.39°** ✅ |
| Centre pocket | 7.017 | `0.7225` | 3.0 mm | **32.99°** ✅ |
| Cross arm flats (`:163`) | 0.550 | `0.97` | 11.3 mm | **0.084° ⚠️** |
| Cross arm tips | 2.025 | `0.97` | 11.3 mm | **0.308° ⚠️** |
| **Display seat** (`:116`) | 6.100 | **`1`** | 1.1 mm | **0° ⚠️** |

⚠️ The earlier hand-derived version of this table was wrong in two places (21.2° for the inside pocket,
1.18° for the cross) — that is what "derived by inspection, not by running the toolchain" was worth.

Two things to raise in the quote rather than let a moulder discover them:
- The **display seat is zero-draft** (`linear_extrude(height=disp_height, scale=1)` over
  `DISP_X × DISP_Y`), as is its cable relief. At 1.1 mm deep it often releases as-is; say so anyway.
- The **cross has almost no draft** — 0.08° on the flats. It opens *downward*, so the core pin
  withdraws in the correct direction, but with very little relief, and the stem wall at the arm tip
  is only **0.67 mm**. Everything else clears the 0.5–1° minimum by 10× or more, so **draft is not a
  redesign item.**

## Build it

Mirror `case/step/` — same layout, same driver pattern:

Built as **`parts/keycap_stem/step/`**, not the `parts/step/` this recipe first suggested — the repo
rule is one folder per part group with its scripts beside its sources, and the case precedent is
`parts/case/step/`. Output goes to `parts/export/keycap_stem/` like every other generated mesh.

```
parts/keycap_stem/step/
  stem_model.py      # build123d model, both variants from one parametric function
  hull3d.py          # OpenSCAD hull() as an exact polyhedral convex hull
  build.py           # emits stem_S_1U.step, stem_S_1U25.step
  validate_step.py   # delegates to case/step/validate_step.py rather than copying it
  verify.py          # measures the cross + diffs against the .scad (with a self-test)
  drawing.py         # the technical drawing
  Makefile
```

```bash
pip install build123d scipy fonttools
make -C parts/keycap_stem/step            # step + drawing + validate
make -C parts/keycap_stem/step verify     # needs openscad
```

**Verify against the SCAD, do not assume.** `verify.py` does this, and `case/step/render_compare.py`
exists precisely because a re-authored model can drift from its source. The same standing rule from
[`CLAUDE.md`](../CLAUDE.md) applies: *compare meshes as a sorted facet multiset, and pair any
clearance test with a positive control.* For the stem the specific checks that matter:

1. **MX cross**: measure the **finished opening** on the STEP — flats **4.05 × 1.10**, corner
   fillets **R0.30**, and the four relief bulges that take the outer span to **4.11**. ⚠️ NOT
   4.35 × 1.4: those are the `MX_CROSS` / `MX_CROSS_WIDTH` source constants *before*
   `offset(r = -0.3)`, so measuring to them accepts an opening 0.30 mm oversized on both
   axes — the exact error the warning near the top of this file is about, written here as an
   instruction. `verify.py` check 1 measures the real values off a section of the solid.
2. **Volume delta** SCAD-mesh vs STEP solid: should agree to well under 1 % (only the facet
   approximation of the cylinders differs).
3. **The keycap cover interface** — the transparent relegendable caps are **off-the-shelf POS parts**,
   so that mating dimension is fixed by a supplier you do not control. Treat it as a hard datum.

## The technical drawing

build123d exports 2D projections through OCP; `case/step/plate_svg.py` is the closest existing
precedent for SVG output. `drawing.py` should emit, per variant, an **A3 sheet** carrying:

- **Four orthographic views** (right / front / above / **below**) + one isometric, projected from
  the STEP solid. ⚠️ A4 was the first target and it does not work: five views, three details, a
  section, the notes and a fit table all had to shrink until the 10:1 detail stopped being a
  detail. A3 prints down to A4 at 71 % if a reader wants it that way. The view from **below** is
  not optional either — the inner switch-clearance chamfer appears in no other view.
- **A section through the MX cross** — the feature that decides fit, so it needs its own view.
- **Number every view** and say the scale under each: a sheet with ten framings and five
  different scales is unreferenceable in an email otherwise. The shipped mapping is
  **V1–V4** ortho (right / front / above / below), **V5/V6** sections A-A and B-B,
  **V7** the MX cross at 10:1, **V8/V9** the two stamp details, **V10** isometric.
- **Dimensioned**: the MX opening **4.05 × 1.10 ±0.03** with **R0.30** corner fillets and the
  four relief bulges, `MX_CYLINDER` 5.5, overall 15.5 × 15.475, height 5.65, display seat
  12.2 × 12.1 × 1.1, draft angles called out. ⚠️ **Not 4.35 × 1.4** — those are the
  pre-`offset()` source constants, and the warning against quoting them to a moulder is
  eighty lines above this list. It said so and this line did it anyway.
- **A tolerance block.** ⚠️ This is the point of the whole exercise: **the drawing governs, the STEP
  conveys shape.** State a general tolerance (e.g. ±0.1) and tighten only the cross and the cover
  interface. Without it a toolmaker will cut to the model and the tolerance question resurfaces at
  first article.
- Material and finish, once chosen — see the material note below.
- Revision, date, part number, and the engraving — see below; it is present, and it is **β**.
- **The three click tabs, dimensioned.** ⚠️ They read like a 3D-printing sprue artefact and they
  are not: they are what makes the transparent cap click on. Say so on the sheet. A fabrication
  drawing is the one document a shop acts on without asking back, so "optional" written there is
  a decision, not a question.

## Material — **ABS** (decided 2026-08-19)

It is the standard keycap material and its low shrink (0.4–0.7 %) is what protects the MX cross
tolerance. POM was the alternative *if* the stem snap-retains the display or cover — better fatigue
under repeated engagement, but ~2 % shrink the cross geometry would have to compensate for; PBT and
nylon are both worse here (higher shrink, and nylon is hygroscopic).

⚠️ **Shrink compensation is NOT in the model.** The STEP and the drawing are the **finished part**;
the cavity is cut oversize by the toolmaker, who states the rate used (drawing note 9). That is the
normal division of labour and it keeps one model serving both the printed and the moulded part — do
not fold a shrink factor into `stem_model.py` without saying so on the drawing.

## ✅ Status — DONE (2026-08-18, reviewed and reworked 2026-08-20)

Executed end to end; `parts/keycap_stem/step/` is the working toolchain and
[its README](keycap_stem/step/README.md) carries the results and the traps. Both deliverables are in
`parts/export/keycap_stem/`: `stem_S_1U.step` / `stem_S_1U25.step` and their `*_drawing.svg`.

Both STEPs pass the acceptance test — one closed solid, **142 faces** (108 planar, 34 curved), max
edge tolerance **2.1e-07 mm**. Against an OpenSCAD export of the same call: bounding box identical
to 5 dp, volume **+0.111 % / +0.081 %**, and a two-way boolean difference of 0.62 mm³ one way and
0.011 mm³ the other — all of it the `.scad`'s tessellation (a 128-gon stem, `$fn=64` cross relief)
against true analytic surfaces, which is the difference this exercise exists to create.

⚠️ **That comparison runs with the stamp OFF, deliberately** (`verify.py` `engrave = False`): the
moulded stamp is **β** and the `.scad`'s is α, so an engraved diff would report the intended
difference as an error every run. The stamp is checked separately, and more usefully — `verify.py`
measures its clearance to the seat edge on both faces (0.80 mm all round, against the 0.80 mm
requirement) rather than folding it into a volume number where 5 mm³ of glyph would drown the
0.6 mm³ of tessellation the diff exists to see.

Three corrections this recipe needed once it was actually run, all now folded in above: the stem
**does** use `hull()`; `u_size` is 1.22 and is not a unit count; and the cross opening is 4.05 × 1.10,
not 4.35 × 1.4. The draft table was recomputed. Everything else held.

The build123d gotchas worth knowing before the next port are in the step README: `Shape.scale()`
defaults to scaling about the shape's own location (a silent 0.5 % geometry error); OCCT's text kernel
**segfaults** when a drawing sheet gets big enough, which is why `drawing.py` writes its own SVG; and
the three font traps above, each of which silently changes the glyph a toolmaker would cut.

### The 2026-08-20 review round

The first sheet was geometrically correct and typographically a mess, and none of it was visible
in the code. What the review changed, and the two guards that now stop it recurring:

- **A4 → A3**, four ortho views (the view from **below** was missing, and the switch-clearance
  chamfer shows in no other view), numbered views V1–V8, a **stamp proposal** view at 5:1, an axis
  triad on every view, a **fit table** against Cherry's published keycap slot, a fuller title block
  with the PolyTasten logo, and first-angle-projection marking.
- **The tabs were mis-documented as a print aid and the sheet invited their deletion** — corrected
  everywhere; they are a click feature and are now dimensioned.
- **The stamp** moved to β, `S` and `β` swapped so β's descender has room, gap widened from a
  measured 0.21 mm clearance to ≥ 0.80 mm all round.
- **Layout is now measured, not guessed** — `Sheet.group()` places each title from the extent of
  what the view actually drew, `report_collisions()` lists label-on-label and label-on-outline
  overlaps, and `check_inside_frame()` raises on anything past the border. Between them they found
  six collisions and three overflows that had shipped in the first sheet. ⚠️ **Render both variants**:
  the 1.25U leaders reach 4.4 mm further out, and one collision existed only there.
### The second review round (2026-08-20)

Seven more items, of which three were substantive:

- **Sections both ways.** A-A along X shows the slot; nothing in it said how the flex cable
  gets out, so **V9 section B-B** cuts the perpendicular plane and carries the cable route
  (2.12 relief, 1.10 deep, the FFC exit's 14.9° flare), with the 9.00 relief width on V3.
  ⚠️ Get the cutting-plane arrows from the section PLANE, not by eye: build123d's `Plane.XZ`
  has its normal on -Y and `Plane.YZ` on +X, so the two sections are viewed from opposite
  senses and their arrows point opposite ways on the same plan view.
- ⚠️ **The pocket stamp is TURNED 180°, not mirrored — and the sheet said "mirrored" until
  V10 was drawn.** The `.scad`'s `rotate([180, 0, 0])` is a flip about X: the stamp reads
  normally when the part is turned over front-to-back, and appears upside down in a
  projected view-from-below. The prose had been carried forward unchecked through three
  revisions because an `S` is 180°-symmetric and only the `β` shows the difference. **Draw
  anything a reader could get backwards.**
- ⚠️ **"5.05 slot depth" in A-A was wrong twice**: the number is the height of the stem
  BOSS, and the slot is not bounded by it at all — the cross is cut clean through into the
  cap floor. The real bound (z = 5.83) has no closed form, because the cap floor is tilted;
  `slot_top_z()` bisects for it. A dimension whose label was written from the variable name
  rather than from the geometry.
- Line weights dropped a full ISO 128 group (0.5/0.25 → 0.35/0.18): the heavier group is
  correct for a sparse sheet and reads as ink on a dense one.
- Notes that repeat a title-block cell were deleted, the rest are **wrapped in code** and
  flowed into two balanced columns — hand-wrapped lines silently overrun the moment an
  interpolated value gains a digit, which is how the block reached 2 mm off the frame.
- Axis triads are placed from each view's OUTLINE box, not a fixed offset, so a wider
  variant cannot push a dimension under one.

### The fifth review round (2026-08-20)

- **ISO 5457 grid reference** on all four edges — 1–8 across, A–F down, ~50 mm fields
  for A3 — so a feature can be called out as "the boss, D3" without anyone counting
  views. ⚠️ Those letters live OUTSIDE the drawing frame by definition, so
  `check_inside_frame` now reads the recorded text extents rather than re-parsing the
  SVG; a `chrome=True` flag is then exempt from both that check and the collision report
  for free.
- ⚠️ **A detail view of a face needs that face's own datum in it.** V8/V9 were a
  rectangle with two letters and nothing to locate them from, because `stamp_face()`
  takes its face from `cap_body` — which has no MX slot, since `mx_stem` cuts the cross
  after tilting and raising the cap. Pulling the cross back through that placement and
  cutting it into the cap body puts the slot in the detail. Both details also gained the
  stamp's own centre line and its offset from the stem axis.
- The notes lost the 3D-printing comparisons and the Cherry reference: reasoning for us,
  noise on a moulder's sheet.
- Views shifted down into the space the notes vacated; axis triads moved off the
  dimensions they had drifted onto.

### The fourth review round (2026-08-20)

Four items, all layout, and two general lessons fell out of them:

- ⚠️ **A snap helper earns its keep by REFUSING.** Adding dimensions to V5 tripped
  `snap` — *"no section vertex within 0.6 of (-5.65, 4.52)"*, and only on the 1.25U
  variant — and the vertex pair confidently labelled "the flange" turned out to be the
  inside of the pocket, which moves with `u_size`. Name a dimension by what it MEASURES
  when you have not verified which feature it is.
- ⚠️ **Derive the scale caption from the number that drew the view.** `SCALE_ISO` went
  1.6 → 2.4 and the isometric's caption went on saying 1.6:1 — the one label a reader
  might measure against.
- V5 and V6 to 3:1 and V10 to 2.4:1, with the height dimensions on the sections (the
  front view sees the boss and the skirt only as hidden lines). V6 now shows that the
  **pocket ceiling is not parallel to the moulding face** — 4.96 at the front, 4.17 at
  the back, which is the −7° cap tilt and decides which end of the core is thinnest.
- The notes moved to the bottom of the sheet, and V8's stamp-clearance callout became a
  real dimension instead of a leader long enough to run across the 10:1 detail.

### The third review round (2026-08-20)

Eleven items.  The ones with a general lesson in them:

- ⚠️ **Anchor every section dimension on a REAL VERTEX of the cut.** "Dimensions float in
  the air" was exactly right: they had been computed from model constants, and on a
  section that does not work — the display seat is 1.10 below a top face tilted −7°, so
  the height the arithmetic names is not a height anything on that cut has. `section()`
  now returns its vertices and `snap()` raises rather than taking the wrong corner.
- ⚠️ **On a section, a leader often beats a dimension line.** A feature in the middle of
  the cut (the stem boss, behind the outer skirt) can only be dimensioned by dragging
  extension lines across hatched material to reach the outside.
- ⚠️ **A cutting-plane mark is a SHORT stroke at each end** (ISO 128-30), not a line
  across the view — drawn full length it ran the height of the plan view and through
  every horizontal dimension on it.
- ⚠️ **Overlaying a second shape on a laid-out view means undoing TWO re-centrings**
  (`Drawing`'s own centre of mass, then the view's bounding-box shift), and correcting
  only one is worse than correcting neither: the faint stamp landed plausibly in the
  middle of the view rather than visibly nowhere.
- **What the drawing is FOR decides what goes on it.** The axis convention (drawn on
  every view anyway), the `.scad` provenance, and the whole Cherry fit table came off the
  sheet and into CLAUDE.md. They are reasoning for us, not instructions to a moulder.
  Notes went to three wrapped columns; V3 to 3:1 because it carries the most detail.
- View numbers were reassigned so the sections read together: V5/V6 sections, V7–V9
  details, V10 isometric.

- ⚠️ **A dimension anchored through `Drawing` lands in mid-air** unless you keep the projection's
  own mapper: `Drawing` projects about the shape's centre of **mass**, and the view is then
  re-centred on its bounding box, so a hand-computed sheet point is off by the difference (7.9 mm
  on the front view — the "7.91 dimension starts from somewhere outside" report). `view()` returns
  a model→sheet mapper for exactly this.

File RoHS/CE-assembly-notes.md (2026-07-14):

# CE technical file — final assembly notes

To-do list for when all sections are combined into one master PDF. (Left for later on purpose — page
numbers and section order stay in flux until every part exists.)

## 1. Fix the running order and page offsets
Each generated PDF now takes `--start N` and prints where the next section should begin, so page
numbers run continuously across the bundle. Decide the order, then rebuild each with the right offset,
e.g.:

```
python3 appendix-tools/build_schematics.py --start 1     # prints -> next section at page X
python3 appendix-tools/pcb_merge.py        --start X
python3 appendix-tools/build_appendix.py   --start Y
```

## 2. Section names in the header
The header/footer section labels are currently hardcoded per script
("Schematics", "PCB Layer Documentation", "RoHS Compliance Appendix"). If we want
"Annex A / B / C …", change the `SECTION = "..."` line at the top of each build script.
Shared styling (doc name, colours, frame) lives in `appendix-tools/ce_common.py`.

## 3. Declaration of Conformity
`EU-Declaration-of-Conformity.docx` is a standalone Word doc (Arial, matches the PDFs) and does **not**
yet carry the shared PDF header/footer. When bundling: convert it to PDF and stamp it with the same
frame + page offset (reuse `ce_common.stamp` / `draw_frame`). Also fill the `[TO CONFIRM]` fields first.

## 4. PCB silkscreen layers
`PolyKybd-PCB-Layers.pdf` currently omits the silkscreen layers (they were too heavy to rasterise in the
build environment). Re-export all layers — including silkscreen — natively with
`kicad-cli pcb export pdf` from the KiCad boards and refresh the PDF before final assembly. (See
`CE-content-authoring-task.md`.)

## 5. Still-missing content before a complete file
Author the written documents in `CE-content-authoring-task.md` (general description, theory of
operation, standards list, risk assessment, user manual, marking/label), and obtain the **EMC test
report** (EN 55032 / EN 55035) from a lab. Slot these in per `CE-Technical-File-Checklist.md`.

## 6. Merge & finish
Concatenate the section PDFs (pypdf), add a master cover page and a top-level table of contents /
bookmarks, and confirm every page reads A4 with a continuous "Page N" footer. Fonts across all
generated sections are Helvetica (PDFs) / Arial (DoC) — keep it that way for any new sections.

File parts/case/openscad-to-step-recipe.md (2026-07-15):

# Recipe: recreating the PolyKybd case as a clean STEP with open-source Python CAD

**Goal.** Reproduce the OpenSCAD case (`case_polykybd_split72_metal.scad` and the `..._lr.scad`
variants) as closely as possible using an open-source, script-based **B-Rep** CAD toolchain, so the
exported STEP is a real solid model (true planar + cylindrical surfaces, tight tolerances) that a
fabricator's validator accepts — instead of the tessellated mesh you get from OpenSCAD → STL → STEP.

**Why this is needed.** OpenSCAD has no B-Rep kernel; it evaluates everything to a triangle mesh
(CGAL / Manifold). The current `metal-case-left/right.step` is that mesh written out as ~14,900 flat
facets with loose (~0.15 mm) stitching, and the rounded corners are sliver-facet strips — which is what
the fabricator flags. The outer shell in the SCAD is built with `hull()` of two profiles and rounded
with `offset(r=…)`, and `hull`/`minkowski` are precisely the operations that *cannot* survive as clean
geometry. So the fix is to re-author the model in a kernel that has real lofts and fillets.

## Toolchain (all open source)

- **build123d** — Python CAD library on top of OpenCASCADE (the recommended one; modern, Pythonic,
  clean STEP export). `pip install build123d`
- Alternatively **CadQuery** (same OCCT kernel, fluent API): `pip install cadquery`
- **OCP** (OpenCASCADE Python bindings) — pulled in by either; also used directly by the validation
  script below.
- Optional: **Inkscape** CLI (`inkscape --export-type=dxf`) to convert the SVG outlines to DXF, which
  imports more robustly than SVG.

There is **no reliable automatic SCAD → build123d translator** — this is a re-authoring job. But it
stays fully in code (parametric, diffable, CI-reproducible); no interactive CAD.

**Note on effort.** OpenSCAD is already close to what build123d does — same paradigm (describe the solid
in code, parametrically); the only real difference is the kernel underneath (OpenSCAD evaluates to a
mesh, build123d to a B-Rep). So most of the script translates almost line-for-line, and only the couple
of genuinely mesh-flavoured operations change (`hull`→`loft`, `minkowski`→`fillet`). If anything,
build123d lets you state design *intent* more directly — a rounded corner is a real `fillet(r)` instead
of an `offset(r)` that OpenSCAD then approximates into segments.

## Inputs already in the repo

2D profiles (in `case/`), all currently imported by the SCAD at **dpi = 300** (so
`mm = pixels * 25.4 / 300`; apply that scale on import):

| Purpose | File | SCAD var |
|---|---|---|
| Board outline | `poly_kb_wave_right2-OUTLINE.svg` | `pcb_outline` |
| Screw holes | `poly_kb_wave_right2-SCREW.svg` | `drill_holes` |
| Standoff positions | `poly_kb_wave_right2-STANDOFF.svg` | `standoffs_pos` |
| LED holes | `poly_kb_wave_right2-LED.svg` | `led_holes` |
| Switch holes | `poly_kb_wave_right2-SW.svg` | `switch_holes` |
| USB port / clearance | `poly_kb_wave_right2-USB.svg`, `…-USB-extra.svg` | `usb_port_holes`, `usb_clearance` |
| Wedge / tenting | `poly_kb_wave_right2-WD.svg` | `wedge_shape` |
| Nuts / inserts | `poly_kb_wave_right2-Nuts.svg`, `…-NutsInserts.svg` | `nuts`, `nuts_ins` |
| Misc cut-outs | `cut-outs.svg`, `poly_kybd_split72_plate_right-Edge_Cuts.svg` | `cutouts`, `cutouts2` |

Key parameters (from the SCAD header — keep them as Python constants so the port stays parametric):

```
case_height          = 17.5
case_wall_thickness  = 1.5
case_bottom_thickness= 2.0
pcb_clearance        = 0.15
pcb_edge_height      = 9.5
pcb_edge_width       = 1.4
stand_off_extra_radius = 2.3
text_font = "Arial", style bold italic;  text_size = 12;  text_height = 0.35
revision  = "r1.7"
```

## Operation mapping (OpenSCAD → build123d)

| OpenSCAD | build123d equivalent | Notes |
|---|---|---|
| `hull(topProfile, bottomProfile)` | **`loft([bottom_section, top_section])`** | This is the whole outer shell. Loft between the two chamfer sections at z=0 and z=`case_height`. |
| `offset(r=R)` corner rounding | real **`fillet(edges, radius=R)`** | Apply to the vertical corner edges after the loft/extrude → true cylinder surfaces, not segments. |
| `minkowski(cube, cylinder(r))` | `fillet(box.edges(), radius=r)` | The two flip-stand bays: just fillet the cube by the cylinder radius. |
| `linear_extrude(h) <2D>` | `extrude(sketch, amount=h)` | |
| `import(file=svg, dpi=300)` | `import_svg(path)` then `scale(25.4/300)` | Or convert to DXF first (`import_dxf`). Ensure closed paths. |
| `difference()` / `union()` / `intersection()` | `-` / `+` / `&` (boolean ops) | |
| `translate` / `rotate` / `mirror` | `Location`, `Rotation`, `mirror()` | Left case = `right case` mirrored. |
| `text(font,size)` | `Text(...)` → `extrude` | Real font outlines; keep as shallow engrave (`text_height`). Expect many faces. |
| `cylinder` / `cube` / `sphere` | `Cylinder` / `Box` / `Sphere` | |

## Step-by-step recipe

Port module by module — the SCAD already isolates the pieces:

1. **Load the 2D profiles once** into a helper: `import_svg(path)` → take the face(s), scale by
   `25.4/300`, recenter to match the SCAD's `center=true` imports. Cache them in a dict keyed by the
   table above.
2. **Outer shell** (SCAD `pcb_shape_camfer_top` / `_bottom` + the `hull` at line 277):
   - Build the **bottom section** = board outline offset outward by wall thickness/clearance.
   - Build the **top section** = the chamfer offset (the `extra_offet` used in `pcb_shape_camfer_top`).
   - `loft([bottom_section@z0, top_section@z=case_height])` → solid shell blank.
   - `fillet` the vertical corner edges by the corner radius (was the `offset(r=…)`), and chamfer the
     top edge if the SCAD does (`camfer_top`).
3. **Hollow it** (SCAD `inner_walls` / the `linear_extrude … offset(r=pcb_clearance+0.5) import(outline)`):
   extrude the inner (clearance) outline up to `case_height - case_bottom_thickness` and boolean-subtract
   → wall thickness `case_wall_thickness`, floor `case_bottom_thickness`.
4. **Board ledge** (`pcb_edge_height`, `pcb_edge_width`): an inward lip at the board rest height — a thin
   extruded ring subtracted/added per the SCAD.
5. **Standoffs & nut pockets** (`standoffs`, `pcb_standoffs`, `nuts_inserts`, `standoffs_holes`): extrude
   the STANDOFF profile up as bosses (with `stand_off_extra_radius`), drill the SCREW holes through, and
   subtract the Nuts/NutsInserts pockets.
6. **Feature cut-outs**: extrude-cut the LED, SW, USB (+ USB-extra), WD/tenting, `cut-outs.svg` and
   `…Edge_Cuts.svg` profiles through the relevant faces. These are all plain extrude + boolean, so they
   port directly.
7. **Branding** (`branding`): `Text` with the real font, extruded `text_height` and engraved (subtract)
   or embossed (add) on the chosen face; mirror for the left case.
8. **Left / right**: define the right case, then `mirror` across the appropriate plane for the left case
   (SCAD `left_case()` / `right_case()`).
9. **Export**: `export_step(part, "metal-case-right.step")` (and left). build123d writes a clean B-Rep.

## Skeleton (build123d)

```python
from build123d import *

MM_PER_PX = 25.4 / 300            # SCAD imported at dpi=300
CASE_H, WALL, FLOOR = 17.5, 1.5, 2.0
CLEAR, CORNER_R = 0.15, 3.0       # CORNER_R = the offset(r=) you used on the outline

def load(path):                    # SVG -> scaled, centered face
    f = import_svg(path)           # returns wires/edges; make_face if needed
    return scale(f, MM_PER_PX)

with BuildPart() as case:
    bottom = load("poly_kb_wave_right2-OUTLINE.svg")   # + outward offset for wall
    top    = offset(bottom, amount=+0.0)               # the camfer_top offset
    # outer shell as a loft between the two sections (replaces hull())
    with BuildSketch(Plane.XY):        add(bottom)
    with BuildSketch(Plane.XY.offset(CASE_H)): add(top)
    loft()
    # real rounded corners (replaces offset(r=)):
    fillet(case.edges().filter_by(Axis.Z).group_by(SortBy.LENGTH)[-1], radius=CORNER_R)
    # hollow, ledge, standoffs, cut-outs, text ... (boolean cuts/fuses as above)

export_step(case.part, "metal-case-right.step")
```

Treat the API calls above as representative — check them against the installed **build123d** version;
the *structure* (load → loft → fillet → boolean features → export) is what matters.

## Validate the result (open source, OpenCASCADE)

After export, confirm it is a real solid (this is the acceptance test the mesh version failed):

```python
from OCP.STEPControl import STEPControl_Reader
from OCP.BRepCheck import BRepCheck_Analyzer
from OCP.TopExp import TopExp_Explorer
from OCP.TopAbs import TopAbs_FACE, TopAbs_EDGE
from OCP.TopoDS import TopoDS
from OCP.BRepAdaptor import BRepAdaptor_Surface
from OCP.GeomAbs import GeomAbs_Plane
from OCP.BRep import BRep_Tool

r = STEPControl_Reader(); r.ReadFile("metal-case-right.step"); r.TransferRoots()
s = r.OneShape()
print("valid B-Rep:", BRepCheck_Analyzer(s).IsValid())

ex = TopExp_Explorer(s, TopAbs_FACE); planar = curved = 0
while ex.More():
    curved += BRepAdaptor_Surface(TopoDS.Face_s(ex.Current())).GetType() != GeomAbs_Plane
    planar += BRepAdaptor_Surface(TopoDS.Face_s(ex.Current())).GetType() == GeomAbs_Plane
    ex.Next()
print("planar/curved faces:", planar, curved, "(curved > 0 means real fillets exist)")

ex = TopExp_Explorer(s, TopAbs_EDGE); mt = 0
while ex.More():
    mt = max(mt, BRep_Tool.Tolerance_s(TopoDS.Edge_s(ex.Current()))); ex.Next()
print("max edge tolerance:", mt, "(want ~1e-6..1e-4, not 0.1)")
```

Pass criteria: `valid B-Rep = True`, **curved faces > 0** (the corner fillets are real cylinders),
**max edge tolerance ≤ ~1e-4 mm** (vs 0.148 in the mesh), and a face count in the hundreds — not ~15,000.
Also compare the bounding box against the old mesh to confirm nothing shifted.

## Automate

Keep it a one-command build, e.g. a `Makefile`:

```
step: case_right.py case_left.py
	python case_right.py   # -> metal-case-right.step
	python case_left.py    # -> metal-case-left.step
	python validate_step.py metal-case-right.step metal-case-left.step
```

so the pipeline is `SVG outlines + params → build123d → clean STEP`, fully open source and reproducible.

## Gotchas

- **SVG import**: build123d needs closed paths; if `import_svg` is fussy, pre-convert with Inkscape to
  DXF and use `import_dxf`. Watch units — apply the `25.4/300` scale and match the SCAD's `center=true`.
- **Corner roundness**: use real `fillet(radius=…)` for true cylinders. If you instead extrude an
  `offset`-rounded polygon you're back to many flat faces (clean, but not arcs).
- **`hull` / `minkowski`**: always map `hull(sectionA, sectionB)` → `loft`, and `minkowski(shape, ball)`
  → `fillet`/`chamfer`. Never try to pass these through a mesh.
- **Text**: real font engraving adds many faces and can slow booleans; do it last, keep it shallow, or
  leave engraving to the fab as a 2D layer.
- **Left vs right**: build the right case, then `mirror` — don't maintain two copies.

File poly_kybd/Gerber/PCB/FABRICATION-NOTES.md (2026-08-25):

# Fabrication export notes (PolyKybd split72)

Durable record of the things that keep being re-derived when regenerating gerbers,
BOM and CPL. Read this **before** re-exporting, and update it when a decision changes.

---

## ⚠️ 1. The fab exporter reads the BOARD, not the schematic

The JLC fabrication-toolkit plugin builds the BOM from **footprint properties on the
`.kicad_pcb`**. A correct schematic is *not* enough: *Update PCB from Schematic* changes
the footprint association and `Value` but leaves `MPN` / `LCSC` / `JLC` / `Manufacturer`
alone unless field updating is explicitly enabled.

**This has already shipped a wrong BOM once.** After the U9 flash swap the export read:

```
U9,BY25Q64ES-LGA8-2x3,1,BY25Q64ESCIG(R),C5440778
                                        ^^^^^^^^ Winbond -- the OLD part
```

Footprint and Value were right, and the `LCSC Part #` column — **the only column JLC
orders from** — still named the superseded Winbond `W25Q64JVXGIM` (DFN 4×4), which would
have been placed onto an LGA-8 land. Guaranteed assembly failure, invisible in the
footprint and invisible on the canvas.

**Check after every export**, comparing board fields against the schematic:

```python
# board footprint properties vs schematic symbol properties, per reference
# fields that matter: MPN, LCSC, JLC, Manufacturer
```

The 2026-08-24 sweep found 4 divergences out of 112 matched parts — see §3.

⚠️ Note the board's U9 fields were stale *independently* of this change: v3.2 was
fabricated with `C2940195` / `W25Q64JVXGIQ`, while the board file carried `C5440778`.
So "the board field" has never been a reliable record of what was ordered.

---

## ⚠️ 2. The 36 hot-swap sockets are BOTTOM mounted — every CPL export needs a manual flip

`SW_K_1` … `SW_K_36` (`poly_kb:Kailh_socket_MX_Indicators`) are placed on **`F.Cu`** in
the board file, but the sockets are physically mounted on the **bottom**. So a fresh
export writes `top` for all 36 and it must be corrected to `bottom` by hand before the
CPL goes to the fab.

This is not a one-off — it is required on **every** re-export, and it has been done
manually every time. The 2026-08-24 v3.3 export shipped with `top` still in place until
it was caught.

**The check:** the v3.2 CPL is the as-fabricated reference. A correct export agrees with
it on every common reference:

```bash
# expect: 0 side disagreements, 72 ',top' rows in both
```

The root cause is the board layer, so the permanent fix would be flipping those 36
footprints to `B.Cu` — deliberately not done, since that moves pads/mask/paste layers on
a working, fabricated design. The manual CPL fix is the cheaper risk.

---

## 3. Part decisions (2026-08-24)

| Ref | Decision | Availability | RoHS evidence |
|---|---|---|---|
| **U9** | **BOYAMICRO `BY25Q64ESCIG(R)` / `C50176394`** — everything points at the Boya part: schematic, board fields, and the v3.3 export | quoted $0.6012 × 400, 7 business days | ✅ `RoHS/2006180000_BOYAMICRO-BY25Q64ESCIG-R_C50176394.pdf` |
| **C3, C8** | **Samsung `CL05C270JB5NNNC` / `C86287`** (was FH `C1557`) | ✅ 69,800 in stock at LCSC | ✅ already filed — the Samsung series list in `RoHS/2304140030_Samsung-Electro-Mechanics-...C52923.pdf` includes `CL05C270 J B 5NNN`, and it is already in `PolyKybd-RoHS-Appendix.pdf` |
| **D2** | Guangdong Hottech `1N5819WS` / `C191023` — kept, no change | ✅ 5,636,800 in stock, SOD-323, not discontinued | ✅ closed 2026-08-24, see below |

⚠️ **C3/C8 value string reads `27pF 0402 16V` but both the old and new parts are 50V**
(`0402CG270J500NT` and `CL05C270JB5NNNC`). The label is inaccurate, the parts are not
under-rated. Left alone to avoid churn; fix it if the value strings are ever tidied.

### D2 — RoHS closed (2026-08-24)

Evidence: **`RoHS/ROHS-2025-HottechElectronics-CTI-A225024736310100101.pdf`** — Centre Testing
International report dated 17 Apr 2025, RoHS 2011/65/EU + (EU) 2015/863, full 10-substance scope
(Pb, Cd, Hg, Cr(VI), PBBs, PBDEs, and the phthalates DBP/BBP/DEHP/DIBP), IEC 62321 methods, all
results **N.D. — PASS**. Its Model No. list reads `SOD-123/323/523/723`, so **SOD-323 is
explicitly covered**. `parts.csv` updated `x Email sent` → `x`; **no part change needed**.

⚠️ **The earlier acceptance was based on a misreading — don't reinstate it.** D2 had been
accepted via `ROHS3HOTTECH.pdf` on the grounds that it "includes 323-series package testing".
That 2020 report's sample list is `SOT-23, 323, 523, 723, … SOD-123`, where the `323` belongs to
the **SOT** run — its SOD coverage stops at **SOD-123**, and it states its results "refer only to
the sample(s) tested". The package was never actually covered, which is why `parts.csv` carried
`x Email sent` the whole time.

⚠️ Two limitations of the new report, both normal for an SMD part but worth being able to answer
if the technical file is challenged: the sample was **tested as a whole** rather than separated
into homogeneous materials (the report says so, and RoHS limits formally apply per homogeneous
material), and the applicant is **Shenzhen Hottech Electronics** while LCSC lists the part's
manufacturer as *Guangdong* Hottech — the report remarks the two are "Group-subsidiary relations",
but that is *according to the client's statement*, not verified by CTI. It is also a
package-family report, not MPN-specific.

The PAKER `B5819WS` / `C5278927` alternative is **no longer needed**, and was the weaker option
regardless: 2,250 in stock against 5.6M, and a 9A surge rating against 25A.

⚠️ Minor, no order impact: the board says `Manufacturer = Hottech Semi`, the schematic says
`Hottech`, and the real manufacturer is *Guangdong Hottech*. LCSC matches on both sides.

---

## 4. Do NOT regenerate the v3.1 / v3.2 exports

They are the historical record of what was actually fabricated, and every board in
existence is v3.2. Only **v3.3** is regenerated — it has never been manufactured.
v3.2 doubles as the reference for the CPL check in §2.

---

## 5. Silkscreen artwork is simplified — do not re-import at full trace fidelity

The Rosetta Stone artwork on the silk layers was imported as traced vector outlines at
full curve fidelity: **5.5 million `gr_poly` vertices** across the boards, which was ~80%
of every board file and pushed three of them past GitHub's 50 MB warning.

⚠️ **That detail cannot be printed.** Measured on the left board, the median edge in the
artwork was **0.017 mm** and **98.6% of edges were under 0.10 mm** — silkscreen resolves
about 0.1 mm and JLC's minimum silk line width is 0.15 mm.

A Douglas–Peucker pass at **0.01 mm** (a tenth of print resolution) is applied by
`poly_kybd/tools/simplify_silkscreen.py`:

| | before | after |
|---|---|---|
| silk vertices | 5,532,117 | 884,434 (−84%) |
| split72 left / right | 51.6 / 52.6 MB | 18.5 / 18.6 MB |
| split42 right / plate_left | 52.9 / 17.1 MB | 18.8 / 3.2 MB |
| **total** | **180.5 MB** | **65.3 MB** |

**Verified visually, not just by vertex count.** Rendering the artwork at 4× print
resolution before and after, of 411,805 differing pixels exactly **4** fall inside an
eroded core — everything else is a 1–2 px (~0.025 mm) edge shift along an outline. No
feature is lost. The one real effect is a uniform **−3.1% ink area**, because RDP cuts
corners inward; the art reads very slightly lighter, undistorted.

The tool touches **only `gr_poly` on layers whose name contains `SilkS`**. After each run,
everything else in the file is byte-identical — copper, mask, paste, edge cuts, footprints,
zones, tracks, vias and the non-silk `gr_poly` blocks (there are 25 on the split72 boards,
including some on `B.Cu` and `B.Mask`). That is asserted per board, not assumed.

⚠️ **Keep the original artwork source** (SVG or whatever it was traced from) outside the
board files. The boards now carry a print-resolution version; if the art is ever needed at
higher fidelity — a larger panel, a poster, a different process — it has to come from the
source, not from the board.

⚠️ **Git LFS was considered and rejected.** It treats the symptom: converting existing files
means rewriting history across every branch, everyone re-clones, and GitHub stops rendering
`.kicad_pcb` diffs. That diffability is load-bearing here — the copper comparisons, CPL
checks and footprint verification in this repo all depend on the boards being diffable text.

## 6. SW1 (PolyJog) mounting holes on `*.Cu` — reviewed, benign

The PolyJog footprint's two 3.6 × 2.4 mm mounting-hole pads carry `(layers "*.Cu"
"*.Mask")`. KiCad reported the footprint as outdated and the refresh widened the pad
layer list from `F&B.Cu`, so the annulus is now flashed on **In1.Cu / In2.Cu** as well.
Reviewed 2026-08-25 and left as it stands:

- The drill (oval 2.8 × 1.5 mm) removes most of that copper anyway. The added metal is
  only the annulus: **0.40 mm** along the long axis, **0.45 mm** across the short one —
  two holes, two inner layers.
- The pads carry **no net**, so the inner planes hold their normal clearance around them
  and the annulus stays **isolated** — it does *not* merge into GND. That is why the ring
  is visible in the gerbers. It is the same floating annulus every plated through-hole
  already produces where it passes a plane it isn't connected to, so it needs no
  treatment of its own.
- F.Cu and B.Cu are unchanged; they were in the list before.

⚠️ Two traps hit while checking this, both worth remembering:

- **Pad `at` angles are ABSOLUTE, not relative to the footprint** (the rule is in the
  `investigate-kicad-pcb` skill). Adding the footprint's rotation to the pad's gives a
  part drawn at the wrong angle — silently, since the shape is still plausible.
- The board records these two as **`np_thru_hole`** (non-plated). The *plated* holes in
  that footprint are the 2 mm `thru_hole` pads named `S1`/`S2`. Check which you mean
  before reasoning about barrel connectivity.

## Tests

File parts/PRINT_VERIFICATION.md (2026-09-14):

# Verifying a printed part

Extracted from `CLAUDE.md` 2026-09-14. The prose is unchanged; only heading levels
and relative links were adjusted to suit a standalone file.

## Verifying a printed part

**`parts/diffuser/build_frame.sh` is the whole loop** — regenerate the `.scad` from
the board, export every STL (both frames plus both stacked ones), then verify.
Run it after any edit to `diffuser.scad` or the generator; `--no-4x` skips the
slow stacked exports for a quick iteration, `--check` verifies without exporting.
Doing the steps by hand is where they get missed: a `diffuser.scad` change alters
the stacked pair too, and forgetting them leaves those a revision behind.

`parts/diffuser/check_frame.py` is the verifier it calls: watertight, minimum wall,
left/right symmetry, plate trap, and spacer clearance in both flip orientations.
It exits non-zero on failure. Extend it rather than re-deriving these by hand —
and note it deliberately reports FAIL rather than raising, because a gating script
that crashes on a malformed input tells you nothing about the design.

**Picking a wall-thickness metric is itself the hard part** — three of them were
wrong before the fourth answered the question:

- **Inward-normal ray-cast on the STL** (what `min_wall()` does) is correct where
  two walls are parallel, which covers a plate-like part in z. It is **wrong near
  a corner**: the normal runs oblique to the far face and overestimates — it read
  3.0 mm across a wedge whose real wall was 1.55 mm.
- **Distance to the boundary is not thickness.** Every point near any edge scores
  low, so the "thin area" comes out enormous and meaningless.
- **For in-plane features, rasterise the profile and apply a morphological
  opening** (a disc of radius t/2 must fit). That is the test a print service
  runs, and it is what finally ranked an axis-aligned trim against a 45° one.
- **Report the AREA below a threshold, not the infimum.** Every polygon corner
  tapers to zero thickness at its apex, so the minimum is always ~0 and tells you
  nothing; how *much* material is thin is the number that decides anything.

⚠️ **Identify an orphan mesh by re-exporting the candidate source and comparing,
not by its filename.** Two meshes committed as `case_ins_r2.stl` /
`case_ins_leg_v0.stl` were grouped as a "case insert" on the strength of that
prefix, and separately guessed to be the plate-to-PCB spacer (they are 3.8 mm
thick, the same as `right_spacer()`, so the guess was reasonable). Re-exporting
`legs.scad` settled it in one command: same 32202 facets, same 5263.0 mm³, same
bounding box, 100 % of facets equal at 3 dp -- they are the **tenting legs**
(`connected_8p()`, 8 legs in 4 mirrored pairs). Now `export/legs/legs_r2_8p.stl`.
Float noise between OpenSCAD builds means an exact facet-set compare returns
False, so compare rounded, or on count+volume+bbox.

## Design rules for resin-printed parts

A print service will quote a **0.8 mm minimum / 1.5 mm recommended** wall and
refuse the part if it measures below. Three ways this bit the diffuser frame:

- ⚠️ **A tapered rim beside passing geometry leaves a wafer.** A
  `linear_extrude(scale=)` rim sweeps its radius over its height, so *any*
  neighbouring wall whose edge lands anywhere in that band runs tangent to the
  slope at some height and leaves a near-zero-thickness sliver. On the frame this
  measured **0.043 mm** where a web stem passed a diffuser's bottom cap — an order
  of magnitude thinner than what the vendor complained about, and invisible until
  measured. **Use a vertical rim wherever other geometry passes close**: one
  radius means a neighbour can only clear it or merge with it.
- ⚠️ **`linear_extrude(scale=)` chamfers change ANGLE if you change their
  height.** The inward step is proportional to the *profile*, not the height, so
  thickening a flange by raising the chamfer layer lays the chamfer down (34.9° →
  21.8° when a flange went 1.0 → 1.5 mm). Keep the chamfer layer at its original
  height and put the extra thickness in the straight layer.
- ⚠️ **A minor circular segment ends in a knife edge.** `circle(d)` cut by a chord
  *above* centre runs out to nothing; the last fraction of a millimetre is what a
  vendor measures and rejects. Square the end off — and prefer a **cut that leans
  in plan** over an axis-aligned one: leaning opens the corner against the chord
  from 90° to 135° and spends the cut on the shallow strip, which measured **half
  the sub-0.8 mm area while keeping 4.4% more material**.

**Engraved text always leaves sub-0.8 mm relief** between glyph strokes — no pad
size fixes it, because legible text at any size that fits has strokes closer
together than the threshold. It is **surface relief, not a wall** (the full web
runs continuous underneath). Say so explicitly: exclude the engraving zone from a
wall check and assert the residual material separately, rather than reporting a
flattering number, and tell the vendor the same when they flag it.

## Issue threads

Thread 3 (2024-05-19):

Was interested in this project, but can't find schematics in readable format

trollcop, 2024-05-19:
I'm not really interested in installing kicad, is there any reason why schematics in PDF aren't provided? Was driving by the project and was curious how you'd have ~80 SPI LCD chip selects managed but the curiosity was not enough to warrant installing something to view it.

thpoll83, 2024-05-19:
It is a KiCad project (as mentioned in the readme), just install and open the schematics. For PDF I have to change binary files for every revision...

Closed 2024-10-02.

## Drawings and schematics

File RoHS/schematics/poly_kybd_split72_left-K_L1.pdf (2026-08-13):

# C324724 C1_1

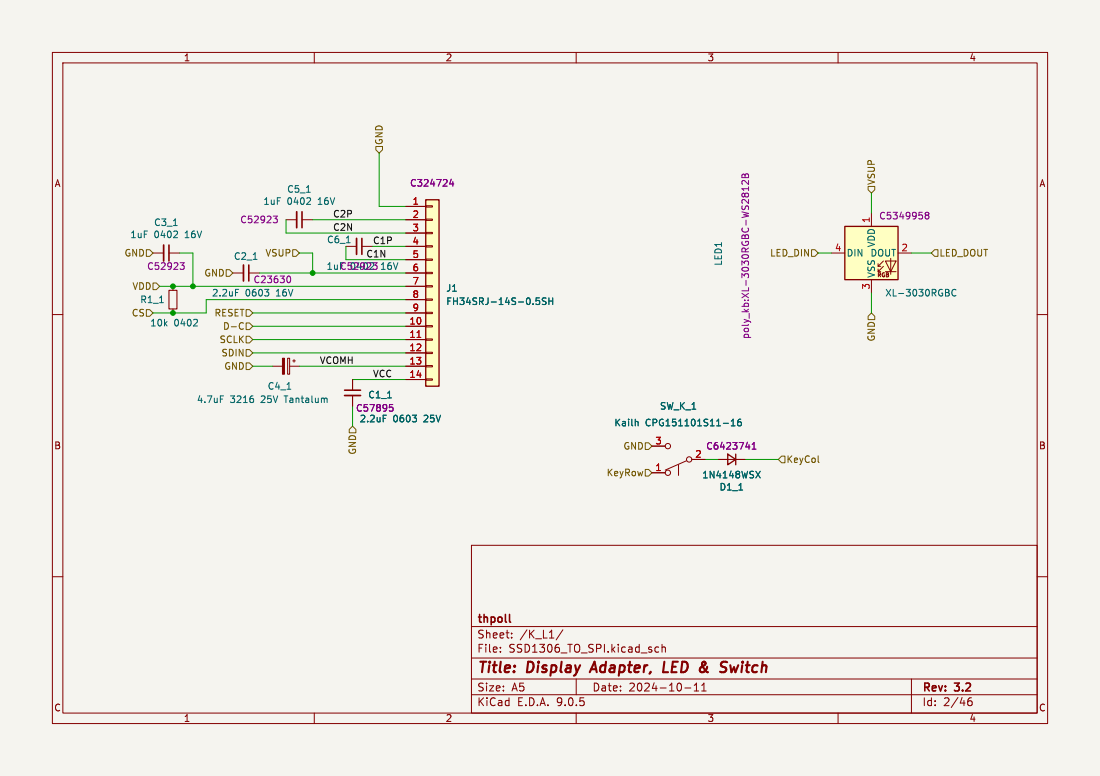
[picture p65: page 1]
BC Date: 2024-10-11 KiCad; E.D.A. 9.0.5 Size: A5; Rev: 3.2; thpoll C3_1 1uF 0402 16V C52923 R1_1; 3SW_K_1 Kailh CPG151101S11-16 C4_1 4.7uF 3216 25V Tantalum; J1FH34SRJ-14S-0.5SH; 1N4148WSX C6423741; RGB DIN 4; VDD; 1 VSS; 1uFC52923 0402 16V C5_1; 1uF 0402 16V C52923VSUP; LED_DOUT D-C; RESET GND GND; LED_DIN GND; SDIN; SCLK; GND; KeyCol; VSUP GND; VCC; VCOMH; SW_K_1 Kailh CPG151101S11-16

KeyRow GND GND

3 DOUT 2 LED1 XL-3030RGBC poly_kb:XL-3030RGBC-WS2812B C5349958 C6_1

File: SSD1306_TO_SPI.kicad_sch Sheet: /K_L1/
Id: 2/46 Title: Display Adapter, LED & Switch

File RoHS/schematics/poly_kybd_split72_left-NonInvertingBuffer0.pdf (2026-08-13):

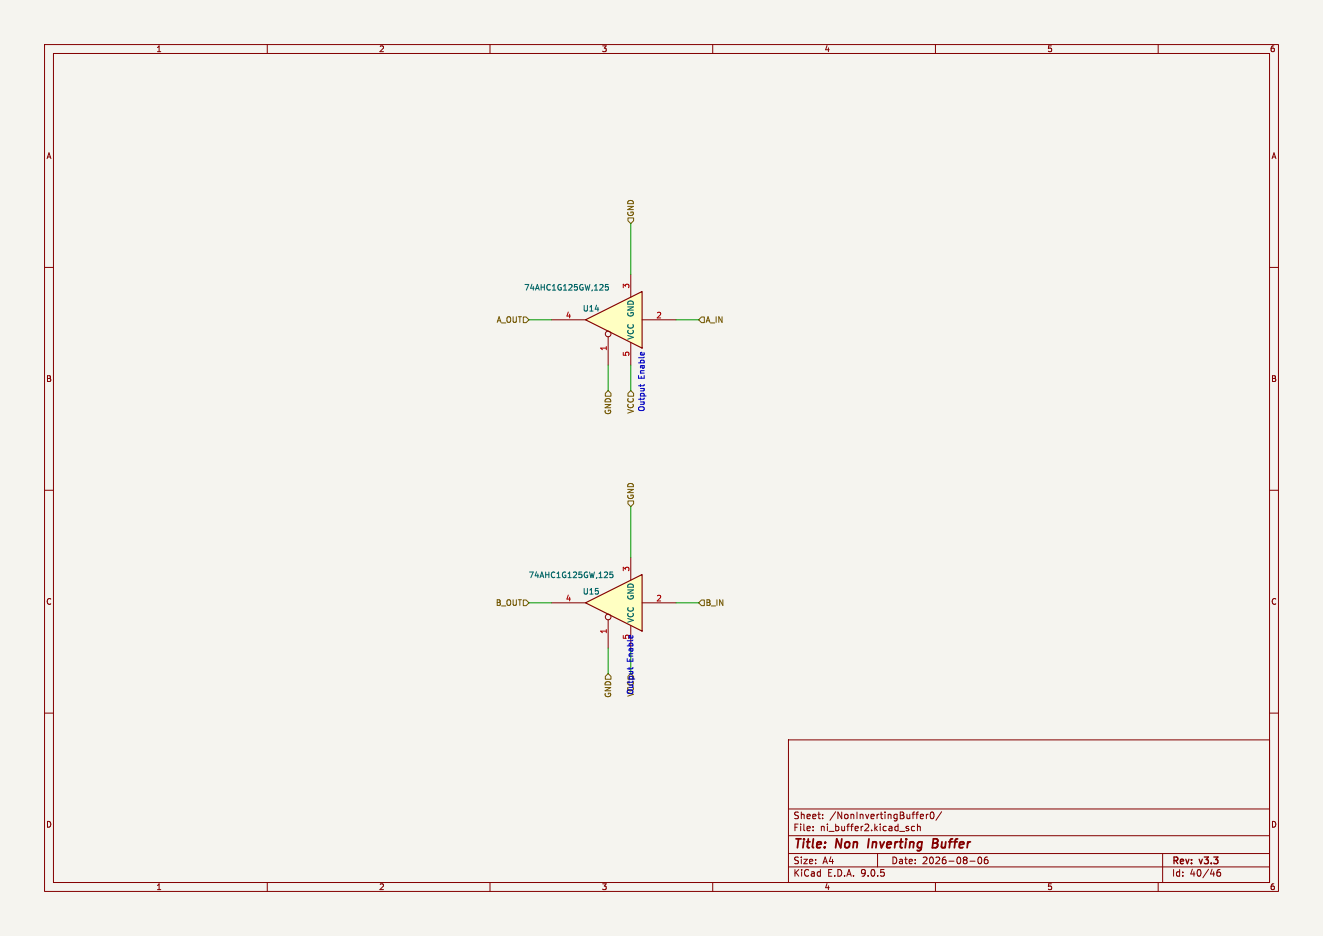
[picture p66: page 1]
6 ABCD; ABCD Date: 2026-08-06 KiCad; E.D.A. 9.0.5 Size: A4; Rev: v3.3; Id: 40/46 Title: Non Inverting Buffer File: ni_buffer2.kicad_sch Sheet: /NonInvertingBuffer0/ ² VCC 5 GND ³ 1 4; 74AHC1G125GW,125; 2 VCC 5 GND ³ 1 4; 74AHC1G125GW,125 B_OUT; GND; A_OUT; A_IN GND; VCC VCC; B_IN GND; Output Enable Output Enable

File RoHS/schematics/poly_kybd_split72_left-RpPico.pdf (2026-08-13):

# 10uF 0805 16V C24

# Package_TO_SOT_SMD:SOT-23-5 C16

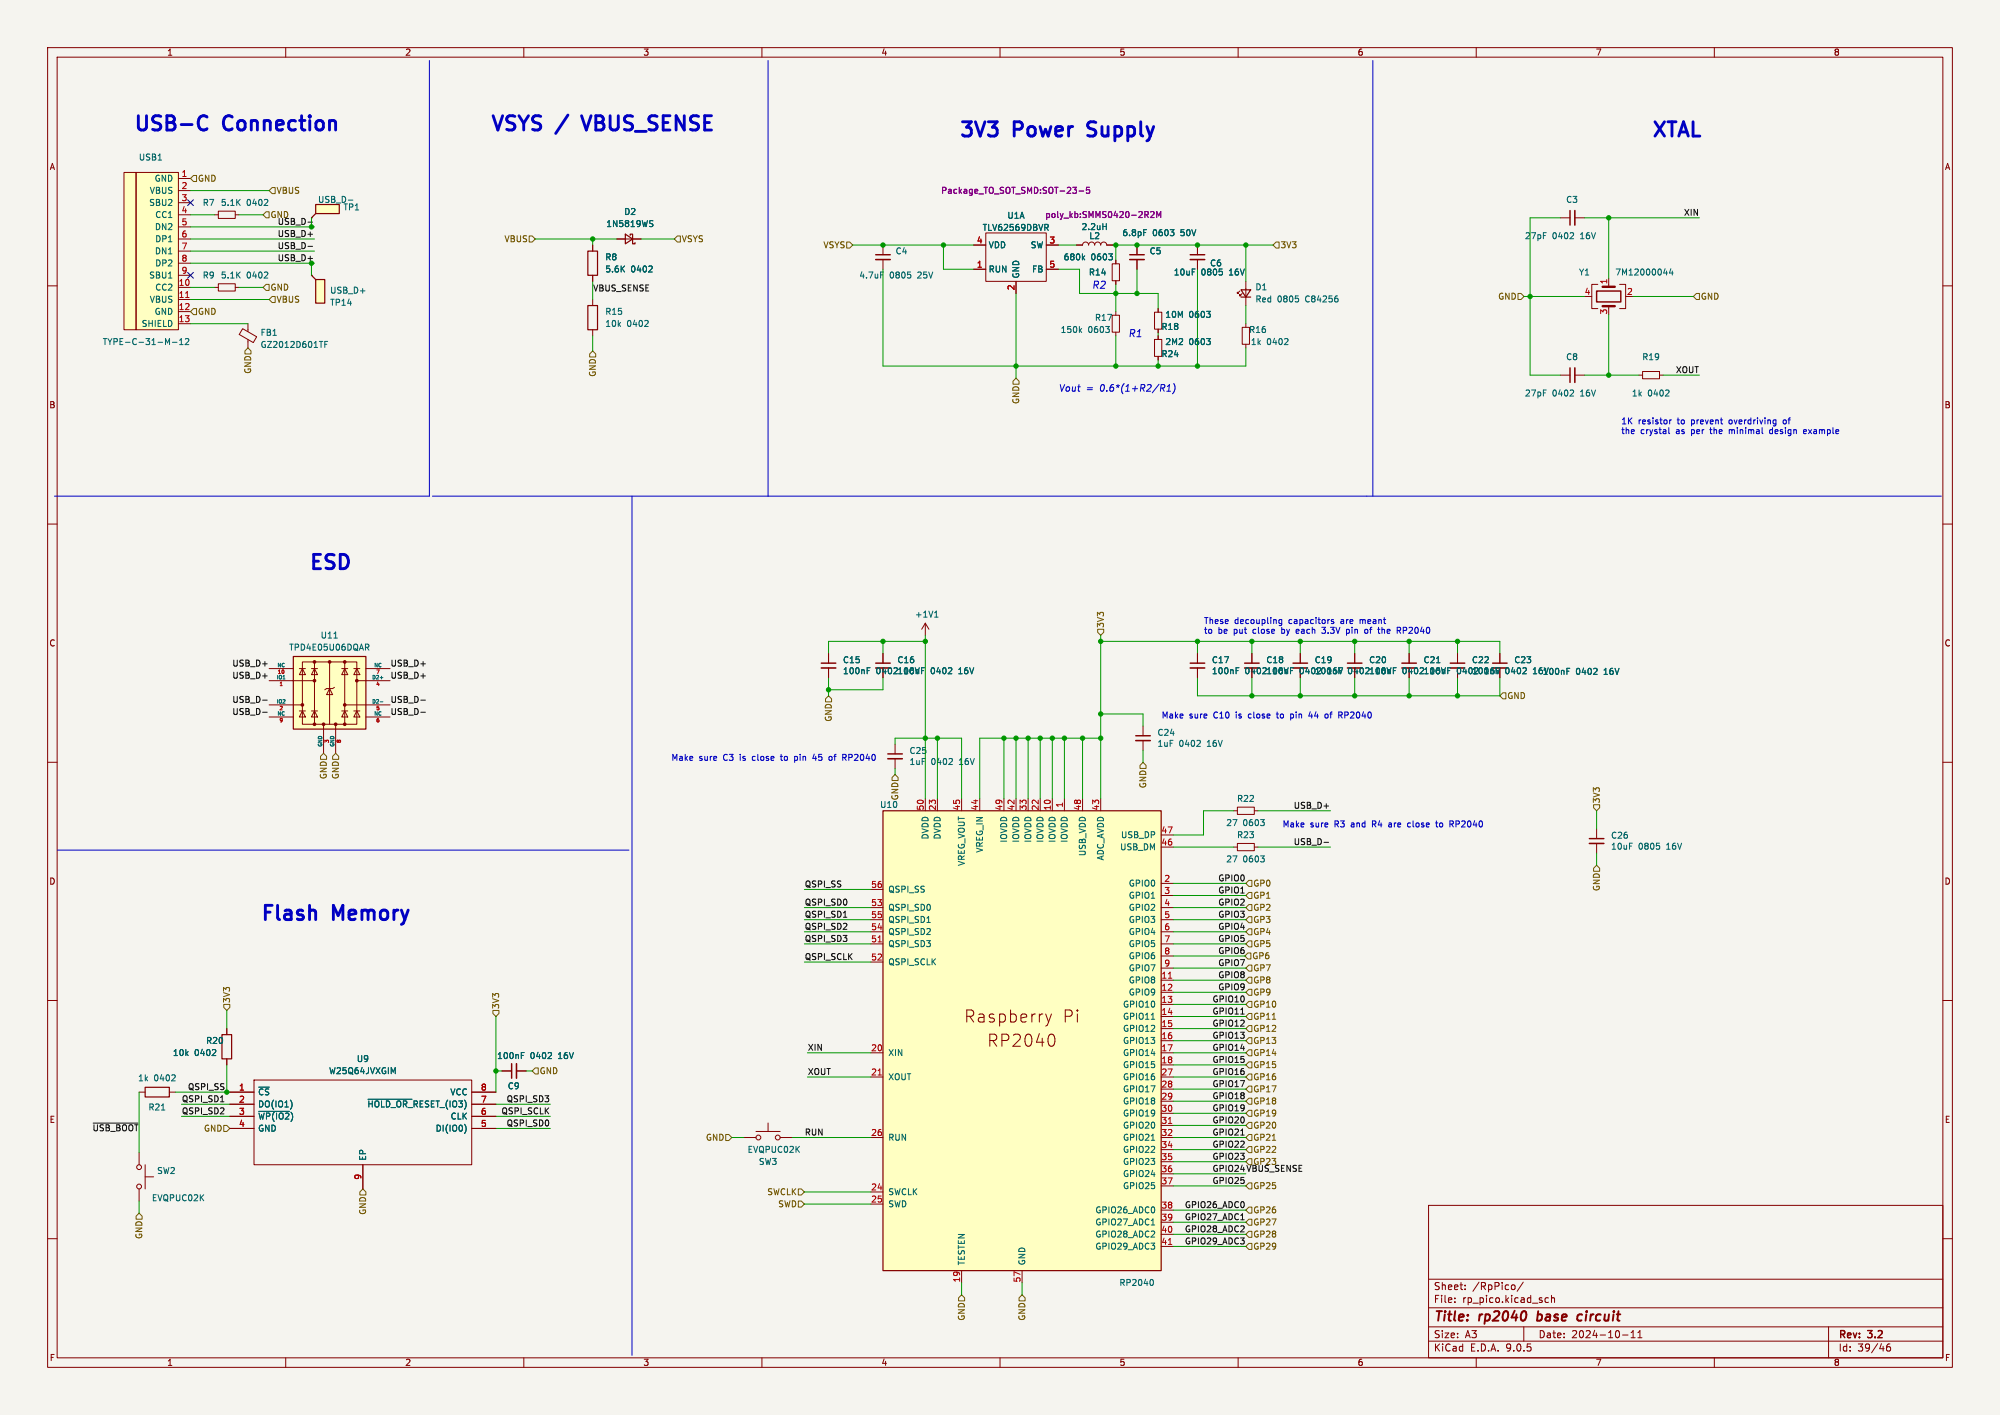
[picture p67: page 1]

to be put close by each 3.3V pin of the RP2040 R1

Id: 39/46 Title: rp2040 base circuit File: rp_pico.kicad_sch Sheet: /RpPico/

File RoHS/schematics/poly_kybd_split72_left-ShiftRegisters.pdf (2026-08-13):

1 | 2 | 3 | 4 | 5 | 6

A

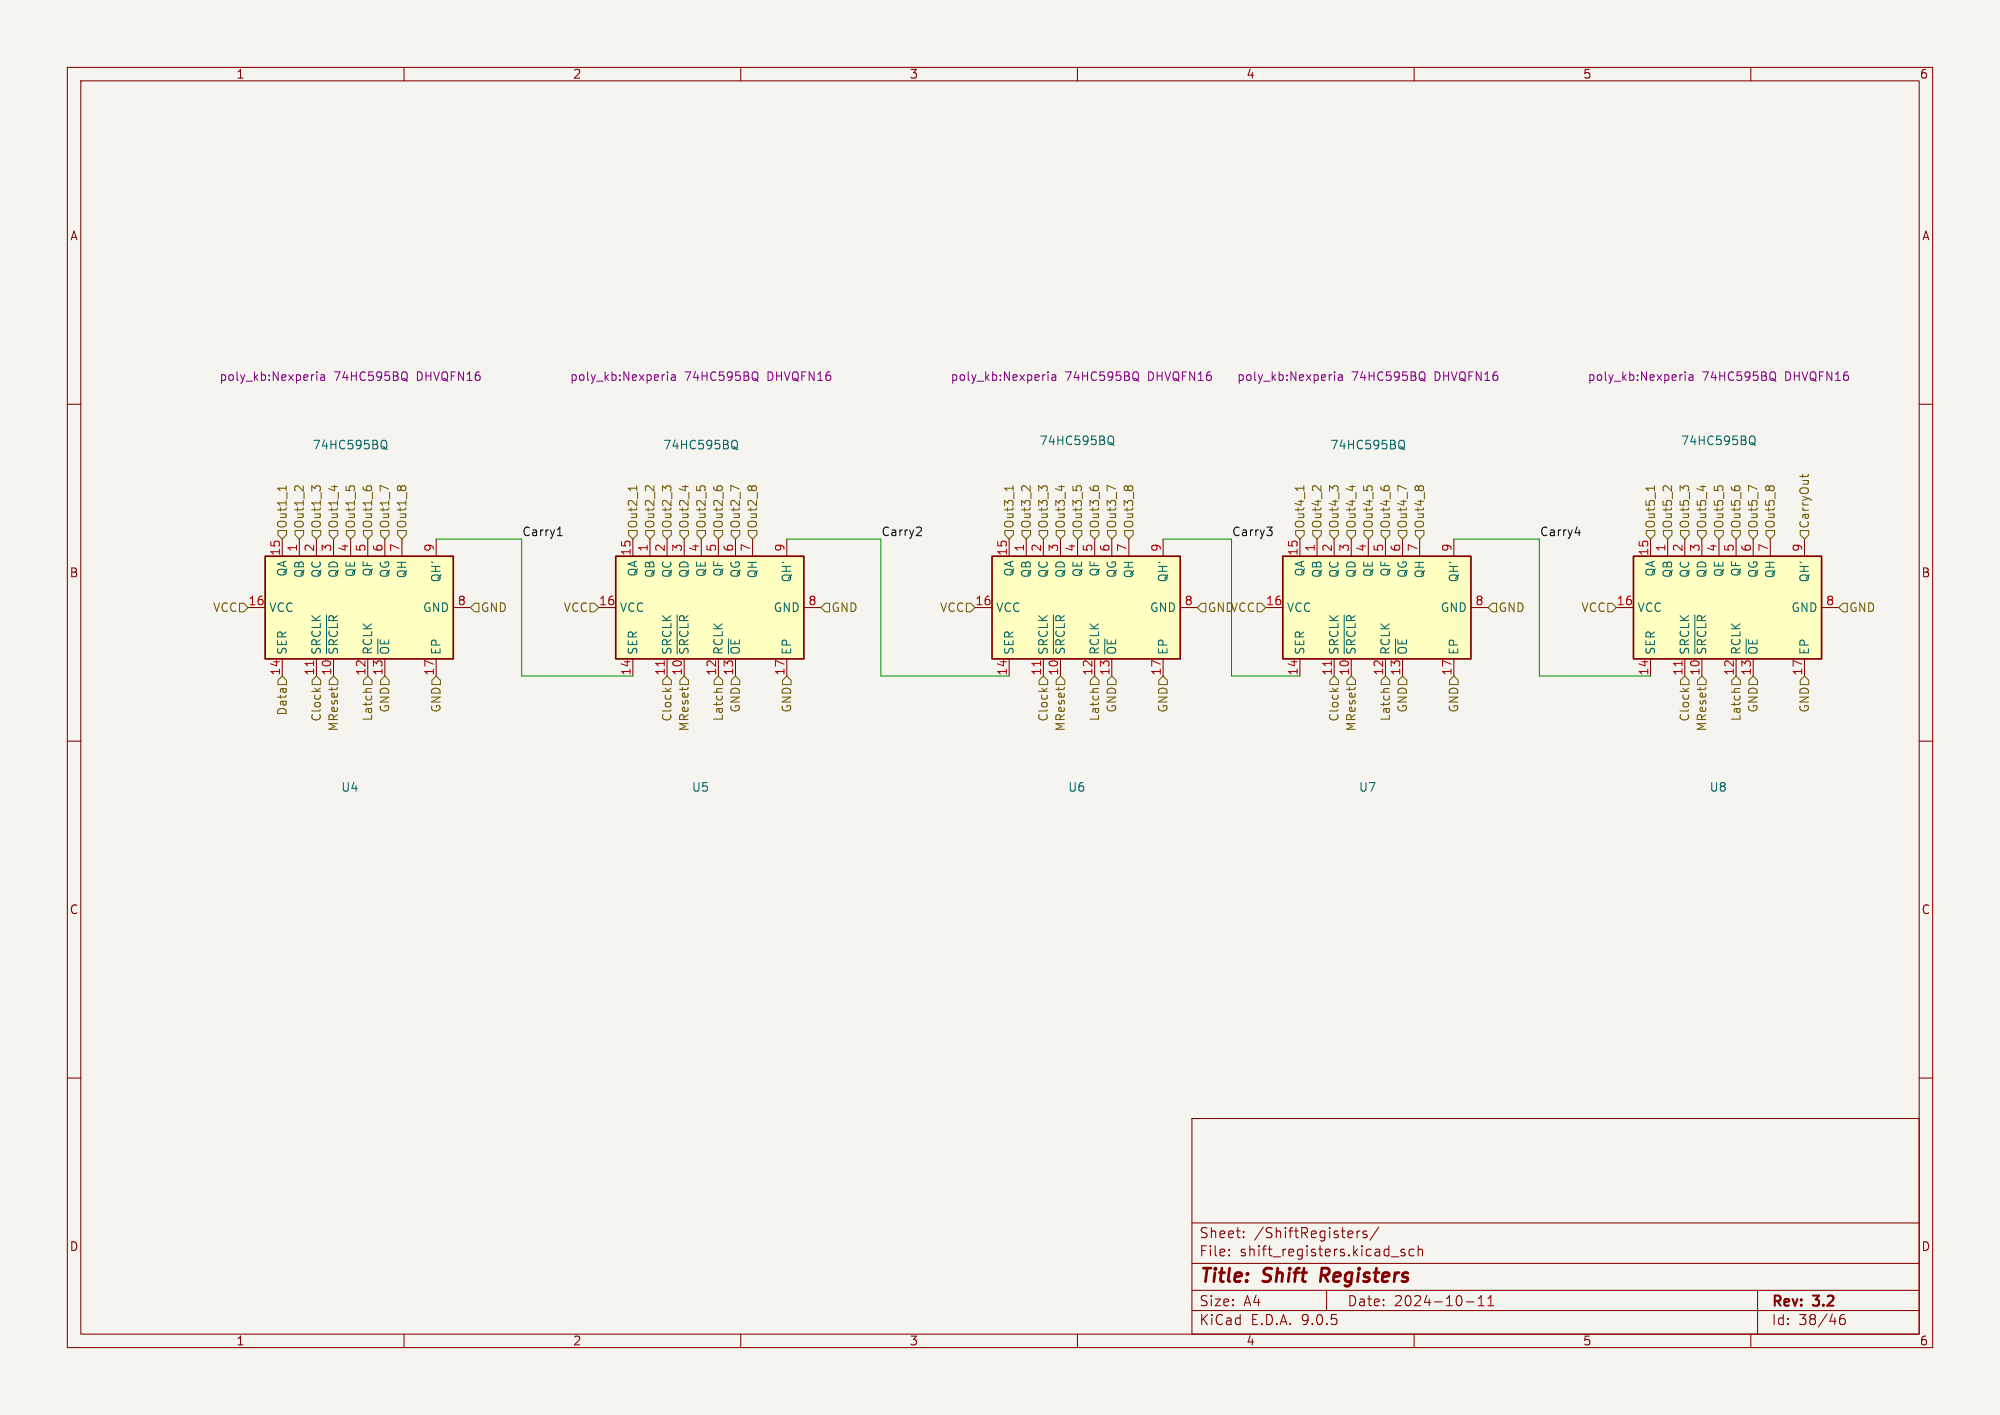
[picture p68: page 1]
D Date: 2024-10-11 KiCad; E.D.A. 9.0.5 Size: A4; Rev: 3.2; File: shift_registers.kicad_sch Sheet: /ShiftRegisters/ SER 14; SRCLK 11; ~{SRCLR} 10; RCLK 12; EP 17 VCC 16; GND 8 QA ¹⁵; poly_kb:Nexperia; 74HC595BQ DHVQFN16; SER 14; 74HC595BQ DHVQFN16 SER 14; 74HC595BQ DHVQFN16 MReset; Out1_6 Out1_7 Out1_8; GND MReset; MReset GND; Out2_1 Out2_2 VCC; VCC; GND Data; Clock; Latch GND; GND Out1_1 Out1_2 Out1_3 Out1_4 Out1_5; Out4_1 Out4_2 Out4_3 Out4_4 Out4_5; Clock GND; GND; MReset Latch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

Id: 38/46 Title: Shift Registers

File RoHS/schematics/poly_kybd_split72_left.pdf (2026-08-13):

# File: SSD1306_TO_SPI.kicad_sch SDIN

# File: SSD1306_TO_SPI.kicad_sch SDIN

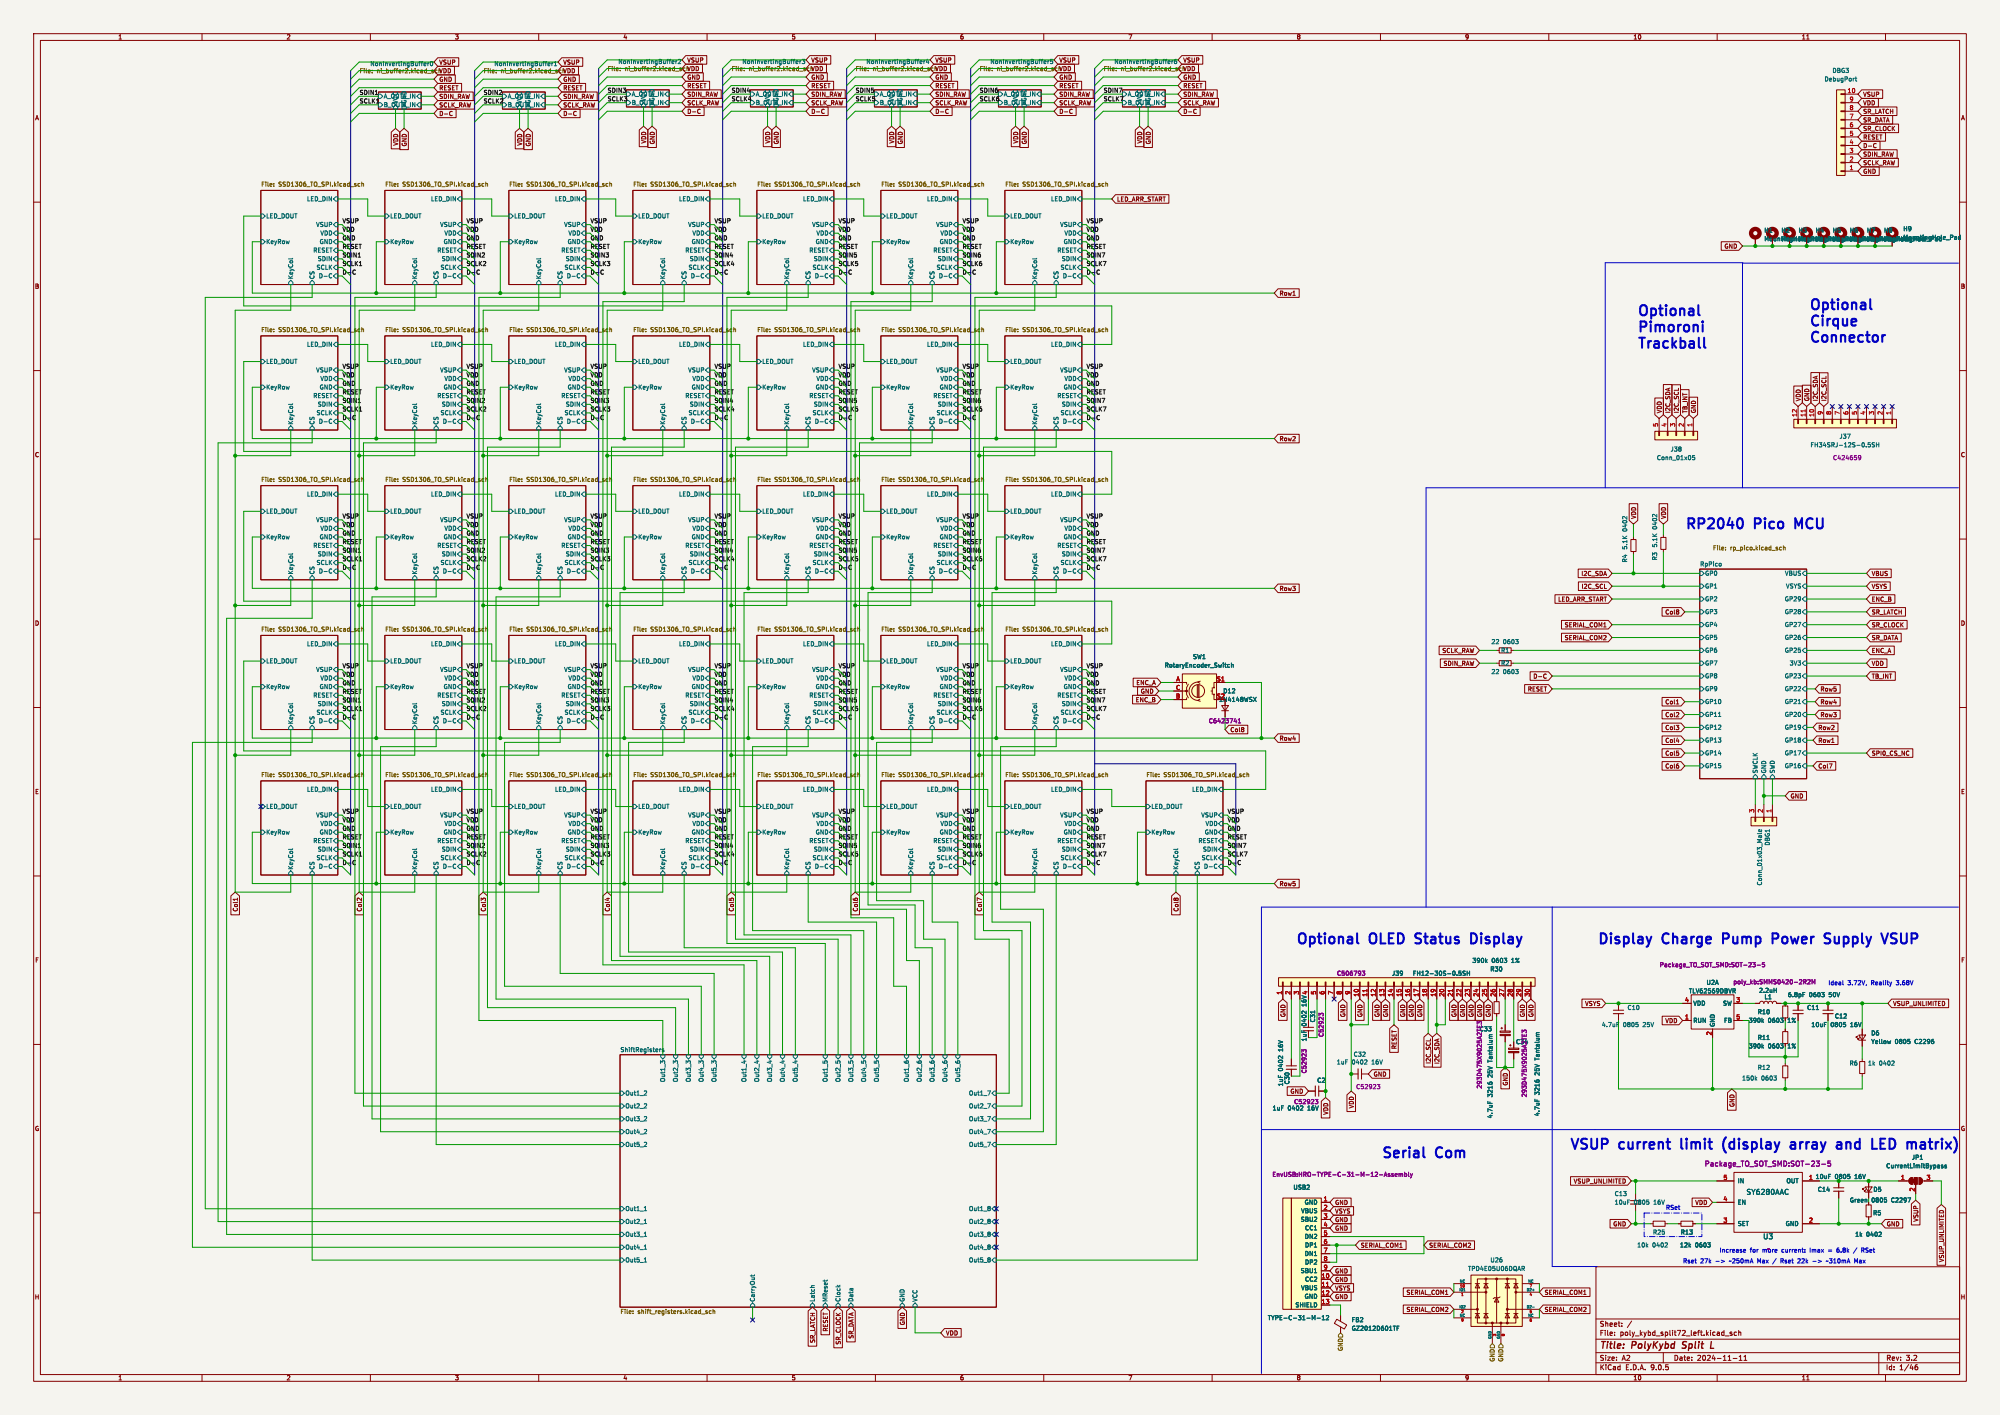
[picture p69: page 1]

https://www.lcsc.com/datasheet/lcsc_datasheet_1810121532_Silergy-Corp-SY6280AAC_C55136.pdf R³ ⁵.1K ⁰⁴⁰² ⁵

Optional OLED Status Display

Display Charge Pump Power Supply VSUP

Ideal 3.72V, Reality 3.68V RSet Serial Com

9101112131415161718192021222324252627282930 USB2 TYPE-C-31-M-12 EnvUSB:HRO-TYPE-C-31-M-12-Assembly GND

VSUP current limit (display array and LED matrix)

Package_TO_SOT_SMD:SOT-23-5
https://www.lcsc.com/datasheet/lcsc_datasheet_1810121532_Silergy-Corp-SY6280AAC_C55136.pdf IN
2 U3 SY6280AAC

13 USB2 TYPE-C-31-M-12 EnvUSB:HRO-TYPE-C-31-M-12-Assembly

Increase for more current: Imax = 6.8k / RSet

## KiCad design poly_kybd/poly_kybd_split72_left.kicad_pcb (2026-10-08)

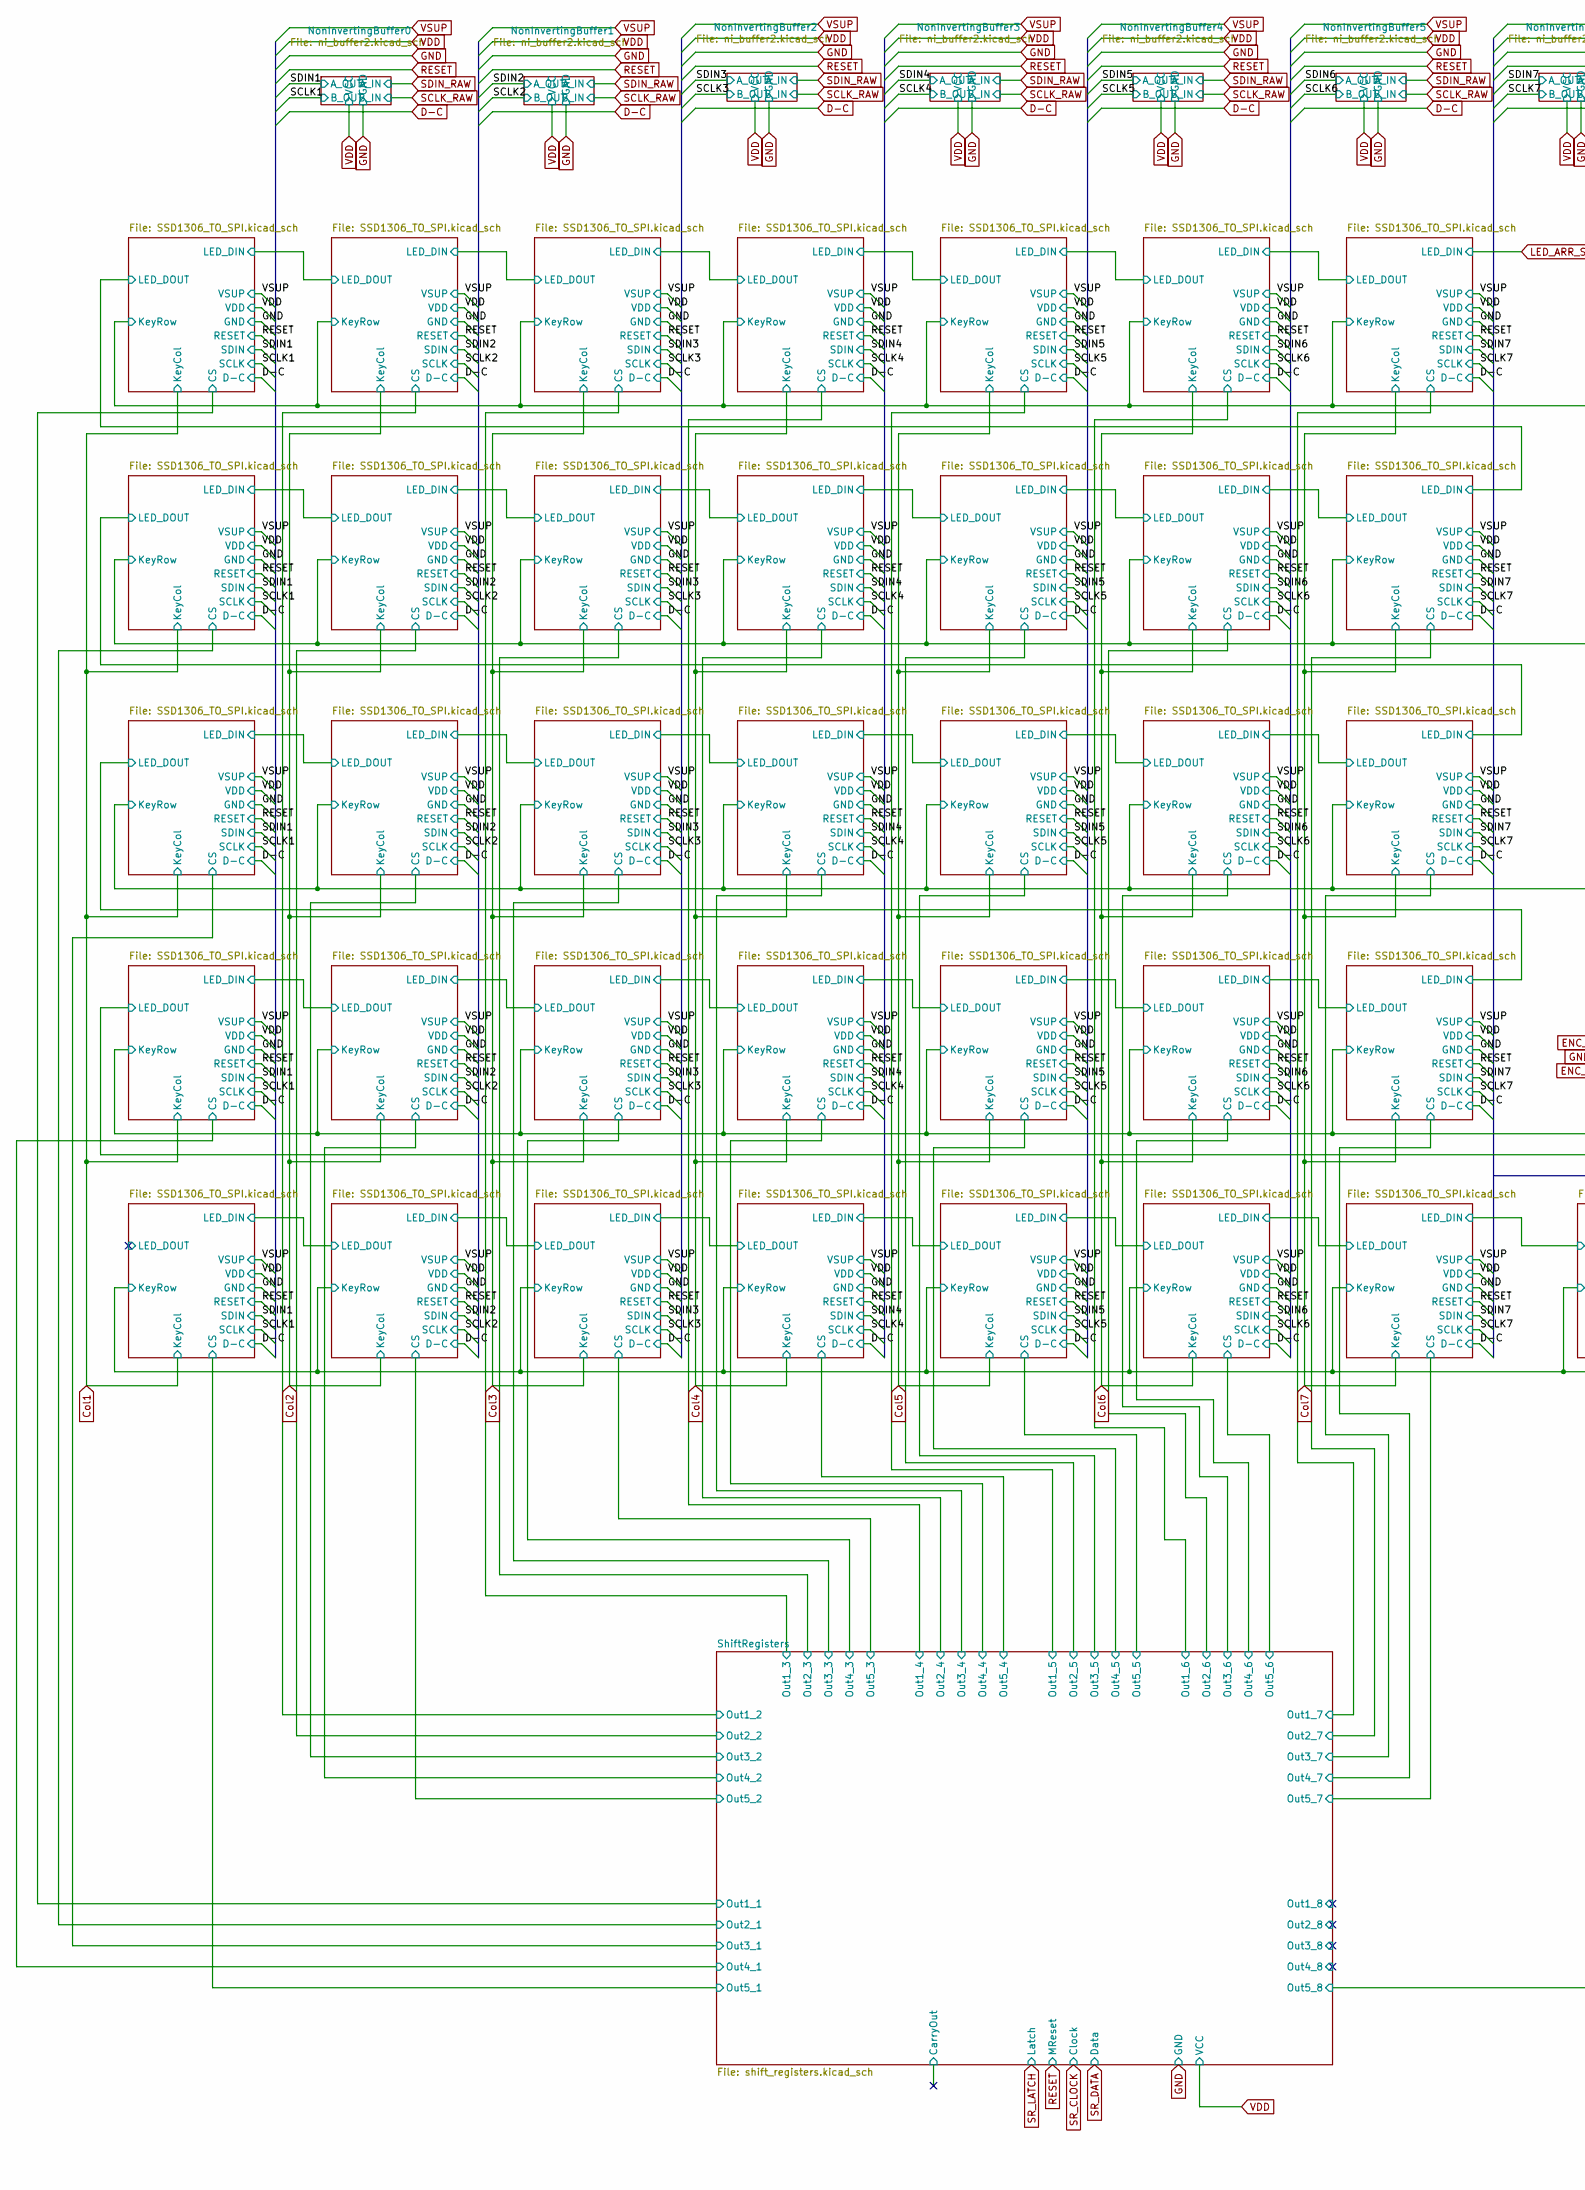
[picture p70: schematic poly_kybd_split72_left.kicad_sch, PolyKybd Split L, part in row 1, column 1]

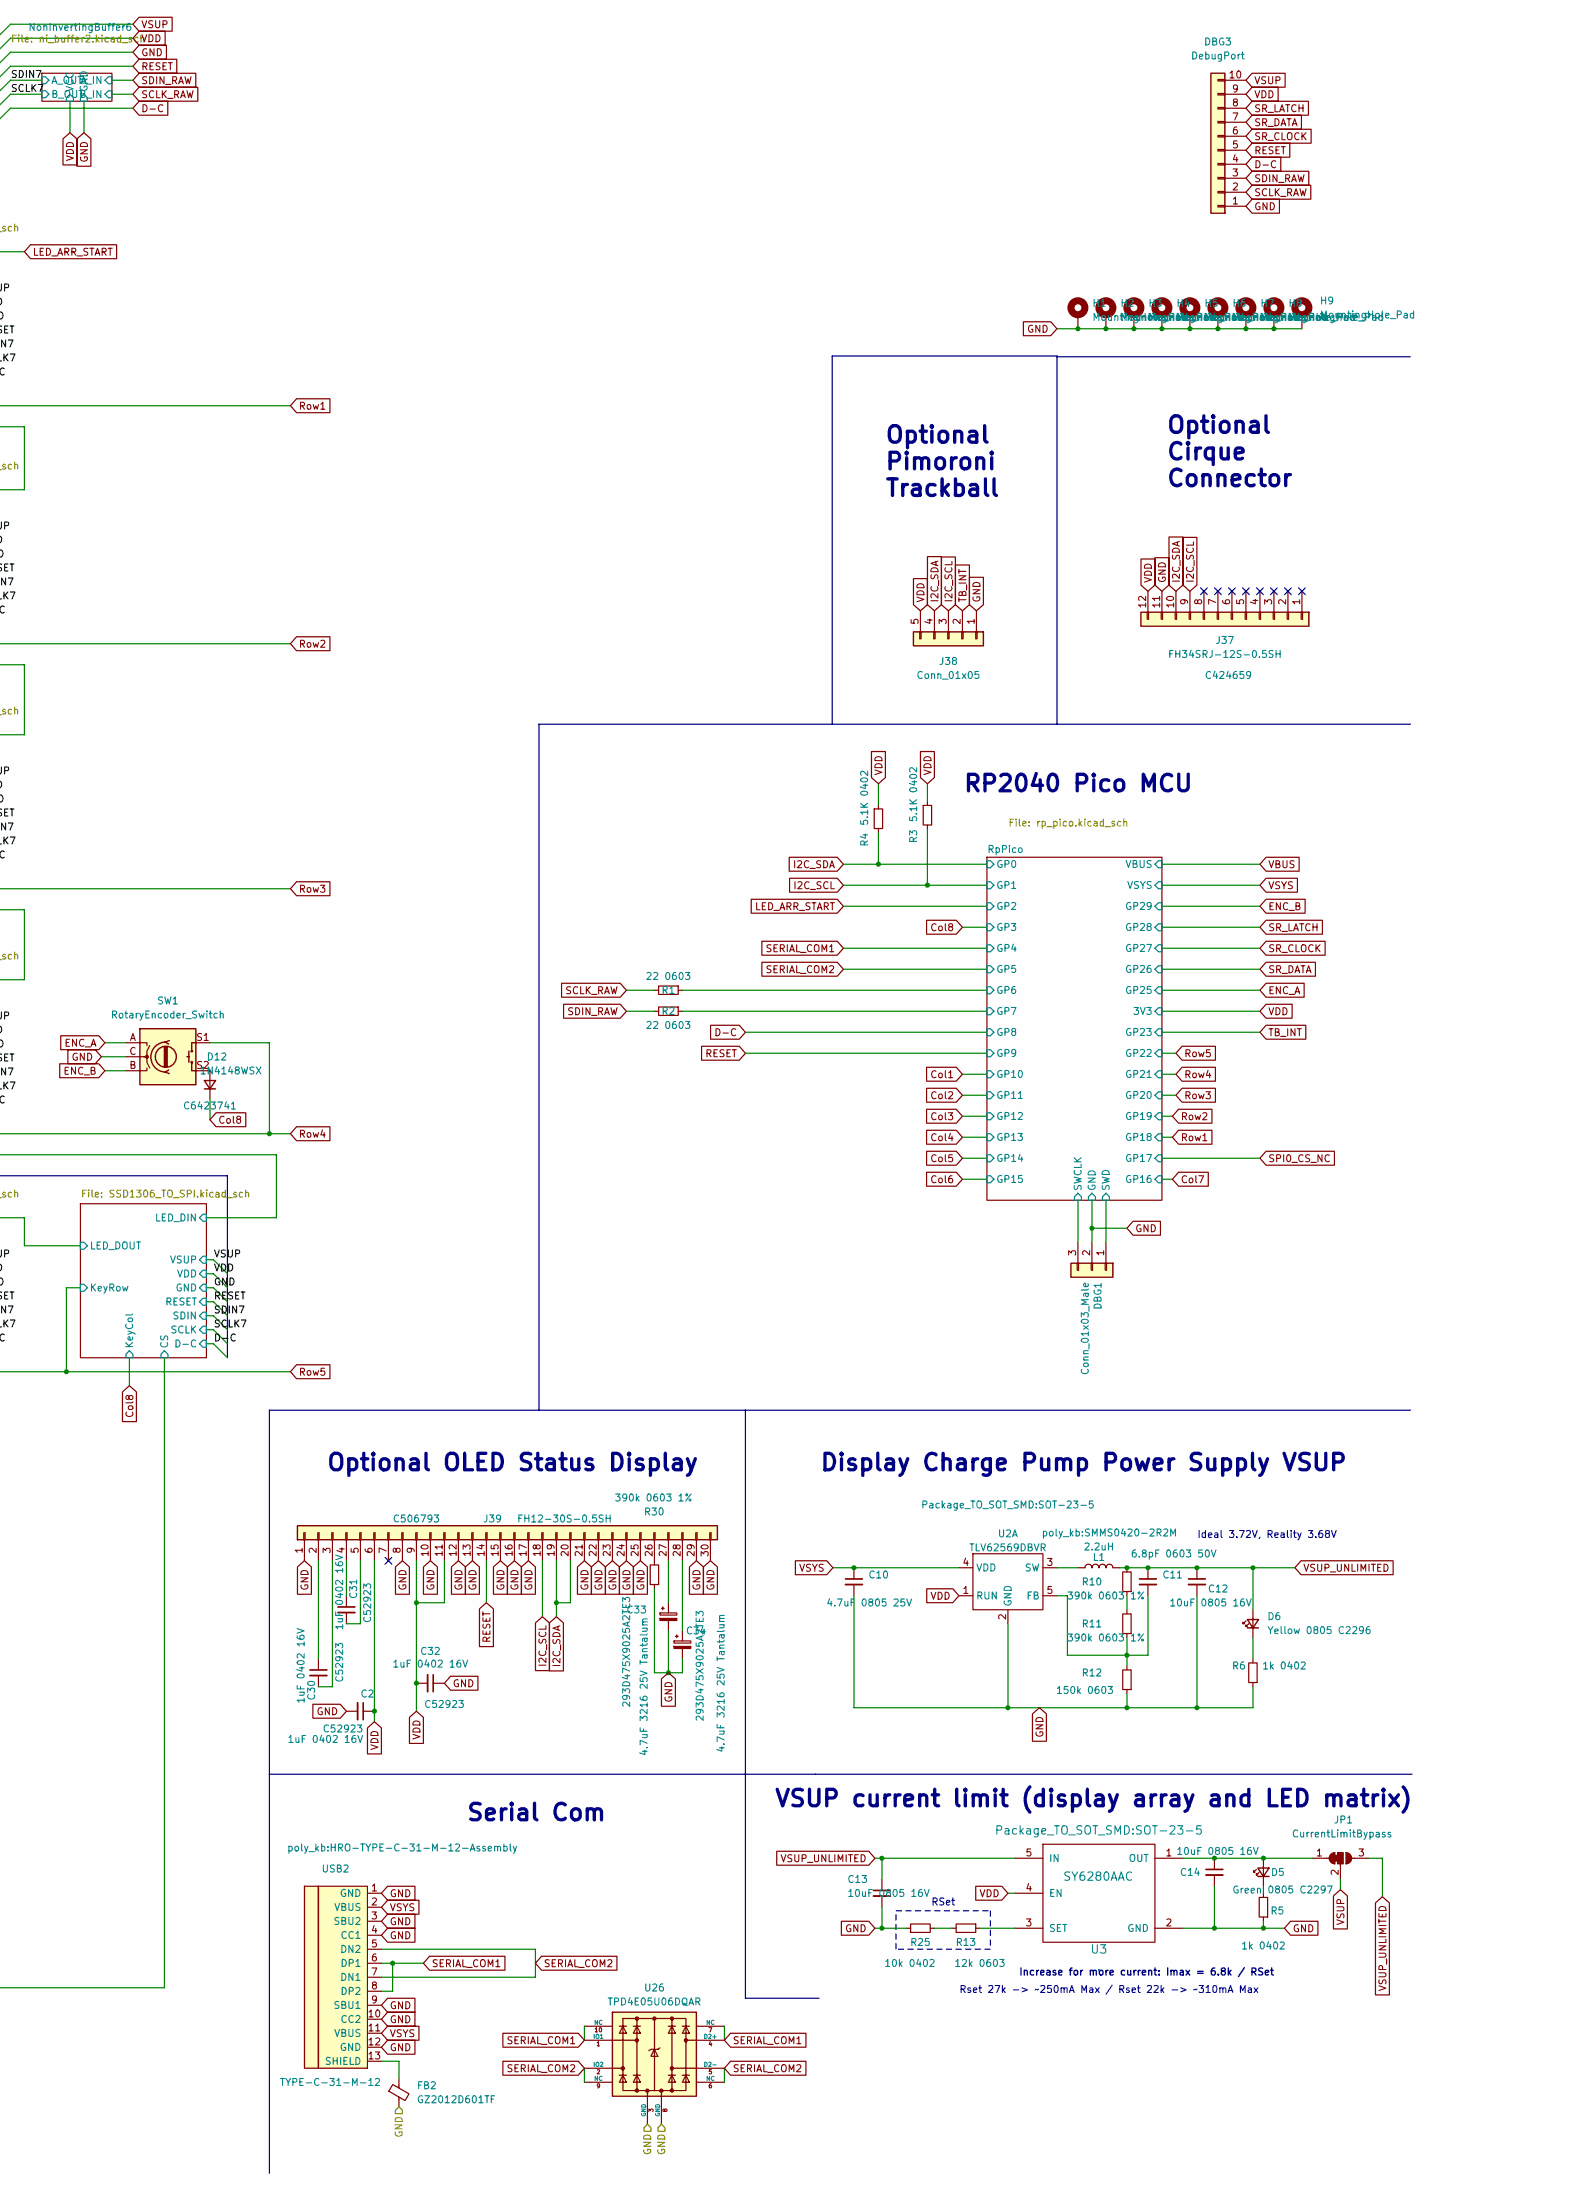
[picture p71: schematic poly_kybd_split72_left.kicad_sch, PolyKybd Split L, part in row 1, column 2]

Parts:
C2, C30, C31, C32: 1uF 0402 16V; C_0402_1005Metric; MPN C52923; JLC C52923
C10: 4.7uF 0805 25V; C_0805_2012Metric; MPN C1779; JLC C1779
C11: 6.8pF 0603 50V; C_0603_1608Metric; MPN CL10C6R8CB8NNNC; JLC C318672
C12, C13, C14: 10uF 0805 16V; C_0805_2012Metric; MPN C15850; JLC C15850
C33, C34: 4.7uF 3216 25V Tantalum; CP_EIA-3216-18_Kemet-A; MPN 293D475X9025A2TE3; JLC C5380411
D5: Green 0805 C2297; LED_0805_2012Metric; MPN C2297; JLC C2297
D6: Yellow 0805 C2296; LED_0805_2012Metric; MPN C2296; JLC C2296
D12: 1N4148WSX; D_SOD-323Ext; MPN C6423741; JLC C6423741
DBG1: Conn_01x03_Male; PinHeader_1x03_P2.54mm_Vertical; MPN DNP; JLC DNP
DBG3: DebugPort; PinHeader_1x10_P2.54mm_Vertical; MPN DNP; JLC DNP
FB2: GZ2012D601TF; L_0805_2012Metric; MPN C1017; JLC C1017
H1, H2, H3, H4, H5, H6, H7, H8, H9: MountingHole_Pad; MountingHole_3mm_Pad_Via; MPN DNP; JLC DNP
J37: FH34SRJ-12S-0.5SH; FH34SRJ12S05SH50-Rev2; MPN C424659; JLC C424659
J38: Conn_01x05; PinHeader_1x05_P2.54mm_Vertical; MPN DNP; JLC DNP
J39: FH12-30S-0.5SH; Hirose_FH12-30S-0.5SH_1x30-1MP_P0.50mm_Horizontal; MPN C506793; JLC C506793
JP1: CurrentLimitBypass; SolderJumper-3_P1.3mm_Bridged12_RoundedPad1.0x1.5mm; MPN DNP; JLC DNP
L1: 2.2uH; SMMS0420-2R2M; MPN C133191; JLC C133191
R1, R2: 22 0603; R_0603_1608Metric; MPN C108405; JLC C108405
R3, R4: 5.1K 0402; R_0402_1005Metric; MPN C144745; JLC C144745
R5, R6: 1k 0402; R_0402_1005Metric; MPN CRCW04021K00FKED; JLC C71623
R10, R11, R30: 390k 0603 1%; R_0603_1608Metric; MPN C137735; JLC C137735
R12: 150k 0603; R_0603_1608Metric; MPN C114660; JLC C114660
R13: 12k 0603; R_0603_1608Metric; MPN C114659; JLC C114659
R25: 10k 0402; R_0402_1005Metric; MPN C60490; JLC C60490
SW1: RotaryEncoder_Switch; PolyJog; MPN DNP; JLC DNP
U2: TLV62569DBVR; SOT-23-5; MPN C141836; JLC C141836
U3: SY6280AAC; SOT-23-5; MPN C55136; JLC C55136
U26: TPD4E05U06DQAR; USON-10; MPN C2836386; JLC C2836386
USB2: TYPE-C-31-M-12; HRO-TYPE-C-31-M-12-Assembly; MPN C165948; JLC C165948

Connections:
/RpPico/GPIO6: R1.1; also elsewhere on the board
/RpPico/GPIO7: R2.1; also elsewhere on the board
/RpPico/SWCLK: DBG1.3; also elsewhere on the board
/RpPico/SWD: DBG1.1; also elsewhere on the board
Col8: D12.1 (K); also elsewhere on the board
D-C: DBG3.4; also elsewhere on the board
ENC_A: SW1.A; also elsewhere on the board
ENC_B: SW1.B; also elsewhere on the board
GND: C2.2, C10.2, C12.2, C13.2, C14.2, C32.1, C33.2, C34.2, DBG1.2, DBG3.1, FB2.2, H1.1, H2.1, H3.1, H4.1, H5.1, H6.1, H7.1, H8.1, H9.1, J37.11, J38.1, J39.1, J39.8, J39.10, J39.12, J39.13, J39.15, J39.16, J39.17, J39.21, J39.22, J39.23, J39.24, J39.25, J39.29, J39.30, R5.1, R6.1, R12.1, R25.1, R30.1, SW1.C, U2.2 (GND), U3.2 (GND), U26.3 (GND), U26.8 (GND), USB2.1 (GND), USB2.3 (SBU2), USB2.4 (CC1), USB2.9 (SBU1), USB2.10 (CC2), USB2.12 (GND); also elsewhere on the board
I2C_SCL: J37.9, J38.3, J39.18, R3.2; also elsewhere on the board
I2C_SDA: J37.10, J38.4, J39.19, J39.20, R4.2; also elsewhere on the board
unnamed: C14.1, D5.2 (A), JP1.1 (A), U3.1 (OUT)
unnamed: D5.1 (K), R5.2
unnamed: D6.1 (K), R6.2
unnamed: D12.2 (A), SW1.S2
unnamed: C30.1, J39.2
unnamed: C30.2, J39.3
unnamed: C31.1, J39.4
unnamed: C31.2, J39.5
unnamed: J39.26, R30.2
unnamed: C33.1, J39.27
unnamed: C34.1, J39.28
unnamed: R10.1, R11.2
unnamed: R13.2, R25.2
unnamed: C11.2, R11.1, R12.2, U2.5 (FB)
unnamed: L1.1, U2.3 (SW)
unnamed: R13.1, U3.3 (SET)
unnamed: FB2.1, USB2.13 (SHIELD)
RESET: DBG3.5, J39.14; also elsewhere on the board
Row4: SW1.S1; also elsewhere on the board
SCLK_RAW: DBG3.2, R1.2; also elsewhere on the board
SDIN_RAW: DBG3.3, R2.2; also elsewhere on the board
SERIAL_COM1: U26.1 (IO1), U26.4 (D2+), U26.7 (NC), U26.10 (NC), USB2.6 (DP1), USB2.8 (DP2); also elsewhere on the board
SERIAL_COM2: U26.2 (IO2), U26.5 (D2-), U26.6 (NC), U26.9 (NC), USB2.5 (DN2), USB2.7 (DN1); also elsewhere on the board
SR_CLOCK: DBG3.6; also elsewhere on the board
SR_DATA: DBG3.7; also elsewhere on the board
SR_LATCH: DBG3.8; also elsewhere on the board
TB_INT: J38.2; also elsewhere on the board
VDD: C2.1, C32.2, DBG3.9, J37.12, J38.5, J39.6, J39.9, J39.11, R3.1, R4.1, U2.1 (RUN), U3.4 (EN); also elsewhere on the board
VSUP: DBG3.10, JP1.2 (C); also elsewhere on the board
VSUP_UNLIMITED: C11.1, C12.1, C13.1, D6.2 (A), JP1.3 (B), L1.2, R10.2, U3.5 (IN)
VSYS: C10.1, U2.4 (VDD), USB2.2 (VBUS), USB2.11 (VBUS); also elsewhere on the board

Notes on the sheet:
Optional Cirque Connector
RP2040 Pico MCU
Increase for more current: Imax = 6.8k / RSet
Ideal 3.72V, Reality 3.68V
Optional OLED Status Display
Display Charge Pump Power Supply VSUP
Optional Pimoroni Trackball
VSUP current limit (display array and LED matrix)
RSet
Serial Com
Rset 27k -> ~250mA Max / Rset 22k -> ~310mA Max

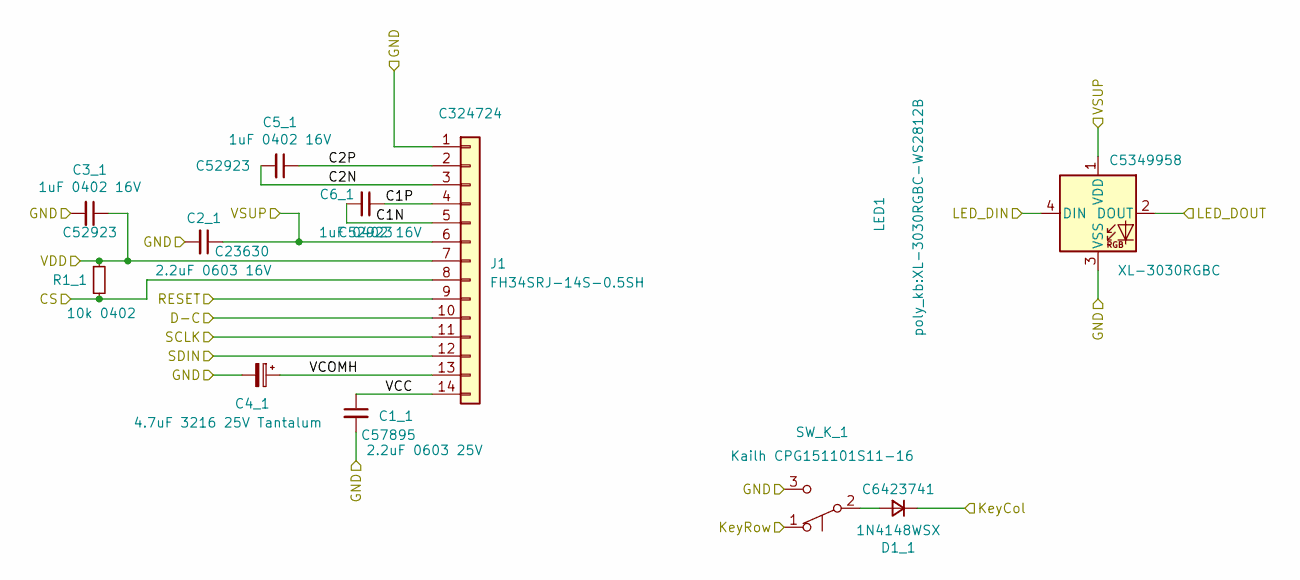
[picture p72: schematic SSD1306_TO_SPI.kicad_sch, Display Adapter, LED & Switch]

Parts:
C1_1: 2.2uF 0603 25V; C_0603_1608Metric; MPN C57895; LCSC C57895
C2_1: 2.2uF 0603 16V; C_0603_1608Metric; MPN C23630; LCSC C23630
C3_1, C5_1, C6_1: 1uF 0402 16V; C_0402_1005Metric; MPN C52923; LCSC C52923
C4_1: 4.7uF 3216 25V Tantalum; CP_EIA-3216-18_Kemet-A; MPN 293D475X9025A2TE3; JLC C5380411
D1_1: 1N4148WSX; D_SOD-323Ext; MPN C6423741; LCSC C6423741
J1: FH34SRJ-14S-0.5SH; FH34SRJ14S05SH50-Rev2; MPN C324724; LCSC C324724
LED1: XL-3030RGBC; XL-3030RGBC-WS2812B; MPN C5349958; LCSC C5349958
R1_1: 10k 0402; R_0402_1005Metric; MPN C60490; LCSC C60490
SW_K_1: Kailh CPG151101S11-16; Kailh_socket_MX_Indicators; MPN C5156480; JLC C5156480

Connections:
/K_1/LED_DOUT: LED1.4 (DIN); also elsewhere on the board
/K_L1/C1N: C6_1.2, J1.5
/K_L1/C1P: C6_1.1, J1.4
/K_L1/C2N: C5_1.2, J1.3
/K_L1/C2P: C5_1.1, J1.2
/K_L1/CS: J1.8, R1_1.2; also elsewhere on the board
/K_L1/LED_DOUT: LED1.2 (DOUT); also elsewhere on the board
/K_L1/VCC: C1_1.1, J1.14
/K_L1/VCOMH: C4_1.1, J1.13
/SCLK1: J1.11; also elsewhere on the board
/SDIN1: J1.12; also elsewhere on the board
Col1: D1_1.1 (K); also elsewhere on the board
D-C: J1.10; also elsewhere on the board
GND: C1_1.2, C2_1.2, C3_1.2, C4_1.2, J1.1, LED1.3 (VSS), SW_K_1.3 (C); also elsewhere on the board
unnamed: D1_1.2 (A), SW_K_1.2 (B)
RESET: J1.9; also elsewhere on the board
Row1: SW_K_1.1 (A); also elsewhere on the board
VDD: C3_1.1, J1.7, R1_1.1; also elsewhere on the board
VSUP: C2_1.1, J1.6, LED1.1 (VDD); also elsewhere on the board

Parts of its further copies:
C1_2, C1_3, C1_4, C1_5, C1_6, C1_7, C1_8, C1_9, C1_10, C1_11, C1_12, C1_13, C1_14, C1_15, C1_16, C1_17, C1_18, C1_19, C1_20, C1_21, C1_22, C1_23, C1_24, C1_25, C1_26, C1_27, C1_28, C1_29, C1_30, C1_31, C1_32, C1_33, C1_34, C1_35, C1_36: 2.2uF 0603 25V; C_0603_1608Metric; MPN C57895; LCSC C57895
C2_2, C2_3, C2_4, C2_5, C2_6, C2_7, C2_8, C2_9, C2_10, C2_11, C2_12, C2_13, C2_14, C2_15, C2_16, C2_17, C2_18, C2_19, C2_20, C2_21, C2_22, C2_23, C2_24, C2_25, C2_26, C2_27, C2_28, C2_29, C2_30, C2_31, C2_32, C2_33, C2_34, C2_35, C2_36: 2.2uF 0603 16V; C_0603_1608Metric; MPN C23630; LCSC C23630
C3_2, C3_3, C3_4, C3_5, C3_6, C3_7, C3_8, C3_9, C3_10, C3_11, C3_12, C3_13, C3_14, C3_15, C3_16, C3_17, C3_18, C3_19, C3_20, C3_21, C3_22, C3_23, C3_24, C3_25, C3_26, C3_27, C3_28, C3_29, C3_30, C3_31, C3_32, C3_33, C3_34, C3_35, C3_36, C5_2, C5_3, C5_4, C5_5, C5_6, C5_7, C5_8, C5_9, C5_10, C5_11, C5_12, C5_13, C5_14, C5_15, C5_16, C5_17, C5_18, C5_19, C5_20, C5_21, C5_22, C5_23, C5_24, C5_25, C5_26, C5_27, C5_28, C5_29, C5_30, C5_31, C5_32, C5_33, C5_34, C5_35, C5_36, C6_2, C6_3, C6_4, C6_5, C6_6, C6_7, C6_8, C6_9, C6_10, C6_11, C6_12, C6_13, C6_14, C6_15, C6_16, C6_17, C6_18, C6_19, C6_20, C6_21, C6_22, C6_23, C6_24, C6_25, C6_26, C6_27, C6_28, C6_29, C6_30, C6_31, C6_32, C6_33, C6_34, C6_35, C6_36: 1uF 0402 16V; C_0402_1005Metric; MPN C52923; LCSC C52923
C4_2, C4_3, C4_4, C4_5, C4_6, C4_7, C4_8, C4_9, C4_10, C4_11, C4_12, C4_13, C4_14, C4_15, C4_16, C4_17, C4_18, C4_19, C4_20, C4_21, C4_22, C4_23, C4_24, C4_25, C4_26, C4_27, C4_28, C4_29, C4_30, C4_31, C4_32, C4_33, C4_34, C4_35, C4_36: 4.7uF 3216 25V Tantalum; CP_EIA-3216-18_Kemet-A; MPN 293D475X9025A2TE3; JLC C5380411
D1_2, D1_3, D1_4, D1_5, D1_6, D1_7, D1_8, D1_9, D1_10, D1_11, D1_12, D1_13, D1_14, D1_15, D1_16, D1_17, D1_18, D1_19, D1_20, D1_21, D1_22, D1_23, D1_24, D1_25, D1_26, D1_27, D1_28, D1_29, D1_30, D1_31, D1_32, D1_33, D1_34, D1_35, D1_36: 1N4148WSX; D_SOD-323Ext; MPN C6423741; LCSC C6423741
J2, J3, J4, J5, J6, J7, J8, J9, J10, J11, J12, J13, J14, J15, J16, J17, J18, J19, J20, J21, J22, J23, J24, J25, J26, J27, J28, J29, J30, J31, J32, J33, J34, J35, J36: FH34SRJ-14S-0.5SH; FH34SRJ14S05SH50-Rev2; MPN C324724; LCSC C324724
LED2, LED3, LED4, LED5, LED6, LED7, LED8, LED9, LED10, LED11, LED12, LED13, LED14, LED15, LED16, LED17, LED18, LED19, LED20, LED21, LED22, LED23, LED24, LED25, LED26, LED27, LED28, LED29, LED30, LED31, LED32, LED33, LED34, LED35, LED36: XL-3030RGBC; XL-3030RGBC-WS2812B; MPN C5349958; LCSC C5349958
R1_2, R1_3, R1_4, R1_5, R1_6, R1_7, R1_8, R1_9, R1_10, R1_11, R1_12, R1_13, R1_14, R1_15, R1_16, R1_17, R1_18, R1_19, R1_20, R1_21, R1_22, R1_23, R1_24, R1_25, R1_26, R1_27, R1_28, R1_29, R1_30, R1_31, R1_32, R1_33, R1_34, R1_35, R1_36: 10k 0402; R_0402_1005Metric; MPN C60490; LCSC C60490
SW_K_2, SW_K_3, SW_K_4, SW_K_5, SW_K_6, SW_K_7, SW_K_8, SW_K_9, SW_K_10, SW_K_11, SW_K_12, SW_K_13, SW_K_14, SW_K_15, SW_K_16, SW_K_17, SW_K_18, SW_K_19, SW_K_20, SW_K_21, SW_K_22, SW_K_23, SW_K_24, SW_K_25, SW_K_26, SW_K_27, SW_K_28, SW_K_29, SW_K_30, SW_K_31, SW_K_32, SW_K_33, SW_K_34, SW_K_35, SW_K_36: Kailh CPG151101S11-16; Kailh_socket_MX_Indicators; MPN C5156480; JLC C5156480

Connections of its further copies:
/K_1/C1N: C6_2.2, J2.5
/K_1/C1P: C6_2.1, J2.4
/K_1/C2N: C5_2.2, J2.3
/K_1/C2P: C5_2.1, J2.2
/K_1/CS: J2.8, R1_2.2; also elsewhere on the board
/K_1/LED_DIN: LED2.4 (DIN), LED3.2 (DOUT)
/K_1/LED_DOUT: LED2.2 (DOUT); also elsewhere on the board
/K_1/VCC: C1_2.1, J2.14
/K_1/VCOMH: C4_2.1, J2.13
/K_2/C1N: C6_3.2, J3.5
/K_2/C1P: C6_3.1, J3.4
/K_2/C2N: C5_3.2, J3.3
/K_2/C2P: C5_3.1, J3.2
/K_2/CS: J3.8, R1_3.2; also elsewhere on the board
/K_2/LED_DIN: LED3.4 (DIN), LED4.2 (DOUT)
/K_2/VCC: C1_3.1, J3.14
/K_2/VCOMH: C4_3.1, J3.13
/K_3/C1N: C6_4.2, J4.5
/K_3/C1P: C6_4.1, J4.4
/K_3/C2N: C5_4.2, J4.3
/K_3/C2P: C5_4.1, J4.2
/K_3/CS: J4.8, R1_4.2; also elsewhere on the board
/K_3/LED_DIN: LED4.4 (DIN), LED5.2 (DOUT)
/K_3/VCC: C1_4.1, J4.14
/K_3/VCOMH: C4_4.1, J4.13
/K_4/C1N: C6_5.2, J5.5
/K_4/C1P: C6_5.1, J5.4
/K_4/C2N: C5_5.2, J5.3
/K_4/C2P: C5_5.1, J5.2
/K_4/CS: J5.8, R1_5.2; also elsewhere on the board
/K_4/LED_DIN: LED5.4 (DIN), LED6.2 (DOUT)
/K_4/VCC: C1_5.1, J5.14
/K_4/VCOMH: C4_5.1, J5.13
/K_5/C1N: C6_6.2, J6.5
/K_5/C1P: C6_6.1, J6.4
/K_5/C2N: C5_6.2, J6.3
/K_5/C2P: C5_6.1, J6.2
/K_5/CS: J6.8, R1_6.2; also elsewhere on the board
/K_5/LED_DIN: LED6.4 (DIN), LED7.2 (DOUT)
/K_5/VCC: C1_6.1, J6.14
/K_5/VCOMH: C4_6.1, J6.13
/K_A/C1N: C6_16.2, J16.5
/K_A/C1P: C6_16.1, J16.4
/K_A/C2N: C5_16.2, J16.3
/K_A/C2P: C5_16.1, J16.2
/K_A/CS: J16.8, R1_16.2; also elsewhere on the board
/K_A/LED_DIN: LED16.4 (DIN), LED17.2 (DOUT)
/K_A/LED_DOUT: LED15.4 (DIN), LED16.2 (DOUT)
/K_A/VCC: C1_16.1, J16.14
/K_A/VCOMH: C4_16.1, J16.13
/K_B1/C1N: C6_30.2, J30.5
/K_B1/C1P: C6_30.1, J30.4
/K_B1/C2N: C5_30.2, J30.3
/K_B1/C2P: C5_30.1, J30.2
/K_B1/CS: J30.8, R1_30.2; also elsewhere on the board
/K_B1/LED_DIN: LED30.4 (DIN), LED31.2 (DOUT)
/K_B1/LED_DOUT: LED30.2 (DOUT)
/K_B1/VCC: C1_30.1, J30.14
/K_B1/VCOMH: C4_30.1, J30.13
/K_B2/C1N: C6_31.2, J31.5
/K_B2/C1P: C6_31.1, J31.4
/K_B2/C2N: C5_31.2, J31.3
/K_B2/C2P: C5_31.1, J31.2
/K_B2/CS: J31.8, R1_31.2; also elsewhere on the board
/K_B2/LED_DIN: LED31.4 (DIN), LED32.2 (DOUT)
/K_B2/VCC: C1_31.1, J31.14
/K_B2/VCOMH: C4_31.1, J31.13
/K_B3/C1N: C6_32.2, J32.5
/K_B3/C1P: C6_32.1, J32.4
/K_B3/C2N: C5_32.2, J32.3
/K_B3/C2P: C5_32.1, J32.2
/K_B3/CS: J32.8, R1_32.2; also elsewhere on the board
/K_B3/LED_DIN: LED32.4 (DIN), LED33.2 (DOUT)
/K_B3/VCC: C1_32.1, J32.14
/K_B3/VCOMH: C4_32.1, J32.13
/K_B4/C1N: C6_33.2, J33.5
/K_B4/C1P: C6_33.1, J33.4
/K_B4/C2N: C5_33.2, J33.3
/K_B4/C2P: C5_33.1, J33.2
/K_B4/CS: J33.8, R1_33.2; also elsewhere on the board
/K_B4/LED_DIN: LED33.4 (DIN), LED34.2 (DOUT)
/K_B4/VCC: C1_33.1, J33.14
/K_B4/VCOMH: C4_33.1, J33.13
/K_B5/C1N: C6_34.2, J34.5
/K_B5/C1P: C6_34.1, J34.4
/K_B5/C2N: C5_34.2, J34.3
/K_B5/C2P: C5_34.1, J34.2
/K_B5/CS: J34.8, R1_34.2; also elsewhere on the board
/K_B5/LED_DIN: LED34.4 (DIN), LED35.2 (DOUT)
/K_B5/VCC: C1_34.1, J34.14
/K_B5/VCOMH: C4_34.1, J34.13
/K_B6/C1N: C6_35.2, J35.5
/K_B6/C1P: C6_35.1, J35.4
/K_B6/C2N: C5_35.2, J35.3
/K_B6/C2P: C5_35.1, J35.2
/K_B6/CS: J35.8, R1_35.2; also elsewhere on the board
/K_B6/LED_DIN: LED35.4 (DIN), LED36.2 (DOUT)
/K_B6/VCC: C1_35.1, J35.14
/K_B6/VCOMH: C4_35.1, J35.13
/K_B7/C1N: C6_36.2, J36.5
/K_B7/C1P: C6_36.1, J36.4
/K_B7/C2N: C5_36.2, J36.3
/K_B7/C2P: C5_36.1, J36.2
/K_B7/CS: J36.8, R1_36.2; also elsewhere on the board
/K_B7/LED_DIN: LED29.2 (DOUT), LED36.4 (DIN)
/K_B7/VCC: C1_36.1, J36.14
/K_B7/VCOMH: C4_36.1, J36.13
/K_B8/C1N: C6_29.2, J29.5
/K_B8/C1P: C6_29.1, J29.4
/K_B8/C2N: C5_29.2, J29.3
/K_B8/C2P: C5_29.1, J29.2
/K_B8/CS: J29.8, R1_29.2; also elsewhere on the board
/K_B8/LED_DIN: LED22.2 (DOUT), LED29.4 (DIN)
/K_B8/VCC: C1_29.1, J29.14
/K_B8/VCOMH: C4_29.1, J29.13
/K_B/C1N: C6_27.2, J27.5
/K_B/C1P: C6_27.1, J27.4
/K_B/C2N: C5_27.2, J27.3
/K_B/C2P: C5_27.1, J27.2
/K_B/CS: J27.8, R1_27.2; also elsewhere on the board
/K_B/LED_DIN: LED27.4 (DIN), LED28.2 (DOUT)
/K_B/LED_DOUT: LED26.4 (DIN), LED27.2 (DOUT)
/K_B/VCC: C1_27.1, J27.14
/K_B/VCOMH: C4_27.1, J27.13
/K_C/C1N: C6_25.2, J25.5
/K_C/C1P: C6_25.1, J25.4
/K_C/C2N: C5_25.2, J25.3
/K_C/C2P: C5_25.1, J25.2
/K_C/CS: J25.8, R1_25.2; also elsewhere on the board
/K_C/LED_DIN: LED25.4 (DIN), LED26.2 (DOUT)
/K_C/LED_DOUT: LED24.4 (DIN), LED25.2 (DOUT)
/K_C/VCC: C1_25.1, J25.14
/K_C/VCOMH: C4_25.1, J25.13
/K_D/C1N: C6_18.2, J18.5
/K_D/C1P: C6_18.1, J18.4
/K_D/C2N: C5_18.2, J18.3
/K_D/C2P: C5_18.1, J18.2
/K_D/CS: J18.8, R1_18.2; also elsewhere on the board
/K_D/LED_DIN: LED18.4 (DIN), LED19.2 (DOUT)
/K_D/LED_DOUT: LED17.4 (DIN), LED18.2 (DOUT)
/K_D/VCC: C1_18.1, J18.14
/K_D/VCOMH: C4_18.1, J18.13
/K_E/C1N: C6_11.2, J11.5
/K_E/C1P: C6_11.1, J11.4
/K_E/C2N: C5_11.2, J11.3
/K_E/C2P: C5_11.1, J11.2
/K_E/CS: J11.8, R1_11.2; also elsewhere on the board
/K_E/LED_DIN: LED11.4 (DIN), LED12.2 (DOUT)
/K_E/LED_DOUT: LED10.4 (DIN), LED11.2 (DOUT)
/K_E/VCC: C1_11.1, J11.14
/K_E/VCOMH: C4_11.1, J11.13
/K_F/C1N: C6_19.2, J19.5
/K_F/C1P: C6_19.1, J19.4
/K_F/C2N: C5_19.2, J19.3
/K_F/C2P: C5_19.1, J19.2
/K_F/CS: J19.8, R1_19.2; also elsewhere on the board
/K_F/LED_DIN: LED19.4 (DIN), LED20.2 (DOUT)
/K_F/VCC: C1_19.1, J19.14
/K_F/VCOMH: C4_19.1, J19.13
/K_G/C1N: C6_20.2, J20.5
/K_G/C1P: C6_20.1, J20.4
/K_G/C2N: C5_20.2, J20.3
/K_G/C2P: C5_20.1, J20.2
/K_G/CS: J20.8, R1_20.2; also elsewhere on the board
/K_G/LED_DIN: LED20.4 (DIN), LED21.2 (DOUT)
/K_G/VCC: C1_20.1, J20.14
/K_G/VCOMH: C4_20.1, J20.13
/K_L1/LED_DOUT: LED14.4 (DIN); also elsewhere on the board
/K_L2/C1N: C6_8.2, J8.5
/K_L2/C1P: C6_8.1, J8.4
/K_L2/C2N: C5_8.2, J8.3
/K_L2/C2P: C5_8.1, J8.2
/K_L2/CS: J8.8, R1_8.2; also elsewhere on the board
/K_L2/LED_DIN: LED8.4 (DIN), LED9.2 (DOUT)
/K_L2/LED_DOUT: LED8.2 (DOUT), LED21.4 (DIN)
/K_L2/VCC: C1_8.1, J8.14
/K_L2/VCOMH: C4_8.1, J8.13
/K_L3/C1N: C6_15.2, J15.5
/K_L3/C1P: C6_15.1, J15.4
/K_L3/C2N: C5_15.2, J15.3
/K_L3/C2P: C5_15.1, J15.2
/K_L3/CS: J15.8, R1_15.2; also elsewhere on the board
/K_L3/LED_DOUT: LED15.2 (DOUT), LED28.4 (DIN)
/K_L3/VCC: C1_15.1, J15.14
/K_L3/VCOMH: C4_15.1, J15.13
/K_L4/C1N: C6_22.2, J22.5
/K_L4/C1P: C6_22.1, J22.4
/K_L4/C2N: C5_22.2, J22.3
/K_L4/C2P: C5_22.1, J22.2
/K_L4/CS: J22.8, R1_22.2; also elsewhere on the board
/K_L4/LED_DIN: LED22.4 (DIN), LED23.2 (DOUT)
/K_L4/VCC: C1_22.1, J22.14
/K_L4/VCOMH: C4_22.1, J22.13
/K_L6/C1N: C6_7.2, J7.5
/K_L6/C1P: C6_7.1, J7.4
/K_L6/C2N: C5_7.2, J7.3
/K_L6/C2P: C5_7.1, J7.2
/K_L6/CS: J7.8, R1_7.2; also elsewhere on the board
/K_L6/VCC: C1_7.1, J7.14
/K_L6/VCOMH: C4_7.1, J7.13
/K_L7/C1N: C6_14.2, J14.5
/K_L7/C1P: C6_14.1, J14.4
/K_L7/C2N: C5_14.2, J14.3
/K_L7/C2P: C5_14.1, J14.2
/K_L7/CS: J14.8, R1_14.2; also elsewhere on the board
/K_L7/LED_DOUT: LED13.4 (DIN), LED14.2 (DOUT)
/K_L7/VCC: C1_14.1, J14.14
/K_L7/VCOMH: C4_14.1, J14.13
/K_L8/C1N: C6_21.2, J21.5
/K_L8/C1P: C6_21.1, J21.4
/K_L8/C2N: C5_21.2, J21.3
/K_L8/C2P: C5_21.1, J21.2
/K_L8/CS: J21.8, R1_21.2; also elsewhere on the board
/K_L8/VCC: C1_21.1, J21.14
/K_L8/VCOMH: C4_21.1, J21.13
/K_L9/C1N: C6_28.2, J28.5
/K_L9/C1P: C6_28.1, J28.4
/K_L9/C2N: C5_28.2, J28.3
/K_L9/C2P: C5_28.1, J28.2
/K_L9/CS: J28.8, R1_28.2; also elsewhere on the board
/K_L9/VCC: C1_28.1, J28.14
/K_L9/VCOMH: C4_28.1, J28.13
/K_Q/C1N: C6_9.2, J9.5
/K_Q/C1P: C6_9.1, J9.4
/K_Q/C2N: C5_9.2, J9.3
/K_Q/C2P: C5_9.1, J9.2
/K_Q/CS: J9.8, R1_9.2; also elsewhere on the board
/K_Q/LED_DIN: LED9.4 (DIN), LED10.2 (DOUT)
/K_Q/VCC: C1_9.1, J9.14
/K_Q/VCOMH: C4_9.1, J9.13
/K_R/C1N: C6_12.2, J12.5
/K_R/C1P: C6_12.1, J12.4
/K_R/C2N: C5_12.2, J12.3
/K_R/C2P: C5_12.1, J12.2
/K_R/CS: J12.8, R1_12.2; also elsewhere on the board
/K_R/LED_DIN: LED12.4 (DIN), LED13.2 (DOUT)
/K_R/VCC: C1_12.1, J12.14
/K_R/VCOMH: C4_12.1, J12.13
/K_S/C1N: C6_17.2, J17.5
/K_S/C1P: C6_17.1, J17.4
/K_S/C2N: C5_17.2, J17.3
/K_S/C2P: C5_17.1, J17.2
/K_S/CS: J17.8, R1_17.2; also elsewhere on the board
/K_S/VCC: C1_17.1, J17.14
/K_S/VCOMH: C4_17.1, J17.13
/K_T/C1N: C6_13.2, J13.5
/K_T/C1P: C6_13.1, J13.4
/K_T/C2N: C5_13.2, J13.3
/K_T/C2P: C5_13.1, J13.2
/K_T/CS: J13.8, R1_13.2; also elsewhere on the board
/K_T/VCC: C1_13.1, J13.14
/K_T/VCOMH: C4_13.1, J13.13
/K_V/C1N: C6_26.2, J26.5
/K_V/C1P: C6_26.1, J26.4
/K_V/C2N: C5_26.2, J26.3
/K_V/C2P: C5_26.1, J26.2
/K_V/CS: J26.8, R1_26.2; also elsewhere on the board
/K_V/VCC: C1_26.1, J26.14
/K_V/VCOMH: C4_26.1, J26.13
/K_W/C1N: C6_10.2, J10.5
/K_W/C1P: C6_10.1, J10.4
/K_W/C2N: C5_10.2, J10.3
/K_W/C2P: C5_10.1, J10.2
/K_W/CS: J10.8, R1_10.2; also elsewhere on the board
/K_W/VCC: C1_10.1, J10.14
/K_W/VCOMH: C4_10.1, J10.13
/K_X/C1N: C6_24.2, J24.5
/K_X/C1P: C6_24.1, J24.4
/K_X/C2N: C5_24.2, J24.3
/K_X/C2P: C5_24.1, J24.2
/K_X/CS: J24.8, R1_24.2; also elsewhere on the board
/K_X/LED_DOUT: LED23.4 (DIN), LED24.2 (DOUT)
/K_X/VCC: C1_24.1, J24.14
/K_X/VCOMH: C4_24.1, J24.13
/K_Z/C1N: C6_23.2, J23.5
/K_Z/C1P: C6_23.1, J23.4
/K_Z/C2N: C5_23.2, J23.3
/K_Z/C2P: C5_23.1, J23.2
/K_Z/CS: J23.8, R1_23.2; also elsewhere on the board
/K_Z/VCC: C1_23.1, J23.14
/K_Z/VCOMH: C4_23.1, J23.13
/SCLK1: J8.11, J15.11, J22.11, J30.11; also elsewhere on the board
/SCLK2: J2.11, J9.11, J16.11, J23.11, J31.11; also elsewhere on the board
/SCLK3: J3.11, J10.11, J17.11, J24.11, J32.11; also elsewhere on the board
/SCLK4: J4.11, J11.11, J18.11, J25.11, J33.11; also elsewhere on the board
/SCLK5: J5.11, J12.11, J19.11, J26.11, J34.11; also elsewhere on the board
/SCLK6: J6.11, J13.11, J20.11, J27.11, J35.11; also elsewhere on the board
/SCLK7: J7.11, J14.11, J21.11, J28.11, J29.11, J36.11; also elsewhere on the board
/SDIN1: J8.12, J15.12, J22.12, J30.12; also elsewhere on the board
/SDIN2: J2.12, J9.12, J16.12, J23.12, J31.12; also elsewhere on the board
/SDIN3: J3.12, J10.12, J17.12, J24.12, J32.12; also elsewhere on the board
/SDIN4: J4.12, J11.12, J18.12, J25.12, J33.12; also elsewhere on the board
/SDIN5: J5.12, J12.12, J19.12, J26.12, J34.12; also elsewhere on the board
/SDIN6: J6.12, J13.12, J20.12, J27.12, J35.12; also elsewhere on the board
/SDIN7: J7.12, J14.12, J21.12, J28.12, J29.12, J36.12; also elsewhere on the board
Col1: D1_8.1 (K), D1_15.1 (K), D1_22.1 (K), D1_30.1 (K); also elsewhere on the board
Col2: D1_2.1 (K), D1_9.1 (K), D1_16.1 (K), D1_23.1 (K), D1_31.1 (K); also elsewhere on the board
Col3: D1_3.1 (K), D1_10.1 (K), D1_17.1 (K), D1_24.1 (K), D1_32.1 (K); also elsewhere on the board
Col4: D1_4.1 (K), D1_11.1 (K), D1_18.1 (K), D1_25.1 (K), D1_33.1 (K); also elsewhere on the board
Col5: D1_5.1 (K), D1_12.1 (K), D1_19.1 (K), D1_26.1 (K), D1_34.1 (K); also elsewhere on the board
Col6: D1_6.1 (K), D1_13.1 (K), D1_20.1 (K), D1_27.1 (K), D1_35.1 (K); also elsewhere on the board
Col7: D1_7.1 (K), D1_14.1 (K), D1_21.1 (K), D1_28.1 (K), D1_36.1 (K); also elsewhere on the board
Col8: D1_29.1 (K); also elsewhere on the board
D-C: J2.10, J3.10, J4.10, J5.10, J6.10, J7.10, J8.10, J9.10, J10.10, J11.10, J12.10, J13.10, J14.10, J15.10, J16.10, J17.10, J18.10, J19.10, J20.10, J21.10, J22.10, J23.10, J24.10, J25.10, J26.10, J27.10, J28.10, J29.10, J30.10, J31.10, J32.10, J33.10, J34.10, J35.10, J36.10; also elsewhere on the board
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

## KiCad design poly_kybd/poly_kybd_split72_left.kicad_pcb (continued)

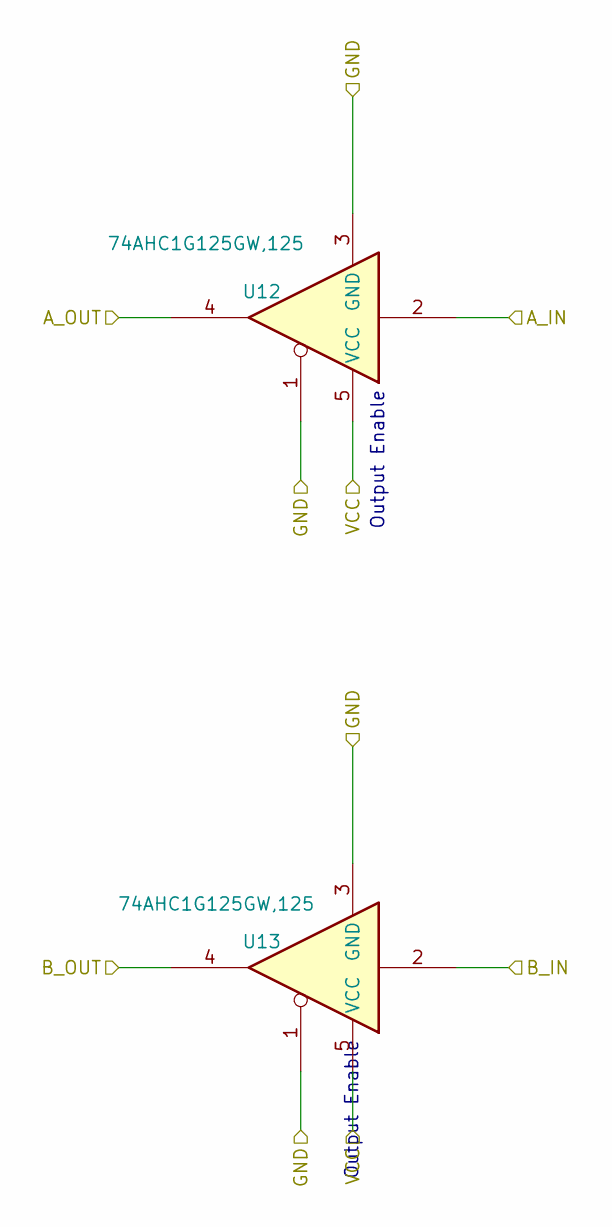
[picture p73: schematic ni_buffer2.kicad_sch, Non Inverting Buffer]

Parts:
U12, U13: 74AHC1G125GW,125; SOT-353_SC-70-5_Slim; MPN 74AHC1G125GW,125; JLC C85397

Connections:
/SCLK2: U13.4; also elsewhere on the board
/SDIN2: U12.4; also elsewhere on the board
GND: U12.1, U12.3 (GND), U13.1, U13.3 (GND); also elsewhere on the board
SCLK_RAW: U13.2; also elsewhere on the board
SDIN_RAW: U12.2; also elsewhere on the board
VDD: U12.5 (VCC), U13.5 (VCC); also elsewhere on the board

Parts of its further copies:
U14, U15, U16, U17, U18, U19, U20, U21, U22, U23, U24, U25: 74AHC1G125GW,125; SOT-353_SC-70-5_Slim; MPN 74AHC1G125GW,125; JLC C85397

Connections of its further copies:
/SCLK1: U15.4; also elsewhere on the board
/SCLK3: U17.4; also elsewhere on the board
/SCLK4: U19.4; also elsewhere on the board
/SCLK5: U21.4; also elsewhere on the board
/SCLK6: U23.4; also elsewhere on the board
/SCLK7: U25.4; also elsewhere on the board
/SDIN1: U14.4; also elsewhere on the board
/SDIN3: U16.4; also elsewhere on the board
/SDIN4: U18.4; also elsewhere on the board
/SDIN5: U20.4; also elsewhere on the board
/SDIN6: U22.4; also elsewhere on the board
/SDIN7: U24.4; also elsewhere on the board
GND: U14.1, U14.3 (GND), U15.1, U15.3 (GND), U16.1, U16.3 (GND), U17.1, U17.3 (GND), U18.1, U18.3 (GND), U19.1, U19.3 (GND), U20.1, U20.3 (GND), U21.1, U21.3 (GND), U22.1, U22.3 (GND), U23.1, U23.3 (GND), U24.1, U24.3 (GND), U25.1, U25.3 (GND); also elsewhere on the board
SCLK_RAW: U15.2, U17.2, U19.2, U21.2, U23.2, U25.2; also elsewhere on the board
SDIN_RAW: U14.2, U16.2, U18.2, U20.2, U22.2, U24.2; also elsewhere on the board
VDD: U14.5 (VCC), U15.5 (VCC), U16.5 (VCC), U17.5 (VCC), U18.5 (VCC), U19.5 (VCC), U20.5 (VCC), U21.5 (VCC), U22.5 (VCC), U23.5 (VCC), U24.5 (VCC), U25.5 (VCC); also elsewhere on the board

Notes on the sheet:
Output Enable

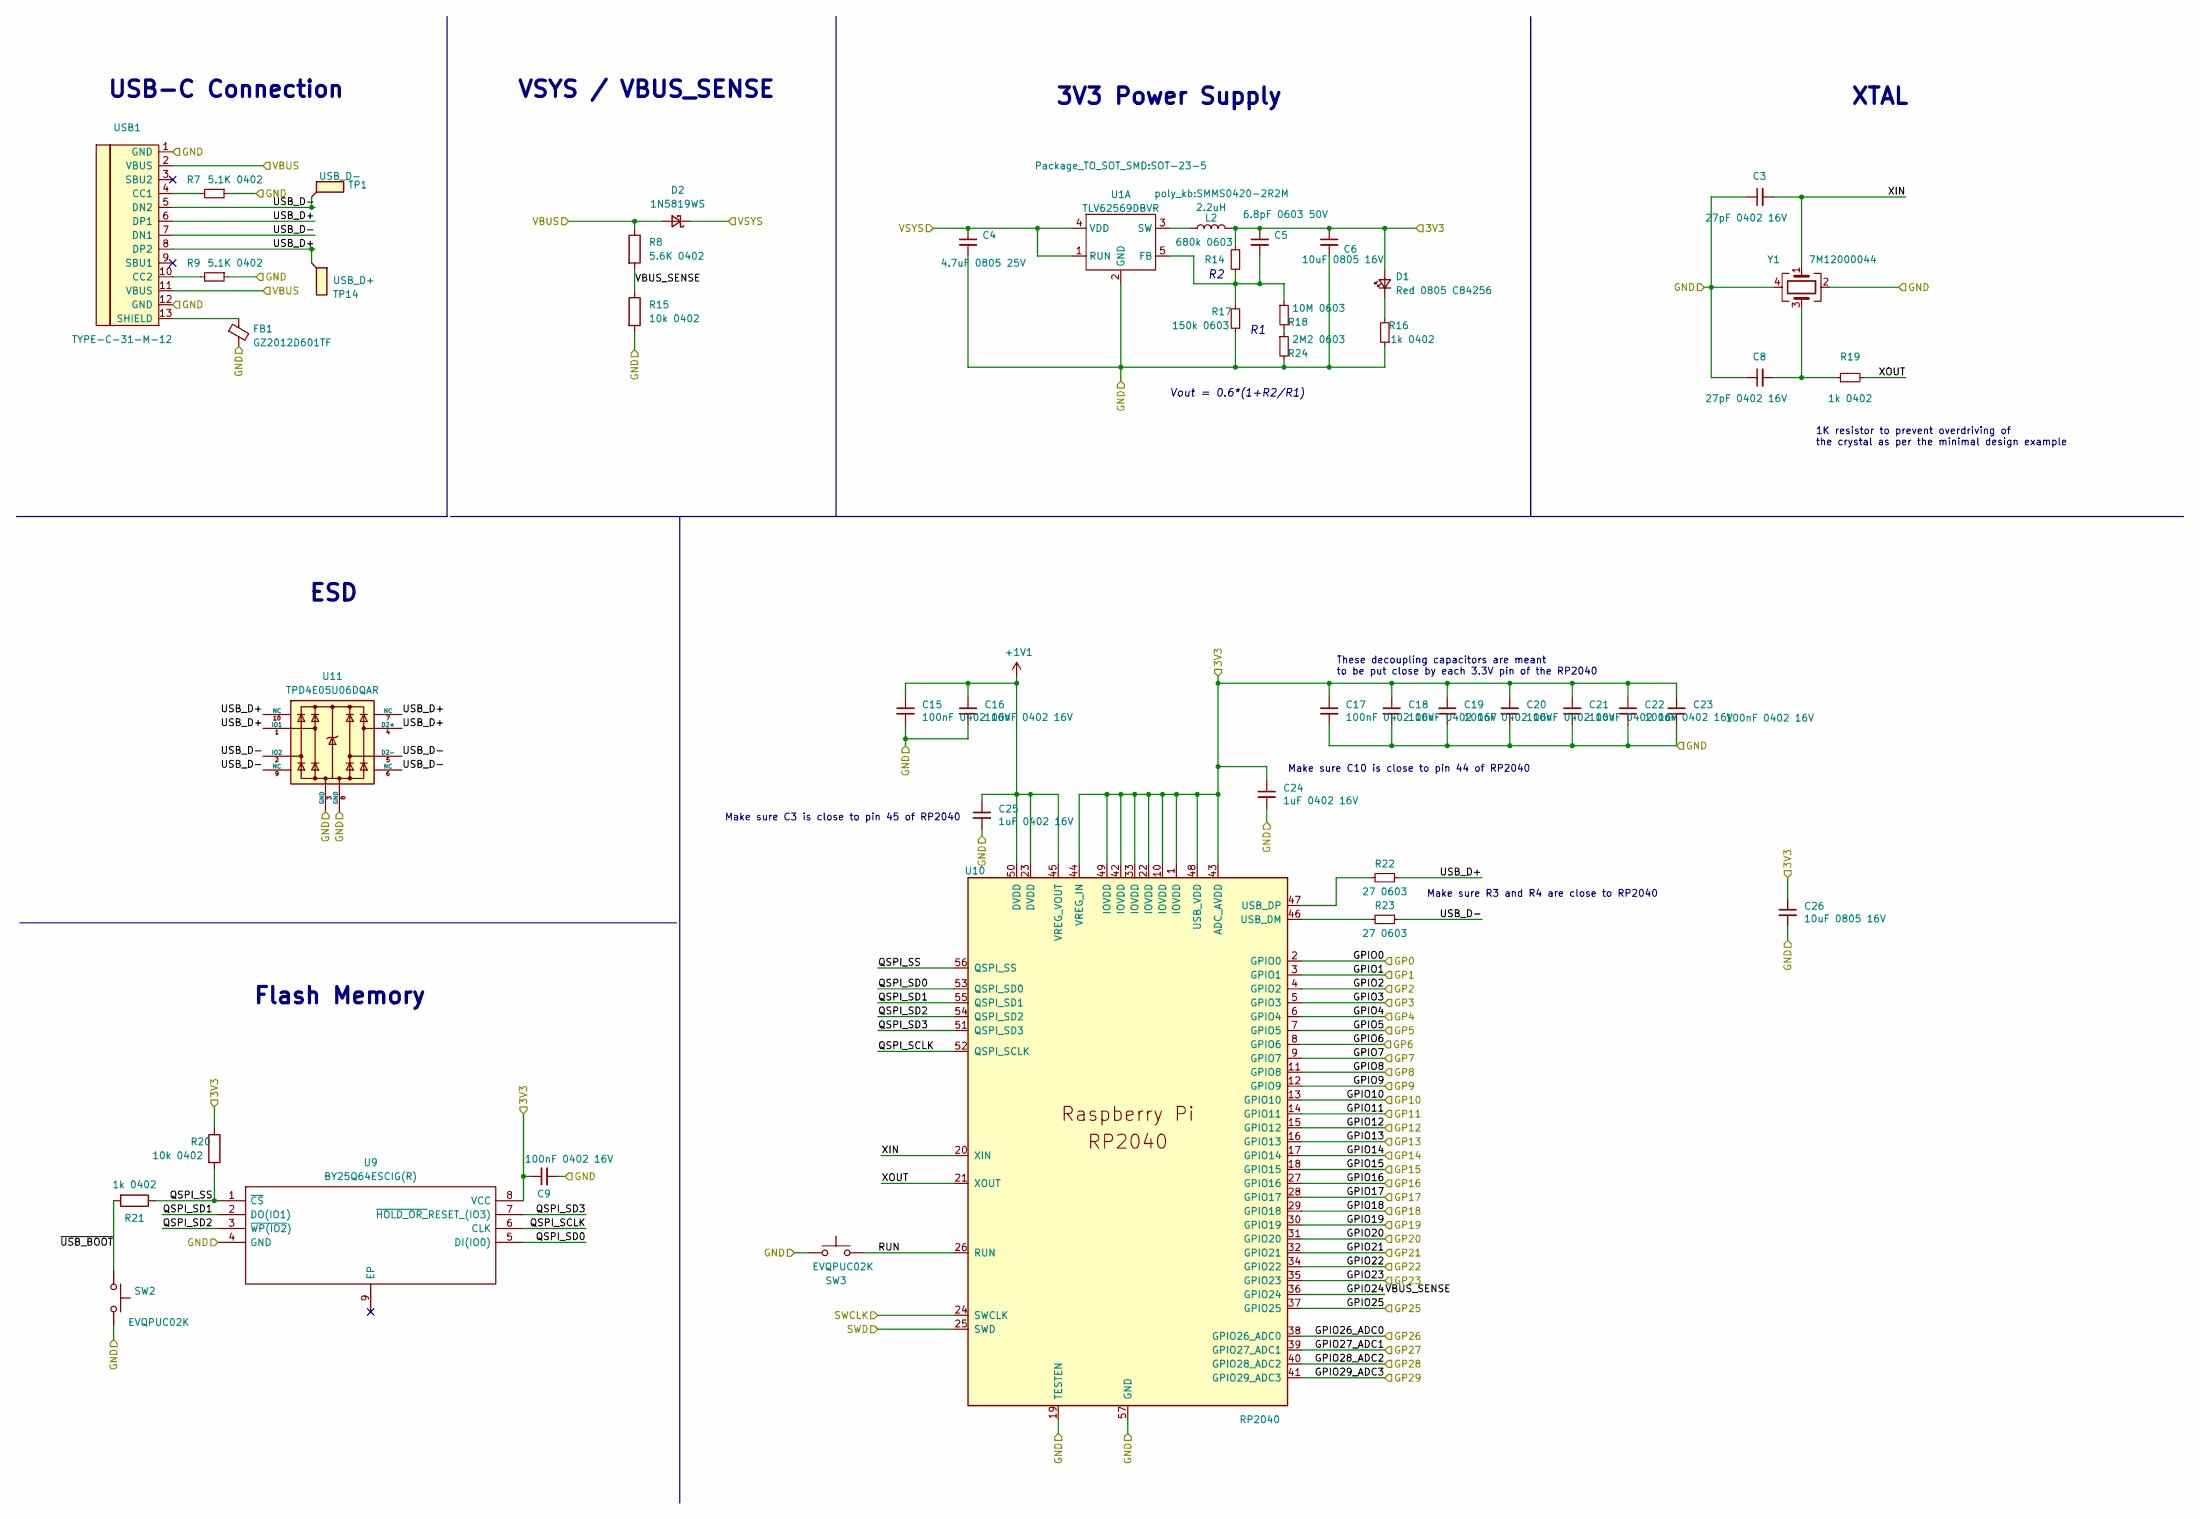
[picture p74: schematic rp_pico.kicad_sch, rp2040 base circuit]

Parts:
C3, C8: 27pF 0402 16V; C_0402_1005Metric; MPN C86287; JLC C86287
C4: 4.7uF 0805 25V; C_0805_2012Metric; MPN C1779; JLC C1779
C5: 6.8pF 0603 50V; C_0603_1608Metric; MPN CL10C6R8CB8NNNC; JLC C318672
C6, C26: 10uF 0805 16V; C_0805_2012Metric; MPN C15850; JLC C15850
C9, C15, C16, C17, C18, C19, C20, C21, C22, C23: 100nF 0402 16V; C_0402_1005Metric; MPN C1525; JLC C1525
C24, C25: 1uF 0402 16V; C_0402_1005Metric; MPN C52923; JLC C52923
D1: Red 0805 C84256; LED_0805_2012Metric; MPN C84256; JLC C84256
D2: 1N5819WS; D_SOD-323Ext; MPN C191023; JLC C191023
FB1: GZ2012D601TF; L_0805_2012Metric; MPN C1017; JLC C1017
L2: 2.2uH; SMMS0420-2R2M; MPN C133191; JLC C133191
R7, R9: 5.1K 0402; R_0402_1005Metric; MPN C144745; JLC C144745
R8: 5.6K 0402; R_0402_1005Metric; MPN C163457; JLC C163457
R14: 680k 0603; R_0603_1608Metric; MPN C137690; JLC C137690
R15, R20: 10k 0402; R_0402_1005Metric; MPN C60490; JLC C60490
R16, R19, R21: 1k 0402; R_0402_1005Metric; MPN CRCW04021K00FKED; JLC C71623
R17: 150k 0603; R_0603_1608Metric; MPN C114660; JLC C114660
R18: 10M 0603; R_0603_1608Metric; MPN C227547; JLC C227547
R22, R23: 27 0603; R_0603_1608Metric; MPN C137753; JLC C137753
R24: 2M2 0603; R_0603_1608Metric; MPN C137747; JLC C137747
SW2, SW3: EVQPUC02K; Panasonic_EVQPUL_EVQPUC; MPN C79174; JLC C79174
TP1: USB_D-; TestPoint_Pad_D1.5mm; MPN DNP; JLC DNP
TP14: USB_D+; TestPoint_Pad_D1.5mm; MPN DNP; JLC DNP
U1: TLV62569DBVR; SOT-23-5; MPN C141836; JLC C141836
U9: BY25Q64ESCIG(R); BY25Q64ES-LGA8-2x3; MPN BY25Q64ESCIG(R); JLC C50176394
U10: RP2040; RP2040-QFN-56; MPN C2040; JLC C2040
U11: TPD4E05U06DQAR; USON-10; MPN C2836386; JLC C2836386
USB1: TYPE-C-31-M-12; HRO-TYPE-C-31-M-12-Assembly; MPN C165948; JLC C165948
Y1: 7M12000044; Crystal_SMD_3225-4Pin_3.2x2.5mm; MPN C93114; JLC C93114

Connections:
+1V1: C15.1, C16.1, C25.1, U10.23 (DVDD), U10.45 (VREG_VOUT), U10.50 (DVDD)
/RpPico/GPIO6: U10.8 (GPIO6); also elsewhere on the board
/RpPico/GPIO7: U10.9 (GPIO7); also elsewhere on the board
/RpPico/GPIO24: R8.2, R15.1, U10.36 (GPIO24)
/RpPico/QSPI_SCLK: U9.6 (CLK), U10.52 (QSPI_SCLK)
/RpPico/QSPI_SD0: U9.5 (DI(IO0)), U10.53 (QSPI_SD0)
/RpPico/QSPI_SD1: U9.2 (DO(IO1)), U10.55 (QSPI_SD1)
/RpPico/QSPI_SD2: U9.3 (~WP(IO2)), U10.54 (QSPI_SD2)
/RpPico/QSPI_SD3: U9.7 (~HOLD_OR_RESET_(IO3)), U10.51 (QSPI_SD3)
/RpPico/QSPI_SS: R20.2, R21.1, U9.1 (~CS), U10.56 (QSPI_SS)
/RpPico/RUN: SW3.2, U10.26 (RUN)
/RpPico/SWCLK: U10.24 (SWCLK); also elsewhere on the board
/RpPico/SWD: U10.25 (SWD); also elsewhere on the board
/RpPico/USB_D+: R22.1, TP14.1, U11.1 (IO1), U11.4 (D2+), U11.7 (NC), U11.10 (NC), USB1.6 (DP1), USB1.8 (DP2)
/RpPico/USB_D-: R23.1, TP1.1, U11.2 (IO2), U11.5 (D2-), U11.6 (NC), U11.9 (NC), USB1.5 (DN2), USB1.7 (DN1)
/RpPico/XIN: C3.2, U10.20 (XIN), Y1.1
/RpPico/XOUT: R19.2, U10.21 (XOUT)
/RpPico/~USB_BOOT: R21.2, SW2.2
Col1: U10.13 (GPIO10); also elsewhere on the board
Col2: U10.14 (GPIO11); also elsewhere on the board
Col3: U10.15 (GPIO12); also elsewhere on the board
Col4: U10.16 (GPIO13); also elsewhere on the board
Col5: U10.17 (GPIO14); also elsewhere on the board
Col6: U10.18 (GPIO15); also elsewhere on the board
Col7: U10.27 (GPIO16); also elsewhere on the board
Col8: U10.5 (GPIO3); also elsewhere on the board
D-C: U10.11 (GPIO8); also elsewhere on the board
ENC_A: U10.37 (GPIO25); also elsewhere on the board
ENC_B: U10.41 (GPIO29_ADC3); also elsewhere on the board
GND: C3.1, C4.2, C6.2, C8.1, C9.2, C15.2, C16.2, C17.2, C18.2, C19.2, C20.2, C21.2, C22.2, C23.2, C24.2, C25.2, C26.2, FB1.2, R7.1, R9.1, R15.2, R16.1, R17.1, R24.2, SW2.1, SW3.1, U1.2 (GND), U9.4 (GND), U10.19 (TESTEN), U10.57 (GND), U11.3 (GND), U11.8 (GND), USB1.1 (GND), USB1.12 (GND), Y1.2, Y1.4; also elsewhere on the board
I2C_SCL: U10.3 (GPIO1); also elsewhere on the board
I2C_SDA: U10.2 (GPIO0); also elsewhere on the board
LED_ARR_START: U10.4 (GPIO2); also elsewhere on the board
unnamed: C8.2, R19.1, Y1.3
unnamed: D1.1 (K), R16.2
unnamed: R18.2, R24.1
unnamed: C5.2, R14.1, R17.2, R18.1, U1.5 (FB)
unnamed: L2.1, U1.3 (SW)
unnamed: R23.2, U10.46 (USB_DM)
unnamed: R22.2, U10.47 (USB_DP)
unnamed: R7.2, USB1.4 (CC1)
unnamed: R9.2, USB1.10 (CC2)
unnamed: FB1.1, USB1.13 (SHIELD)
RESET: U10.12 (GPIO9); also elsewhere on the board
Row1: U10.29 (GPIO18); also elsewhere on the board
Row2: U10.30 (GPIO19); also elsewhere on the board
Row3: U10.31 (GPIO20); also elsewhere on the board
Row4: U10.32 (GPIO21); also elsewhere on the board
Row5: U10.34 (GPIO22); also elsewhere on the board
SERIAL_COM1: U10.6 (GPIO4); also elsewhere on the board
SERIAL_COM2: U10.7 (GPIO5); also elsewhere on the board
SPI0_CS_NC: U10.28 (GPIO17)
SR_CLOCK: U10.39 (GPIO27_ADC1); also elsewhere on the board
SR_DATA: U10.38 (GPIO26_ADC0); also elsewhere on the board
SR_LATCH: U10.40 (GPIO28_ADC2); also elsewhere on the board
TB_INT: U10.35 (GPIO23); also elsewhere on the board
VBUS: D2.2 (A), R8.1, USB1.2 (VBUS), USB1.11 (VBUS)
VDD: C5.1, C6.1, C9.1, C17.1, C18.1, C19.1, C20.1, C21.1, C22.1, C23.1, C24.1, C26.1, D1.2 (A), L2.2, R14.2, R20.1, U9.8 (VCC), U10.1 (IOVDD), U10.10 (IOVDD), U10.22 (IOVDD), U10.33 (IOVDD), U10.42 (IOVDD), U10.43 (ADC_AVDD), U10.44 (VREG_IN), U10.48 (USB_VDD), U10.49 (IOVDD); also elsewhere on the board
VSYS: C4.1, D2.1 (K), U1.1 (RUN), U1.4 (VDD); also elsewhere on the board

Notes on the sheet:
VSYS / VBUS_SENSE
Make sure R3 and R4 are close to RP2040
These decoupling capacitors are meant to be put close by each 3.3V pin of the RP2040
3V3 Power Supply
ESD
1K resistor to prevent overdriving of the crystal as per the minimal design example
Flash Memory
XTAL
Make sure C10 is close to pin 44 of RP2040
Make sure C3 is close to pin 45 of RP2040
Vout = 0.6*(1+R2/R1)
USB-C Connection

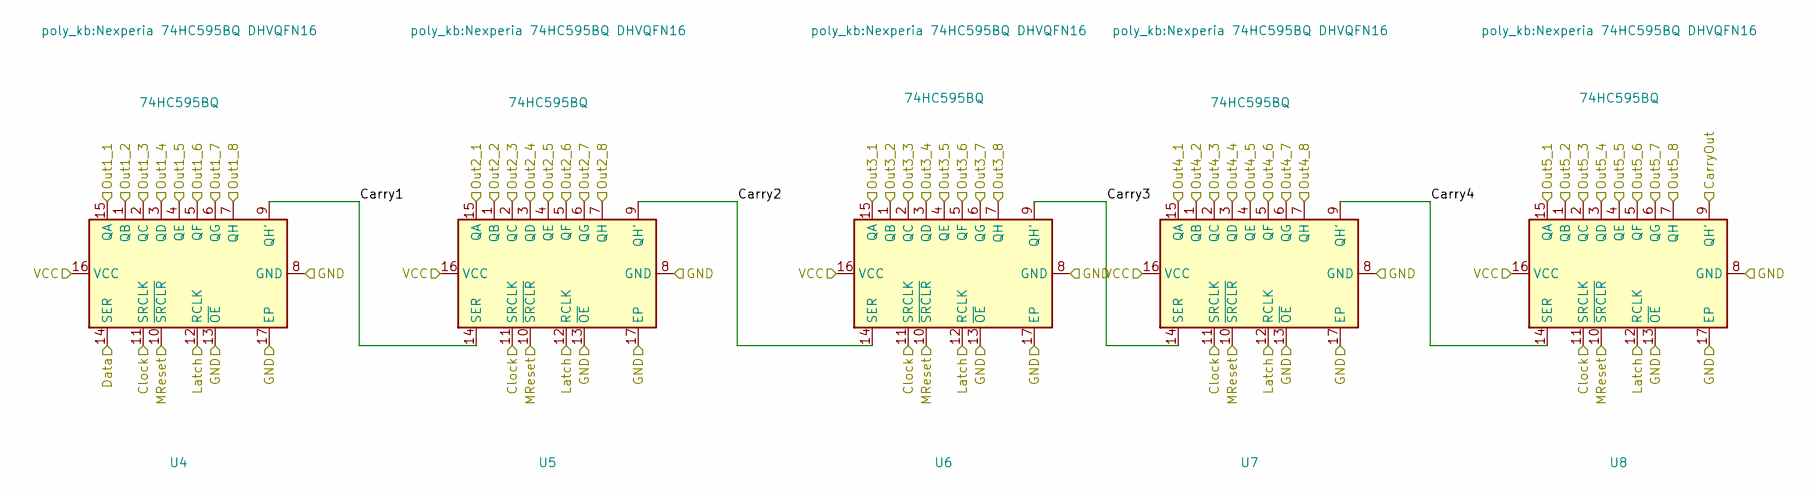
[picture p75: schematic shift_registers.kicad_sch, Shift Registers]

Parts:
U4, U5, U6, U7, U8: 74HC595BQ; Nexperia 74HC595BQ DHVQFN16; MPN 74HC595BQ,115; JLC C730243

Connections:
/K_1/CS: U4.1 (QB); also elsewhere on the board
/K_2/CS: U4.2 (QC); also elsewhere on the board
/K_3/CS: U4.3 (QD); also elsewhere on the board
/K_4/CS: U4.4 (QE); also elsewhere on the board
/K_5/CS: U4.5 (QF); also elsewhere on the board
/K_A/CS: U6.1 (QB); also elsewhere on the board
/K_B1/CS: U8.15 (QA); also elsewhere on the board
/K_B2/CS: U8.1 (QB); also elsewhere on the board
/K_B3/CS: U8.2 (QC); also elsewhere on the board
/K_B4/CS: U8.3 (QD); also elsewhere on the board
/K_B5/CS: U8.4 (QE); also elsewhere on the board
/K_B6/CS: U8.5 (QF); also elsewhere on the board
/K_B7/CS: U8.6 (QG); also elsewhere on the board
/K_B8/CS: U8.7 (QH); also elsewhere on the board
/K_B/CS: U7.5 (QF); also elsewhere on the board
/K_C/CS: U7.3 (QD); also elsewhere on the board
/K_D/CS: U6.3 (QD); also elsewhere on the board
/K_E/CS: U5.3 (QD); also elsewhere on the board
/K_F/CS: U6.4 (QE); also elsewhere on the board
/K_G/CS: U6.5 (QF); also elsewhere on the board
/K_L1/CS: U4.15 (QA); also elsewhere on the board
/K_L2/CS: U5.15 (QA); also elsewhere on the board
/K_L3/CS: U6.15 (QA); also elsewhere on the board
/K_L4/CS: U7.15 (QA); also elsewhere on the board
/K_L6/CS: U4.6 (QG); also elsewhere on the board
/K_L7/CS: U5.6 (QG); also elsewhere on the board
/K_L8/CS: U6.6 (QG); also elsewhere on the board
/K_L9/CS: U7.6 (QG); also elsewhere on the board
/K_Q/CS: U5.1 (QB); also elsewhere on the board
/K_R/CS: U5.4 (QE); also elsewhere on the board
/K_S/CS: U6.2 (QC); also elsewhere on the board
/K_T/CS: U5.5 (QF); also elsewhere on the board
/K_V/CS: U7.4 (QE); also elsewhere on the board
/K_W/CS: U5.2 (QC); also elsewhere on the board
/K_X/CS: U7.2 (QC); also elsewhere on the board
/K_Z/CS: U7.1 (QB); also elsewhere on the board
/ShiftRegisters/Carry1: U4.9 (QH'), U5.14 (SER)
/ShiftRegisters/Carry2: U5.9 (QH'), U6.14 (SER)
/ShiftRegisters/Carry3: U6.9 (QH'), U7.14 (SER)
/ShiftRegisters/Carry4: U7.9 (QH'), U8.14 (SER)
/ShiftRegisters/CarryOut: U8.9 (QH')
/ShiftRegisters/Out1_8: U4.7 (QH)
/ShiftRegisters/Out2_8: U5.7 (QH)
/ShiftRegisters/Out3_8: U6.7 (QH)
/ShiftRegisters/Out4_8: U7.7 (QH)
GND: U4.8 (GND), U4.13 (~OE), U4.17 (EP), U5.8 (GND), U5.13 (~OE), U5.17 (EP), U6.8 (GND), U6.13 (~OE), U6.17 (EP), U7.8 (GND), U7.13 (~OE), U7.17 (EP), U8.8 (GND), U8.13 (~OE), U8.17 (EP); also elsewhere on the board
RESET: U4.10 (~SRCLR), U5.10 (~SRCLR), U6.10 (~SRCLR), U7.10 (~SRCLR), U8.10 (~SRCLR); also elsewhere on the board
SR_CLOCK: U4.11 (SRCLK), U5.11 (SRCLK), U6.11 (SRCLK), U7.11 (SRCLK), U8.11 (SRCLK); also elsewhere on the board
SR_DATA: U4.14 (SER); also elsewhere on the board
SR_LATCH: U4.12 (RCLK), U5.12 (RCLK), U6.12 (RCLK), U7.12 (RCLK), U8.12 (RCLK); also elsewhere on the board
VDD: U4.16 (VCC), U5.16 (VCC), U6.16 (VCC), U7.16 (VCC), U8.16 (VCC); also elsewhere on the board

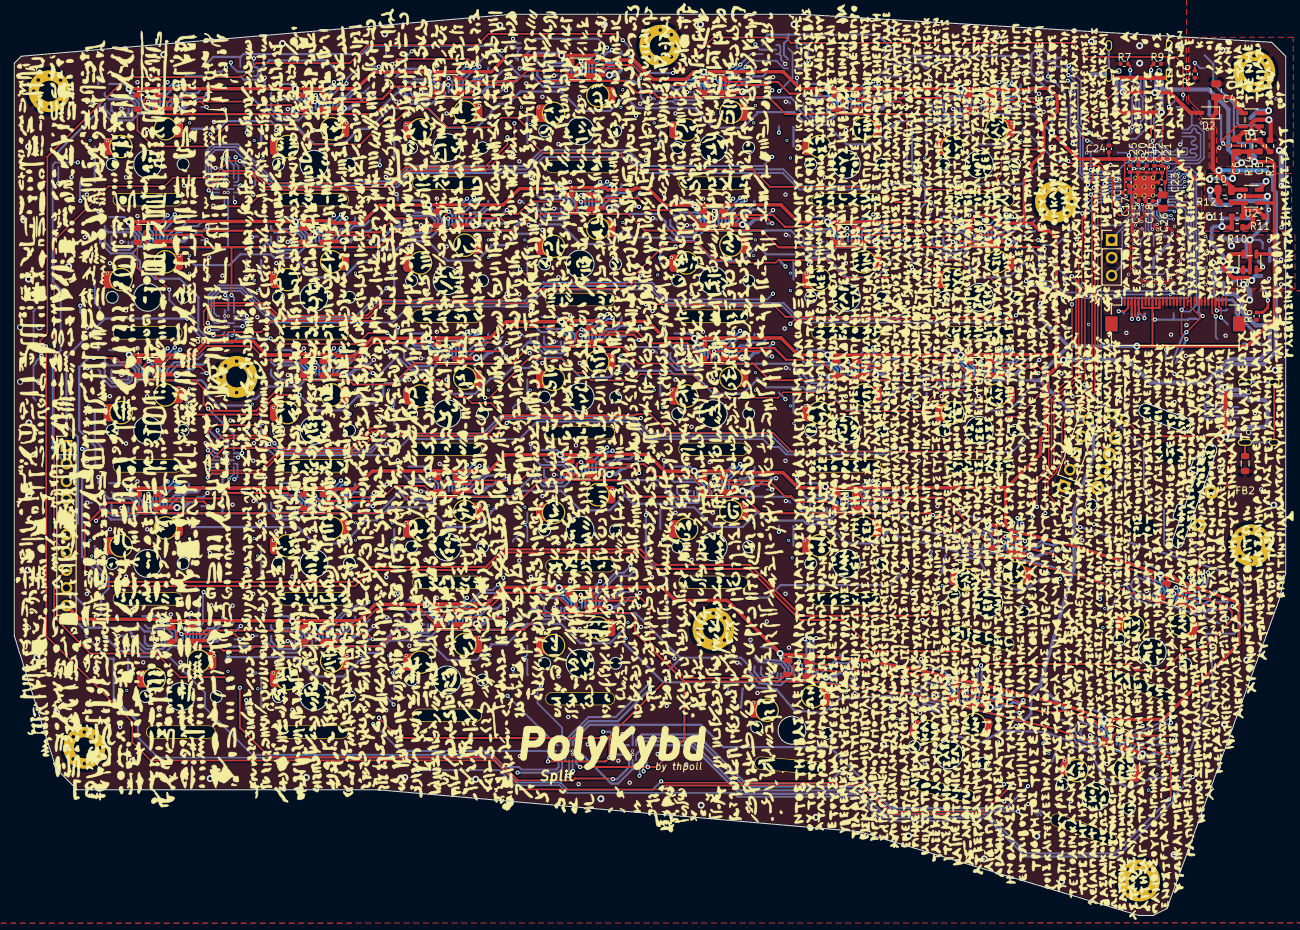
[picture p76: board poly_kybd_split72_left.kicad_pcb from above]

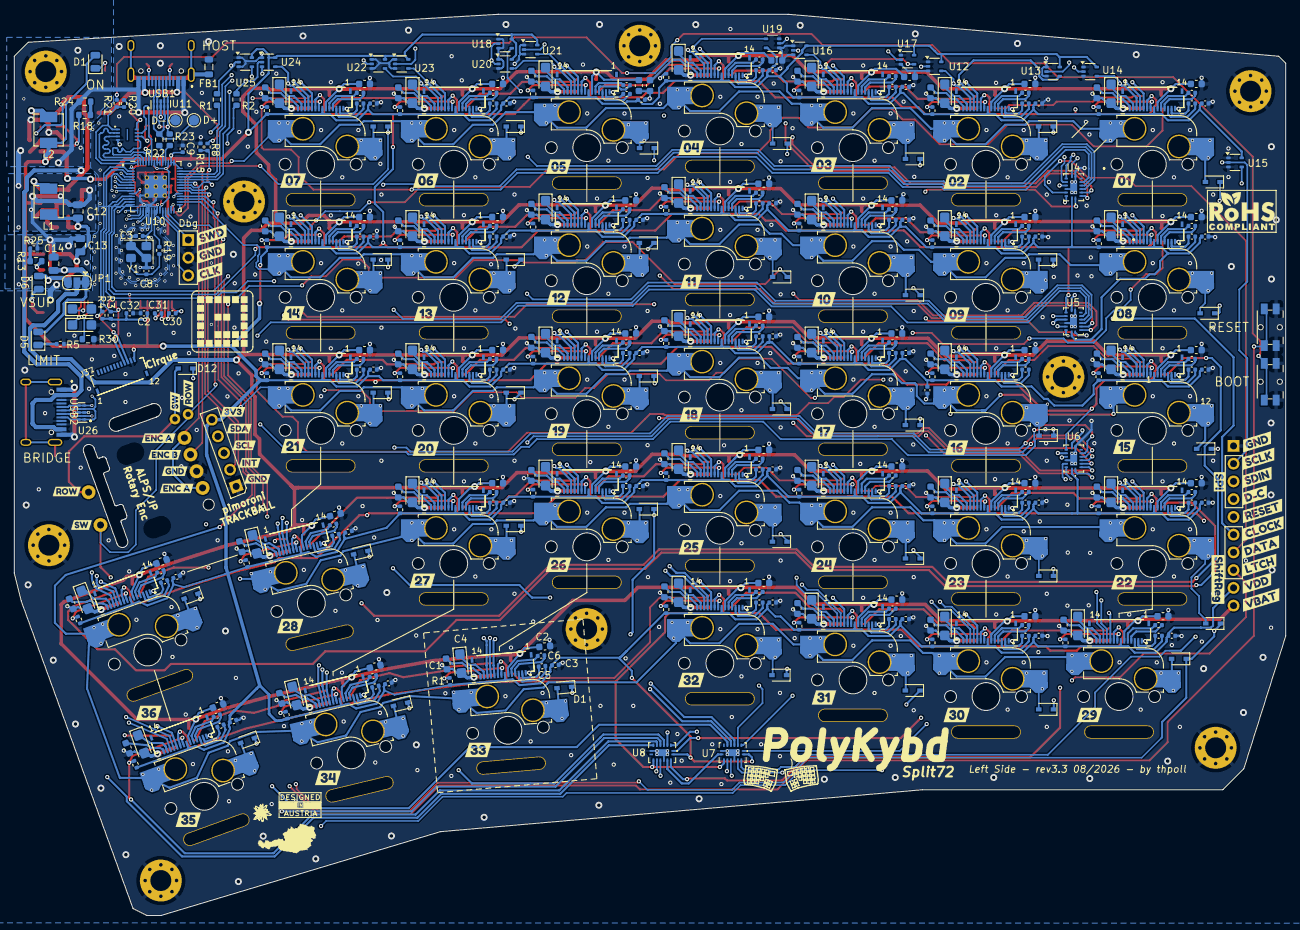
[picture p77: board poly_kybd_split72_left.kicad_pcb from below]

Board: 4 copper layers, 182.0 x 129.0 mm, 573 parts (457 on the bottom side), 420 nets.

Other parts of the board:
kibuzzard-63EB51FD: G***; kibuzzard-63EB51FD
kibuzzard-63EB521C: G***; kibuzzard-63EB521C
kibuzzard-639C2A4A: G***; kibuzzard-639C2A4A
kibuzzard-639C2A44: G***; kibuzzard-639C2A44
kibuzzard-639C2A60: G***; kibuzzard-639C2A60
kibuzzard-639C2A93: G***; kibuzzard-639C2A93
kibuzzard-639C2D8F: G***; kibuzzard-639C2D8F
kibuzzard-639C2D09, kibuzzard-639C2D09#2: G***; kibuzzard-639C2D09
kibuzzard-639C2D25: G***; kibuzzard-639C2D25
kibuzzard-639C2D80: G***; kibuzzard-639C2D80
kibuzzard-639C2DA1: G***; kibuzzard-639C2DA1
kibuzzard-639C2DB9, kibuzzard-639C2DB9#2: G***; kibuzzard-639C2DB9
kibuzzard-639C2DCB: G***; kibuzzard-639C2DCB
kibuzzard-639C2E0D, kibuzzard-639C2E0D#2: G***; kibuzzard-639C2E0D
kibuzzard-639C2E3A, kibuzzard-639C2E3A#2: G***; kibuzzard-639C2E3A
kibuzzard-639C28BB, kibuzzard-639C28BB#2: G***; kibuzzard-639C28BB
kibuzzard-639C28CF: G***; kibuzzard-639C28CF
kibuzzard-639C29A7: G***; kibuzzard-639C29A7
kibuzzard-639C29B6: G***; kibuzzard-639C29B6
kibuzzard-639C29C6: G***; kibuzzard-639C29C6
kibuzzard-639C34AE: G***; kibuzzard-639C34AE
kibuzzard-639C34D4: G***; kibuzzard-639C34D4
kibuzzard-639C34FD: G***; kibuzzard-639C34FD
kibuzzard-639C35A2: G***; kibuzzard-639C35A2
kibuzzard-639C35AF: G***; kibuzzard-639C35AF
kibuzzard-639C35B8: G***; kibuzzard-639C35B8
kibuzzard-639C35C3: G***; kibuzzard-639C35C3
kibuzzard-639C35CB: G***; kibuzzard-639C35CB
kibuzzard-639C35DA: G***; kibuzzard-639C35DA
kibuzzard-639C35E7: G***; kibuzzard-639C35E7
kibuzzard-639C35FE: G***; kibuzzard-639C35FE
kibuzzard-639C36A9: G***; kibuzzard-639C36A9
kibuzzard-639C36B3: G***; kibuzzard-639C36B3
kibuzzard-639C39A5: G***; kibuzzard-639C39A5
kibuzzard-639C294B: G***; kibuzzard-639C294B
kibuzzard-639C352E: G***; kibuzzard-639C352E
kibuzzard-639C353A: G***; kibuzzard-639C353A
kibuzzard-639C355D: G***; kibuzzard-639C355D
kibuzzard-639C357F: G***; kibuzzard-639C357F
kibuzzard-639C358A: G***; kibuzzard-639C358A
kibuzzard-639C360B: G***; kibuzzard-639C360B
kibuzzard-639C361C: G***; kibuzzard-639C361C
kibuzzard-639C362D: G***; kibuzzard-639C362D
kibuzzard-639C368F: G***; kibuzzard-639C368F
kibuzzard-639C369E: G***; kibuzzard-639C369E
kibuzzard-639C2997: G***; kibuzzard-639C2997
kibuzzard-639C3508: G***; kibuzzard-639C3508
kibuzzard-639C3514: G***; kibuzzard-639C3514
kibuzzard-639C3522: G***; kibuzzard-639C3522
kibuzzard-639C3548: G***; kibuzzard-639C3548
kibuzzard-639C3550: G***; kibuzzard-639C3550
kibuzzard-639C3575: G***; kibuzzard-639C3575
kibuzzard-639C3594: G***; kibuzzard-639C3594
kibuzzard-639C3625: G***; kibuzzard-639C3625
kibuzzard-639C3638: G***; kibuzzard-639C3638
kibuzzard-639C3642: G***; kibuzzard-639C3642
kibuzzard-639C3653: G***; kibuzzard-639C3653
kibuzzard-639C3683: G***; kibuzzard-639C3683
kibuzzard-639C3695: G***; kibuzzard-639C3695

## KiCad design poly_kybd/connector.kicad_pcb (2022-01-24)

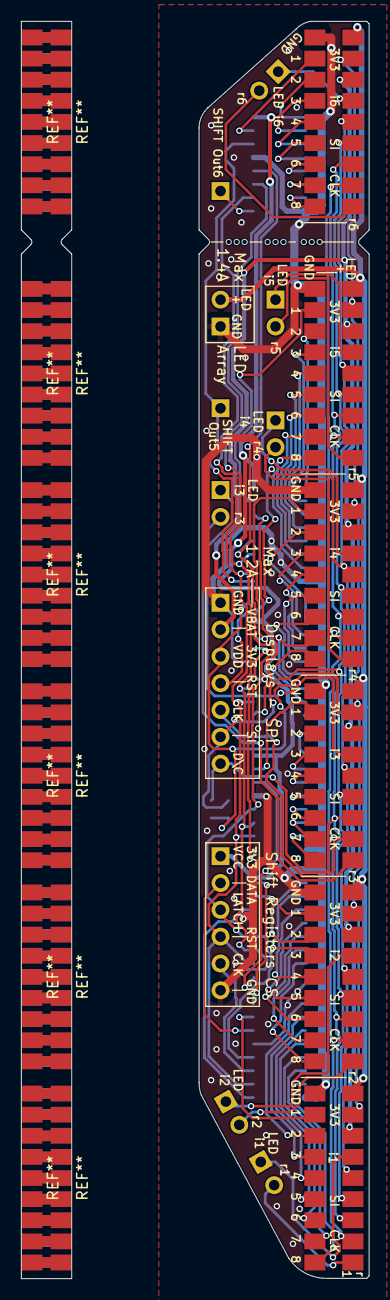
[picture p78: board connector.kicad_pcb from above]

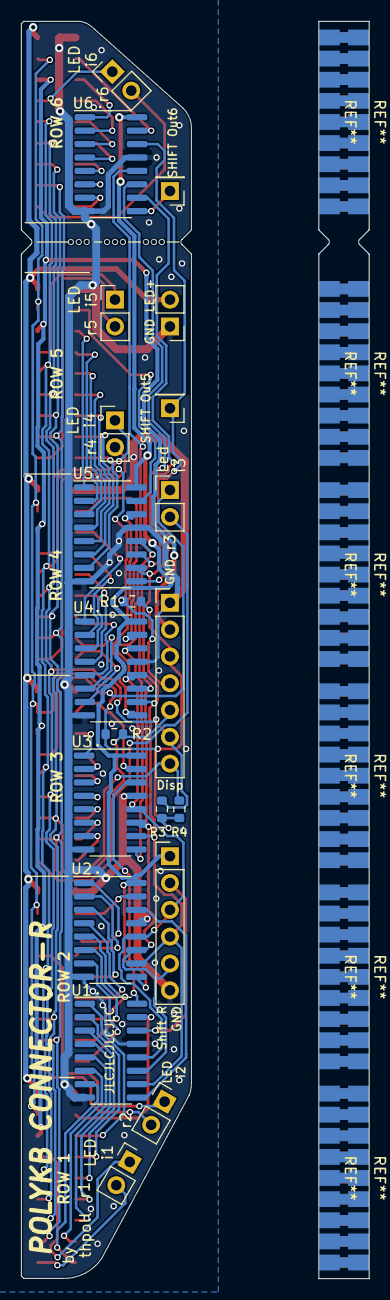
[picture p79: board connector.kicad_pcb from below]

Board: 2 copper layers, 32.9 x 119.1 mm, 36 parts (21 on the bottom side), 79 nets.

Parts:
J1, J2, J3, J4, J5, J6, J7, J8, J9, J10, J11, J12: Conn_01x09; AtomConnect2
J13: Conn_01x07; PinHeader_1x07_P2.54mm_Vertical
J14: Conn_01x06; PinHeader_1x06_P2.54mm_Vertical
J15, J17: Conn_01x01; PinHeader_1x01_P2.54mm_Vertical
J16, J21, J22, J23, J24, J25, J26: Conn_01x02; PinHeader_1x02_P2.54mm_Vertical
R1, R2, R3, R4: 1M; R_0603_1608Metric
U1, U2, U3, U4, U5, U6: 74HCT595; SOIC-16_3.9x9.9mm_P1.27mm
mouse-bite-2mm-slot, mouse-bite-2mm-slot#2, mouse-bite-2mm-slot#3: VAL**; mouse-bite-3x

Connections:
1: J1.2, U1.15
2: J1.3, U1.1
3: J1.4, U1.2
4: J1.5, U1.3
5: J1.6, U1.4
6: J1.7, U1.5
7: J1.8, U1.6
8: J1.9, U1.7
9: J3.2, U2.15
10: J3.3, U2.1
11: J3.4, U2.2
12: J3.5, U2.3
13: J3.6, U2.4
14: J3.7, U2.5
15: J3.8, U2.6
16: J3.9, U2.7
17: J5.2, U3.15
18: J5.3, U3.1
19: J5.4, U3.2
20: J5.5, U3.3
21: J5.6, U3.4
22: J5.7, U3.5
23: J5.8, U3.6
24: J5.9, U3.7
25: J7.2, U4.15
26: J7.3, U4.1
27: J7.4, U4.2
28: J7.5, U4.3
29: J7.6, U4.4
30: J7.7, U4.5
31: J7.8, U4.6
32: J7.9, U4.7
33: J9.2, U5.15
34: J9.3, U5.1
35: J9.4, U5.2
36: J9.5, U5.3
37: J9.6, U5.4
38: J9.7, U5.5
39: J9.8, U5.6
40: J9.9, U5.7
41: J11.2, U6.15
42: J11.3, U6.1
43: J11.4, U6.2
44: J11.5, U6.3
45: J11.6, U6.4
46: J11.7, U6.5
47: J11.8, U6.6
48: J11.9, U6.7
+3V3: J14.1, U1.16, U2.16, U3.16, U4.16, U5.16, U6.16
CLK: J2.8, J4.8, J6.8, J8.8, J10.8, J12.8, J13.5, R2.2
D\C: J2.7, J4.7, J6.7, J8.7, J10.7, J12.7, J13.7, R4.2
GND: J1.1, J3.1, J5.1, J7.1, J9.1, J11.1, J13.1, J14.6, J16.1, U1.8, U1.13, U2.8, U2.13, U3.8, U3.13, U4.8, U4.13, U5.8, U5.13, U6.8, U6.13
LedIn1: J2.4, J21.1
LedIn2: J4.4, J22.1
LedIn3: J6.4, J23.1
LedIn4: J8.4, J24.1
LedIn5: J10.4, J25.1
LedIn6: J12.4, J26.1
unnamed: U1.9, U2.14
unnamed: U2.9, U3.14
unnamed: U3.9, U4.14
unnamed: U4.9, U5.14
RST: J2.5, J4.5, J6.5, J8.5, J10.5, J12.5, J13.4, R1.2
SHIFTR_AOUT: J17.1, U5.9, U6.14
SHIFTR_CLK: J14.5, U1.11, U2.11, U3.11, U4.11, U5.11, U6.11
SHIFTR_DATA: J14.2, U1.14
SHIFTR_LATCH_CLK: J14.3, U1.12, U2.12, U3.12, U4.12, U5.12, U6.12
SHIFTR_OUT: J15.1, U6.9
SHIFTR_RST: J14.4, U1.10, U2.10, U3.10, U4.10, U5.10, U6.10
SI: J2.6, J4.6, J6.6, J8.6, J10.6, J12.6, J13.6, R3.2
VBAT: J2.3, J4.3, J6.3, J8.3, J10.3, J12.3, J13.2
VDD_3V3: J2.2, J4.2, J6.2, J8.2, J10.2, J12.2, J13.3, R1.1, R2.1, R3.1, R4.1
VLED: J2.1, J4.1, J6.1, J8.1, J10.1, J12.1, J16.2
r1: J2.9, J21.2
r2: J4.9, J22.2
r3: J6.9, J23.2
r4: J8.9, J24.2
r5: J10.9, J25.2
r6: J12.9, J26.2

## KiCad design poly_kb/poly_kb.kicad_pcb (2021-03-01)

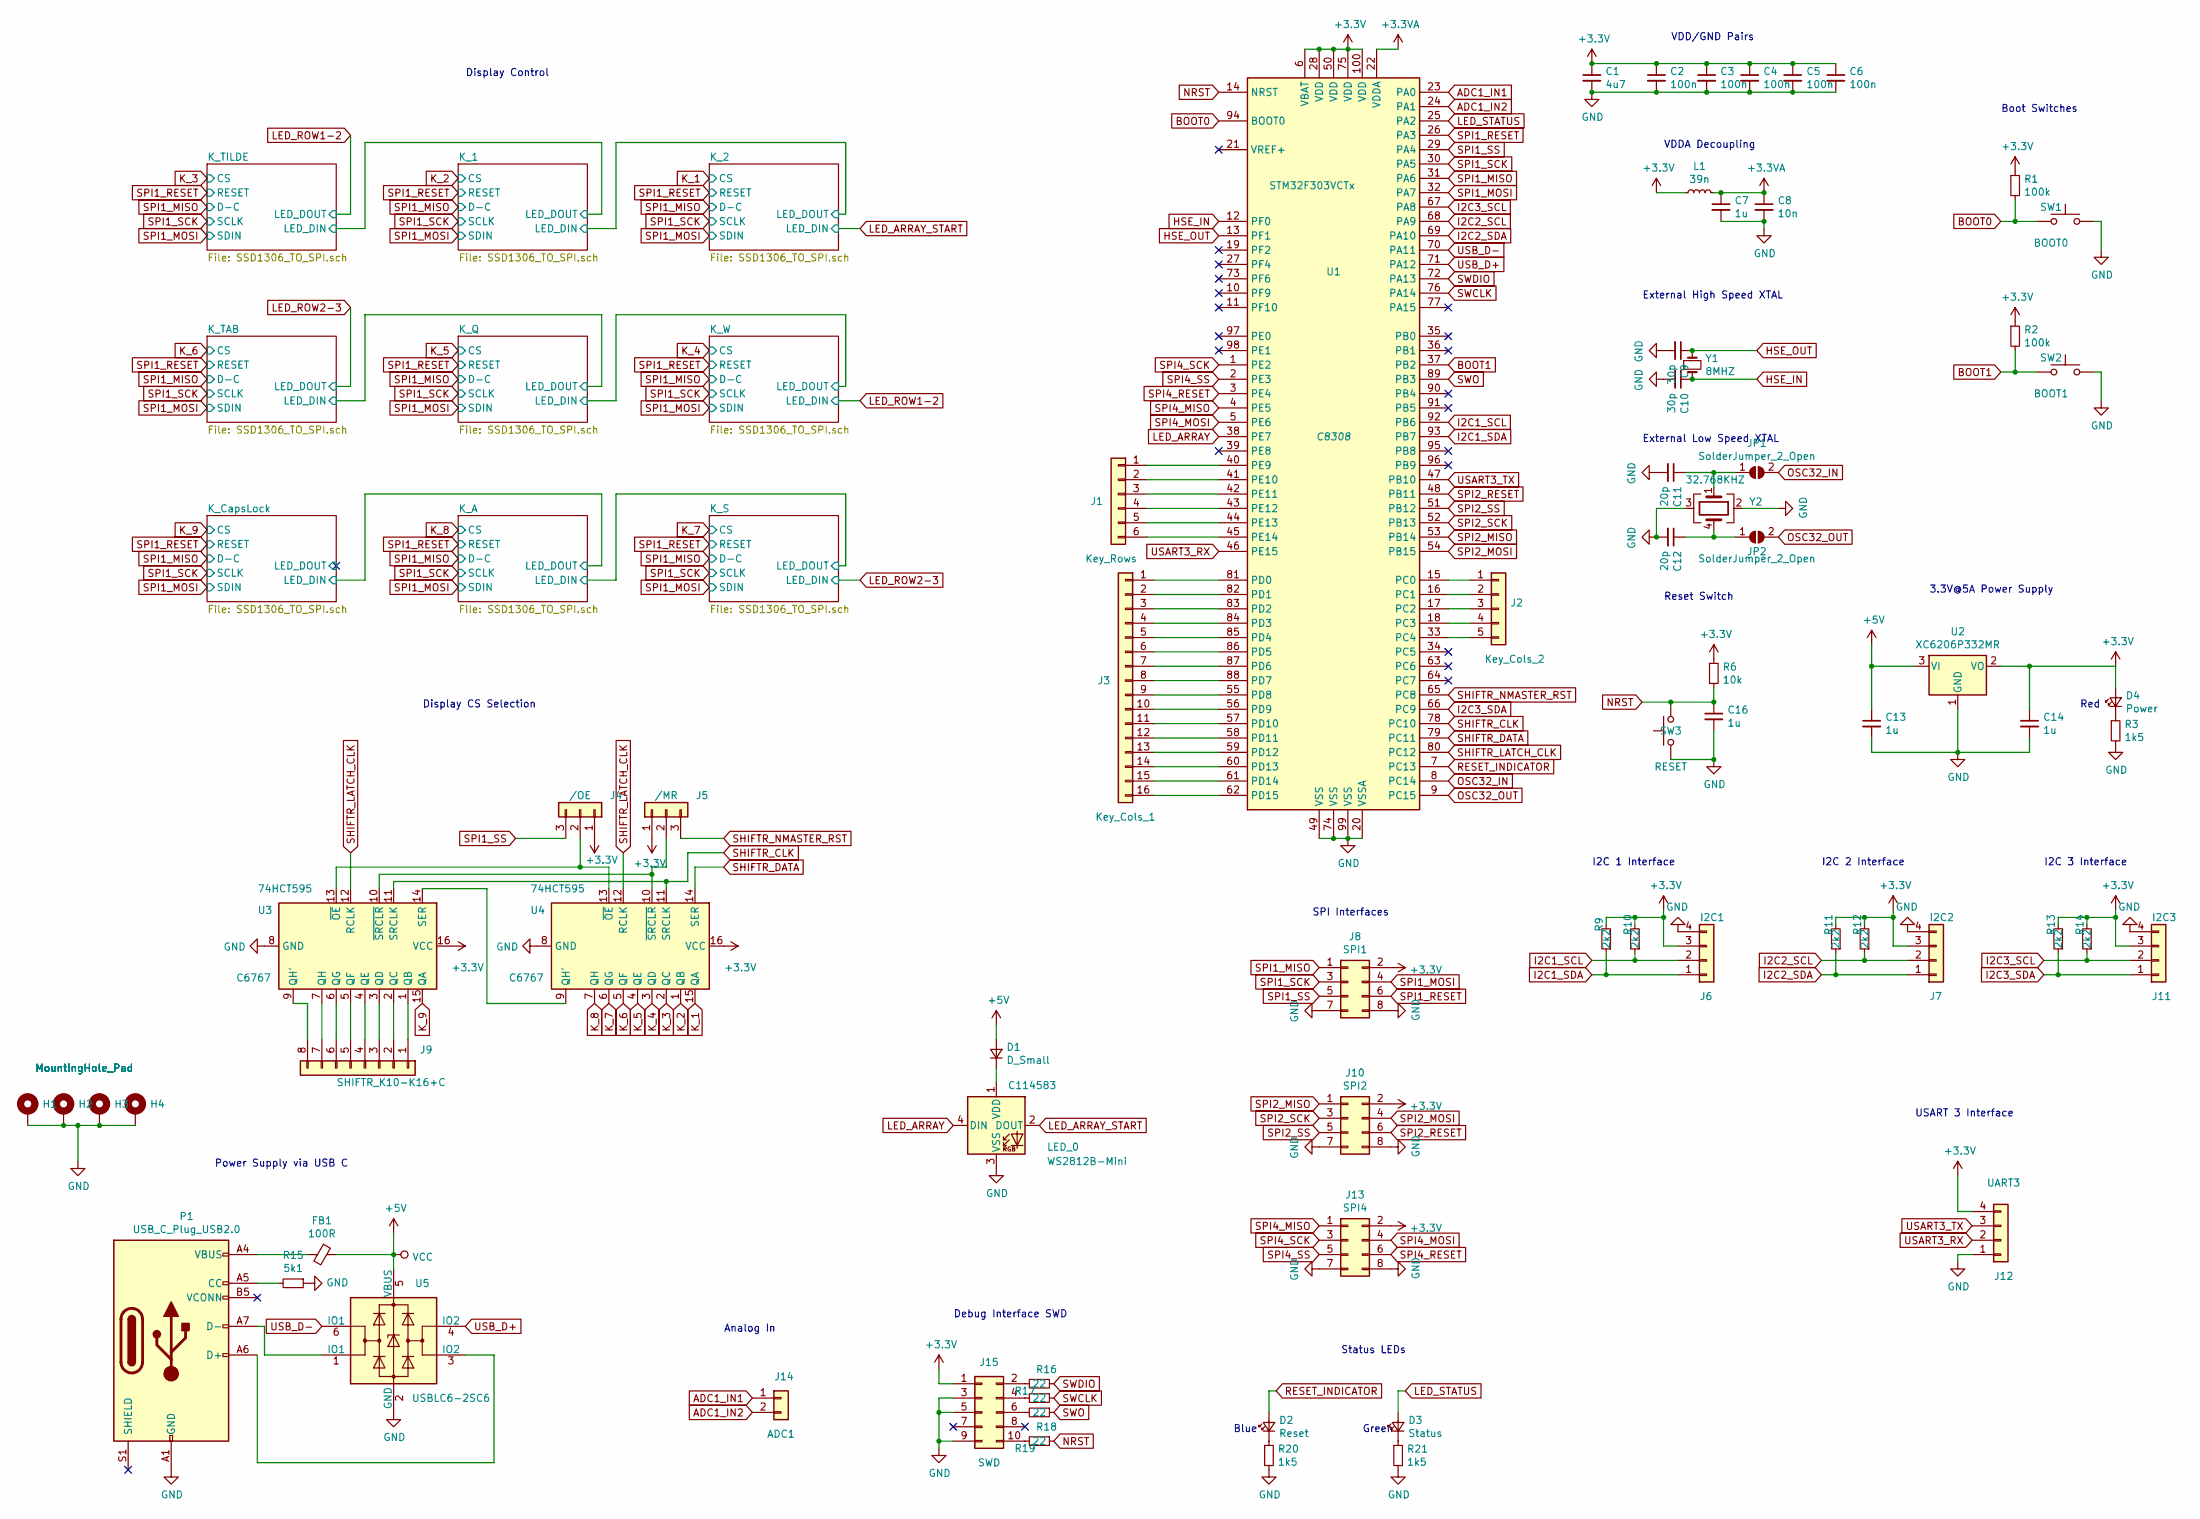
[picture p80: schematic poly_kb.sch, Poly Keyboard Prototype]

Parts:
C1: 4u7; C_0603_1608Metric; LCSC C19666
C2, C3, C4, C5, C6: 100n; C_0402_1005Metric; LCSC C1525
C7, C13, C14, C16: 1u; C_0402_1005Metric; LCSC C52923
C8: 10n; C_0402_1005Metric; LCSC C15195
C9, C10: 30p; C_0402_1005Metric; LCSC C1570
C11, C12: 20p; C_0603_1608Metric; LCSC C1603
D1: D_Small; D_SOD-123F; LCSC C64898
D2: Reset; LED_0603_1608Metric; LCSC C72041
D3: Status; LED_0603_1608Metric; LCSC C72043
D4: Power; LED_0603_1608Metric; LCSC C2286
FB1: 100R; L_0805_2012Metric; LCSC C1015
H1, H2, H3, H4: MountingHole_Pad; MountingHole_4.3mm_M4_Pad_Via
J1: Key_Rows; PinHeader_1x06_P2.54mm_Vertical
J2: Key_Cols_2; PinHeader_1x05_P2.54mm_Vertical
J3: Key_Cols_1; PinHeader_1x16_P2.54mm_Vertical
J4: /OE; PinHeader_1x03_P2.54mm_Vertical
J5: /MR; PinHeader_1x03_P2.54mm_Vertical
J6: I2C1; PinHeader_1x04_P2.54mm_Vertical
J7: I2C2; PinHeader_1x04_P2.54mm_Vertical
J8: SPI1; PinHeader_2x04_P2.54mm_Vertical
J9: SHIFTR_K10-K16+C; PinHeader_1x08_P2.54mm_Vertical
J10: SPI2; PinHeader_2x04_P2.54mm_Vertical
J11: I2C3; PinHeader_1x04_P2.54mm_Vertical
J12: UART3; PinHeader_1x04_P2.54mm_Vertical
J13: SPI4; PinHeader_2x04_P2.54mm_Vertical
J14: ADC1; PinHeader_1x02_P2.54mm_Vertical
J15: SWD; PinHeader_2x05_P2.54mm_Vertical
JP1, JP2: SolderJumper_2_Open; SolderJumper-2_P1.3mm_Open_TrianglePad1.0x1.5mm
L1: 39n; L_0402_1005Metric; LCSC C26443
LED_0: WS2812B-Mini; LCSC C114583
P1: USB_C_Plug_USB2.0; USB_C_Receptacle_Palconn_UTC16-G; LCSC C393939
R1, R2: 100k; R_0603_1608Metric; LCSC C25803
R3, R20, R21: 1k5; R_0805_2012Metric; LCSC C4310
R6: 10k; R_0402_1005Metric; LCSC C25744
R9, R10, R11, R12, R13, R14: 2k2; R_0805_2012Metric; LCSC C17521
R15: 5k1; R_0603_1608Metric; LCSC C23186
R16, R17, R18, R19: 22; R_0805_2012Metric; LCSC C17561
SW1: BOOT0; Switch_THT
SW2: BOOT1; Switch_THT
SW3: RESET; Switch_THT
U1: STM32F303VCTx; LQFP-100_14x14mm_P0.5mm; LCSC C8308
U2: XC6206P332MR; SOT-23; LCSC C5446
U3, U4: 74HCT595; SOIC-16_3.9x9.9mm_P1.27mm; LCSC C6767
U5: USBLC6-2SC6; SOT-23-6; LCSC C7519
Y1: 8MHZ; Crystal_SMD_5032-2Pin_5.0x3.2mm; LCSC C115962
Y2: 32.768KHZ; SMD-0832_4P; LCSC C145166

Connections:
+3.3VA: C7.1, C8.1, L1.2, U1.22 (VDDA)
+3V3: C1.1, C2.1, C3.1, C4.1, C5.1, C6.1, C14.1, D4.2 (A), J4.1, J5.1, J6.3, J7.3, J8.2, J10.2, J11.3, J12.4, J13.2, J15.1, L1.1, R1.1, R2.1, R6.1, R9.2, R10.2, R11.2, R12.2, R13.2, R14.2, U1.6 (VBAT), U1.28 (VDD), U1.50 (VDD), U1.75 (VDD), U1.100 (VDD), U2.2 (VO), U3.16 (VCC), U4.16 (VCC); also elsewhere on the board
+5V: C13.1, D1.2 (A), FB1.1, U2.3 (VI), U5.5 (VBUS); also elsewhere on the board
ADC1_IN1: J14.1, U1.23 (PA0)
ADC1_IN2: J14.2, U1.24 (PA1)
BOOT0: R1.2, SW1.1, U1.94 (BOOT0)
BOOT1: R2.2, SW2.1, U1.37 (PB2)
GND: C1.2, C2.2, C3.2, C4.2, C5.2, C6.2, C7.2, C8.2, C9.2, C10.2, C11.2, C12.2, C13.2, C14.2, C16.2, H1.1, H2.1, H3.1, H4.1, J6.4, J7.4, J8.7, J8.8, J10.7, J10.8, J11.4, J12.1, J13.7, J13.8, J15.3, J15.5, J15.9, LED_0.3 (VSS), P1.A1 (GND), P1.A12 (GND), P1.B1 (GND), P1.B12 (GND), R3.2, R15.1, R20.2, R21.2, SW1.2, SW2.2, SW3.2, U1.20 (VSSA), U1.49 (VSS), U1.74 (VSS), U1.99 (VSS), U2.1 (GND), U3.8 (GND), U4.8 (GND), U5.2 (GND), Y2.2, Y2.3; also elsewhere on the board
HSE_IN: C10.1, U1.12 (PF0), Y1.2
HSE_OUT: C9.1, U1.13 (PF1), Y1.1
I2C1_SCL: J6.2, R10.1, U1.92 (PB6)
I2C1_SDA: J6.1, R9.1, U1.93 (PB7)
I2C2_SCL: J7.2, R12.1, U1.68 (PA9)
I2C2_SDA: J7.1, R11.1, U1.69 (PA10)
I2C3_SCL: J11.2, R14.1, U1.67 (PA8)
I2C3_SDA: J11.1, R13.1, U1.66 (PC9)
K_1: U4.15 (QA); also elsewhere on the board
K_2: U4.1 (QB); also elsewhere on the board
K_3: U4.2 (QC); also elsewhere on the board
K_4: U4.3 (QD); also elsewhere on the board
K_5: U4.4 (QE); also elsewhere on the board
K_6: U4.5 (QF); also elsewhere on the board
K_7: U4.6 (QG); also elsewhere on the board
K_8: U4.7 (QH); also elsewhere on the board
K_9: U3.15 (QA); also elsewhere on the board
LED_ARRAY: LED_0.4 (DIN), U1.38 (PE7)
LED_ARRAY_START: LED_0.2 (DOUT); also elsewhere on the board
LED_STATUS: D3.2 (A), U1.25 (PA2)
NRST: C16.1, R6.2, R19.1, SW3.1, U1.14 (NRST)
unnamed: C11.1, JP1.1 (A), Y2.1
unnamed: C12.1, JP2.1 (A), Y2.4
unnamed: D1.1 (K), LED_0.1 (VDD)
unnamed: D2.1 (K), R20.1
unnamed: D3.1 (K), R21.1
unnamed: D4.1 (K), R3.1
unnamed: FB1.2, P1.A4 (VBUS), P1.A9 (VBUS), P1.B4 (VBUS), P1.B9 (VBUS)
unnamed: J1.1, U1.40 (PE9)
unnamed: J1.2, U1.41 (PE10)
unnamed: J1.3, U1.42 (PE11)
unnamed: J1.4, U1.43 (PE12)
unnamed: J1.5, U1.44 (PE13)
unnamed: J1.6, U1.45 (PE14)
unnamed: J2.1, U1.15 (PC0)
unnamed: J2.2, U1.16 (PC1)
unnamed: J2.3, U1.17 (PC2)
unnamed: J2.4, U1.18 (PC3)
unnamed: J2.5, U1.33 (PC4)
unnamed: J3.1, U1.81 (PD0)
unnamed: J3.2, U1.82 (PD1)
unnamed: J3.3, U1.83 (PD2)
unnamed: J3.4, U1.84 (PD3)
unnamed: J3.5, U1.85 (PD4)
unnamed: J3.6, U1.86 (PD5)
unnamed: J3.7, U1.87 (PD6)
unnamed: J3.8, U1.88 (PD7)
unnamed: J3.9, U1.55 (PD8)
unnamed: J3.10, U1.56 (PD9)
unnamed: J3.11, U1.57 (PD10)
unnamed: J3.12, U1.58 (PD11)
unnamed: J3.13, U1.59 (PD12)
unnamed: J3.14, U1.60 (PD13)
unnamed: J3.15, U1.61 (PD14)
unnamed: J3.16, U1.62 (PD15)
unnamed: J4.2, U3.13 (~OE), U4.13 (~OE)
unnamed: J5.2, U3.10 (~SRCLR), U4.10 (~SRCLR)
unnamed: J9.1, U3.1 (QB)
unnamed: J9.2, U3.2 (QC)
unnamed: J9.3, U3.3 (QD)
unnamed: J9.4, U3.4 (QE)
unnamed: J9.5, U3.5 (QF)
unnamed: J9.6, U3.6 (QG)
unnamed: J9.7, U3.7 (QH)
unnamed: J9.8, U3.9 (QH')
unnamed: J15.2, R16.2
unnamed: J15.4, R17.2
unnamed: J15.6, R18.2
unnamed: J15.10, R19.2
unnamed: P1.A5 (CC), R15.2
unnamed: P1.A6 (D+), U5.3 (IO2)
unnamed: P1.A7 (D-), U5.1 (IO1)
unnamed: U3.14 (SER), U4.9 (QH')
OSC32_IN: JP1.2 (B), U1.8 (PC14)
OSC32_OUT: JP2.2 (B), U1.9 (PC15)
RESET_INDICATOR: D2.2 (A), U1.7 (PC13)
SHIFTR_CLK: U1.78 (PC10), U3.11 (SRCLK), U4.11 (SRCLK)
SHIFTR_DATA: U1.79 (PC11), U4.14 (SER)
SHIFTR_LATCH_CLK: U1.80 (PC12), U3.12 (RCLK), U4.12 (RCLK)
SHIFTR_NMASTER_RST: J5.3, U1.65 (PC8)
SPI1_MISO: J8.1, U1.31 (PA6); also elsewhere on the board
SPI1_MOSI: J8.4, U1.32 (PA7); also elsewhere on the board
SPI1_RESET: J8.6, U1.26 (PA3); also elsewhere on the board
SPI1_SCK: J8.3, U1.30 (PA5); also elsewhere on the board
SPI1_SS: J4.3, J8.5, U1.29 (PA4)
SPI2_MISO: J10.1, U1.53 (PB14)
SPI2_MOSI: J10.4, U1.54 (PB15)
SPI2_RESET: J10.6, U1.48 (PB11)
SPI2_SCK: J10.3, U1.52 (PB13)
SPI2_SS: J10.5, U1.51 (PB12)
SPI4_MISO: J13.1, U1.4 (PE5)
SPI4_MOSI: J13.4, U1.5 (PE6)
SPI4_RESET: J13.6, U1.3 (PE4)
SPI4_SCK: J13.3, U1.1 (PE2)
SPI4_SS: J13.5, U1.2 (PE3)
SWCLK: R17.1, U1.76 (PA14)
SWDIO: R16.1, U1.72 (PA13)
SWO: R18.1, U1.89 (PB3)
USART3_RX: J12.2, U1.46 (PE15)
USART3_TX: J12.3, U1.47 (PB10)
USB_D+: U1.71 (PA12), U5.4 (IO2)
USB_D-: U1.70 (PA11), U5.6 (IO1)

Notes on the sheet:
VDDA Decoupling
External High Speed XTAL
Boot Switches
VDD/GND Pairs
Status LEDs
3.3V@5A Power Supply
Debug Interface SWD
I2C 2 Interface
I2C 1 Interface
I2C 3 Interface
Green
SPI Interfaces
USART 3 Interface
Power Supply via USB C
Display CS Selection
Display Control
Analog In
Reset Switch
Blue
External Low Speed XTAL
Red

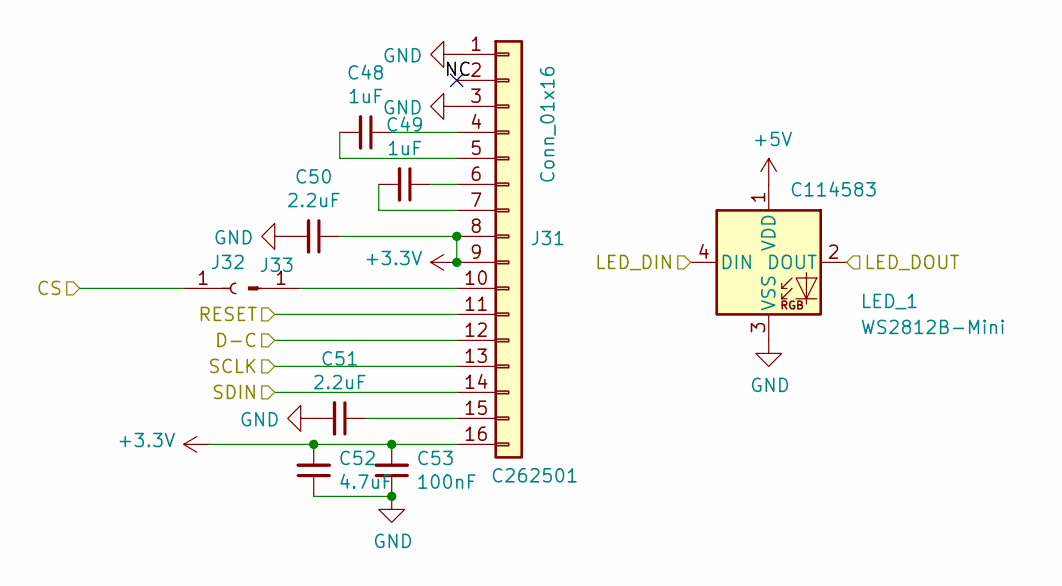
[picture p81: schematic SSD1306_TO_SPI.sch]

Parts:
C18, C19: 1uF; C_0805_2012Metric; LCSC C28323
C20, C21: 2.2uF; C_0805_2012Metric; LCSC C49217
C22: 4.7uF; C_0805_2012Metric; LCSC C1779
C23: 100nF; C_0805_2012Metric; LCSC C49678
J16: Conn_01x16; FPC_16_AFC11-S16ICA-00; LCSC C262501
J17: Conn_01x01_Female; PinHeader_1x01_P1.00mm_Vertical
J21: Conn_01x01_Male; PinHeader_1x01_P1.00mm_Vertical
LED_5: WS2812B-Mini; LCSC C114583

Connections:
+3V3: C20.1, C22.2, C23.2, J16.8, J16.9, J16.16; also elsewhere on the board
+5V: LED_5.1 (VDD); also elsewhere on the board
/K_Q/LED_DIN: LED_5.4 (DIN); also elsewhere on the board
/K_TAB/LED_DIN: LED_5.2 (DOUT); also elsewhere on the board
GND: C20.2, C21.2, C22.1, C23.1, J16.1, J16.3, LED_5.3 (VSS); also elsewhere on the board
K_5: J17.1; also elsewhere on the board
unnamed: C18.1, J16.4
unnamed: C18.2, J16.5
unnamed: C19.1, J16.6
unnamed: C19.2, J16.7
unnamed: C21.1, J16.15
SPI1_MISO: J16.12; also elsewhere on the board
SPI1_MOSI: J16.14; also elsewhere on the board
SPI1_RESET: J16.11; also elsewhere on the board
SPI1_SCK: J16.13; also elsewhere on the board

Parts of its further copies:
C24, C25, C30, C31, C36, C37, C42, C43, C48, C49, C54, C55, C60, C61, C66, C67: 1uF; C_0805_2012Metric; LCSC C28323
C26, C27, C32, C33, C38, C39, C44, C45, C50, C51, C56, C57, C62, C63, C68, C69: 2.2uF; C_0805_2012Metric; LCSC C49217
C28, C34, C40, C46, C52, C58, C64, C70: 4.7uF; C_0805_2012Metric; LCSC C1779
C29, C35, C41, C47, C53, C59, C65, C71: 100nF; C_0805_2012Metric; LCSC C49678
J18, J24, J27, J30, J33, J36, J39, J42: Conn_01x01_Male; PinHeader_1x01_P1.00mm_Vertical
J19, J22, J25, J28, J31, J34, J37, J40: Conn_01x16; FPC_16_AFC11-S16ICA-00; LCSC C262501
J20, J23, J26, J29, J32, J35, J38, J41: Conn_01x01_Female; PinHeader_1x01_P1.00mm_Vertical
LED_1, LED_2, LED_3, LED_4, LED_6, LED_7, LED_8, LED_9: WS2812B-Mini; LCSC C114583

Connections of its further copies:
+3V3: C26.1, C28.2, C29.2, C32.1, C34.2, C35.2, C38.1, C40.2, C41.2, C44.1, C46.2, C47.2, C50.1, C52.2, C53.2, C56.1, C58.2, C59.2, C62.1, C64.2, C65.2, C68.1, C70.2, C71.2, J19.8, J19.9, J19.16, J22.8, J22.9, J22.16, J25.8, J25.9, J25.16, J28.8, J28.9, J28.16, J31.8, J31.9, J31.16, J34.8, J34.9, J34.16, J37.8, J37.9, J37.16, J40.8, J40.9, J40.16; also elsewhere on the board
+5V: LED_1.1 (VDD), LED_2.1 (VDD), LED_3.1 (VDD), LED_4.1 (VDD), LED_6.1 (VDD), LED_7.1 (VDD), LED_8.1 (VDD), LED_9.1 (VDD); also elsewhere on the board
/K_1/LED_DIN: LED_2.4 (DIN), LED_3.2 (DOUT)
/K_A/LED_DIN: LED_8.4 (DIN), LED_9.2 (DOUT)
/K_CapsLock/LED_DIN: LED_7.4 (DIN), LED_8.2 (DOUT)
/K_Q/LED_DIN: LED_6.2 (DOUT); also elsewhere on the board
/K_TAB/LED_DIN: LED_4.4 (DIN); also elsewhere on the board
/K_TILDE/LED_DIN: LED_1.4 (DIN), LED_2.2 (DOUT)
GND: C26.2, C27.2, C28.1, C29.1, C32.2, C33.2, C34.1, C35.1, C38.2, C39.2, C40.1, C41.1, C44.2, C45.2, C46.1, C47.1, C50.2, C51.2, C52.1, C53.1, C56.2, C57.2, C58.1, C59.1, C62.2, C63.2, C64.1, C65.1, C68.2, C69.2, C70.1, C71.1, J19.1, J19.3, J22.1, J22.3, J25.1, J25.3, J28.1, J28.3, J31.1, J31.3, J34.1, J34.3, J37.1, J37.3, J40.1, J40.3, LED_1.3 (VSS), LED_2.3 (VSS), LED_3.3 (VSS), LED_4.3 (VSS), LED_6.3 (VSS), LED_7.3 (VSS), LED_8.3 (VSS), LED_9.3 (VSS); also elsewhere on the board
K_1: J29.1; also elsewhere on the board
K_2: J26.1; also elsewhere on the board
K_3: J32.1; also elsewhere on the board
K_4: J20.1; also elsewhere on the board
K_6: J23.1; also elsewhere on the board
K_7: J38.1; also elsewhere on the board
K_8: J35.1; also elsewhere on the board
K_9: J41.1; also elsewhere on the board
LED_ARRAY_START: LED_3.4 (DIN); also elsewhere on the board
LED_ROW1-2: LED_1.2 (DOUT), LED_6.4 (DIN)
LED_ROW2-3: LED_4.2 (DOUT), LED_9.4 (DIN)
unnamed: C24.1, J19.4
unnamed: C24.2, J19.5
unnamed: C25.1, J19.6
unnamed: C25.2, J19.7
unnamed: C27.1, J19.15
unnamed: C30.1, J22.4
unnamed: C30.2, J22.5
unnamed: C31.1, J22.6
unnamed: C31.2, J22.7
unnamed: C33.1, J22.15
unnamed: C36.1, J25.4
unnamed: C36.2, J25.5
unnamed: C37.1, J25.6
unnamed: C37.2, J25.7
unnamed: C39.1, J25.15
unnamed: C42.1, J28.4
unnamed: C42.2, J28.5
unnamed: C43.1, J28.6
unnamed: C43.2, J28.7
unnamed: C45.1, J28.15
unnamed: C48.1, J31.4
unnamed: C48.2, J31.5
unnamed: C49.1, J31.6
unnamed: C49.2, J31.7
unnamed: C51.1, J31.15
unnamed: C54.1, J34.4
unnamed: C54.2, J34.5
unnamed: C55.1, J34.6
unnamed: C55.2, J34.7
unnamed: C57.1, J34.15
unnamed: C60.1, J37.4
unnamed: C60.2, J37.5
unnamed: C61.1, J37.6
unnamed: C61.2, J37.7
unnamed: C63.1, J37.15
unnamed: C66.1, J40.4
unnamed: C66.2, J40.5
unnamed: C67.1, J40.6
unnamed: C67.2, J40.7
unnamed: C69.1, J40.15
unnamed: J22.10, J24.1
unnamed: J25.10, J27.1
unnamed: J28.10, J30.1
unnamed: J31.10, J33.1
unnamed: J34.10, J36.1
unnamed: J37.10, J39.1
unnamed: J40.10, J42.1
SPI1_MISO: J19.12, J22.12, J25.12, J28.12, J31.12, J34.12, J37.12, J40.12; also elsewhere on the board
SPI1_MOSI: J19.14, J22.14, J25.14, J28.14, J31.14, J34.14, J37.14, J40.14; also elsewhere on the board
SPI1_RESET: J19.11, J22.11, J25.11, J28.11, J31.11, J34.11, J37.11, J40.11; also elsewhere on the board
SPI1_SCK: J19.13, J22.13, J25.13, J28.13, J31.13, J34.13, J37.13, J40.13; also elsewhere on the board

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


Board: 2 copper layers, 116.8 x 86.4 mm, 161 parts (135 on the bottom side), 172 nets.

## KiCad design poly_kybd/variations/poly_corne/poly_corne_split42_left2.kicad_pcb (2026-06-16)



Board: 2 copper layers, 277.2 x 107.5 mm, 178 parts (168 on the bottom side), 152 nets.

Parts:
BT1, BT2, BT3, BT4: Breakaway Tabs; Breakaway_Tabs
C1, C2: 27p; C_0402_1005Metric
C3, C4, C7, C9, C10, C12, C13, C14, C15: 100n; C_0402_1005Metric
C5, C8, C16: 1u; C_0402_1005Metric
C6, C11: 10u; C_0402_1005Metric
D1: 1N4148WT; D_SOD-523
EXLED1, EXLED2: YS-SK6812MINI-E
EXSW1, EXSW2: RotaryEncoder_Switch; keyswitch_cherrymx_hotswap_1u_rotary_encoder_ec12
J1: TYPE-C-31-M-13C
J2: TRS; PJ-398A-5A_PJ-399B-6A
J3: Conn_01x04; OLED
J4: Conn_01x03; PinHeader_1x03_P2.54mm_Vertical
JP1: SolderJumper_2_Bridged; SolderJumper-2_P1.3mm_Open_RoundedPad1.0x1.5mm
LED1, LED2, LED3, LED4, LED5, LED6, LED7, LED8, LED9, LED10, LED11, LED12, LED13, LED14, LED15, LED16, LED17, LED18, LED19, LED20, LED21: YS-SK6812MINI-E
R1, R2: 5.1k; R_0402_1005Metric
R3, R6: 1k; R_0402_1005Metric
R4, R5: 27; R_0402_1005Metric
R7: 10k; R_0402_1005Metric
R8: 5.6k; R_0402_1005Metric
R9: 10K; R_0402_1005Metric
SMDSW1, SMDSW2: TS-1088R-02026
SW1: SW_Push; keyswitch_cherrymx_hotswap_1.5u
SW2, SW3, SW4, SW5, SW6, SW7, SW8, SW9, SW10, SW11, SW12, SW13, SW14, SW15, SW16, SW17, SW18, SW19, SW20, SW21: SW_Push; keyswitch_cherrymx_hotswap_1u
U1: RP2040; QFN-56-1EP_7x7mm_P0.4mm_EP3.2x3.2mm
U2: NCP1117LPST33T3G; SOT-223-3_TabPin2
U3: TPD4E05U06DQAR; USON-10_2.5x1.0mm_P0.5mm
U4: W25Q128JVSIQ; SOIC-8_5.23x5.23mm_P1.27mm
Y1: 12MHz 18pF; Crystal_SMD_3225-4Pin_3.2x2.5mm
ZD1: RB521S30T1G; D_SOD-523
rBT1, rBT2, rBT3, rBT4: Breakaway Tabs; Breakaway_Tabs
rC1, rC2: 27p; C_0402_1005Metric
rC3, rC4, rC7, rC9, rC10, rC12, rC13, rC14, rC15: 100n; C_0402_1005Metric
rC5, rC8, rC16: 1u; C_0402_1005Metric
rC6, rC11: 10u; C_0402_1005Metric
rD1: 1N4148WT; D_SOD-523
rEXLED1, rEXLED2: YS-SK6812MINI-E
rEXSW1, rEXSW2: RotaryEncoder_Switch; keyswitch_cherrymx_hotswap_1u_rotary_encoder_ec12
rJ1: TYPE-C-31-M-13C
rJ2: TRS; PJ-398A-5A_PJ-399B-6A
rJ3: Conn_01x04; OLED
rJ4: Conn_01x03; PinHeader_1x03_P2.54mm_Vertical
rJP1: SolderJumper_2_Bridged; SolderJumper-2_P1.3mm_Open_RoundedPad1.0x1.5mm
rLED1, rLED2, rLED3, rLED4, rLED5, rLED6, rLED7, rLED8, rLED9, rLED10, rLED11, rLED12, rLED13, rLED14, rLED15, rLED16, rLED17, rLED18, rLED19, rLED20, rLED21: YS-SK6812MINI-E
rR1, rR2: 5.1k; R_0402_1005Metric
rR3, rR6: 1k; R_0402_1005Metric
rR4, rR5: 27; R_0402_1005Metric
rR7: 10k; R_0402_1005Metric
rR8: 5.6k; R_0402_1005Metric
rR9: 10K; R_0402_1005Metric
rSMDSW1, rSMDSW2: TS-1088R-02026
rSW1: SW_Push; keyswitch_cherrymx_hotswap_1.5u
rSW2, rSW3, rSW4, rSW5, rSW6, rSW7, rSW8, rSW9, rSW10, rSW11, rSW12, rSW13, rSW14, rSW15, rSW16, rSW17, rSW18, rSW19, rSW20, rSW21: SW_Push; keyswitch_cherrymx_hotswap_1u
rU1: RP2040; QFN-56-1EP_7x7mm_P0.4mm_EP3.2x3.2mm
rU2: NCP1117LPST33T3G; SOT-223-3_TabPin2
rU3: TPD4E05U06DQAR; USON-10_2.5x1.0mm_P0.5mm
rU4: W25Q128JVSIQ; SOIC-8_5.23x5.23mm_P1.27mm
rY1: 12MHz 18pF; Crystal_SMD_3225-4Pin_3.2x2.5mm
rZD1: RB521S30T1G; D_SOD-523

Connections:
+1V1: C3.1, C4.1, C5.1, U1.23 (DVDD), U1.45 (VREG_VOUT), U1.50 (DVDD)
+1V1R: rC3.1, rC4.1, rC5.1, rU1.23 (DVDD), rU1.45 (VREG_VOUT), rU1.50 (DVDD)
+3V3: C7.1, C8.1, C9.1, C10.1, C11.1, C12.1, C13.1, C14.1, C15.1, C16.1, R7.2, U1.1 (IOVDD), U1.10 (IOVDD), U1.22 (IOVDD), U1.32 (GPIO21), U1.33 (IOVDD), U1.42 (IOVDD), U1.43 (ADC_AVDD), U1.44 (VREG_IN), U1.48 (USB_VDD), U1.49 (IOVDD), U2.2 (VO), U4.8 (VCC)
+3V3R: rC7.1, rC8.1, rC9.1, rC10.1, rC11.1, rC12.1, rC13.1, rC14.1, rC15.1, rC16.1, rR7.2, rU1.1 (IOVDD), rU1.10 (IOVDD), rU1.22 (IOVDD), rU1.33 (IOVDD), rU1.42 (IOVDD), rU1.43 (ADC_AVDD), rU1.44 (VREG_IN), rU1.48 (USB_VDD), rU1.49 (IOVDD), rU2.2 (VO), rU4.8 (VCC)
+5V: C6.1, D1.2 (A), J2.T, J3.3, U2.3 (VI), ZD1.1 (K)
+5VR: rC6.1, rD1.2 (A), rJ2.T, rJ3.3, rU2.3 (VI), rZD1.1 (K)
/left/D+: J1.A6 (D+), J1.B6 (D+), R4.1, U3.1 (D1+), U3.4 (D2+), U3.7 (NC), U3.10 (NC)
/left/D-: J1.A7 (D-), J1.B7 (D-), R5.2, U3.2 (D1-), U3.5 (D2-), U3.6 (NC), U3.9 (NC)
/left/KEY1: SW1.1, U1.14 (GPIO11)
/left/KEY2: SW2.1, U1.12 (GPIO9)
/left/KEY3: SW3.1, U1.4 (GPIO2)
/left/KEY4: SW4.1, U1.2 (GPIO0)
/left/KEY5: SW5.1, U1.41 (GPIO29_ADC3)
/left/KEY6: SW6.1, U1.3 (GPIO1)
/left/KEY7: SW7.1, U1.5 (GPIO3)
/left/KEY8: SW8.1, U1.18 (GPIO15)
/left/KEY9: SW9.1, U1.17 (GPIO14)
/left/KEY10: SW10.1, U1.40 (GPIO28_ADC2)
/left/KEY11: SW11.1, U1.39 (GPIO27_ADC1)
/left/KEY12: SW12.1, U1.38 (GPIO26_ADC0)
/left/KEY13: SW13.1, U1.35 (GPIO23)
/left/KEY14: SW14.1, U1.36 (GPIO24)
/left/KEY15: SW15.1, U1.37 (GPIO25)
/left/KEY16: SW16.1, U1.27 (GPIO16)
/left/KEY17: SW17.1, U1.29 (GPIO18)
/left/KEY18: SW18.1, U1.31 (GPIO20)
/left/KEY19: SW19.1, U1.34 (GPIO22)
/left/KEY20: SW20.1, U1.30 (GPIO19)
/left/KEY21: SW21.1, U1.28 (GPIO17)
/left/KEYEX1: EXSW1.S2, U1.6 (GPIO4)
/left/KEYEX2: EXSW2.S2, U1.11 (GPIO8)
/left/LED: LED1.4 (DIN), U1.13 (GPIO10)
/left/QSPI_SCLK: U1.52 (QSPI_SCLK), U4.6 (CLK)
/left/QSPI_SD0: U1.53 (QSPI_SD0), U4.5 (DI(IO0))
/left/QSPI_SD1: U1.55 (QSPI_SD1), U4.2 (DO(IO1))
/left/QSPI_SD2: U1.54 (QSPI_SD2), U4.3 (IO2)
/left/QSPI_SD3: U1.51 (QSPI_SD3), U4.7 (IO3)
/left/QSPI_SS: R6.1, R7.1, U1.56 (QSPI_SS), U4.1 (~CS)
/left/RE0A: EXSW1.A, U1.7 (GPIO5)
/left/RE1A: EXSW2.A, J3.1, U1.8 (GPIO6)
/left/REB: EXSW1.B, EXSW2.B, J3.2, U1.9 (GPIO7)
/left/SWCLK: J4.1, U1.24 (SWCLK)
/left/SWD: J4.3, U1.25 (SWD)
/left/TX: J2.R, U1.15 (GPIO12)
/left/USB_VBUS_PIN: R8.2, R9.1, U1.16 (GPIO13)
/right/D+: rJ1.A6 (D+), rJ1.B6 (D+), rR4.1, rU3.1 (D1+), rU3.4 (D2+), rU3.7 (NC), rU3.10 (NC)
/right/D-: rJ1.A7 (D-), rJ1.B7 (D-), rR5.2, rU3.2 (D1-), rU3.5 (D2-), rU3.6 (NC), rU3.9 (NC)
/right/KEY1: rSW1.1, rU1.30 (GPIO19)
/right/KEY2: rSW2.1, rU1.34 (GPIO22)
/right/KEY3: rSW3.1, rU1.38 (GPIO26_ADC0)
/right/KEY4: rSW4.1, rU1.39 (GPIO27_ADC1)
/right/KEY5: rSW5.1, rU1.3 (GPIO1)
/right/KEY6: rSW6.1, rU1.40 (GPIO28_ADC2)
/right/KEY7: rSW7.1, rU1.31 (GPIO20)
/right/KEY8: rSW8.1, rU1.28 (GPIO17)
/right/KEY9: rSW9.1, rU1.27 (GPIO16)
/right/KEY10: rSW10.1, rU1.41 (GPIO29_ADC3)
/right/KEY11: rSW11.1, rU1.2 (GPIO0)
/right/KEY12: rSW12.1, rU1.4 (GPIO2)
/right/KEY13: rSW13.1, rU1.5 (GPIO3)
/right/KEY14: rSW14.1, rU1.6 (GPIO4)
/right/KEY15: rSW15.1, rU1.7 (GPIO5)
/right/KEY16: rSW16.1, rU1.29 (GPIO18)
/right/KEY17: rSW17.1, rU1.17 (GPIO14)
/right/KEY18: rSW18.1, rU1.12 (GPIO9)
/right/KEY19: rSW19.1, rU1.11 (GPIO8)
/right/KEY20: rSW20.1, rU1.14 (GPIO11)
/right/KEY21: rSW21.1, rU1.18 (GPIO15)
/right/KEYEX1: rEXSW1.S2, rU1.37 (GPIO25)
/right/KEYEX2: rEXSW2.S2, rU1.35 (GPIO23)
/right/LED: rLED1.4 (DIN), rU1.13 (GPIO10)
/right/QSPI_SCLK: rU1.52 (QSPI_SCLK), rU4.6 (CLK)
/right/QSPI_SD0: rU1.53 (QSPI_SD0), rU4.5 (DI(IO0))
/right/QSPI_SD1: rU1.55 (QSPI_SD1), rU4.2 (DO(IO1))
/right/QSPI_SD2: rU1.54 (QSPI_SD2), rU4.3 (IO2)
/right/QSPI_SD3: rU1.51 (QSPI_SD3), rU4.7 (IO3)
/right/QSPI_SS: rR6.1, rR7.1, rU1.56 (QSPI_SS), rU4.1 (~CS)
/right/RE0A: rEXSW1.A, rU1.36 (GPIO24)
/right/RE1A: rEXSW2.A, rJ3.1, rU1.8 (GPIO6)
/right/REB: rEXSW1.B, rEXSW2.B, rJ3.2, rU1.9 (GPIO7)
/right/SWCLK: rJ4.1, rU1.24 (SWCLK)
/right/SWD: rJ4.3, rU1.25 (SWD)
/right/TX: rJ2.R, rU1.15 (GPIO12)
/right/USB_VBUS_PIN: rR8.2, rR9.1, rU1.16 (GPIO13)
GND: C1.2, C2.2, C3.2, C4.2, C5.2, C6.2, C7.2, C8.2, C9.2, C10.2, C11.2, C12.2, C13.2, C14.2, C15.2, C16.2, EXLED1.3 (VSS), EXLED2.3 (VSS), EXSW1.C, EXSW1.S1, EXSW2.C, EXSW2.S1, J1.A1 (GND), J1.A12 (GND), J1.B1 (GND), J1.B12 (GND), J1.S1 (SHIELD), J2.S, J3.4, J4.2, LED1.3 (VSS), LED2.3 (VSS), LED3.3 (VSS), LED4.3 (VSS), LED5.3 (VSS), LED6.3 (VSS), LED7.3 (VSS), LED8.3 (VSS), LED9.3 (VSS), LED10.3 (VSS), LED11.3 (VSS), LED12.3 (VSS), LED13.3 (VSS), LED14.3 (VSS), LED15.3 (VSS), LED16.3 (VSS), LED17.3 (VSS), LED18.3 (VSS), LED19.3 (VSS), LED20.3 (VSS), LED21.3 (VSS), R1.1, R2.1, R9.2, SMDSW1.1, SMDSW2.1, SW1.2, SW2.2, SW3.2, SW4.2, SW5.2, SW6.2, SW7.2, SW8.2, SW9.2, SW10.2, SW11.2, SW12.2, SW13.2, SW14.2, SW15.2, SW16.2, SW17.2, SW18.2, SW19.2, SW20.2, SW21.2, U1.19 (TESTEN), U1.57 (GND), U2.1 (GND), U3.3 (GND), U3.8 (GND), U4.4 (GND), Y1.2, Y1.4
GNDR: rC1.2, rC2.2, rC3.2, rC4.2, rC5.2, rC6.2, rC7.2, rC8.2, rC9.2, rC10.2, rC11.2, rC12.2, rC13.2, rC14.2, rC15.2, rC16.2, rEXLED1.3 (VSS), rEXLED2.3 (VSS), rEXSW1.C, rEXSW1.S1, rEXSW2.C, rEXSW2.S1, rJ1.A1 (GND), rJ1.A12 (GND), rJ1.B1 (GND), rJ1.B12 (GND), rJ1.S1 (SHIELD), rJ2.S, rJ3.4, rJ4.2, rLED1.3 (VSS), rLED2.3 (VSS), rLED3.3 (VSS), rLED4.3 (VSS), rLED5.3 (VSS), rLED6.3 (VSS), rLED7.3 (VSS), rLED8.3 (VSS), rLED9.3 (VSS), rLED10.3 (VSS), rLED11.3 (VSS), rLED12.3 (VSS), rLED13.3 (VSS), rLED14.3 (VSS), rLED15.3 (VSS), rLED16.3 (VSS), rLED17.3 (VSS), rLED18.3 (VSS), rLED19.3 (VSS), rLED20.3 (VSS), rLED21.3 (VSS), rR1.1, rR2.1, rR9.2, rSMDSW1.1, rSMDSW2.1, rSW1.2, rSW2.2, rSW3.2, rSW4.2, rSW5.2, rSW6.2, rSW7.2, rSW8.2, rSW9.2, rSW10.2, rSW11.2, rSW12.2, rSW13.2, rSW14.2, rSW15.2, rSW16.2, rSW17.2, rSW18.2, rSW19.2, rSW20.2, rSW21.2, rU1.19 (TESTEN), rU1.32 (GPIO21), rU1.57 (GND), rU2.1 (GND), rU3.3 (GND), rU3.8 (GND), rU4.4 (GND), rY1.2, rY1.4
unnamed: C2.1, R3.1, Y1.3
unnamed: D1.1 (K), EXLED1.1 (VDD), EXLED2.1 (VDD), LED1.1 (VDD), LED2.1 (VDD), LED3.1 (VDD), LED4.1 (VDD), LED5.1 (VDD), LED6.1 (VDD), LED7.1 (VDD), LED8.1 (VDD), LED9.1 (VDD), LED10.1 (VDD), LED11.1 (VDD), LED12.1 (VDD), LED13.1 (VDD), LED14.1 (VDD), LED15.1 (VDD), LED16.1 (VDD), LED17.1 (VDD), LED18.1 (VDD), LED19.1 (VDD), LED20.1 (VDD), LED21.1 (VDD)
unnamed: EXLED1.4 (DIN), JP1.2 (B), LED21.2 (DOUT)
unnamed: EXLED1.2 (DOUT), EXLED2.4 (DIN)
unnamed: J1.A5 (CC1), R1.2
unnamed: J1.B5 (CC2), R2.2
unnamed: JP1.1 (A), LED18.2 (DOUT), LED19.4 (DIN)
unnamed: LED1.2 (DOUT), LED2.4 (DIN)
unnamed: LED2.2 (DOUT), LED3.4 (DIN)
unnamed: LED3.2 (DOUT), LED4.4 (DIN)
unnamed: LED4.2 (DOUT), LED5.4 (DIN)
unnamed: LED5.2 (DOUT), LED6.4 (DIN)
unnamed: LED6.2 (DOUT), LED7.4 (DIN)
unnamed: LED7.2 (DOUT), LED8.4 (DIN)
unnamed: LED8.2 (DOUT), LED9.4 (DIN)
unnamed: LED9.2 (DOUT), LED10.4 (DIN)
unnamed: LED10.2 (DOUT), LED11.4 (DIN)
unnamed: LED11.2 (DOUT), LED12.4 (DIN)
unnamed: LED12.2 (DOUT), LED13.4 (DIN)
unnamed: LED13.2 (DOUT), LED14.4 (DIN)
unnamed: LED14.2 (DOUT), LED15.4 (DIN)
unnamed: LED15.2 (DOUT), LED16.4 (DIN)
unnamed: LED16.2 (DOUT), LED17.4 (DIN)
unnamed: LED17.2 (DOUT), LED18.4 (DIN)
unnamed: LED19.2 (DOUT), LED20.4 (DIN)
unnamed: LED20.2 (DOUT), LED21.4 (DIN)
unnamed: R6.2, SMDSW1.2
unnamed: SMDSW2.2, U1.26 (RUN)
unnamed: R5.1, U1.46 (USB_DM)
unnamed: R4.2, U1.47 (USB_DP)
unnamed: C1.1, U1.20 (XIN), Y1.1
unnamed: R3.2, U1.21 (XOUT)
unnamed: rC2.1, rR3.1, rY1.3
unnamed: rD1.1 (K), rEXLED1.1 (VDD), rEXLED2.1 (VDD), rLED1.1 (VDD), rLED2.1 (VDD), rLED3.1 (VDD), rLED4.1 (VDD), rLED5.1 (VDD), rLED6.1 (VDD), rLED7.1 (VDD), rLED8.1 (VDD), rLED9.1 (VDD), rLED10.1 (VDD), rLED11.1 (VDD), rLED12.1 (VDD), rLED13.1 (VDD), rLED14.1 (VDD), rLED15.1 (VDD), rLED16.1 (VDD), rLED17.1 (VDD), rLED18.1 (VDD), rLED19.1 (VDD), rLED20.1 (VDD), rLED21.1 (VDD)
unnamed: rEXLED1.4 (DIN), rJP1.2 (B), rLED21.2 (DOUT)
unnamed: rEXLED1.2 (DOUT), rEXLED2.4 (DIN)
unnamed: rJ1.A5 (CC1), rR1.2
unnamed: rJ1.B5 (CC2), rR2.2
unnamed: rJP1.1 (A), rLED18.2 (DOUT), rLED19.4 (DIN)
unnamed: rLED1.2 (DOUT), rLED2.4 (DIN)
unnamed: rLED2.2 (DOUT), rLED3.4 (DIN)
unnamed: rLED3.2 (DOUT), rLED4.4 (DIN)
unnamed: rLED4.2 (DOUT), rLED5.4 (DIN)
unnamed: rLED5.2 (DOUT), rLED6.4 (DIN)
unnamed: rLED6.2 (DOUT), rLED7.4 (DIN)
unnamed: rLED7.2 (DOUT), rLED8.4 (DIN)
unnamed: rLED8.2 (DOUT), rLED9.4 (DIN)
unnamed: rLED9.2 (DOUT), rLED10.4 (DIN)
unnamed: rLED10.2 (DOUT), rLED11.4 (DIN)
unnamed: rLED11.2 (DOUT), rLED12.4 (DIN)
unnamed: rLED12.2 (DOUT), rLED13.4 (DIN)
unnamed: rLED13.2 (DOUT), rLED14.4 (DIN)
unnamed: rLED14.2 (DOUT), rLED15.4 (DIN)
unnamed: rLED15.2 (DOUT), rLED16.4 (DIN)
unnamed: rLED16.2 (DOUT), rLED17.4 (DIN)
unnamed: rLED17.2 (DOUT), rLED18.4 (DIN)
unnamed: rLED19.2 (DOUT), rLED20.4 (DIN)
unnamed: rLED20.2 (DOUT), rLED21.4 (DIN)
unnamed: rR6.2, rSMDSW1.2
unnamed: rSMDSW2.2, rU1.26 (RUN)
unnamed: rR5.1, rU1.46 (USB_DM)
unnamed: rR4.2, rU1.47 (USB_DP)
unnamed: rC1.1, rU1.20 (XIN), rY1.1
unnamed: rR3.2, rU1.21 (XOUT)
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

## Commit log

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2022-01-24 Fixed wrong connection in between pin 16 an VCC in PolyAtom2; Added ConectorL
    [QuaterConnector-B_Cu.gbl, QuaterConnector-B_Mask.gbs, QuaterConnector-B_Paste.gbp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]
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2023-03-15 Updated all openSCAD models and various fixes for the right side before final production
    [SSD1306_TO_SPI.kicad_sch, WS2812B-Mini.step, bom.csv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]
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2026-07-31 Add one-piece LED diffuser frame for split72, notch the spacer for it
    The 36 keycap LED diffusers were printed as a ring of separate parts, which
    print services bill per repeated part. This replaces that with a single part
    per half: every diffuser held at its exact plate position and orientation by
    a web that lives under the plate.
    parts/diffuser_frame_{left,right}.scad (generated)
    Geometry comes from poly_kybd/poly_kybd_split72_plate_left.kicad_pcb, the
    authoritative source for the 36 half-round LED holes — including the thumb
    keys' rotations (up to 20 degrees off axis). The right half is emitted as
    the exact x-mirror of the left: the two plates are mirror images to within
    KiCa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
    [case_polykybd_split72_lr.scad, diffuser_frame_left.scad, diffuser_frame_left.stl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]
2026-08-01 Fix the connectivity gate and reporting in the frame generator
    Review findings from PR #19.
    graph_connected() could return True while a diffuser had no stem at all.
    It filtered the cap nodes with `if k in adj`, so an LED whose boss node had
    no incident segment was simply excluded from the reachability requirement.
    This is the only safety gate the thinning loop consults, so it could have
    accepted a removal that orphaned a diffuser. Now every LED must have a node
    AND be reachable. Its docstring also claimed the function merges all nodes
    inside a cap footprint, which it never did — each LED contributes exactly one
    node, its boss key.
    Confirmed by deleting the five thumb links: the gate now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
    [diffuser_frame_left.scad, diffuser_frame_right.scad]
2026-08-01 case/step: metal-case bottom-cover KiCad PCB (one flippable aluminium plate for both halves)
    Orderable aluminium-PCB cover generated from the merged case geometry:
    - bottom_cover_kicad.py — reuses plate_svg.py's wedge-flattened, top-view STEP extraction
    - metal_case_bottom_cover.kicad_pcb — outline (closed Edge.Cuts loop) offset 0.15 mm/side
    inward for a drop-in fit, 4x M2 Ø2.2 non-plated holes, 'PolyKybd' in Arial Black italic
    on both silk sides, board placed clear on the sheet
    ONE part fits both halves: as-is on the right, flipped 180deg about the vertical axis on
    the left (the flip maps the hole pattern exactly). Copper layers empty. ~195.3 x 136.9 mm.
    NOT the 3D-printed-case pla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
    [metal_case_bottom_cover.kicad_pcb]
2026-08-02 Spacer r1.2: drop the rib the rail destroyed, emboss the revision
    Profiling each inner rib along its length against the notch showed the rib at
    x=53 was left as a 50.5 mm run of 0.28 mm wall, plus 39.5 mm of stub — a fin
    with no stiffness that would simply snap off in handling. Its channel is only
    3.45 mm wide, so a 2.0 mm rail and a 1.8 mm rib cannot both fit there; the rib
    had to go rather than survive as a sliver. The remaining ribs are healthy:
    145.5 mm and 155.5 mm solid, and the rotated one is untouched.
    The notch's lateral and depth clearance are now separate parameters
    (diffuser_frame_<side>_clearance(lat, deep)). Depth must stay small or the ribs
    get cut clean through; width want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
    [case_polykybd_split72_lr.scad, diffuser_frame_left.scad, diffuser_frame_right.scad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]
2026-08-02 Restore inner_walls(); the r1.2 edit had hit it as well
    The rib line
    translate([ 53, 100.5 - 45, 0 ]) cube([ spacer_thickness, 100, spacer_height ]);
    is byte-identical in inner_walls() and right_spacer() — the two modules use the
    same expression with different local values of spacer_thickness/spacer_height.
    The r1.2 edit was applied with a plain string replace and no count, so it hit
    both: it deleted that wall from inner_walls() and injected the revision label
    there too, where rev_face/rev_edge_ang/rev_emboss are undefined. Only
    right_spacer() was meant to change.
    inner_walls() is now byte-identical to master again, and the label and rib
    removal exist only in right_spacer(). The dif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
    [case_polykybd_split72_lr.scad]
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2026-08-02 Spacer r1.1: engrave the revision instead of raising it
    The revision number was wrong. The spacer has never carried a revision — the
    only one in this file is the case's r1.7 — so there was no shipped r1.1 for
    r1.2 to follow. Both numbers were invented inside this unmerged branch while
    iterating. The shipped part up to now is r1.0 and everything here is a single
    step, so the label is r1.1 and the three in-branch notes are collapsed into one
    changelog entry.
    The label is also engraved rather than embossed. Subtracting it adds no
    protruding feature that could be knocked off or foul the frame during assembly,
    which is the better shape for a 0.5 mm detail on a 1.8 mm wall. The anchor sits
    re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
    [case_polykybd_split72_lr.scad, spacer_diffuser_frame.stl]
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2026-08-03 Fix the review findings on the emitted header and figlib
    - The generated frame header still described the cap stack as
    -2*cap_thickness .. 0 with a taper hanging below the web. That was true
    for all of one commit; the bottom cap is now -2*cap_thickness_bot .. 0 and
    has no taper. Rewritten to say why the two must stay equal, and both frame
    .scad files regenerated (comment only, geometry untouched).
    - figlib: Fig.image() and Fig.save() leaked their file objects; both use a
    context manager now and the SVG is written utf-8.
    - figlib: save() stored the path verbatim, so passing a Path made png() fail
    on .rsplit. Normalized to Path once in save(), and png() derives its
    default with w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
    [diffuser_frame_left.scad, diffuser_frame_right.scad]
2026-08-04 Keep the cap chamfer angle, and lean the trim cut 45 degrees
    Two corrections to the thin-wall rework, both from the shape rather than
    the numbers.
    The chamfer had been stretched. Thickening the top flange 1.0 -> 1.5 mm was
    done by raising cap_thickness, but that layer is a linear_extrude(scale=0.9)
    and its inward step is proportional to the profile, not to the height --
    so making it taller laid the chamfer down from 34.9 degrees off vertical to
    21.8. Split into cap_straight_top (1.0 mm, carries the extra thickness) and
    cap_chamfer (0.5 mm, the original). The chamfer is back to 35.0 degrees,
    matching the shipped part, and the flange is still 1.5 mm.
    The trim cut now leans 45 degrees in plan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
    [diffuser.scad, diffuser_frame_left.stl, diffuser_frame_left_4x.stl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]
2026-08-04 Engrave a revision on the frame, and commit the checks that verify it
    Point 4 and point 2 of the review, and the first caught the second red-handed.
    REVISION. "L r1.1" / "R r1.1" cut 0.15 mm into the underside of the longest
    rail, which faces down into the spacer gap -- invisible assembled, readable
    on the loose part, and it names the side too, which matters because the
    halves are mirror images. Glyphs are mirrored since you read that face from
    below. r1.1 because r1.0 is the file the print service already has and
    refused; two versions on one desk was the reason for wanting this.
    The rail is widened to 2.6 x 5.4 mm under the text. Straight onto the 2.0 mm
    rail, letters at 1.4 mm left 0.005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
    [diffuser_frame_left.scad, diffuser_frame_left.stl, diffuser_frame_left_4x.stl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]
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2026-08-07 v3.3: replace SN74LVC1G126 buffer symbol with Nexperia 74AHC1G125
    U12/U13 in ni_buffer2.kicad_sch were drawn with the
    Logic_LevelTranslator:SN74AUP1T34DCK symbol, which mislabels pins 1 and 5
    as VCCA/VCCB. The fitted part is a single-gate tri-state buffer, where
    pin 1 is /OE and pin 5 is VCC.
    Pin *numbers* drive the netlist and those were always right, so the built
    v3.2 boards are electrically correct. This is a drawing fix - it matters
    because the schematic is exported into the CE technical file.
    - swap to 74xGxx:74AHC1G125, rev v3.3
    - retarget U12/U13 to Nexperia 74AHC1G125GW,125 (LCSC C85397); the
    previously specified part is EOL at JLCPCB
    - reroute the wires: the new symbol has diffe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
    [mini-360.kicad_sch, ni_buffer.kicad_sch, ni_buffer2.kicad_sch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]
2026-08-07 U12/U13: correct Manufacturer field to Nexperia
    Missed in the v3.3 symbol swap (#23). The part was retargeted from the
    EOL TI/TECH PUBLIC C151890 to Nexperia 74AHC1G125GW,125 (C85397), and
    Value, Datasheet, MPN, JLC and LCSC were all updated - but Manufacturer
    was left reading "TI".
    This matters before Update PCB from Schematic, because the field
    propagates to the footprint and into the CE parts list. "Nexperia" is
    already the spelling used elsewhere in the project.
    RoHS stays "x" and Description stays empty, matching the convention used
    across the other sheets.
    [ni_buffer2.kicad_sch]
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2026-08-07 A5: replace four EOL parts across schematics, PCBs and the project library
    All four were discontinued at JLCPCB ("no longer manufactured", 0 stock),
    so the v3.2 BOM can no longer be ordered as-is. Metadata only - every
    replacement keeps the same footprint, so no layout or netlist changes.
    C118249 Sunlord TC212A475K025Y -> C5380411 Vishay 293D475X9025A2TE3
    C170128 Samsung CL10C6R8DB8NNNC -> C318672 Samsung CL10C6R8CB8NNNC
    C3303719 Nexperia 74HC595BQ115 -> C730243 Nexperia 74HC595BQ,115
    C2940195 Winbond W25Q64JVXGIQ -> C5440778 Winbond W25Q64JVXGIM
    Net cost at a 200-keyboard batch: -$4.15/keyboard, -$829/batch. The flash
    carries it (-$4.76/kbd); the tantalum is the onl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
    [SSD1306_TO_SPI.kicad_sch, SSD1306_TO_SPI_NO_LED.kicad_sch, poly_corne_split42_left.kicad_pcb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]
2026-08-07 CE technical file: follow the v3.3 part changes
    Updates parts-to-pdf-reference.xls (the source of truth) and
    schematics/parts.csv for the five retargeted parts.
    Certificate changes:
    - Tantalum C4_1-C4_36,C33,C34 moved from Sunlord to Vishay, so
    sunlord-rohs.pdf no longer applies. Added vishay-rohs-20250901.pdf -
    Vishay's ROHS Compliance Statement of 1 September 2025, signed by the
    COO, citing Directives 2002/95/EG, 2011/65/EU and 2015/863/EU. Our
    293D475X9025A2TE3 carries the E3 lead-free termination code and the
    datasheet specifies 100% matte tin terminations.
    - U12-U25 buffer re-pointed from the TI datasheet to the existing
    Nexperia RoHS statement, which is company-wide and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
    [parts-to-pdf-reference.xls, parts.csv]
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2026-08-13 v3.3: fabrication exports for both sides
    Marks the revision (title blocks 3.2 -> 3.3) and adds the JLCPCB export
    packages for both halves, with the CPL assembly side corrected by
    tools/fix_cpl_layers.py.
    Gerber/PCB/left-side-v3.3/ PolyKybd_Split72_L_3.3.*
    Gerber/PCB/right-side-v3.3/ PolyKybd_Split72_R_3.3.*
    v3.2 is left untouched as the record of what was actually built.
    Verification against the v3.2 exports the working boards came from:
    - 497 CPL rows each side, 51 BOM lines each side, no designator added or
    removed, and no LCSC code present on one side but not the other
    - zero placed components changed position, rotation or layer. Four
    centroids differ (SW1 by 0.86 mm, DBG1/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
    [PolyKybd_Split72_L_3.3_bom.csv, PolyKybd_Split72_L_3.3_designators.csv, PolyKybd_Split72_L_3.3_positions.csv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]
2026-08-13 corne split42: propagate the 74AHC1G125 buffer to both PCBs
    The corne boards were the last place still carrying the EOL TI part.
    They fell between the earlier PRs: #23/#24 fixed the shared
    ni_buffer2.kicad_sch, so all four projects' schematics were already
    right; #25 propagated only to the split72 PCBs; and #27's part pass
    covered corne for the four other EOL parts but not the buffer. The result
    was two boards disagreeing with their own schematic.
    Value SN74LVC1G126DBVR -> 74AHC1G125GW,125
    Datasheet ti.com -> assets.nexperia.com
    MPN C151890 -> 74AHC1G125GW,125
    JLC / LCSC C151890 -> C85397
    Manufacturer TI -> Nexper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
    [poly_corne_split42_left.kicad_pcb]
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2026-08-13 CE: bring the RoHS compliance matrix in line with the v3.3 parts
    The matrix still described the pre-v3.3 build and had drifted from
    parts-to-pdf-reference.xls, which is the source of truth.
    Corrected rows:
    tantalum Sunlord / sunlord-rohs.pdf -> Vishay / vishay-rohs-20250901.pdf
    U9 W25Q64JVXGIQ / "winbond" -> W25Q64JVXGIM / Winbond
    U12-U25 was "U12-U23,U?,U?", TI SN74LVC1G126DBVR, sn74lvc1g126.pdf
    -> 74AHC1G125GW,125, Nexperia, Nexperia RoHS statement
    Also corrects an inaccuracy rather than carrying it forward: the matrix
    claimed the Winbond evidence was "RoHS 2011/65/EU as amended by (EU)
    2015/863", but that document actually cites the superseded 2002/95/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
    [PolyKybd-RoHS-Compliance-Matrix.xlsx]
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2026-08-14 1k 0402: retarget from Yageo C144789 to Vishay C71623
    C144789 (Yageo AC0402FR-071KL) is not being restocked, and its remaining
    listing carries a minimum purchase of 3,445 pieces against the 2,000
    needed for a 200-keyboard batch.
    Vishay CRCW04021K00FKED (C71623) is an exact functional match:
    Yageo C144789 Vishay C71623
    value/package 1k 0402 1k 0402
    tolerance +-1% +-1%
    TCR +-100ppm/C +-100ppm/C
    power 62.5 mW 63 mW
    temperature -55..+155 C -55..+155 C
    stock 12,804 (min 3445) 374,486 (min 1)
    Costs $0.0038 against $0.0029, so +$1.80 across a 200-keyboard batc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
    [poly_corne_split42_left.kicad_pcb, poly_corne_split42_left.kicad_sch, poly_corne_split42_right.kicad_sch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]
2026-08-14 v3.3 BOMs: 1k 0402 -> C71623
    Follows fdb918d, which retargeted the 1k 0402 from Yageo C144789 to
    Vishay C71623 on the boards. The exported BOMs still listed the old code.
    Patched in place rather than re-exported. Nothing about the copper,
    placement or the CPL changed - only the LCSC code on one BOM line per
    side - and a re-export would refill the zones. With the clearance rule
    now at 0.15 mm the pours would shift very slightly, which would
    invalidate the gerber comparison already done against the v3.2 export.
    "R16, R19, R21, R5, R6",0402,5,1k 0402,C144789
    "R16, R19, R21, R5, R6",0402,5,1k 0402,C71623
    One line changed per file, line count unchanged, no other cell touched.
    Verified aft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
    [PolyKybd_Split72_L_3.3_bom.csv, PolyKybd_Split72_R_3.3_bom.csv]
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2026-08-16 Consolidate case/ and parts/ into one tree, and add the missing alpha R2-R5 stems
    The mechanical sources were split across case/ and parts/ along a line that had
    already stopped holding -- case_polykybd_split72_lr.scad reaches into
    ../parts/diffuser_frame_left.scad, and check_frame.py needs a file from each --
    so everything moves under parts/, one folder per part group:
    parts/<group>/ sources plus that group's build/verify scripts
    parts/export/<group>/ everything generated, never hand-edited
    parts/models/ reference meshes, not printed parts
    Superseded meshes are dropped (case/old_stls/, the _r6 cases, older insert
    revisions); git keeps them recoverable. Paths up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
    [case_ins_leg_v0.stl, case_ins_r1.stl, case_ins_r2.stl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]
2026-08-16 Fold every case variant into parts/case, and file led_caps with the diffuser
    Two follow-ups to the reorg.
    All cases in one folder
    -----------------------
    case_split72 and case_right_side merge into parts/case (exports likewise into
    parts/export/case). This is not only tidier: right_side.scad and
    case_polykybd_split72_lr.scad import the SAME KiCad SVG outlines
    (poly_kb_wave_right_case-*.svg), and an import() path resolves relative to the
    .scad file just as use <> does -- so the previous split left right_side.scad
    unable to find any of its six imports. The merge repairs that, and CLAUDE.md
    now records why the variants have to stay together.
    led_caps is the old diffuser
    --------------------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
    [case_polykybd_split72_left_r7.stl, case_polykybd_split72_lr.scad, case_polykybd_split72_metal-bottom.stl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]
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2026-08-16 Fix the rotary-insert typo, and move the visualisation-only files to models/
    - rotary_enc_nsert.scad -> rotary_enc_insert.scad (missing 'i').
    - plate/plate.scad -> models/. It imports SVGs from a poly_kb_atom/ directory
    that is not in this repo, so it has not built in a long time; it looks to have
    been a 3D model of the switch plate rather than a printed part, which is what
    models/ is for. The plate group is gone.
    - display_holder_wdisplay.stl (the holder shown with its display in place) and
    right_side_model.wrl are references, not printable output, so they belong in
    models/ rather than the export tree.
    models/ is now "what only ever existed to visualise how a part fits", which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
    [display_holder_wdisplay.stl, plate.scad, rotary_enc_insert.scad]
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2026-08-17 keycap stems: one .scad per plate over a library with no top-level geometry
    Splits keycap_stem.scad into a library and sixteen variant files, which is what
    the profile set should have been all along -- it previously existed only as
    commented-out top-level calls that you uncommented one at a time to export, and
    that is how the curved R2..R5 plates went missing from revAlpha for a whole
    revision.
    keycap_stem.scad modules and parameters, no top-level geometry
    variants/<name>.scad one plate each: include ../keycap_stem.scad + one call
    preview_stems.scad the photo arrangements that were commented out at the
    bottom of the library, now rendera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
    [keycap_stem.scad, keycap_stem_revAlpha_1U25_R1_10p.scad, keycap_stem_revAlpha_1U25_R2_10p.scad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]
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2026-08-17 Put the coordinate axes back, and stop the row tilt falsifying the angle
    The axes in the original GUI screenshots were not chrome -- the
    horizontal axis line is the reference a reader measures each cap angle
    against, and dropping it left five tilted caps with nothing to measure
    them against. Rendering now passes --view=axes.
    That exposed a second, worse problem in my own code: profile_row()
    rotated the whole row 8 degrees "so the profile reads". A row tilt adds
    itself to every cap angle without moving the axes, so R3 -- flat by
    definition -- sat 8 degrees nose-up on the axis line. Removed, with the
    reasoning recorded in the module, parts/README.md and CLAUDE.md, since
    "stand the row up a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
    [preview_stems.scad]
2026-08-17 Engrave the profile on curved stems so the part matches its filename
    The curved plates engraved a bare digit -- a printed stem read "3 a"
    while the file that made it was ..._R3_10p.stl -- so only the stepped
    plates (S1/S/S5) could be identified from the part in your hand. "Is
    the flat one R3?" was a question the stem itself could not answer. Now
    every piece carries the same profile token its filename does: R1..R5
    alongside the existing S1/S/S5, in the same 5-character field, so the
    revision still lands at the opposite corner of the top face.
    Ten plates re-exported (R1..R5 x 1U/1U25). This is a real change, not
    the Noto tessellation drift, and it is verified as engraving-only:
    bounding bo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
    [keycap_stem_revAlpha_1U25_R1_10p.scad, keycap_stem_revAlpha_1U25_R1_10p.stl, keycap_stem_revAlpha_1U25_R2_10p.scad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]
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2026-08-23 flash: author the LGA-8 footprint into poly_kb.pretty instead of the stock library
    The Footprint field pointed at Package_SON:SON-8-1EP_3x2mm_P0.5mm_EP1.4x1.6mm,
    but Package_SON is not in the project fp-lib-table - all 11 entries there are
    project-local or ThirdParty - so it resolved only through KiCad's global table
    and broke the repo's self-contained pattern. Now a local footprint, built from
    the Boya datasheet Rev 2.6 section 9.5 rather than by analogy.
    Geometry from the section 9.5 nominals: D 2.00, E 3.00, pitch 0.50 BSC, span
    Nd 1.50 BSC, pad b 0.25 x L 0.45. Signal lands are 0.25 x 0.60 - the extra
    0.15mm is an outward toe, since LGA has no side-wettable flank and without it
    there is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
    [rp_pico.kicad_sch]
2026-08-23 Revert the LED swap - keep 3030, the 3332 footprint change is too disruptive
    Thomas tried the XL-3332RGBC footprint and it does not work: the terminal
    topology is four bands rather than four corner pads, so it is a re-route at 72
    positions on two boards rather than a pad swap. Reverting LED1 to C5349958 /
    XL-3030RGBC and dropping poly_kb.pretty/XL-3332RGBC-WS2812B.kicad_mod.
    There is a second reason to hold the LED constant right now: the field-failure
    investigation is open, and 2 of 10 halves in the v3.2 batch came back with dead
    LED chains. Changing the part mid-investigation would add a variable to the one
    thing being measured, and the evidence so far points at the assembler's process
    -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
    [SSD1306_TO_SPI.kicad_sch]
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2026-08-23 USB-C: bring HRO-TYPE-C-31-M-12-Assembly into poly_kb.pretty, repoint the schematics
    The EnvUSB library (thirdparty/EnvOpenPico/.../HRO-TYPE-C31-M-12.pretty) is not
    in this repo, so KiCad reports it missing on open. It was the only one of the
    eight missing footprint libraries genuinely in use - the other seven are dead
    references, and Nexperia595 turned out to be vestigial too, appearing only in a
    lib_symbols cache while all nine 74HC595 instances already use poly_kb.
    Nothing was broken, because the footprint is embedded in all four boards, but
    Update PCB from Schematic could not resolve it - which is exactly what the
    coming layout pass needs. Since it was embedded, it could be recovered fr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
    [poly_corne_split42_left.kicad_sch, poly_corne_split42_right.kicad_sch, poly_kybd_split72_left.kicad_sch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]
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2026-08-24 Fix the v3.3 export: U9 and C3/C8 order fields, and the CPL socket side
    Three corrections to the left-side v3.3 fabrication data, plus notes so they
    stop being re-derived.
    U9 ordered the WRONG PART. The exported BOM's LCSC column - the only column
    JLC orders from - still read C5440778 (Winbond W25Q64JVXGIM, DFN 4x4) while
    the footprint was the LGA-8 Boya land. The schematic was correct all along;
    the fab exporter reads footprint properties from the board, and Update PCB
    from Schematic had refreshed the footprint and Value but not MPN/LCSC/JLC/
    Manufacturer. Board fields and the exported BOM now both name
    BY25Q64ESCIG(R) / C50176394.
    C3/C8 switched to Samsung CL05C270JB5NNNC / C86287 as dec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
    [PolyKybd_Split72_L_3.3_bom.csv, PolyKybd_Split72_L_3.3_positions.csv]
2026-08-24 D2 RoHS closed: file the 2025 Hottech CTI report covering SOD-323
    Hottech supplied a Centre Testing International report (A225024736310100101,
    17 Apr 2025) against RoHS 2011/65/EU with amendment (EU) 2015/863: full
    10-substance scope including the four phthalates, IEC 62321 methods, all
    results N.D., PASS. Its Model No. list reads SOD-123/323/523/723, so SOD-323
    - D2's package - is explicitly covered. parts.csv updated from
    "x Email sent" to "x". No part change needed.
    This also corrects the decisions log, which had accepted D2 via the 2020
    ROHS3HOTTECH.pdf on the grounds that it "includes 323-series package
    testing". That report's sample list is SOT-23, 323, 523, 723, ... SOD-123,
    where th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
    [parts.csv]
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
